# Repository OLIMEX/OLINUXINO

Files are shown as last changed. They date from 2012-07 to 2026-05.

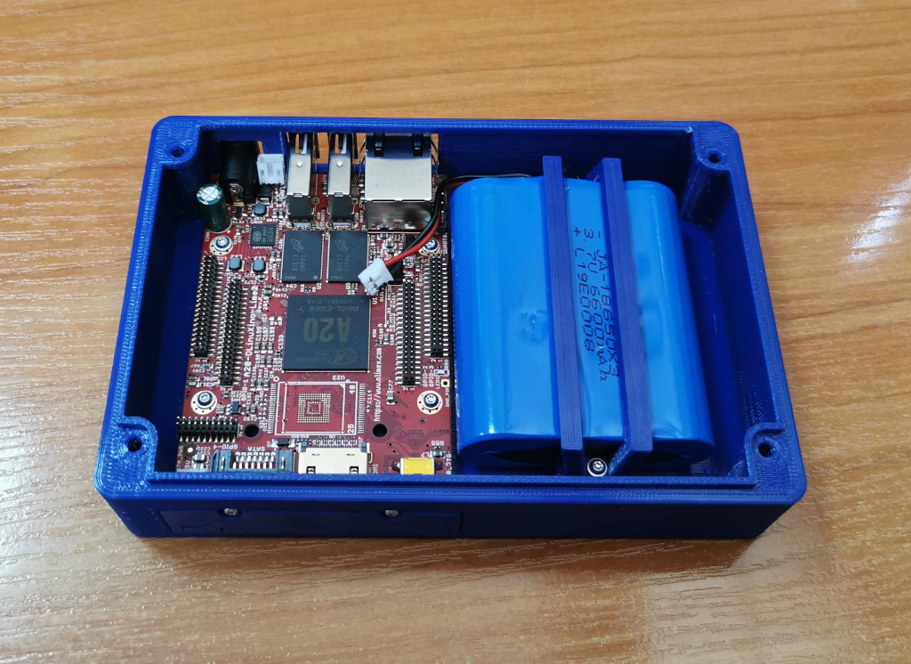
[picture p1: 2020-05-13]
BOXES/LIME2-PLASTIC-BOX/PLASTIC-BOX-ASM3.jpg

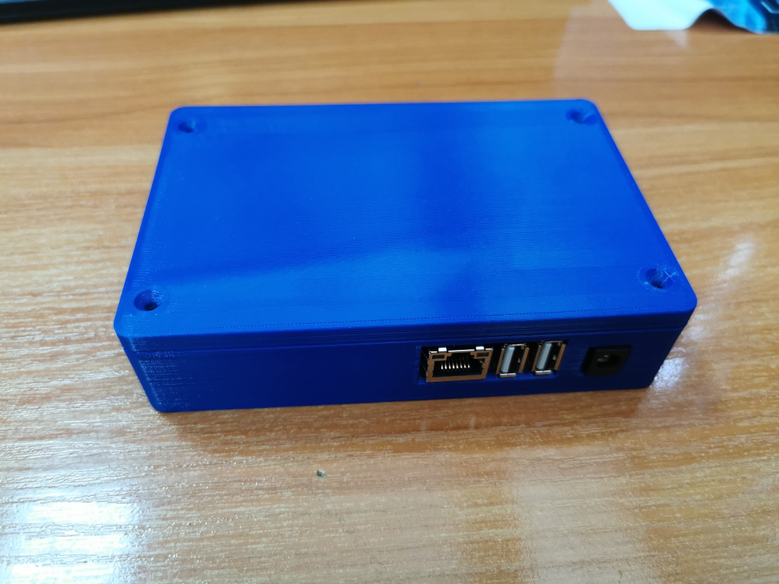
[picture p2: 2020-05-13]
BOXES/LIME2-PLASTIC-BOX/PLASTIC-BOX-ASM4.jpg

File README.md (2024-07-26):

# OLinuXino

Seriously Open Single Board Computers

# Introduction:

Pronounced 'Oh-LIH-nuh-zeeno' The name OLinuXino refers to a series of Single Board Computers (SBCs) developed and produced by Olimex LTD. These SBCs are known for their robustness and versatility, and they are completely open-source, meaning that the hardware and software designs are publicly available for anyone to review, modify, and redistribute. The OLinuXino SBCs have received certifications from the Open Source Hardware Foundation (OSHW), which guarantees that the hardware and software designs meet certain criteria for openness and transparency. Overall, the OLinuXino family of SBCs offers developers and hobbyists a flexible and customizable solution for a wide range of applications.

# Linux ready

The OLinuXino boards are designed to be flexible and versatile platforms for a wide range of applications. They are compatible with various operating systems, but one popular choice is the Linux operating system. Linux is an open-source, community-driven operating system that is well-suited for use on embedded devices like SBCs.

Olimex provide mainline images called Olimage designed specifically for Arm-based SBCs like the OLinuXino boards. It is a lightweight and optimized operating system that takes full advantage of the OLinuXino's hardware components. This includes the processor, memory, storage, and other peripherals like GPIOs and I2C buses. Olimage is regularly updated to ensure a stable and secure operating environment for OLinuXino users. You can find more about Olimage in this document here:

https://github.com/OLIMEX/OLINUXINO/blob/master/DOCUMENTS/OLIMAGE/Olimage-guide.pdf

We've provided Armbian and sunxi images in the past, and while these are no longer actively supported, they are still available for download. 

Overall, the combination of the OLinuXino boards and the Armbian operating system provides a powerful and customizable platform for a variety of applications. 

# Rugged & Reliable

The OLinuXino family of SBCs comprises a diverse range of configurations to meet a variety of industrial and commercial needs. Some models are specifically designed and manufactured to comply with industrial and commercial standards, which means they can operate continuously for extended periods of time, either within industrial grade (-40+85)C or commercial grade (0-70)C temperature ranges. These SBCs are built to withstand tough environmental conditions, making them ideal for use in industrial automation, control systems, and other demanding applications.

The OLinuXino SBCs are powered by high-efficiency ARM processors from reputable manufacturers such as Allwinner, Freescale, and others. These processors are specifically chosen for their low power consumption, high processing power, and compatibility with open-source software, making them ideal for use in embedded systems. The OLinuXino boards are available with a range of processing power options, from single-core to quad-core, depending on the specific use case and application requirements.

In addition to the processor, the OLinuXino SBCs are equipped with a variety of other components such as RAM, storage, connectivity options, and expansion slots to provide users with a versatile and flexible platform for their projects. The boards come with various built-in interfaces such as HDMI, Ethernet, USB, and Wi-Fi, which makes them easy to integrate with other devices and systems.

Overall, the OLinuXino SBCs are well-suited for industrial and commercial applications, thanks to their robust design, efficient processors, and a wide range of features and capabilities. They offer a powerful and customizable platform that can be tailored to specific requirements, making them a popular choice for developers, engineers, and hobbyists alike.

# Unique Standout Features

The OLinuXino family of SBCs is often compared to popular projects such as Raspberry Pi and BeagleBone, but it stands out for several unique features:

1. The OLinuXino family is fully open-source. This means that there are no restrictions on accessing hardware designs or code, making it a popular choice among developers and hobbyists who want to customize or modify their SBCs. The OLinuXino boards are certified by the Open Source Hardware Foundation, providing users with a high degree of confidence in the quality and authenticity of the hardware.

2. The permissive licensing of OLinuXino hardware makes it ideal for use in commercial projects. The hardware can be used without any restrictions, which means that users can design, modify, and distribute their products without any licensing fees or royalties.

3. The OLinuXino family is designed with reproducibility in mind. The hardware designs are thoughtfully executed, making it easy for users to replicate and manufacture their own boards. This is particularly useful for developers who need to scale up production or customize their boards for specific applications.

4. Some of the OLinuXino boards are designed specifically for industrial environments, making them more tolerant of high and low temperatures and able to withstand electrical noise. These features make them well-suited for industrial automation, control systems, and other demanding applications.

4. Some OLinuXino boards feature circuitry for out-of-the-box battery usage, including use as an Uninterruptible Power Supply (UPS). This feature makes the boards ideal for use in remote locations or in applications where a reliable power source is essential.

# Available Configurations

Overall, the OLinuXino family of SBCs offers a unique combination of features and capabilities that make it a popular choice among developers, engineers, and hobbyists. The fully open-source hardware, permissive licensing, and thoughtful design make it a versatile and customizable platform for a variety of applications. The industrial-grade options and battery circuitry make it a robust and reliable solution for demanding environments.

The OLinuXino family of SBCs offers a wide range of configurations to meet a variety of application requirements. Here are some of the configurations available:

[OSHW-Server](https://www.olimex.com/Products/OLinuXino/Home-Server/open-source-hardware): This is a series of low-power server kits that utilize the A20-OlinuXino-LIME2 board. These kits are designed to provide a cost-effective and energy-efficient solution for running server applications.

[STMicro STMP1](https://www.olimex.com/Products/OLinuXino/STMP1/open-source-hardware): This series of boards features the STM32MP157 System on a Chip (SOC), which includes a Dual-core Arm Cortex-A7 running up to 800 MHz and a Cortex-M4 at 209 MHz combined with a dedicated 3D graphics processing unit (GPU). This configuration is well-suited for applications that require high processing power and graphics capabilities.

[Ralink RT5350F](https://www.olimex.com/Products/OLinuXino/RT5350F/open-source-hardware): This series of boards features the Ralink RT535OF MIPS System on a Chip (SOC). It is a low-cost and energy-efficient option for applications that do not require high processing power.

[Allwinner A20](https://www.olimex.com/Products/OLinuXino/A20/open-source-hardware): This configuration comes in several options featuring the Allwinner A20 Arm Cortex A7 Processor. It is a versatile and cost-effective solution for a variety of applications.

[Allwinner A64](https://www.olimex.com/Products/OLinuXino/A20/open-source-hardware): This series of boards features the Allwinner A64 System on a Chip (SOC), including a Dual Core Arm Cortex-A7 processor running at up to 1.2Ghz. It is an efficient and powerful option for applications that require high processing power.

[Allwinner A13](https://www.olimex.com/Products/OLinuXino/A13/open-source-hardware): This configuration features the Allwinner A13 System on a Chip (SOC), offering a low-cost and energy-efficient solution for applications that do not require high processing power.

[Allwinner A10](https://www.olimex.com/Products/OLinuXino/A10/open-source-hardware): This configuration features the Allwinner A10 System on a Chip (SOC), offering a low-cost and energy-efficient solution for a variety of applications.

[Allwinner S3](https://www.olimex.com/Products/OLinuXino/S3/): This configuration features the Allwinner S3 System on a Chip (SOC), offering a low-cost and energy-efficient solution for applications that do not require high processing power.

[Allwinner A33](https://www.olimex.com/Products/OLinuXino/A33/open-source-hardware): This configuration features the Allwinner A33 System on a Chip (SOC), offering a low-cost and energy-efficient solution for applications that do not require high processing power.

[NXP iMX8](https://www.olimex.com/Products/OLinuXino/iMX8/): This configuration features the NXP iMX8 System on a Chip (SOC), which provides users with a high degree of flexibility and customization options for their applications.

[NXP iMX233](https://www.olimex.com/Products/OLinuXino/iMX233/open-source-hardware): This configuration features the NXP iMX233 System on a Chip (SOC), which is a low-power and low-cost option for applications that do not require high processing power.

Overall, the OLinuXino family of SBCs offers a diverse range of configurations to meet a variety of application requirements. Whether you need high processing power, energy efficiency, or cost-effectiveness, there is likely a configuration that can meet your needs. Additionally, the open-source hardware and permissive licensing make the OLinuXino boards a popular choice among developers and hobbyists who want to customize and modify their SBCs.

# More Chip info

Allwinner A10 [Data-Sheet](https://linux-sunxi.org/images/7/75/A10_Datasheet.pdf): This System on a Chip (SOC) offers a low-cost and energy-efficient solution for a variety of applications. It features an Arm Cortex-A8 processor running up to 1.2 GHz, as well as support for up to 1 GB of DDR3 memory and 1080p video playback.

Allwinner A13 [Data-Sheet](http://dl.linux-sunxi.org/A13/A13%20Datasheet%20v1.1.pdf): This SOC offers a low-cost and energy-efficient solution for applications that do not require high processing power. It features an Arm Cortex-A8 processor running up to 1 GHz, as well as support for up to 1 GB of DDR3 memory and 1080p video playback.

Allwinner A20 [Data-Sheet](https://linux-sunxi.org/images/4/4e/A20_Datasheet_v1.4.pdf): This SOC comes in several configurations featuring the Allwinner A20 Arm Cortex A7 Processor. It is a versatile and cost-effective solution for a variety of applications, offering a dual-core Arm Cortex-A7 processor running up to 1 GHz and support for up to 2 GB of DDR3 memory.

Allwinner A33 [Data-Sheet](https://linux-sunxi.org/images/5/57/A33_Datasheet_v1.0.pdf): This SOC features a quad-core Arm Cortex-A7 processor running up to 1.5 GHz, as well as support for up to 2 GB of DDR3 memory and 1080p video playback. It offers a low-cost and energy-efficient solution for applications that do not require high processing power.

Allwinner A64 [Data-Sheet](https://linux-sunxi.org/images/7/78/A64_User_Manual_V1.0.pdf): This SOC features a Dual Core Arm Cortex-A7 processor running up to 1.2 GHz, making it an efficient and powerful option for applications that require high processing power. It also supports 4K video playback and up to 4 GB of DDR3 memory.

Allwinner S3 [Data-Sheet](https://linux-sunxi.org/images/4/4c/S3_Datasheet_V1.1.pdf): This SOC features a quad-core Arm Cortex-A7 processor running up to 1.2 GHz, making it an efficient and powerful option for applications that require moderate processing power. It also supports up to 2 GB of DDR3 memory and 1080p video playback.

NXP iMX233 [Data-Sheet](https://www.nxp.com/docs/en/data-sheet/IMX233C.pdf): This SOC is a low-power and low-cost option for applications that do not require high processing power. It features an Arm926EJ-S processor running up to 454 MHz, as well as support for up to 64 MB of DDR2 memory and 480p video playback.

NXP iMX8 [Data-Sheet](https://www.nxp.com/docs/en/data-sheet/IMX8MDQLQIEC.pdf): This SOC provides users with a high degree of flexibility and customization options for their applications. It features a quad-core Arm Cortex-A53 processor running up to 1.5 GHz, as well as a dual-core Arm Cortex-M4 processor for real-time processing. It also supports up to 4 GB of LPDDR4 memory and 4K video playback.

Ralink RT5350F [Data-Sheet](https://www.ralinktech.com/products/rt5350f/): This SOC is a low-cost and energy-efficient option for applications that do not require high processing power. It features a MIPS24KEc processor running up to 360 MHz, as well as support for up to 64 MB of DDR2 memory and 1080p video playback.

STMicro STMP1 [Data-Sheet](https://www.st.com/resource/en/datasheet/stm32mp157a-datasheet.pdf): This SOC is well-suited for applications that require high processing power and graphics capabilities. It features a Dual-core Arm Cortex-A7 running up to 800 MHz and a Cortex-M4 at 209 MHz, combined with a dedicated 3D graphics processing unit (GPU). It also supports up to 1 GB of DDR3 memory and 1080p video playback.

Overall, each SOC offers different processing power, memory, and video capabilities to suit a variety of applications. Depending on your specific needs and requirements, you may choose one SOC over another to optimize performance and cost-effectiveness.

# Potential use cases

* Industrial automation and control systems
* Robotics and control systems
* Home automation and smart home systems
* Media centers and home theaters
* Network appliances and routers
* Internet of Things (IoT) devices and sensors
* 3D printer controller and G-code interpreter
* Programmable logic controller (PLC) for manufacturing and process control
* Reverse proxy server and load balancer for web applications
* Cloud and edge computing systems
* Educational and research projects in computer science and engineering
* Digital signage and kiosk systems
* Gaming and entertainment systems
* Portable and battery-powered systems, including battery-backed UPS
* Scientific and medical instrumentation and analysis systems
* Remote sensing and monitoring systems
* Amateur radio and signal processing systems

The versatility and flexibility of the OLinuXino family of SBCs makes them suitable for a wide range of applications in various industries and domains. The fully open-source nature of the hardware and software also makes them highly customizable and extensible, allowing users to tailor them to their specific needs and requirements.

# Resources:

[OLIMEX Ltd web site](http://www.olimex.com) -  where the OLinuXino board info is hosted

[GitHub Source](https://github.com/OLIMEX/OLINUXINO) - GitHub web site hosting the Hardware and Software sources

[Forum](https://www.olimex.com/forum/index.php) - Olimex forum for OLinuXino project discussions

[Discord](https://discord.com/invite/QQEBXZk7y8) - Olimex Discord channel for product discussions

IRC Channel - join #olimex on irc.freenode.net , alternatively use http://webchat.freenode.net/?channels=olimex for web IRC chat

# Licensing:

## Hardware

The OLinuXino family of Single Board Computers (SBCs) is completely open-source and is licensed under permissive Creative Commons Attribution-Share Alike 3.0 United States License (CC-BY-SA 3.0 US). This license allows users to reproduce, modify, and redistribute the hardware and documentation for both personal and commercial use, as long as they provide attribution to the original creator, Olimex LTD, and release any modified files under the same license terms.

However, if you choose to modify the hardware, you must alter the silkscreen to avoid confusing users into thinking they are purchasing the original OLinuXino made by Olimex. This is a requirement to prevent any potential legal issues, as the OLinuXino trademark is owned by Olimex LTD.

## Software

The software used in the OLinuXino SBCs is released under the GNU General Public License (GPL) version 3, which grants users the freedom to run, copy, distribute, and modify the software. If you modify the software, you must also release it under the same license terms.

## Documentation

The documentation for the OLinuXino SBCs is also released under CC-BY-SA 3.0 US, which allows users to reproduce, modify, and distribute the documentation for both personal and commercial use, as long as they provide attribution to the original creator and release any modified files under the same license terms.

Overall, the licensing for the OLinuXino SBCs is permissive and encourages collaboration and innovation, while also ensuring that the original creators receive proper attribution for their work.

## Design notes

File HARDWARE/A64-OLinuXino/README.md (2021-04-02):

## Information about the hardware schematics, design sources, and revision changes

PDF exports of the schematics are found in this folder. Deisgn files are found in the folders, each folder features all required files for a specific hardware revision as indicated by the folder name. To access the design files you need the latest beta version of KiCAD. Using the latest stable version usually will NOT suffice.

The initial release of A64-OLinuXino boards was revision C. The six variants of the board so far are:

* A64-OLinuXino-1G with 1GB RAM but NO flash and NO WiFi/BLE connectivity

* A64-OLinuXino-1Ge16GW with 1GB RAM and 16GB extra eMMC flash and extra WiFi/BLE module

* A64-OLinuXino-1Ge16GW-EA with 1GB RAM and 16GB extra eMMC flash and extra WiFi/BLE module + external antenna

* A64-OLinuXino-1Ge4GW with 1GB RAM and 4GB extra eMMC flash and extra WiFi/BLE module

* A64-OLinuXino-1Gs16M with 1GB RAM, no NAND or eMMC flash, no WiFi/BLE, extra 16MB SPI flash

* A64-OLinuXino-2Ge8G-IND with 2GB RAM and 8GB extra flash but NO WiFi/BLE connectivity; with components that work in the industrial -40+85C temperature range

### Hardware revision changes log:

#### Hardware revision C

* initial release

#### Hardware revision D

* 1. Adjusted white print of label C184.
* 2. Added bypass R66 NA(0R) near FET2.
* 3. Added white print for the UART connector at the bottom of the board (Tx,Rx,GND).
* 4. Fixed white print of R106 and R116 (labels were swapped)
* 5. R29 placed a bit further from C84
* 6. 1.5v test pad name was changed to "DDR-VCC" because the RAM memory can work at 1.3V.
* 7. Names of the jumpers lineinr/micin1p1 and lineinl/micin1n1 were changed to lineinr/micin1 and lineinl/micin2.
* 8. The jumper phoneoutr(l)/lineootr(l) was renamed to hphoneoutr(l)/lineoutr(l).

#### Hardware revision E

* 1. Changed the eMMC from eMMC (4GB,1.00mm pitch) to eMMC (16GB,0.50mm pitch). Some of the surrounding components changed too.
** 1.1 Removed RM1(RA1206_(4X0603)_4B8_10k), RM2(RA0805_(4X0402)_22R), RM3(RA0805_(4X0402)_22R), RM4(RA1206_(4X0603)_4B8_10k), RM5(RA0805_(4X0402)_22R)
* 2. C212 and C213 were changed from 27pF to 33pF and from 0603 to 0402 as component optimisation.
* 3. R66 value changed from NA(0R) to NA(22R)
* 4. RM15's package changed from RA1206_(4X0603)_4B8_22R to RA0805_(4X0402)_22R as component optimisation.
* 5. C119 and VR1 changed from PTH to SMT type in the KiCad settings. In reallity, C119 and VR1 did not change. 
* 6. PWRLED1 and CHGLED1 labels corrected in the white print.
* 7. WP_Enable1 jumper added to the SPI_Flash.
* 8. U4 changed from NA(H27UBG8T2BTR-BC(TSOP48)) to NA(MT29F64G08CBABA-WP(TSOP48)), i.e. when populated 8GB NAND instead of 4GB.
* 9. MICRO_SD(TFC-WPAPR-08) package change - corrected cream layer and origin.
* 10. PWR_PC1 jumper state changed to Soldered(2-3); Opened(1-2) so that 1.8V wire is connected to the eMMC by default.
* 11. Serial resistors added to the Ethernet PHY's Tx lines for better EMI supression and RLC filters to the clock lines.
* 12. C198 connected to the right side of the RGMII_RXCLK line.
* 13. The Wi-Fi's baloun now matched with the same "Pi" - filter like in Teres-I, so:
	C105 changed from 33pF to 10pF
	C106 changed from NA to 0.8pF
	R62 was exchanged with inductor 3.3nH
	C107 was changed from NA to 1.5pF
* 14. The WiFi's antenna mirrored

#### Hardware revision E1

* 1. eMMC KLMAG2GEND-B031(FBGA153)(16G) changed with new eMMC KLMAG1JETD-B041(FBGA153)(16G)

#### Hardware revision F

* 1. Added R62(10k/0402) pull-down to the eMMC's data strobe line;
* 2. RM14, RA0805_(4X0402)_22R replaced by 4 resistors 22R/0402, i.e. R121-R124; R121 was placed away from UEXT for to make shorter eMMC's data strobe line length;
* 3. R73[NA(22R/0402)] was added to enable SPI0 software CS option to the UEXT via PH10, when the SPI_Flash is populated. By defalut, it will reamin as it was, i.e. R124(22R/0402) populated!, while R73(NA)!;
* 4. L9 was changed from 2.7nH/L0402 to NA(2.7nH/L0402), and C88 from 24pF to NA(24pF);
* 5. MIPI-DSI1 changed: MIPI-DSI1 connector's pinout completely changed for Raspberry-Pi compatability; added the resistors: R125 to R132;
* 6. In the DRC drill to drill clerance was set to 12mils and all related errors were corrected;
* 7. UEXT1 was changed from NA(HN2x5) to HN2x5;
* 8. All 3Ds were assigned;
* 9. It was added C94(NA/0402) to the eMMC's clock line just in case;
* 10. NAND and related components removed forever;
* 11. In the schematic all "/" signs were exchanged with "\";
* 12. Improvements around the placement of a number of resistors related to the PHY signals to reduce EMI emissions;
* 13. Added U4 EEPROM - AT24C16C-SSHM-T(SOIC-8_150mil) and also C39, 100nF/10V/10% to the UEXT's I2C to avoid conflict with the same EEPROM on the LCD-Driver board. It is placed by default;
* 14. R15[NA(22R/R0402)] added in serial to the eMMC's datastrobe signal to be able to disconnect when no HS400 mode or to add a serial filter to reduce EMI;
* 15. UBOOT1, PWRON1 and RESET1 packages changed from OLIMEX_Buttons-FP:uTACTIL to OLIMEX_Buttons-FP:IT1185AU2_V2;
* 16. U2 and U3's packages improved;
* 17. LAN1's package improved;
* 18. D1 moved a little bit away from the PWR-JACK's + pad;
* 19. Q2 package changed from Q32.768kHz\12.5pF/20ppm/4P/SMD8038 to Q32.768kHz/12.5pF/2P/SMD1206;
* 20. L7 package changed from 2.7nH\L0402 to NA(2.7nH\L0402), and C198 changed from 24pF to NA(24pF);
* 21. R100 changed from 22R/0402 to FB1, FB0402/PZ1005U601-R45TF-1;
* 22. R69 changed from 22R/0402 to FB2, FB0402/PZ1005U601-R45TF-1;
* 23. The GND polygons in the top and bottom opened to allow for metal cover soldering.

#### Hardware revision G

* 1. Added antenna ANT2(NA(U.FL-R-SMT-1)), R16(0R) and R17(NA/0R);
* 2. Removed FB1(FB0402/PZ1005U601-R45TF-1) and FB2(FB0402/PZ1005U601-R45TF-1) and placed R18(22R/0402) and R19(22R/0402) resistors instead. Using FB1 and FB2 was meant to improve the EMI, but it yielded no results;
* 3. Adjusted the lengths of some eMMC wires;
* 4. C93 changed from 24pF to 24pF\50V/5%. C88 and C198 changed from NA/24pF to NA(24pF\50V/5%);
* 5. Changing 5.1 eMMC at 3.3V (up from 1.8V operation) for better reliability, PWR_PC1 jumper has to be set to position 1-2 for 3.3V operation.

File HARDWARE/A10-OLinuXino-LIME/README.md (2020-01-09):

## Olimex A10-OLinuXino-LIME hardware sources

## Product page: https://www.olimex.com/Products/OLinuXino/A10/A10-OLinuXino-LIME/open-source-hardware

## A20-OLINUXINO-LIME AND A10-OLINUXINO-LIME SHARE SAME HARDWARE LAYOUT. 

### FOR LATEST HARDWARE REVISION, PLEASE VISIT THE A20-OLINUXINO-LIME HARDWARE SECTION: 

### https://github.com/OLIMEX/OLINUXINO/tree/master/HARDWARE/A20-OLinuXino-LIME

### THE A10 AND A20 CHIPS ARE PIN-TO-PIN COMPATIBLE (DROP-IN REPLACEABLE). ONLY THE MAIN CHIP PLACED IS DIFFERENT.

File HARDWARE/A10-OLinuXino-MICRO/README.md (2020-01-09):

#Olimex A10-OLinuXino-MICRO hardware sources

## A10-OLinuXino-MICRO has no product page since the board was never comercially manufactured. The design was used as basis for A20-OLinuXino-MICRO since the A10 and A20 chips are pin-to-pin compatible (drop-in replaceable).

## A20-OLinuXino-MICRO AND A20-OLinuXino-MICRO SHARE SAME HARDWARE LAYOUT.

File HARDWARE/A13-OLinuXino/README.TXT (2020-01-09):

This repository contains:

Original hardware design files for A13-OLinuXino and A13-OLinuXino-WIFI. These are made with Eagle 4.16r2. PDF exports are available also.

Both boards use same design files, but the A13-OLinuXino-WIFI comes with NAND memory and on-board MOD-WIFI-RTL8188ETV module.

Notice that it is possible that simultaneously purchased A13-OLinuXino and A13-OLinuXino-WIFI to be from different revisions.

Latest hardware revision: revision H

Major changes in revision H compared to previous revision G2:

- Q1 value changed from HC49/S1 to Q24MHz/20pF/20ppm/2P/HC-49SM(SMD);
- Q2 changed from HC49/S1 to Q12MHz/20pF/20ppm/2P/HC-49SM(SMD);
- Q3 value and package changed from 32768Hz/6pF to Q32.768kHz/12.5pF/20ppm/4P/SMD8038;
- RM16 renamed to RM11;
- U10 and U15 changed from SY8008C(AA)C to SY8009AAAC(SOT23-5);
- U16 changed from SY7208(SOT23-6) to MT3608(SOT23-6);
- PWR-JACK value changed from YDJ-1136 to PWRJ-2mm(YDJ-1134);
- Optimized R84 from 100k/1% to 4.99k/1% and R86 from 22k/1% to 1.1k/1% ;
- Optimized C134 from 47pF to 33pF ;
- Optimized C114 from 22pF to 33pF ;
- Optimized L12 from FB0805/600R/200mA(201209-601) to FB0805/600R/2A ;
- Optimized L1 from CL470nH/0805/1.76R/250mA to FB0805/600R/2A;
- Optimized R43, R98, and R99 from 51R to 22R;
- GPIO-2 and LCD_CON were changed from ML40 to BH40S.

Changes in revision G2 compared to previous revision G1:

- Changed C144 to 100pF

Changes in revision G1 compared to previous revision G:

- Added capacitor C144 1nF on DDR3-RST signal

Changes in revision F compared to previous revision E1:

- Changed the SD card package so that it is easier for repair and attachment
- Changed the package of the 32768 crystal to an SMT one (with 4 pins)

Board features:

- A13 Cortex A8 processor at 1GHz, 3D Mali400 GPU
- 512 MB RAM (2 x 256Mbit x 8)
- 4GB NAND Flash (for A13-OLinuXino-WIFI)
- 6-16VDC input power supply, noise immune design
- 3 + 1 USB hosts, 3 available for users, 1 leads to onboard pinout or to WIFI module (for A13-OLinuXino-WIFI)
- 1 USB OTG which can power the board
- SD-card connector for booting optional Linux images
- VGA video output
- Battery option and connector
- LCD signals available on connector so you still can use LCD if you disable VGA/HDMI
- Audio output
- Microphone input
- 4 Mount holes
- RTC PCF8563 on board for real time clock and alarms
- 5 Keys on board for android navigation
- UEXT connector for attaching expansion boards (sensors, relays, etc)
- GPIO connector with 68/74 pins and these signals:
- 17 for adding NAND flash;
- 22 for connecting LCDs;
- 20+4 including 8 GPIOs which can be input, output, interrupt sources;
- 3x I2C;
- 2x UARTs;
- SDIO2 for connecting SDcards and modules;
- 5 system pins: +5V, +3.3V, GND, RESET, NMI
- Dimensions: (120x120)mm ~ (4.7x4.7)''

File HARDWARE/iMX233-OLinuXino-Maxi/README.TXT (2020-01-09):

iMX233-OLinuXino-MAXI hardware change log

Major changes:

iMX233-OLinuXino-MAXI hardware revision B1
======
1. Initial release

iMX233-OLinuXino-MAXI hardware revision B2
======
1. Removed FET1

iMX233-OLinuXino-MAXI hardware revision C
======
1. Changed the name in the white print "iMX233-OLINUXINO_Rev_C" to "iMX233-OLINUXINO-MAXI_Rev_C";
2. BOOT jumpers moved to the bottom and separated further apart; 
3. Jumpers 3.3V_E and 3.3VIO_E moved to the bottom and separated apart;
4. Jumpers SW_SCL/HW_SCL and SW_SDA/HW_SDA made bigger and default position changed to HW I2C positions;
5. Moved 5V_E jumper to the bottom of the board;
6. Removed FET that is in series to the power input;
7. Q2 moved up from D1;
8. 40-pin GPIO connector - edited the symbol to indicated the hole of hte plastic connector better;
9. PWR_JACK and RCA connectors separated further by 20 mils;
10. Atted schotky diode in series of RX and R1 changed from 100k to 4.7K;

iMX233-OLinuXino-MAXI hardware revision C1
======
1. Changed C23 and C24 from 33pF to 15pf for better start up behavior

iMX233-OLinuXino-MAXI hardware revision C2
======
1. Changed C23, C24 from 15pF to 4.7pF because the crystal starts better
2. Changed C83 from 10pF to 100pF because the board starts better on battery 

iMX233-OLinuXino-MAXI hardware revision D
======
1. Changed SD card package with a better one;
2. Fixed LiPo bat white print;
3. Changed C23, C24 from 4.7pF to 10pF, since 4.7 starts better, but loses color of vidoe si since the display color gets lost (frequency changes);

iMX233-OLinuXino-MAXI hardware revision D1
======
1. Changed C83 from 100pF to 20pF. The problem was that the Debiam 3.11 image does not recognize mass storage drives. Other usb devices can be rocognized. The capacitor values is critical because if 100pf is placed the board start better on battery, but does not recognize Mass storage drive. IF 10pF is placed - the mass storage drive is recognized but the board starts more dificult only with battery supply. So the compromise is 20 pF.

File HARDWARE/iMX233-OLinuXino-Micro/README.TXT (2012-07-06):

iMX233-OLinuXino-Micro REVISION.B	July, 2012

Status	: schematic design, 2 Layers

Issues	: 

TODO	:

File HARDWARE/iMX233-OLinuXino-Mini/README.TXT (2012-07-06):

iMX233-OLinuXino-Mini REVISION.C	July, 2012

Status	: prototype, 4 Layers

Issues	: none

TODO	: none

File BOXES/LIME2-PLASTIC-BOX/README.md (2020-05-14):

# Plastic box for A20-OLinuXino-LIME2 + LiPO battery 6600mAh

This is Plastic box for LIME2 contributed by: Mike Bosschaert from Utrecht, Netherlands.

* The files are created with FreeCAD
* The model is printed in PLA using a Felix Pro 2 FDM printer
* The model is designed for layer thickness of .2mm and extrusion width of .35mm
* The screws I used are Toolcraft 2.2x6mm with panhead+washer
* The holes for the top cover screws are M3

## Licensee

The files are released under CC BY-SA 4.0 (https://creativecommons.org/licenses/by-sa/4.0/).

for any questions about this plastic box use this e-mail address: design@bosschaert.org

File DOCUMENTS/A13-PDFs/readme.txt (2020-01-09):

Datasheets of components which will be used in A13-OLinuXino

A13		CortexA8 MCU
RTL8188CU	WiFi 802.11n 150Mbit WIFI module
GL850G		USB hub 1:4
H5TQ2G63BFR-H9	2Gbit x16 data bus 1333Mhz DDR3 RAM
TDA9981         HDMI transciever

PLEASE BEWARE: ON A13 Reference Schematic we found trap - DDR RAM memory balls are shifted with +1, so according to Hynix datasheet A0 is ball K3 but on the schematic is K4 and so on.
We don't know if this is intentional or non-intentional, but will fix it in our own schematic.

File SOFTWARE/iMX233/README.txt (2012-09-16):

iMX233-OLinuXino Software and Projects:

ArchLinux package for the moment is with most advanced Kernel and enabled features so this is our choice for the moment to build examples.

From September 1st all SD cards with Linux images we distribute will contain latest ArchLinux image with TV-console enabled.

1. How to setup ArchLinux, GCC and Hello world program document: http://olimex.wordpress.com/2012/09/06/imx233-olinuxino-get-started-making-the-arch-linux-sd-card/

2. Using I2C with iMX233-OLinuXino. How to interface MOD-MAG project:

3. WEB-IO or controlling GPIOs, MOD-GSM, MOD-IO through web project by Dimitar Gamishev: 

---
Here is list of Software resources for iMX233-OLinuXino

---

http://leachy.homeip.net/olinuxino/index.html tutorial how to make PLC with iMX233-OLinuXino

---

Reading board temperature: http://tech.groups.yahoo.com/group/olinuxino/message/1356 with sources by Razvan Dragomirescu

---

Patch to support WiFi devices based on Realtek 802.11n chipsets http://tech.groups.yahoo.com/group/olinuxino/message/1402 by Michael Peter Thompson

---

USB firmware loader for iMX233 http://tech.groups.yahoo.com/group/olinuxino/message/1475 by Marek Vasut

---

interfacing Olinuxino with Android phones http://tech.groups.yahoo.com/group/olinuxino/message/1521 by Razvan Dragomirescu

---

new arch kernel with more usb modules and better DM9601 support http://tech.groups.yahoo.com/group/olinuxino/message/1262 by Georg Sassen

---

Standalone imx-bootlets for OLinuXino kernel development http://tech.groups.yahoo.com/group/olinuxino/message/1588 by Michael Peter Thompson

---

quick reference chart for pinout of Olinuxino-Micro by http://tech.groups.yahoo.com/group/olinuxino/message/1601 JP Beale

---

I2C examples for OLinuXino by Jeroends https://github.com/OLIMEX/OLINUXINO/tree/master/SOFTWARE/iMX233/I2C

---

Building Linux 3.6 Kernel for iMX233-OLinuXino https://github.com/koliqi/imx23-olinuxino

---

GPIO MMAP tool for direct write in /dev/mem GPIO registers makes GPIO toggle as fast as 5.7Mhz

https://github.com/OLIMEX/OLINUXINO/tree/master/SOFTWARE/iMX233/gpio-mmap.h
http://tech.groups.yahoo.com/group/olinuxino/message/2022
---

Barebox support for iMX233-OLinuXino http://tech.groups.yahoo.com/group/olinuxino/message/2027

---

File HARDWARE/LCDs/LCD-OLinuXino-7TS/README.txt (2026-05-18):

LCD-OLINUXINO-7 and LCD-OLINUXINO-7TS use the same design files (schematic, board files)

Both boards use the legacy driver board design, not the common LCD-DRIVER board.

Hardware revision A
========
Initial release

Hardware revision B
=====
1. New package for the PWR_JACK.
2. Changed few resistor to 1% tolerance (R1,R2,R9,R21).
3. Added 40-pin conector LCD_A64-OLINUXINO for the A64-OLinuXino board.

Hardware revision C
=====
1. Added 8 resistor positions (pull-up/down) that can be used for binary display identification. Of these 8 positions, 4 resistors have to be populated with 51k/1% and 4 should be left unpopulated. The 7 inch LCD's ID number was set to 0x03. The list of the rest of the display IDs is:

	0x01	-> 4.3" LCD
	0x02	-> 5.0" LCD
	0x03	-> 7.0" LCD
	0x04	-> 10.0" LCD
	0x05	-> 15.4" LCD
	
2. Changed the default position of the 5V/3V SMD jumper to be in position 5V.

Hardware revision D
=====
1. Improvements for all connectors for better soldering and better compatiblity;
2. Fixed lables for SYNK Mode and DE mode in the schematic.

Hardware revision E
=====
1. Board made wider by 40mils. BOM stays the same!

Hardware revision F
=====
1. LCD panel changed with similar but thinner one;
2. TP1, FPA-WZB-25-04-LF, connector added to duplicate the other touch-screen connector for the new 7" LCDs;
3. CE sign added;
4. Widened the 50 mils connector holes from 0.7 to 0.9mm;
5. T1 changed from DTC114YKA to LMUN2211LT1G;
6. Z1 changed from BZV55C6V8 to BZV55C10;
7. R12 changed from 2.2R to 1.1R/1%/R0603 to increase the backlight current from 90mA to 180mA to match the new LCD;
8. R29 changed from 560R/1% to 562R/1%;
9. R16, R17, R18, R35, R36, R37 and R38 changed from 51k/1% to 51.1k/1%;
10. Connectors LCD_LIME and LCD_LIME2 changed fron GPH127SMT-02x20 to MALE-PAV16X-2x20-HIGH-TUBE.

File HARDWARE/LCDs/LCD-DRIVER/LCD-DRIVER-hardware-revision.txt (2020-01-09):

LCD-DRIVER is a common LCD driver board for several Olimex displays.

Hardware revision B
========
Initial release
	
Hardware revision C
========
1.	Several component packages changed. Zenners BZV55CxVx/SOD80C changed to BZT52CxVx/SOD-123;
2.	The package of R38 and R40 changed from 0402 to 0603;
3.	Added automatic switching between external power supply and LCD connector power supply. The  
	5V_JACK/5V_LCD1(5V_JACK:Opened/5V_LCD1:Closed) jumper was deleted. Instead added 
	FET3(IRLML6402(SOT23-3)), R63(10k/R0402) and R64(NA(10k/R0402));
4. LCD_LIME1 and LCD_LIME2 changed from MALE-PAV16X-2x20 to MALE-PAV16X-2x20(0.8_bud);
5. Removed R50(220R/R0402).
6. Deleted D5(NA(BZV55C3V6/SOD80C)). Added D5(NA(1N5819S4(SOD-123))) instead.
7. Because U3 -> AP3036BKTR-G1(SOT23-6) could NOT provide more than 200mA current, we had 
	problems with 10" LCDs. To combat this we did the following changes:
	- U3 changed from AP3036BKTR-G1(SOT23-6) to AP3031KTR-G1(SOT23-6);
	- Added D8(1N5819S4(SOD-123));
	- D9(NA(1N5819S4(SOD-123)));  
	- L1 was changed from 22uH/1.5A/220mR/20%/CD53(YS53-220M) to 4.7uH/1.15A/DCR<0.1R/CD43.
	- Added R65(10k/R0402);
	- Added R66(10k/R0402);
	- U4 changed from NA(AP3036BKTR-G1(SOT23-6)) to NA(AP3031KTR-G1(SOT23-6));
	- L2 changed from NA(22uH/1.5A/220mR/20%/CD53(YS53-220M)) to NA(4.7uH/1.15A/DCR<0.1R/CD43).
	- D5(NA(1N5819S4(SOD-123))) added (same as 6).
	
Note: AP3036BKTR-G1(SOT23-6) and AP3031KTR-G1(SOT23-6) are not pin-to-pin compatible, could be
made compatible if one of them is rotated 180 degrees and placed at the place of the other! 
This was tested and confirmed working!

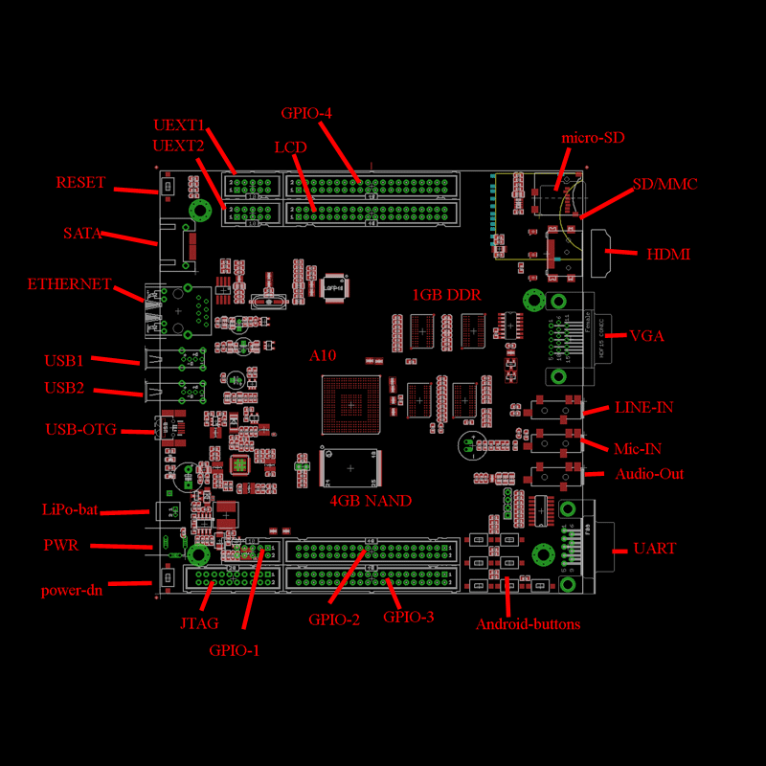
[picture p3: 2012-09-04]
HARDWARE/A10-OLinuXino/A10-OLinuXino-BRD.gif

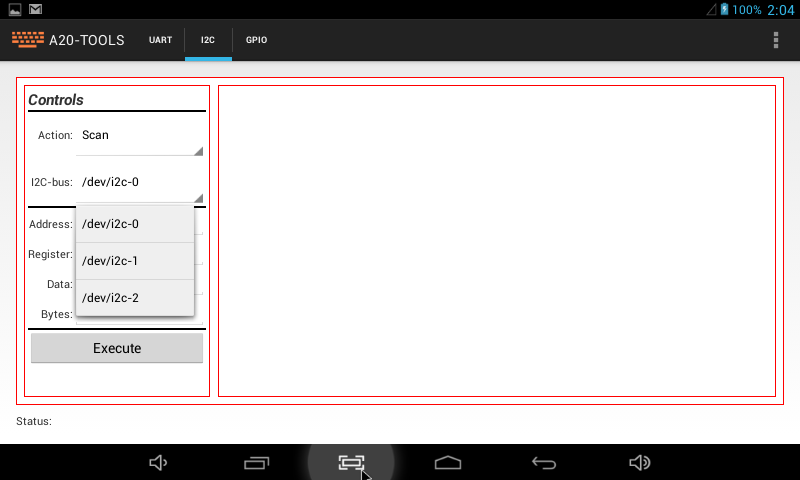
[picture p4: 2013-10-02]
SOFTWARE/A20/ANDROID A20-OLINUXINO-TOOLS/Screenshot_1970-01-02-02-04-06.png

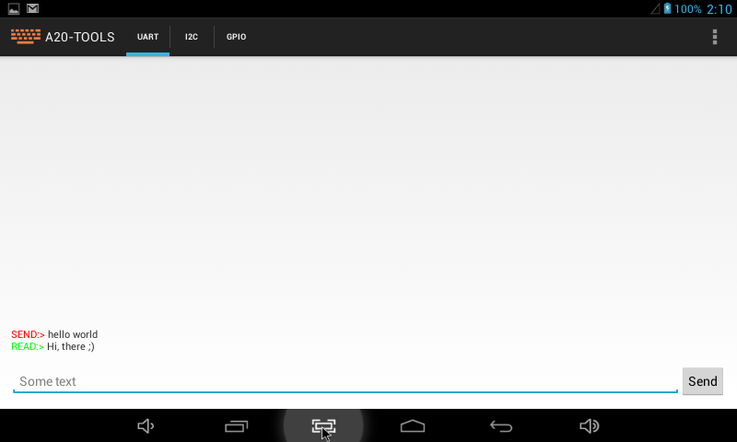
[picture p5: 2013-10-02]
SOFTWARE/A20/ANDROID A20-OLINUXINO-TOOLS/Screenshot_1970-01-02-02-10-10.png

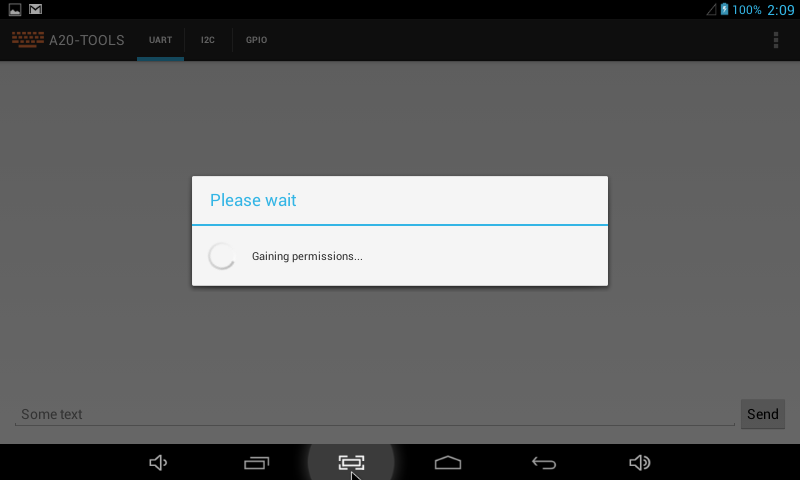
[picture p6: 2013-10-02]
SOFTWARE/A20/ANDROID A20-OLINUXINO-TOOLS/Screenshot_1970-01-02-02-09-18.png

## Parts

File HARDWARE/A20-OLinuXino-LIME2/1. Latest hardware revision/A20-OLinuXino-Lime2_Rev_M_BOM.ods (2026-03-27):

Qty | Value | Device | Parts
3 | 0R(Board_Mounted) | R-EU_R0402_TI_0R | R11, R13, R22
1 | 0R(Board_Mounted) | R_0R0R(NA) | R83
1 | 0.03R/1% | R-EU_R1206_5MIL_WS | R66
2 | 22R | R-EU_R0402_TI | R9, R10
9 | 33R | R-EU_R0402_TI | R19, R20, R21, R24, R25, R26, R119, R120, R123
1 | 120R | R-EU_R0402_TI | R127
2 | 191R/1% | R-EU_R0603_5MIL_DWS | R65, R72
3 | 330R/1% | R-EU_R0603_5MIL_DWS | R7, R8, R14
8 | 1k | R-EU_R0402_TI | R113, R114, R115, R116, R117, R118, R124, R125
2 | 1.1k/1% | R-EU_R0603_5MIL_DWS | R89, R92
7 | 2k/1% | R-EU_R0402_TI | R1, R2, R4, R5, R6, R45, R46
14 | 2.2k | R-EU_R0402_TI | R56, R57, R60, R61, R70, R75, R77, R79, R80, R81, R82, R88, R128, R129
2 | 4.99k/1% | R-EU_R0603_5MIL_DWS | R51, R91
2 | 6.8k/1% | R-EU_R0603_5MIL_DWS | R59, R73
1 | 8.25k/1% | R-EU_R0603_5MIL_DWS | R85
13 | 10k | R-EU_R0402_TI | R31, R42, R44, R52, R54, R58, R62, R64, R68, R71, R78, R121, R126
1 | 10k/1% | R-EU_R0603_5MIL_DWS | R90
1 | 12.1k/1% | R-EU_R0603_5MIL_DWS | R111
1 | 12.4k/1% | R-EU_R0603_5MIL_DWS | R86
2 | 13k/1% | R-EU_R0603_5MIL_DWS | R53, R63
1 | 20k/5%/0402 | R-EU_R0402_TI | R47
1 | 27k | R-EU_R0402_TI | R32
4 | 47k | R-EU_R0402_TI | R27, R30, R55, R76
3 | 100k/1% | R-EU_R0603_5MIL_DWS | R41, R67, R87
3 | 200k/1% | R-EU_R0603_5MIL_DWS | R43, R69, R74
1 | 1M | R-EU_R0402_TI | R84
1 | 10M | R-EU_R0402_TI | R35
1 | RA1206_(4X0603)_4B8_0R | R_MATRIX_4E | RM1
1 | RA1206_(4X0603)_4B8_33R | R_MATRIX_4E | RM9
2 | RA1206_(4X0603)_4B8_4.7k | R_MATRIX_4E | RM4, RM10
1 | RA1206_(4X0603)_4B8_100K | R_MATRIX_4E | RM3
1 | 10pF/NP0/50VDC | C-EUC0402_TI | C82
2 | 22pF/NP0/5% | C-EUC0402_TI | C110, C115
6 | 33pF/50V/5%/C0G | C-EUC0603_DWS | C116, C117, C201, C211, C248, C249
8 | 1nF/X7R/50VDC | C-EUC0402_TI | C139, C140, C141, C142, C167, C173, C187, C209
1 | 1nF/2kV/X7R/1206 | C-EUC1206_5MILS_WS_ISO | C214
4 | 10nF/X7R/50VDC | C-EUC0402_TI | C153, C154, C156, C157
19 | 100nF/10V/20%/X5R | C-EUC0402_TI | C109, C119, C135, C136, C137, C149, C152, C193, C236, C237, C239, C240, C242, C243, C244, C247, C250, C252, C253
99 | 220nF/+80-20%/10VDC | C-EUC0402_TI | C1, C2, C3, C4, C5, C6, C7, C8, C9, C10, C11, C12, C13, C14, C16, C17, C18, C19, C20, C21, C22, C23, C24, C25, C26, C27, C28, C29, C30, C31, C32, C33, C34, C35, C36, C37, C38, C39, C40, C41, C42, C43, C44, C45, C46, C47, C48, C49, C50, C51, C52, C53, C54, C55, C56, C57, C58, C59, C60, C61, C62, C63, C64, C65, C66, C67, C68, C69, C70, C74, C75, C76, C92, C93, C94, C95, C96, C97, C98, C99, C100, C106, C107, C121, C126, C129, C130, C131, C132, C133, C144, C148, C164, C178,C182, C184, C189, C194, C196
2 | 470nF/X7R/16VDC/10% | C-EUC0603_DWS | C197, C199
6 | 1uF/10V/10%/X5R | C-EUC0603_DWS | C108, C125, C159, C176, C179, C180
7 | 4.7uF/6.3V | C-EUC0603_DWS | C158, C163, C171, C183, C185, C186, C188
13 | 10uF/6.3V | C-EUC0603_DWS | C127, C128, C134, C146, C150, C155, C160, C161, C162, C166, C170, C172, C174
38 | 22uF/6.3V | C-EUC0603_DWS | C15, C118, C120, C122, C123, C124, C138, C143, C145, C147, C151, C165, C168, C175, C177, C181, C190, C191, C192, C195, C198, C202, C203, C204, C205, C206, C207, C208, C210, C212, C213, C220, C222, C241, C246, C256, C257, C258
7 | 47uF/6.3V | C-EUC0805_5MIL_DWS | C72, C77, C79, C224, C232, C238, C245
1 | 470uF/10V/105C | CPOL-EUE2.5-6.3 | C200
6 | 2.2uH/NR3015T2R2M/1.5A/3015 | L-CD32 | L11, L12, L13, L14, L15, L16
9 | FB0805/600R/2A | L-USL0805_5MIL_DWS | L1, L2, L5, L6, L7, L8, L9, L10, L18
1 | 1N4007/SMA | D-MLL-41 | D6
1 | 1N4148/SOD80C | DSMD | D7
2 | 1N5819(S4SOD-123) | SCHOTKKY7.62SS-1N5819(S4SOD-123) | D1, D2
1 | 1N5822/SS34/SMA | D-MLL-41 | D5
1 | SMBJ6.0A | SMBJ16A | D3
1 | LED/GREEN/0603 | LEDLED-0603_TEST | LED1
1 | LED/RED/0603 | LEDLED-0603_TEST | PWR_LED
1 | LED/YELLOW/0603 | LEDLED-0603_TEST | CHGLED
1 | BC846B | NPN-TRANSISTOR_SOT23 | T1
1 | BSS138 | N-MOS+DIODBSS138(SOT23-3) | FET2
3 | IRLML6402 | P-MOS+DIODIRLML6402 | FET1, FET3, FET4
1 | Q32.768kHz/12.5pF/2P/SMD1206 | MC-306CM7V-T1A | Q2
1 | Q24MHz/20pF/20ppm/2P/5x3.2mm | HC49/STEST | Q3
1 | Q25MHz/20pF/30ppm/4P/3.2x2.5 | SMALL_SMD_CRYSTAL_1 | Q4
1 | A20 | A10 | U1
1 | AP1231-2.5V(SOT23-5) | AP1231-33 | VR1
1 | AT24C16C-SSHM-T(SOIC-8) | 24LCXX | U6
1 | AXP209(QFN48) | AXP209 | U13
2 | K4B4G1646E-BYMA0CV | H5TQ2G63BFR_MEM4G16D3EABG- 125HYNIX | U2, U3
1 | KSZ9031RNXCC-TR | KSZ9031RNX | U5
1 | LD1117AG-AD-AA3-A-R | LM1117 | VR3
1 | MT3608(SOT23-6) | SY7208 | U16
3 | SY6280AAC(SOT23-5) | SY6280 | U10, U11, U12
2 | SY8089AAAC(SOT23-5) | SY8008 | U15, U17
1 | VDA4710CTA | VDA2710NTA | U24
1 | HDMI-SWM-19 | HDMI-MC34931HDMI-SWM-19-OLD | HDMI
1 | DF12(3.0)-40DS-0.5V(86) | FLASH_CON[DF12(3.0)-40DS-0.5V(86)] | FLASH_CONNECTOR
2 | DW02R | CON2DW02R | 5V_SATA_PWR, LIPO_BAT
1 | PWRJ-2mm(YDJ-1134) | PWR-JAKPWR_JACK_UNI_MILLING | PWR_JACK
1 | HN1X3 | CON3HN1X3 | UART0
1 | M211Q01FM22(LPJG16402AQNL) | TM211Q01FM22_SH | LAN
1 | MALE-PAV16X-2x10-HIGH | ML20GPH127SMT-02X10(PA-V16X-2X10-LF) | GPIO-4
4 | MALE-PAV16X-2x20-HIGH | ML40-GPH127SMT-02X20(PA-V16X-2X20-LF) | GPIO-1, GPIO-2, GPIO-3, LCD_CON
1 | MICRO_SD/TFC-WPAPR-08 | MICRO_SD/MMC_CP_NEWTFC-WPAPR-08 | SD/MMC
1 | SATA-PWA-07 | SATA-PWA-07" | SATA
1 | USB-OTG(MSB-SW-5AB-LF) | MINI_USB9-USB-OTG(MSB-SW-5AB-LF) | USB_OTG
2 | USB-SUWH-4A-LF | USB_SHIELDUSB_A_VERTICAL | USB_HOST1, USB_HOST2
3 | TSW34-W16PR-220-LF/SIDE | SW-TAKTSIDE_WTCM-TR(3X4) | PWR, RECOVERY, RESET
1 | FSMD035 | FUSE | FUSE1
3 | Opened | SJSJ_SMALLER | 5V_E, 5V_E_SATA, WP_ENABLE
1 | PC3:Closed/PB8:Opened | SJ2W5 | PC3/PB8
1 | NA | C-EUC0402_TI | C80
12 | NA | R-EU_R0402_TI | R3, R15, R18, R23, R28, R38, R49, R50, R97, R98, R112, R122
1 | NA(0R) | R-EU_R0603_5MIL_DWS | R48
1 | NA(1N5822/SS34/SMA) | SCHOTKKY7.62SS2 | D4
6 | NA(2.2k) | R-EU_R0402_TI | R39, R40, R93, R94, R95, R96
2 | NA(2.7nH/0402) | L-USL0402_TI | L3, L4
3 | NA(10k) | R-EU_R0402_TI | R12, R16, R17
1 | NA(10uF/6.3V) | C-EUC0603_DWS | C251
3 | NA(22uF/6.3V) | C-EUC0603_DWS | C169, C221, C223
2 | NA(24pF) | C-EUC0402_TI | C81, C254
2 | NA(47uF/6.3V) | C-EUC0805_5MIL_DWS | C73, C78
1 | NA(100nF) | C-EUC0402_TI | C71
1 | NA(HN1X2) | CON2HN1X2 | BACKUP
1 | NA(MCP121T475I-TT) | RESETMCP130T-300-I/TT | U14
1 | NA(RA1206_(4X0603)_4B8_0R) | R_MATRIX_4E | RM2
1 | NA(RCLAMP0524P) | RCLAMP0524P | U8
2 | NA(RCLAMP0524P) | RCLAMP0524PTEST | U7, U9
1 | NA(W25Q128JVSIQ) | W25Q16BVSSIG(SO-8) | U22

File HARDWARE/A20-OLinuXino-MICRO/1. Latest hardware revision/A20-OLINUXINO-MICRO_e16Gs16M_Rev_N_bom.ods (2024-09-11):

Qty | Value | Device | Parts
4 | 0R/0402 | R-EU_R0402_TI | R155, R156, R157, R158
1 | 0.03R/1% | R-EU_R1206_5MIL_WS | R59
4 | 0R(Board_Mounted) | R_0R0R(NA) | R24, R34, R69, R87
12 | 1R | R-EU_R0603_5MIL_DWS | R3, R31, R51, R53, R60, R62, R63, R66, R68, R71, R72, R74
6 | 22R | R-EU_R0402_TI | R114, R118, R119, R133, R134, R135
8 | 49.9R/1% | R-EU_R0603_5MIL_DWS | R25, R43, R58, R103, R141, R142, R143, R149
1 | 191R/1% | R-EU_R0603_5MIL_DWS | R64
7 | 330R/1% | R-EU_R0603_5MIL_DWS | R7, R9, R16, R41, R104, R150, R151
2 | 1.1k/1% | R-EU_R0603_5MIL_DWS | R90, R92
21 | 2.2k/1% | R-EU_R0603_5MIL_DWS | R1, R2, R4, R6, R8, R32, R37, R39, R57, R65, R70, R73, R75, R76, R81, R82, R83, R86, R93, R94, R120
2 | 3.9k/1% | R-EU_R0603_5MIL_DWS | R48, R55
4 | 4.99k/1% | R-EU_R0603_5MIL_DWS | R42, R61, R89, R138
1 | 6.81k/1% | R-EU_R0603_5MIL_DWS | R96
2 | 8.25k/1% | R-EU_R0603_5MIL_DWS | R88, R97
20 | 10k | R-EU_R0603_5MIL_DWS | R10, R20, R30, R33, R38, R44, R46, R47, R54, R98, R105, R112, R113, R115, R116, R117, R136, R137, R152, R154
1 | 11k/1% | R-EU_R0603_5MIL_DWS | R99
1 | 12.1k/1% | R-EU_R0603_5MIL_DWS | R140
4 | 13k/1% | R-EU_R0603_5MIL_DWS | R45, R78, R80, R100
2 | 16.2k/1% | R-EU_R0603_5MIL_DWS | R77, R101
1 | 27k | R-EU_R0603_5MIL_DWS | R110
1 | 22.1k/1% | R-EU_R0603_5MIL_DWS | R102
6 | 47k | R-EU_R0603_5MIL_DWS | R27, R28, R52, R84, R95, R111
7 | 100k/1% | R-EU_R0603_5MIL_DWS | R11, R17, R29, R40, R85, R91, R108
3 | 200k/1% | R-EU_R0603_5MIL_DWS | R36, R56, R67
1 | 10M | R-EU_R0402_TI | R139
1 | RA1206_(4X0603)_4B8_0R | R_MATRIX_4E | RM1
1 | RA1206_(4X0603)_4B8_75R | R_MATRIX_4E | RM7
2 | RA1206_(4X0603)_4B8_1.5k | R_MATRIX_4E | RM9, RM10
1 | RA1206_(4X0603)_4B8_10k | R_MATRIX_4E | RM25
2 | RA1206_(4X0603)_4B8_100K | R_MATRIX_4E | RM8, RM11
2 | 22pF/50V/5%/COG/C0603 | C-EUC0603_DWS | C97, C98
6 | 33pF | C-EUC0603_DWS | C75, C76, C99, C100, C195, C208
8 | 1nF | C-EUC0603_DWS | C127, C129, C131, C132, C160, C165, C182, C218
1 | 1nF/2kV/X7R/1206 | C-EUC1206_5MILS_WS_ISO | C95
1 | 3.3nF | C-EUC0603_DWS | C163
1 | 150pF | C-EUC0603_DWS | C201
4 | 10nF | C-EUC0402_TI | C140, C141, C142, C143
16 | 100nF | C-EUC0603_DWS | C64, C67, C72, C74, C92, C94, C122, C124, C125, C161, C170, C171, C176, C200, C221, C233
48 | 220nF | C-EUC0402_TI | C2, C3, C5, C7, C10, C11, C14, C15, C18, C19, C21, C22, C23, C24, C25, C26, C27, C57, C59, C60, C61, C62, C68, C69, C70, C77, C78, C79, C80, C82, C83, C84, C85, C86, C87, C102, C106, C134, C139, C155, C169, C175, C184, C189, C191, C250, C252, C254
55 | 220nF | C-EUC0603_DWS | C1, C4, C6, C8, C9, C12, C16, C17, C20, C28, C29, C30, C31, C32, C33, C34, C35, C36, C37, C38, C39, C40, C41, C42, C43, C44, C45, C46, C47, C48, C49, C50, C51, C52, C53, C54, C55, C58, C81, C111, C114, C117, C118, C119, C120, C177, C224, C225, C226, C227, C228, C229, C230, C231, C232
2 | 470nF | C-EUC0603_DWS | C192, C196
7 | 1uF/6.3V | C-EUC0603_DWS | C73, C91, C110, C150, C167, C172, C174
3 | 2.2uF/6.3V | C-EUC0603_DWS | C251, C253, C255
6 | 2.2uF/50V | C-EUC0805_5MIL_DWS | C202, C203, C241, C242, C243, C244
7 | 4.7uF/6.3V | C-EUC0603_DWS | C146, C149, C158, C178, C179, C180, C187
14 | 10uF/6.3V | C-EUC0603_DWS | C112, C113, C121, C128, C136, C147, C148, C151, C152, C156, C159, C162, C164, C166
33 | 22uF/6.3V | C-EUC0603_DWS | C13, C56, C65, C66, C101, C103,C104, C105, C109, C115, C133, C138, C157, C168, C173, C186, C190, C193, C194, C198, C199, C204, C205, C206, C207, C209, C210, C211, C212, C216, C219, C220, C256
13 | 47uF/6.3V | C-EUC0805_5MIL_DWS | C123, C126, C135, C145, C217, C222, C223, C240, C245, C246, C247, C248, C249
6 | 2.2uH/NRS3015T2R2MNGH | L-CD32 | L12, L13, L14, L18, L20, L21
1 | 15uH/YS75 | LLQH88PN100M38 | L19
10 | FB0805/600R/2A | L-USL0805_5MIL_DWS | L2, L4, L5, L6, L7, L11, L15, L16, L17, L22
2 | 1N5819(S4SOD-123) | SCHOTKKY7.62SS-1N5819(S4SOD-123) | D1, D3
3 | 1N5822/SS34/SMA | SCHOTKKY7.62SS2 | D2, D4, D6
1 | SMBJ26A | SMBJ16A | D5
1 | LED/GREEN/0603 | LEDLED-0603_TEST | LED1
1 | LED/RED/0603 | LEDLED-0603_TEST | PWR_LED
1 | LED/YELLOW/0603 | LEDLED-0603_TEST | CHGLED
1 | BC846B(SOT23-3) | NPN-TRANSISTOR_SOT23 | T1
3 | BSS138(SOT23-3) | N-MOS+DIODBSS138(SOT23-3) | FET2, FET3, FET5
2 | IRLML6402(SOT23-3) | P-MOS+DIODIRLML6402 | FET1, FET4
1 | 32.768kHz/SMD1206/12.5pf | MC-306_MC-306-TEST | Q2
1 | Q24MHz/20pF/20ppm/2P/5.0x3.2mm | HC49/S_E4SB25.000F20E15 | Q3
1 | Q25MHz/20pF/20ppm/2P/5x3.2mm | HC49/S_E4SB25.000F20E15 | Q1
1 | A20(TFBGA441) | A10 | U1
1 | AP1231-2.5V(SOT23-5) | AP1231-33 | VR1
1 | AT24C16C-SSHM-T | 24LCXX | U6
1 | AXP209(QFN48) | AXP209 | U12
2 | K4B4G1646E-BYMA0CV | H5TQ2G63BFR_MEM4G16D3EABG-125PHIS | U2, U3
1 | KLMAG1JETD-B041003 | KLMAG2GEND-B031(FBGA153) | U26
1 | LAN8710A-EZC-AB | LAN8710A-EZC | U7
1 | MP1584EN(SOIC8E) | MP1584EN(SOIC8E) | U14
1 | MT3608(SOT23-6) | SY7208 | U16
3 | SY6280AAC(SOT23-5) | SY6280 | U9, U10, U11
2 | SY8089AAAC(SOT23-5) | SY8008 | U13, U15
1 | W25Q128JVSIQ(16MB) | W25Q16BVSSIG(SO-8) | U25
1 | ESDS314DBVR | ESDS314DBVR | ESD1
1 | FSMD035 | FUSE | FUSE1
1 | DW02R | CON2DW02R | LIPO_BAT
1 | DW02S | CON2DW02S | 5V_SATA_PWR
1 | HDMI-SWM-19 | HDMI-MC34931HDMI-SWM-19-OLD | HDMI
1 | HN1X4 | CON4HN1X4 | UART0
1 | MICRO_SD/TFC-WPAPR-08 | MMC_CP_NEWTFC-WPAPR-08 | SD/MMC1
1 | SD-MMC-PUSH- PUSH(PSD006A-LT2-BA0) | SD_CARDTEST | SD/MMC2
2 | P-B-V-10-LF | ML1016 | UEXT1, UEXT2
4 | P-B-V-40-LF | ML4016 | GPIO-1, GPIO-2, GPIO-3, LCD_CON
2 | PJ-W47S-05D2-LF | 5PINPJ-W47S-05D2-LF_V2 | HEADPHONES, MIC_IN
1 | PWRJ-2mm(YDJ-1134) | PWR-JAKPWR_JACK_UNI_MILLING | PWR
1 | RJLBC-060TC1(LPJ4013EDNL) | RJLBC-060TC1_GND_MILLING | LAN
1 | SATA-PWA-07 | SATA-PWA-07" | SATA
1 | USB-OTG(MSB-SW-5AB-LF) | MINI_USB9 | USB_OTG
1 | USBB1-FRWH-4A(USB-Ax2) | USB_TWO_LEVEL | USB_HOST
1 | WU06S | CON6 | VGA
10 | SWITCH_TSW34-W16PR- 220-LF/SIDE | SW-TAKTSIDE_WTCM-TR(3X4) | ENTER, ESC, HOME, MENU, PWR_BUT, RECOVERY, RESET, SEARCH, VOL+, VOL-
2 | Open | SJSJ_SMALLER | 5V_E, 5V_E_SATA
1 | Opened | SJSJ_SMALLER | WP_ENABLE
4 | NA | C-EUC0402_TI | C107, C108, C153, C154
5 | NA | C-EUC0603_DWS | C71, C181, C183, C185, C188
2 | NA | R-EU_R0402_SMALL | R12, R15
1 | NA | R-EU_R0402_TI | R159
6 | NA | R-EU_R0603_5MIL_DWS | R5, R22, R23, R49, R50, R153
1 | NA(0R) | R-EU_R0603_5MIL_DWS | R35
2 | NA(2.2k/1%) | R-EU_R0603_5MIL_DWS | R13, R14
1 | NA(10k) | R-EU_R0603_5MIL_DWS | R26
1 | NA(10uF/6.3V) | C-EUC0603_DWS | C63
4 | NA(22uF/6.3V) | C-EUC0603_DWS | C197, C213, C214, C215
1 | NA(47k) | R-EU_R0603_5MIL_DWS | R109
2 | NA(47uF/6.3V) | C-EUC0805_5MIL_DWS | C130, C137
1 | NA(100k/1%) | R-EU_R0603_5MIL_DWS | R79
2 | NA(330R/1%) | R-EU_R0603_5MIL_DWS | R106, R107
1 | NA(DF12(3.0)-40DS-0.5V(86)) | FLASH_CON[DF12(3.0)-40DS-0.5V(86)] | FLASH_CONNECTOR
1 | NA(DW02S) | CON2DW02S | 5V_PWR
2 | NA(FB0805/600R/2A) | L-USL0805_5MIL_DWS | L8, L10
1 | NA(HN1x2) | CON2HN1X2 | BKUP
1 | NA(HN1x2) | JP1E | MIC2
1 | NA(RA1206_(4X0603)_4B8_0R) | R_MATRIX_4E | RM2
3 | NA(RCLAMP0524P) | RCLAMP0524PTEST | U17, U22, U23

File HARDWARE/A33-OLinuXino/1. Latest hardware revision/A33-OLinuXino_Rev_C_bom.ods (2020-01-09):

Qty | Value | Device | Parts
1 | 0R | R-EU_R0603_5MIL_DWS | R77
1 | 0R | R-EU_R1206_5MIL | R76
9 | 0R(Board_Mounted) | R_0R0R(NA) | R36, R37, R38, R39, R45, R62, R63, R64, R73
2 | 0.01R/1% | R-EU_R1206_5MIL_WS | R35, R40
6 | 1R | R-EU_R0603_5MIL_DWS | R30, R31, R32, R33, R34, R54
5 | 22R | R-EU_R0402_TI | R17, R18, R65, R67, R68
6 | 243R/1% | R-EU_R0603_5MIL_DWS | R19, R21, R26, R55, R59, R66
2 | 1k | R-EU_R0603_5MIL_DWS | R47, R58
1 | 1.1k/1% | R-EU_R0603_5MIL_DWS | R72
2 | 1.5k | R-EU_R0603_5MIL_DWS | R52, R57
9 | 2k/1% | R-EU_R0603_5MIL_DWS | R2, R5, R7, R12, R24, R25, R42, R46, R69
4 | 2.2k | R-EU_R0603_5MIL_DWS | R48, R49, R50, R51
2 | 6.81k/1% | R-EU_R0603_5MIL_DWS | R28, R74
1 | 8.25k/1% | R-EU_R0603_5MIL_DWS | R70
5 | 10k | R-EU_R0603_5MIL_DWS | R1, R10, R23, R29, R56
4 | 100k | R-EU_R0603_5MIL_DWS | R9, R15, R27, R71
1 | 200k/1% | R-EU_R0603_5MIL_DWS | R41
1 | 10M | R-EU_R0402_SMALL | R75
1 | RA1206_(4X0603)_4B8_100K | R_MATRIX_4E | RM1
2 | 20pF | C-EUC0603_DWS | C68, C69
4 | 33pF | C-EUC0603_DWS | C66, C67, C112, C127
1 | 1nF | C-EUC0603_DWS | C17
62 | 100nF | C-EUC0402_TI | C3, C4, C5, C6, C7, C10, C11, C12, C18, C19, C20, C23, C24, C25, C26, C27, C28, C29, C30, C31, C32, C33, C34, C35, C36, C37, C38, C39, C40, C41, C42, C43, C44, C45, C46, C47, C48, C49, C50, C51, C52, C53, C56, C61, C62, C63, C64, C65, C72, C74, C82, C87, C88, C97, C110, C114, C118, C123, C134, C135, C136, C137
9 | 1uF | C-EUC0603_DWS | C2, C9, C22, C85, C91, C93, C104, C105, C111
1 | 2.2uH/3A/YS75/7x8 | LLQH88PN100M38 | L13
39 | 10uF/6.3V | C-EUC0603_DWS | C70, C71, C73, C75, C76, C77, C78, C79, C81, C83, C84, C86, C89, C90, C92, C94, C95, C96, C98, C99, C100, C102, C106, C107, C108, C109, C113, C116, C117, C119, C120, C122, C124, C125, C126, C128, C129, C130, C132
10 | 22uF/6.3V | C-EUC0603_DWS | C1, C8, C21, C54, C60, C138, C139, C140, C141, C142
4 | 47uF/6.3V/0805 | C-EUC0805_5MIL_DWS | C13, C55, C57, C58
1 | 1N5819(S4SOD-123) | SCHOTKKY7.62SS- 1N5819(S4SOD-123) | D1
2 | 1N5822/SS34/SMA | SCHOTKKY7.62SS2 | D3, D4
1 | SMBJ6.0A | SMBJ16A | D5
1 | LED/GREEN/0603 | LEDLED-0603_TEST | LED1
1 | LED/RED/0603 | LEDLED-0603_TEST | PWR
1 | LED/YELLOW/0603 | LEDLED-0603_TEST | CHGLED
5 | SWPA4018S1R5NT(1.5uH/3A/DCR<0.1R) | L-SWPA4018S | L4, L5, L6, L7, L9
6 | FB0805/600R/2A | L-USL0805_5MIL_DWS | L1, L2, L3, L10, L11, L12
1 | WPM1481 | WPM1481 | T1
1 | IRLML6402 | P-MOS+DIODIRLML6402 | FET1
1 | MC-306_32.768KHZ/SMD_8038/12.5pF | HC49/S_32768HZ/6PF | Q2
1 | 4SB24.000F20E15/5x3.2mm/20ppm/20pF | HC49/S_E4SB25.000F20E15 | Q1
1 | A33/TFBGA282 | A33/TFBGA282 | U1
1 | AXP223 | AXP221 | U6
2 | MEM4G08D3EABG-125 (TFBGA-78_DDR3-1600_11-11-11) | H5TQ2G83CFR-H9C | U2, U3
1 | MT3608(SOT23-6) | SY7208 | U7
1 | SY6280(SOT23-5) | SY6280 | U5
1 | DW02R | CON2DW02R | LIPO_BAT
1 | FPV-WZA21-40-LF | ML40-FPV-WZA21-40-LF | CSI/DSI
1 | HN1X5 | CON5HN1X5 | UART0
1 | PWRJ-2mm(YDJ-1134) | PWR-JAKPWR_JACK_UNI_MILLING | PWR_JACK
2 | SCJ325P00XG0B02G | AUDIO_JACK_3-5PIN | HEADPHONES, MIC
1 | TFC-WPAPR-08 | MICRO_SD/MMC_CP_ NEWTFC-WPAPR-08 | MICRO_SD
1 | USB-OTG | MINI_USB9 | USB_OTG
1 | IT1185AU2 | SW-TAKTIT1185AU2 | UBOOT
2 | SIDE_WTCM-TR(3X4) | SW-TAKTSIDE_WTCM-TR(3X4) | PWR_BUT, RESET
1 | 1-2:Closed/2-3:Opened | SJ2W6 | PWRON/PL11
1 | Open | SJSJ_SMALLER | 5V_E
1 | open/close | SJ2W5 | LCD_VCC
1 | NA | R-EU_R0402_TI | R11
5 | NA | R-EU_R0603_5MIL_DWS | R8, R13, R16, R60, R61
2 | NA(2.2k) | R-EU_R0603_5MIL_DWS | R43, R44
4 | NA(10k) | R-EU_R0603_5MIL_DWS | R3, R4, R14, R53
4 | NA(10uF/6.3V) | C-EUC0603_DWS | C101, C103, C131, C133
1 | NA(22R) | R-EU_R0402_TI | R6
1 | NA(47uF/6.3V/0805) | C-EUC0805_5MIL_DWS | C59
5 | NA(100nF) | C-EUC0402_TI | C14, C15, C16, C80, C115
2 | NA(243R/1%) | R-EU_R0603_5MIL_DWS | R20, R22
1 | MT29F64G08CBABAWP:BTR (8GB_NAND) | H27UBG8T2A | U4
2 | NA(HN2X20) | ML40HN2X20 | GPIO, LCD
1 | NA(SWPA4018S1R5NT (1.5uH/3A/DCR<0.1R)) | L-SWPA4018S | L8

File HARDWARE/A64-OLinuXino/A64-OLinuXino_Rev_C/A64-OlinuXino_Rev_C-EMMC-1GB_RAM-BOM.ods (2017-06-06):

Quantity | Designation | Package | Designator
2 | 10pF/50V/5% | C_0402_5MIL_DWS | C183,C184
2 | 27pF/50V/5% | C_0603_5MIL_DWS | C212,C213
7 | 33pF/50V/5% | C_0402_5MIL_DWS | C187,C48,C62,C105,C185,C84,C85
1 | 1nF/2kV/10%/X7R | C_1206_5MIL_DWS_ISO | C196
81 | 100nF/10V/10% | C_0402_5MIL_DWS | C1,C2,C3,C4,C6,C7,C8,C9,C11, C12,C13,C14,C15,C17,C18,C19, C20,C22,C23,C24,C25,C28,C29, C30,C31,C32,C33,C34,C35,C37, C44,C46,C50,C51,C52,C58,C60, C65,C66,C67,C72,C73,C74,C79, C80,C90,C92,C109,C110,C115, C117,C123,C127,C130,C132, C134,C155,C156,C158,C177, C186,C189,C191,C195,C197, C199,C200,C203,C206,C207, C208,C209,C210,C215,C216, C217,C45,C82,C83,C86,C87
14 | 1uF/10V/10% | C_0603_5MIL_DWS | C27,C38,C43,C55,C120,C135, C137,C142,C160,C163,C181, C182,C190,C211
2 | 2.2uF/6.3V/10% | C_0603_5MIL_DWS | C56,C61
63 | 10uF/6.3V/20% | C_0603_5MIL_DWS | C91,C5,C10,C16,C21,C26,C42, C47,C49,C53,C54,C57,C59,C63, C89,C116,C121,C122,C124,C125, C126,C128,C129,C131,C133, C136,C138,C139,C140,C141,C143, C144,C145,C146,C147,C148,C149, C150,C151,C152,C153,C154,C157, C159,C161,C162,C164,C165,C166, C167,C168,C169,C170,C171,C172, C173,C175,C176,C178,C179,C188, C192,C194
6 | 22uF/6.3V/20% | C_0603_5MIL_DWS | C36,C204,C205,C214,C218,C219
10 | 47uF/6.3V/20% | C_0805_5MIL_DWS | C64,C68,C71,C75,C78,C118, C119,C180,C201,C202
5 | 0R(Board_Mounted) | R_0402_5MIL_0R(Board_Mounted) | R34,R62,R86,R87,R94
1 | 0R(Board_Mounted) | R_0603_5MIL_0R(Board_Mounted) | R36
1 | 0.01R/1%/1206 | R_1206_5MIL_DWS | R78
10 | 22R | R_0402_5MIL_DWS | R3,R4,R33,R54,R100,R105, R109,R63,R64,R65
1 | 100R/1% | R_0402_5MIL_DWS | R2
1 | 120R | R_0603_5MIL_DWS | R120
3 | 243R/1% | R_0402_5MIL_DWS | R7,R9,R10
1 | 470R | R_0402_5MIL_DWS | R25
12 | 1k | R_0402_5MIL_DWS | R92,R89,R91,R107,R108,R110, R111,R112,R113,R114,R117,R58
1 | 1.1k/1% | R_0402_5MIL_DWS | R81
7 | 2k/1% | R_0402_5MIL_DWS | R11,R12,R1,R5,R8,R26,R29
10 | 2.2k | R_0402_5MIL_DWS | R70,R71,R74,R82,R90,R88,R75, R77,R47,R50
1 | 3.92k/1% | R_0402_5MIL_DWS | R49
2 | 4.7k | R_0402_5MIL_DWS | R38,R51
1 | 8.25k/1% | R_0402_5MIL_DWS | R80
15 | 10k | R_0402_5MIL_DWS | R37,R40,R42,R85,R83,R95,R76, R79,R31,R52,R21,R23,R99,R106, R119
1 | 12.1k/1% | R_0603_5MIL_DWS | R115
1 | 13k/1% | R_0402_5MIL_DWS | R41
1 | 27k | R_0402_5MIL_DWS | R46
1 | 47k | R_0402_5MIL_DWS | R59
4 | 100k | R_0402_5MIL_DWS | R30,R35,R103,R116
1 | 200k/1% | R_0402_5MIL_DWS | R27
1 | 10M | R_0402_5MIL_DWS | R93
4 | RA0805_(4X0402)_22R | RA0805_(4X0402)_xx | RM2,RM5,RM3,RM14
1 | RA1206_(4x0603)_4B8_22R | RA1206_(4X0603)_4B8_xx | RM15
1 | RA1206_(4x0603)_4B8_4.7k | RA1206_(4X0603)_4B8_xx | RM8
2 | RA1206_(4X0603)_4B8_10k | RA1206_(4X0603)_4B8_xx | RM4,RM1
3 | RA1206_(4x0603)_4B8_100k | RA1206_(4X0603)_4B8_xx | RM9,RM7,RM12
1 | 2.2uH/3A/YS75/7x8 | YS75_7X8MM | L16
3 | SWPA3015S1R5NT(1.5uH/2.30A/DCR<0.1R/CD32) | CD32 | L14,L20,L19
3 | SWPA4018S1R5NT(1.5uH/3.35A/DCR<0.1R/CD43) | CD42(43) | L18,L15,L17
10 | FB0805/600R/2A | L_0805_5MIL_DWS | L1,L2,L3,L4,L5,L6,L8,L21,L23,L24
1 | SMBJ6.0A | DO214AA | D1
1 | 1N4007/SMA | SMA-KA | D5
2 | 1N5822/SS34/SMA | SMA-KA | D2,D3
1 | 1N5819(S4SOD-123) | SOD-123_1C-2A_KA | D4
1 | WPM1481-6/TR(DFN2X2-6L) | DFN2x2-6L | T1
1 | BSS138(SOT23-3) | SOT23 | FET1
1 | IRLML6402(SOT-23) | SOT23 | FET2
1 | AMS1117(ADJ) | SOT223 | VR1
1 | MC-306_32.768KHZ/12.5pF/20ppm/SMD_8038 | MC306-HS | Q2
1 | 4SB24.000F20E15/5x3.2mm/20ppm/20pF | Q5x3.25 | Q3
1 | E4SB25.000F20E15(25MHz/20pF/20ppm/5x3.2mm) | HCX-4S_2Pins_5.0x3.2mm | Q4
2 | LED/Red/0603 | LED_0603_KA | PWRLED1,GPIO_LED1
1 | LED/YELLOW/0603 | LED_0603_KA | CHGLED1
1 | FSMD035 | FUSE-1206 | FUSE1
1 | NA(5025) | FUSE-5025 | FUSE2
3 | IT-1185AU2-160G-G-TR | uTACTIL | PWRON1,RESET1,UBOOT1
1 | HDMI-SWM-19 | HDMI-SWM-19 | HDMI1
1 | USB_A_VERTICAL | USB_A_VERTICAL_PTH | USB1
1 | MICRO_USB/MISB-SWMM-5B_LF | USB-MICRO_MISB-SWMM-5B_LF | USB-OTG1
1 | FPV-WZA21-40-LF | FPV-WZA21-40-LF | LCD_CON1
1 | FPV-WZA21-20-LF | FPV-WZA21-20-LF | MIPI-DSI1
1 | DW02R | LIPO_BAT-CON2DW02R | LIPO_BAT1
1 | TM211Q01FM22 | TM211Q01FM22 | LAN1
1 | MICRO_SD(TFC-WPAPR-08) | TFC-WPAPR-08 | MICRO_SD1
1 | PWRJ-2mm(YDJ-1134) | PWRJ-2mm(YDJ-1134) | PWR1
1 | SCJ325P00XG0B02G | SCJ325P00XG0B02G | HEADPHONES/LINEOUT1, MIC/LINEIN1
1 | AllWinner-A64(FBGA396) | FBGA396 | U1
2 | K4B4G1646Q-HYK0 (FBGA-96_256Mx16_DDR3-1600_11-11-11) | FBGA96 (HYNIX_SAMSUNG_512MX16_DDR3) | U2,U3
1 | MTFC4GACAANA-4M_IT(TBGA100) | TBGA100 | U5
2 | SY6280AAC(SOT23-5) | SOT-23-5 | U6,U9
1 | RTL8723BS(ComboModule) | RL-SM02BD(RTL8723BS) | U11
1 | MT3608(SOT23-6) | SOT23-6 | U13
1 | AXP803(QFN68_8x8mm) | QFN68 | U14
1 | KSZ9031RNXCC (QFN48_1DRILL(PADPITCH-0.5MM)) | QFN48_1DRILL(PADPITCH-0.5MM) | U15
1 | HN1x2(Opened) | HN1x2_Jumper | PHYRST1
1 | HN1x3 | HN1x3 | DBG_UART1
2 | Opened | SJ | 5V_E1,HSIC_E1
1 | Unsoldered | SJ | NAND_E1
1 | Opened(2-3);Closed(1-2) | SJ_2_SMALL_12_TIED | 3.3V/VCC-PE:2.8V1
3 | Opened(2-3);Soldered(1-2) | SJ_2_SMALL | LINEINL/MICIN1N1, LINEINR/MICIN1P1,PWR_PC1
2 | Soldered(1-2);Opened(2-3) | SJ_2_SMALL | PHONEOUTL/LINEOUTL1, PHONEOUTR/LINEOUTR1
4 | NA(100nF/10V/10%) | C_0402_5MIL_DWS | C39,C40,C41,C81
4 | NA(47uF/6.3V/20%) | C_0805_5MIL_DWS | C69,C70,C76,C77
3 | NA | C_0402_5MIL_DWS | C106,C107,C198
1 | NA(110uF/6.3V/20%) | C_0603_5MIL_DWS | C174
1 | NA(1nF/50V/10%) | C_0402_5MIL_DWS | C193
1 | NA(1k) | R_0402_5MIL_DWS | R28
1 | NA(22R) | R_0402_5MIL_DWS | R18
4 | NA(510R) | R_0402_5MIL_DWS | R39,R43,R44,R45
1 | NA(0R) | R_0402_5MIL_DWS | R60
10 | NA | R_0402_5MIL_DWS | R96,R97,R98,R84,R19,R20,R24, R6,R118,R55
10 | NA(10k) | R_0402_5MIL_DWS | R61,R104,R48,R15,R16,R17, R22,R53,R56,R57
2 | NA(2.2k) | R_0402_5MIL_DWS | R101,R102
1 | NA(1M) | R_0402_5MIL_DWS | R32
2 | NA(243R/1%) | R_0402_5MIL_DWS | R13,R14
1 | NA(B4B-PH-K-S) | B4B-PH-K-S | HSIC1
1 | NA(HN2x20) | HN2x20 | GPIO1
1 | NA(HN2x5) | HN2x5 | UEXT1
1 | NA(W25Q128FVSIG(EN25Q64-104HIP)) | SO-8_208mil | U12
3 | NA(RCLAMP0524P(SLP2510P8)) | SLP2510P8 | U10,U8,U7
1 | NA(H27UBG8T2BTR-BC(TSOP48)) | TSOP48 | U4

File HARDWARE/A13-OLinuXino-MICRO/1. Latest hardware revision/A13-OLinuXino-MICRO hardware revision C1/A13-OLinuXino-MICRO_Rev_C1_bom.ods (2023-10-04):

Qty | Value | Device | Parts
1 | 0R(Board_Mounted) | R_0R0R(NA) | R1
8 | 22R | R-EU_R0603_5MIL_DWS | R62, R63, R64, R65, R66, R69, R70, R71
4 | 51R | R-EU_R0603_5MIL_DWS | R5, R6, R52, R72
3 | 240R/1% | R-EU_R0603_5MIL_DWS | R8, R11, R13
3 | 549R/1% | R-EU_R0603_5MIL_DWS | R34, R35, R36
6 | 1k/1% | R-EU_R0603_5MIL_DWS | R9, R12, R16, R39, R40, R45
3 | 1.05k/1% | R-EU_R0603_5MIL_DWS | R31, R32, R33
1 | 1.5k/1% | R-EU_R0603_5MIL_DWS | R21
2 | 2k/1% | R-EU_R0603_5MIL_DWS | R7, R10
5 | 2.2k | R-EU_R0603_5MIL_DWS | R44, R47, R48, R51, R54
4 | 2.2k/1% | R-EU_R0603_5MIL_DWS | R28, R29, R30,R17
1 | 3.3k/1% | R-EU_R0603_5MIL_DWS | R41
3 | 4.32k/1% | R-EU_R0603_5MIL_DWS | R25, R26, R27
1 | 4.99k/1% | R-EU_R0603_5MIL_DWS | R37
1 | 6.8k/1% | R-EU_R0603_5MIL_DWS | R55
3 | 8.66k/1% | R-EU_R0603_5MIL_DWS | R22, R23, R24
5 | 10k | R-EU_R0603_5MIL_DWS | R15, R38, R43, R56, R60
2 | 13k/1% | R-EU_R0603_5MIL_DWS | R59, R68
3 | 17.8k/1% | R-EU_R0603_5MIL_DWS | R18, R19, R20
1 | 22k/1% | R-EU_R0603_5MIL_DWS | R46
4 | 47k | R-EU_R0603_5MIL_DWS | R2, R3, R49, R57
3 | 100k/1% | R-EU_R0603_5MIL_DWS | R42, R53, R58
2 | 200k/1% | R-EU_R0603_5MIL_DWS | R4, R67
11 | RA0805_(4X0402)_22R | R_MATRIX_4E_25X625 | RM1, RM2, RM3, RM4, RM5, RM6, RM7, RM8, RM9, RM10, RM16
1 | RA1206_(4X0603)_4B8_100K | R_MATRIX_4E | RM12
2 | 22pF | C-EUC0603_DWS | C75, C81
2 | 33pF | C-EUC0603_DWS | C33, C34
1 | 47pF | C-EUC0603_DWS | C89
7 | 1nF | C-EUC0603_DWS | C64, C65, C69, C70, C71, C79, C103
48 | 100nF | C-EUC0603_DWS | C1, C11, C13, C15, C16, C17, C18, C19, C20, C21, C22, C24, C25, C26, C28, C29, C30, C31, C32, C37, C39, C41, C42, C43, C44, C45, C46, C47, C48, C49, C51, C52, C56, C57, C58, C59, C60, C63, C66, C67, C68, C84, C85, C86, C90, C95, C100, C104
1 | 1uF | C-EUC0603_DWS | C38
12 | 10uF/6.3V | C-EUC0603_DWS | C4, C5, C6, C8, C9, C12, C14, C36, C40, C62, C78, C98
21 | 22uF/6.3V | C-EUC0603_DWS | C2, C3, C7, C10, C23, C27, C50, C72, C73, C74, C76, C77, C80, C82, C83, C88, C91, C92, C93, C94, C97
2 | 100uF/16V/LOWESR/105C/ 6.3x11mm_RM2.5 | CPOL-EUE2.5-6.3 | C53, C101
1 | 470uF/16V/105C | CPOL-EUE3.5-8 | C102
4 | 2.2uH/1.5A/DCR<0.1R/CD32 | L-CD32 | L2, L3, L4, L5
5 | FB0805/600R/2A | L-USL0805_5MIL_DWS | L1, L6, L7, L8, L9
1 | SMBJ6.0 | SMBJ16A | D8
1 | 1N5819(S4SOD-123) | SCHOTKKY7.62SS- 1N5819(S4SOD-123) | D1
1 | 1N5819/SS14 | SCHOTKKY7.62SS2 | D7
5 | BAT54S | DIODE_AC-AC_ | D2, D3, D4, D5, D6
1 | LED/GREEN/0603 | LED0603DWS | LED1
1 | LED/RED/0603 | LED0603DWS | PWR_LED
3 | BSS138 | N-MOS+DIODBSS138(SOT23-3) | FET1, FET2, FET4
1 | IRLML6402 | P-MOS+DIODIRLML6402 | FET3
1 | 24Mhz/HU49SM/20ppm/20pf | HC49/S1 | Q1
1 | A13 | A13 | U1
1 | MCP130T-300I/TT | RESETMCP130T-300-I/TT | U13
1 | MT41K128M16JT-125:K | H5TQ2G63BFR | U2
3 | SN74LVC244APWR | 74ALVC244 | U4, U5, U6
2 | SY6280AAC | SY6280 | U9, U12
3 | SY8089AAAC | SY8008 | U3, U7, U8
1 | HN1X4 | CON4HN1X4 | UART1
2 | BH10S | ML10 | GPIO-1, UEXT
2 | BH40S | ML40 | GPIO-2, LCD_CON
1 | MICRO_SD/TFC-WPAPR-08 | MICRO_SD/MMC_CP_ NEWTFC-WPAPR-08 | SD/MMC1
1 | PJ-W47S-05D2-LF_V2 | AUDIO_JACK_5PINPJ- W47S-05D2-LF_V2 | HEADPHONES
1 | USB-OTG (MSB-SW-5AB-LF) | MINI_USB9 | USB_OTG
1 | USB-SRWH-4A-LF (USB-A) | USB_SHIELD3 | USB_HOST
1 | VGA15 | DB1522 | VGA_DB15-F
1 | YDJ-1134 | PWR-JAKPWR_JACK_ UNI_MILLING | PWR
2 | T1107A(6x3.8x2.5mm) | SW-TAKT6 | RESET, UBOOT
4 | Close | SJSJ_1_SMALLER_CLOSE | 1.2V_E, 1.5V_E, 3.3V_E, 5V_E
1 | Open | SJSJ_SMALLER | HOST_EN
1 | 10k(NA) | R-EU_R0603_5MIL_DWS | R50
2 | NA | C-EUC0603_DWS | C35, C55
1 | NA | CPOL-EUE3.5-8 | C54
2 | NA | R-EU_R0603_5MIL_DWS | R61, R73
1 | NA(1M) | R-EU_R0603_5MIL_DWS | R14
1 | NA(22uF/6.3V) | C-EUC0603_DWS | C61
1 | NA(100nF) | C-EUC0603_DWS | C87
1 | NA(HN1X4) | CON4HN1X4 | UART0
1 | NA(HN1X6) | CON6HN1X6 | JTAG
1 | NA(HN1x2) | JP1E | MIC

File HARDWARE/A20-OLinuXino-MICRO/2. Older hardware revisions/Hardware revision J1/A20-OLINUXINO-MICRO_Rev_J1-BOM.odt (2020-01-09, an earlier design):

Partlist exported from Z:/SVN_Checkout/A10-A20-OLINUXINO-MICRO/Hardware/tags/A20-OLINUXINO-MICRO_Rev_J1/BRD/A20-OLINUXINO-MICRO_Rev_J1.sch at 31.10.2017 15:18:25

Qty Value Device Parts

1 0.03R/1% R-EU_R1206_5MIL_WS R59

4 0R(Board_Mounted) R_0R0R(NA) R24, R34, R69, R87

2 0R/0805 L-USL0805_5MIL_DWS L8, L10

2 1.1k/1% R-EU_R0603_5MIL_DWS R90, R92

2 1N5819(S4SOD-123) SCHOTKKY7.62SS-1N5819(S4SOD-123) D1, D3

3 1N5822/SS34/SMA SCHOTKKY7.62SS2 D2, D4, D6

12 1R R-EU_R0603_5MIL_DWS R3, R31, R51, R53, R60, R62, R63, R66, R68, R71, R72, R74

8 1nF C-EUC0603_DWS C127, C129, C131, C132, C160, C165, C182, C218

1 1nF/2kV/X7R/1206 C-EUC1206_5MILS_WS_ISO C95

7 1uF C-EUC0603_DWS C73, C91, C110, C146, C150, C167, C174

21 2.2k/1% R-EU_R0603_5MIL_DWS R1, R2, R4, R6, R8, R32, R37, R39, R57, R65, R70, R73, R75, R76, R81, R82, R83, R86, R93, R94, R120

6 2.2uF/50V C-EUC0805_5MIL_DWS C202, C203, C241, C242, C243, C244

6 2.2uH/1.5A/DCR<0.1R/CD32 L-CD32 L12, L13, L14, L18, L20, L21

1 3.3nF C-EUC0603_DWS C163

2 3.9k/1% R-EU_R0603_5MIL_DWS R48, R55

4 4.99k/1% R-EU_R0603_5MIL_DWS R42, R61, R89, R138

1 4SB24.000F20E15/5x3.2mm/20ppm/20pF HC49/S_E4SB25.000F20E15 Q3

1 4SB25.000F20E15/5x3.2mm/20ppm/20pF HC49/S_E4SB25.000F20E15 Q1

1 6.81k/1% R-EU_R0603_5MIL_DWS R96

2 8.25k/1% R-EU_R0603_5MIL_DWS R88, R97

1 10M R-EU_R0402_TI R139

14 10k R-EU_R0603_5MIL_DWS R10, R20, R30, R33, R38, R44, R46, R47, R54, R98, R105, R136, R137, R152

4 10nF C-EUC0402_TI C140, C141, C142, C143

2 10pF C-EUC0603_DWS C97, C98

23 10uF/6.3V C-EUC0603_DWS C112, C113, C121, C128, C136, C145, C147, C148, C149, C151, C152, C156, C158, C159, C162, C164, C166, C172, C177, C178, C179, C180, C187

1 11k/1% R-EU_R0603_5MIL_DWS R99

1 12.1k/1% R-EU_R0603_5MIL_DWS R140

4 13k/1% R-EU_R0603_5MIL_DWS R45, R78, R80, R100

1 15uH/YS75 LLQH88PN100M38 L19

2 16.2k/1% R-EU_R0603_5MIL_DWS R77, R101

1 22.1k/1% R-EU_R0603_5MIL_DWS R102

5 22R R-EU_R0402_TI R118, R119, R133, R134, R135

35 22uF/6.3V C-EUC0603_DWS C13, C56, C65, C66, C101, C103, C104, C105, C109, C115, C130, C133, C137, C138, C157, C168, C173, C186, C190, C193, C194, C197, C198, C199, C204, C205, C206, C207, C209, C210, C211, C212, C216, C219, C220

6 33pF C-EUC0603_DWS C75, C76, C99, C100, C195, C208

6 47k R-EU_R0603_5MIL_DWS R27, R28, R40, R52, R84, R95

6 47uF/6.3V C-EUC0805_5MIL_DWS C123, C126, C135, C222, C223, C240

8 49.9R/1% R-EU_R0603_5MIL_DWS R25, R43, R58, R103, R141, R142, R143, R149

6 100k/1% R-EU_R0603_5MIL_DWS R11, R17, R29, R85, R91, R108

2 100nF C-EUC0402_TI C102, C200

14 100nF C-EUC0603_DWS C64, C67, C72, C74, C92, C94, C122, C124, C125, C161, C170, C171, C176, C221

1 150pF C-EUC0603_DWS C201

1 191R/1% R-EU_R0603_5MIL_DWS R64

3 200k/1% R-EU_R0603_5MIL_DWS R36, R56, R67

44 220nF C-EUC0402_TI C2, C3, C5, C7, C10, C11, C14, C15, C18, C19, C21, C22, C23, C24, C25, C26, C27, C57, C59, C60, C61, C62, C68, C69, C70, C77, C78, C79, C80, C82, C83, C84, C85, C86, C87, C106, C134, C139, C155, C169, C175, C184, C189, C191

54 220nF C-EUC0603_DWS C1, C4, C6, C8, C9, C12, C16, C17, C20, C28, C29, C30, C31, C32, C33, C34, C35, C36, C37, C38, C39, C40, C41, C42, C43, C44, C45, C46, C47, C48, C49, C50, C51, C52, C53, C54, C55, C58, C81, C111, C114, C117, C118, C119, C120, C224, C225, C226, C227, C228, C229, C230, C231, C232

1 220uF/10V/TANT_D CPOL-EUCT7343 C217

7 330R/1% R-EU_R0603_5MIL_DWS R7, R9, R16, R41, R104, R150, R151

2 470nF C-EUC0603_DWS C192, C196

1 32768Hz/6pF MC-306_32.768KHZ/SMD_8038 Q2

1 A20(TFBGA441) A10 U1

1 AP1231-2.5V(SOT23-5) AP1231-33 VR1

1 AT24C16BN-SH(SOIC-8) 24LCXX U6

1 AXP209(QFN48) AXP209 U12

1 BC846B(SOT23-3) NPN-TRANSISTOR_SOT23 T1

2 BSS138(SOT23-3) N-MOS+DIODBSS138(SOT23-3) FET2, FET3

1 Close SJSJ_1_SMALLER_CLOSE_10MILS NAND_E

1 DW02R CON2DW02R LIPO_BAT

1 DW02S CON2DW02S 5V_SATA_PWR

9 FB0805/600R/2A L-USL0805_5MIL_DWS L4, L5, L6, L7, L11, L15, L16, L17, L22

6 FIDUCIAL FIDUCIAL U4, U5, U18, U19, U20, U21

1 FSMD035 FUSE FUSE1

2 GBH-254-SMT-10 ML10MD UEXT1, UEXT2

4 GBH-254-SMT-40 ML40-GBH-254-SMT-40 GPIO-1, GPIO-2, GPIO-3, LCD_CON

1 HDMI-SWM-19 HDMI-MC34931HDMI-SWM-19 HDMI

1 HN1X4 CON4HN1X4 UART0

2 IRLML6402(SOT23-3) P-MOS+DIODIRLML6402 FET1, FET4

1 LAN8710A-EZC-TR(QFN-32) LAN8710A-EZC U7

1 LED/GREEN/0603 LED0603DWS LED1

1 LED/RED/0603 LED0603DWS PWR_LED

1 LED/YELLOW/0603 LED0603DWS CHGLED

1 MICRO_SD/TFC-WPAPR-08 MICRO_SD/MMC_CP_NEWTFC-WPAPR-08 SD/MMC1

1 MP1584EN(SOIC8E) MP1584EN(SOIC8E) U14

2 MT41K256M16HA-125:E(DDR3L-1600_11-11-11) H5TQ2G63BFR_MEM4G16D3EABG-125PHIS U2, U3

4 NA C-EUC0402_TI C107, C108, C153, C154

5 NA C-EUC0603_DWS C71, C181, C183, C185, C188

1 NA C-EUC1206_5MILS_WS_ISO C93

2 NA R-EU_R0402_SMALL R12, R15

5 NA R-EU_R0603_5MIL_DWS R5, R22, R23, R49, R50

11 NA(0R) R-EU_R0402_TI R122, R123, R124, R125, R126, R127, R128, R129, R130, R131, R132

1 NA(0R) R-EU_R0603_5MIL_DWS R35

2 NA(2.2k) R-EU_R0603_5MIL_DWS R13, R14

2 NA(2.2uF) C-EUC0603_DWS C116, C144

3 NA(2.2uF/6.3V) C-EUC0603_DWS C234, C236, C239

2 NA(10k) R-EU_R0402_TI R144, R145

5 NA(10k) R-EU_R0603_5MIL_DWS R18, R19, R21, R26, R121

1 NA(10uF/6.3V) C-EUC0603_DWS C63

3 NA(22R) R-EU_R0402_TI R146, R147, R148

4 NA(22uF/6.3V) C-EUC0603_DWS C96, C213, C214, C215

1 NA(47k) R-EU_R0603_5MIL_DWS R109

1 NA(100k) R-EU_R0603_5MIL_DWS R79

3 NA(100nF) C-EUC0402_TI C235, C237, C238

3 NA(100nF) C-EUC0603_DWS C88, C89, C90

1 NA(220uF/6.3V/tant) CPOL-EUCT6032 C233

2 NA(330R/1%) R-EU_R0603_5MIL_DWS R106, R107

1 NA(DW02S) CON2DW02S 5V_PWR

1 NA(FB0805/600R/2A) L-USL0805_5MIL_DWS L1

1 NA(H27UBG8T2BTR(TSOP48)) H27UBG8T2A U8

1 NA(HN1X2) CON2HN1X2 BKUP

1 NA(HN1x2) JP1E MIC2

1 NA(MTFC4GACAANA-4M_IT(TBGA100)) MTFC4GACAANA-4MIT U24

2 NA(RA0805_(4X0402)_22R) R_MATRIX_4E_25X625 RM4, RM5

1 NA(RA1206_(4X0603)_4B8_0R) R_MATRIX_4E RM2

2 NA(RA1206_(4X0603)_4B8_10k) R_MATRIX_4E RM3, RM6

3 NA(RCLAMP0524P) RCLAMP0524P U17, U22, U23

4 Open SJSJ_SMALLER 5V_E, 5V_E_SATA, VPS+, VPS-

2 PJ-W47S-05D2-LF_V2 AUDIO_JACK_5PINPJ-W47S-05D2-LF_V2 HEADPHONES, MIC_IN

1 PSD006A-LT2-BA0 SD_CARD_PSD006A-LT2-BA0 SD/MMC2

1 PWRJ-2mm(YDJ-1136) PWR-JAKPWR_JACK_UNI_MILLING_SMALLER_DRILLS PWR

1 RA1206_(4X0603)_4B8_0R R_MATRIX_4E RM1

2 RA1206_(4X0603)_4B8_1.5k R_MATRIX_4E RM9, RM10

1 RA1206_(4X0603)_4B8_10k R_MATRIX_4E RM25

1 RA1206_(4X0603)_4B8_75R R_MATRIX_4E RM7

2 RA1206_(4X0603)_4B8_100K R_MATRIX_4E RM8, RM11

1 RJLBC-060TC1 RJLBC-060TC1_GND_MILLING LAN

1 SATA-PWA-07 SATA-PWA-07 SATA

10 SIDE_WTCM-TR(3X4) SW-TAKTSIDE_WTCM-TR(3X4) ENTER, ESC, HOME, MENU, PWR_BUT, RECOVERY, RESET, SEARCH, VOL+, VOL-

1 SMBJ26A SMBJ16A D5

3 SY6280AAC(SOT23-5) SY6280 U9, U10, U11

1 SY7208(SOT23-6) SY7208 U16

2 SY8009AAAC(SOT23-5) SY8008 U13, U15

1 TESTPAD3 TESTPAD3 GND_PIN

11 TESTPADTESTPAD_40-ROUND TESTPADTESTPAD_40-ROUND +5V, 1.2V_CPU, 1.2V_INT, 1.5V, 2.5V, 3.0VA, 3.3V, 5VEXT, BAT, GND, IPSOUT

1 USB-OTG MINI_USB9 USB_OTG

1 USB_TWO_LEVEL USB_TWO_LEVEL USB_HOST

1 WU06S CON6 VGA

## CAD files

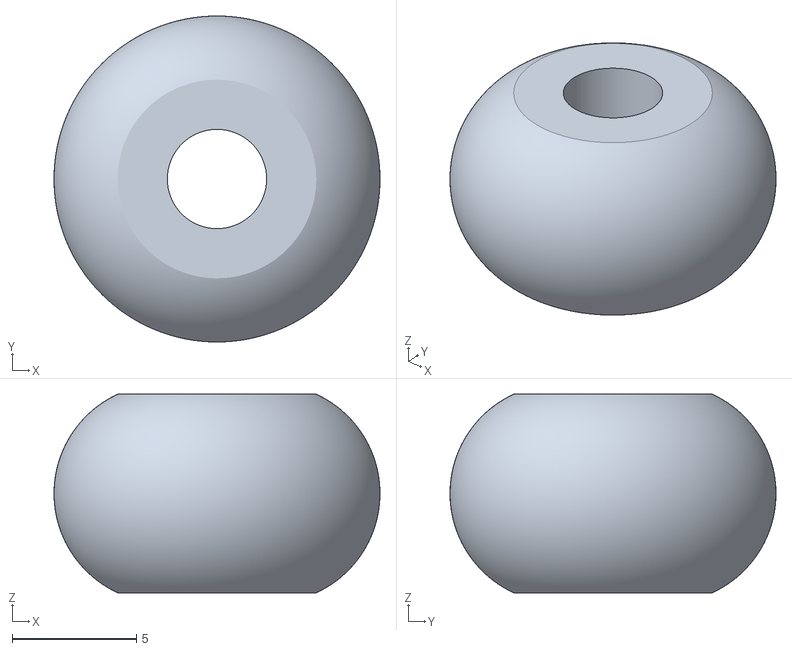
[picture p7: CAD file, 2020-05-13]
BOXES/LIME2-PLASTIC-BOX/STL/Olinuxino-Lime2-SlimCase-v001-NutCover-v001.stl
13.1 x 13.1 x 8.00

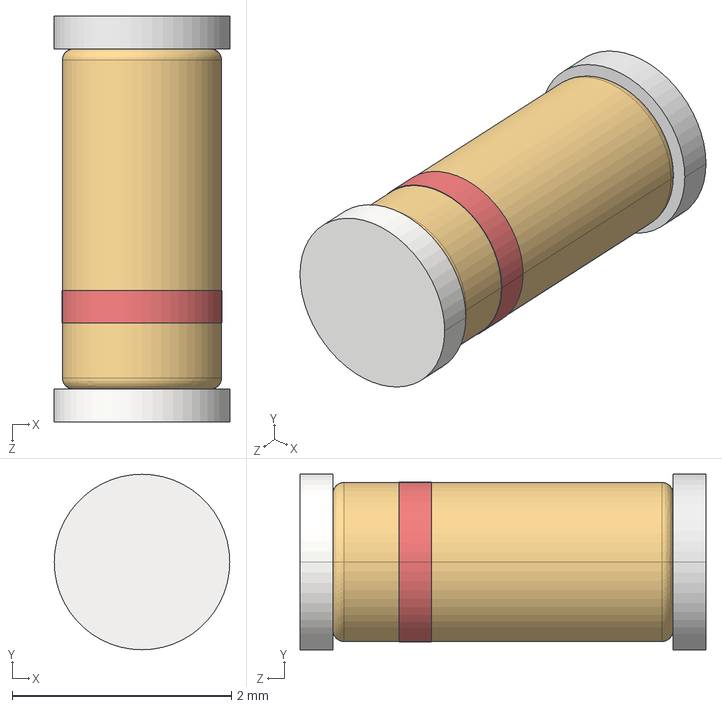
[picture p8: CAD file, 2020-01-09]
HARDWARE/LCDs/LCD-DRIVER/Hardware revision C/3d/melf-2_sod80c.step
1.60 x 1.60 x 3.70 mm

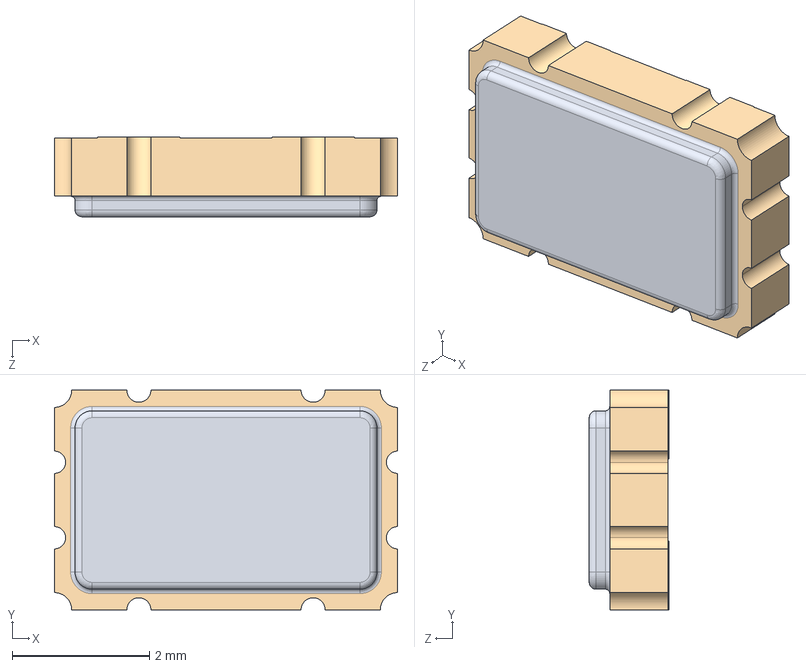
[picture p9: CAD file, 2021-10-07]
HARDWARE/STMP157-OLinuXino-LIME2/1. Latest hardware revision/STMP157-OLinuXino-LIME2_Rev_B1/3d/QSG5032.step
5.00 x 3.20 x 1.16 mm

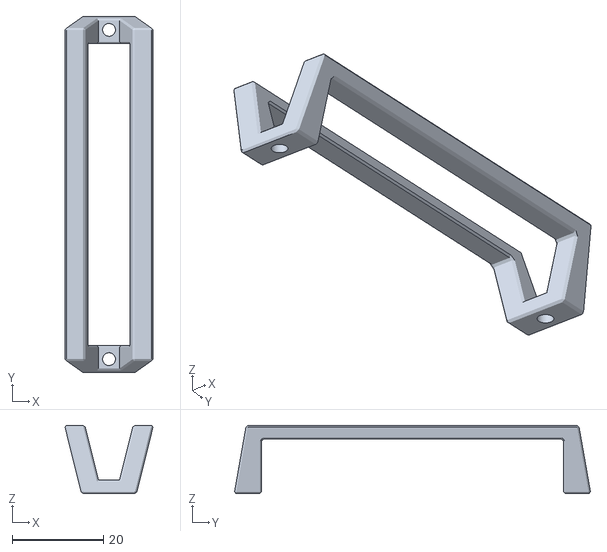
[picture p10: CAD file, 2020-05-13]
BOXES/LIME2-PLASTIC-BOX/STL/Olinuxino-Lime2-SlimCase-v001-BatteryClip-v001.stl
19.3 x 77.9 x 14.9

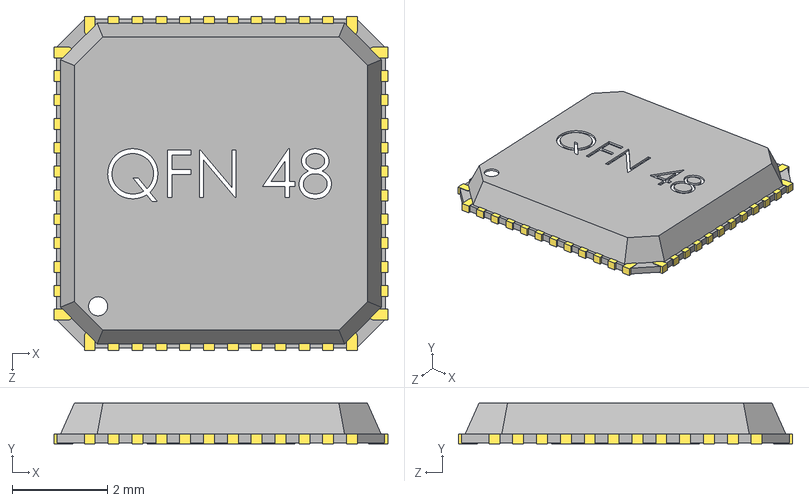
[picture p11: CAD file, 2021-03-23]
HARDWARE/A64-OLinuXino/1. Latest hardware revision/A64-OLinuXino hardware revision G/3d/QFN48-0.5.STEP
7.00 x 0.85 x 7.01 mm
User Library-QFN48-1_Body
User Library-QFN48-1_Pins

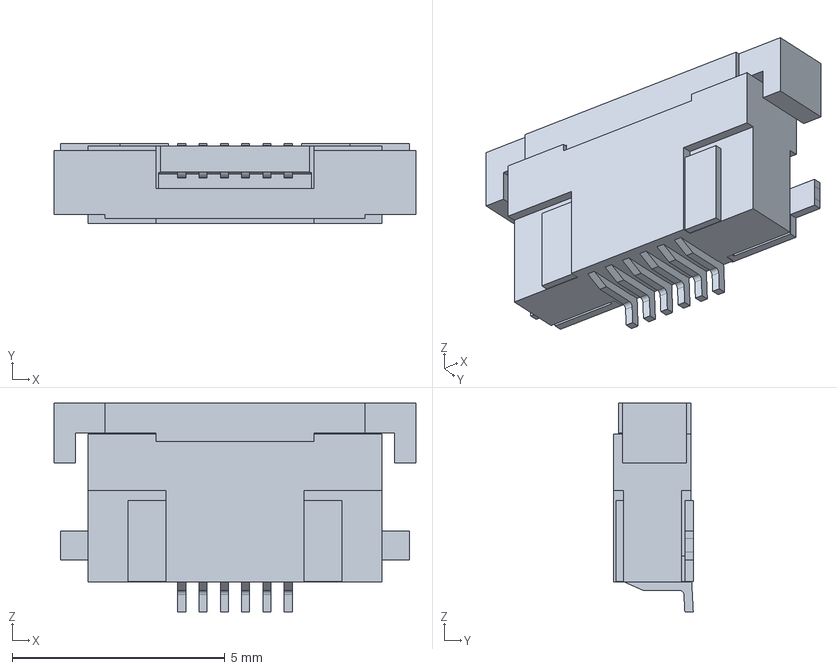
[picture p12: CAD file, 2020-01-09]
HARDWARE/LCDs/LCD-DRIVER/Hardware revision C/3d/FPV-WZB201-06-LF.stp
8.50 x 1.87 x 4.90 mm

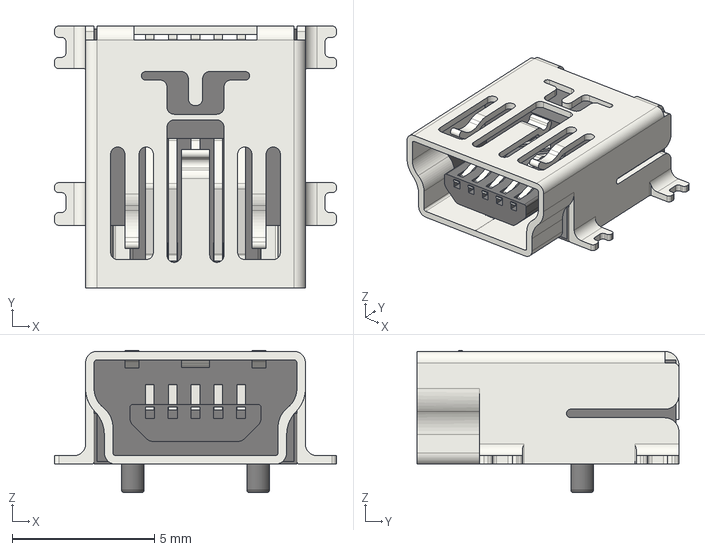
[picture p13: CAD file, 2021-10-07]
HARDWARE/STMP157-OLinuXino-LIME2/1. Latest hardware revision/STMP157-OLinuXino-LIME2_Rev_B1/3d/USB_Mini-B_Lumberg_2486_01_Horizontal.step
9.90 x 9.20 x 5.00 mm

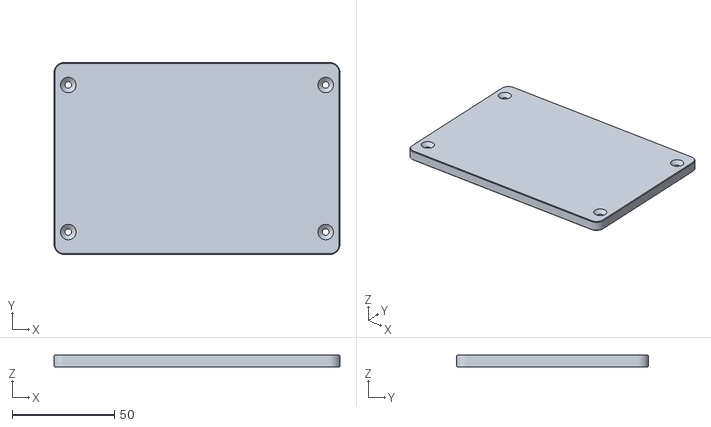
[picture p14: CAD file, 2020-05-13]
BOXES/LIME2-PLASTIC-BOX/STL/Olinuxino-Lime2-SlimCase-v001-Top-v001.stl
140.0 x 94.0 x 6.00

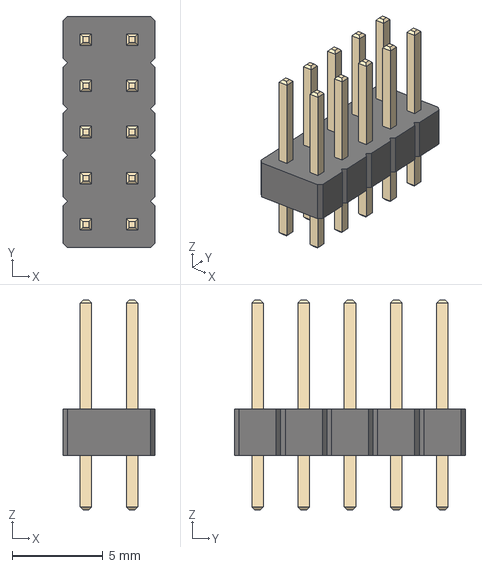
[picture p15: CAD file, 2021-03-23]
HARDWARE/A64-OLinuXino/1. Latest hardware revision/A64-OLinuXino hardware revision G/3d/HN2x5-PinHeader_2x05_P2.54mm_Vertical.step
5.08 x 12.7 x 11.5 mm

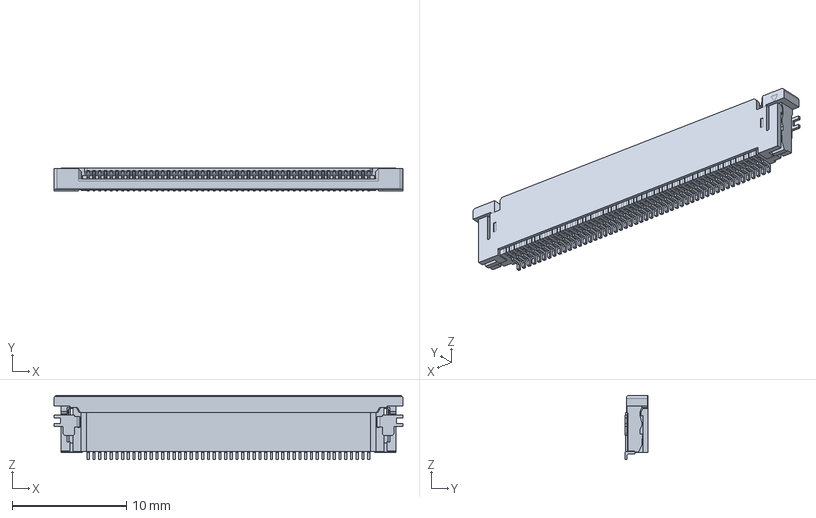
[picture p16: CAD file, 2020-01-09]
HARDWARE/LCDs/LCD-DRIVER/Hardware revision C/3d/FPV-WZA21-50-LF_Molex-541045033.stp
30.5 x 2.05 x 5.60 mm

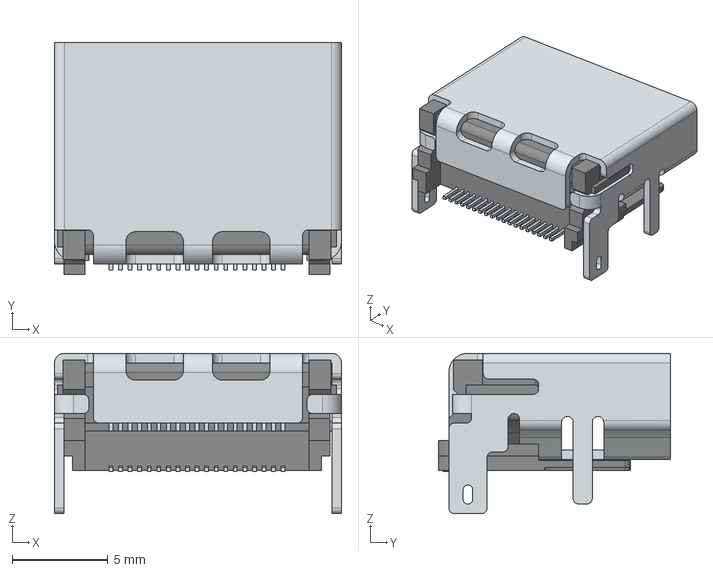
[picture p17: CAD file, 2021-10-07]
HARDWARE/STMP157-OLinuXino-LIME2/1. Latest hardware revision/STMP157-OLinuXino-LIME2_Rev_B1/3d/HDMI_19POS_SMD_Wurth_Electronic-685119134923.stp
15.0 x 12.2 x 8.38 mm

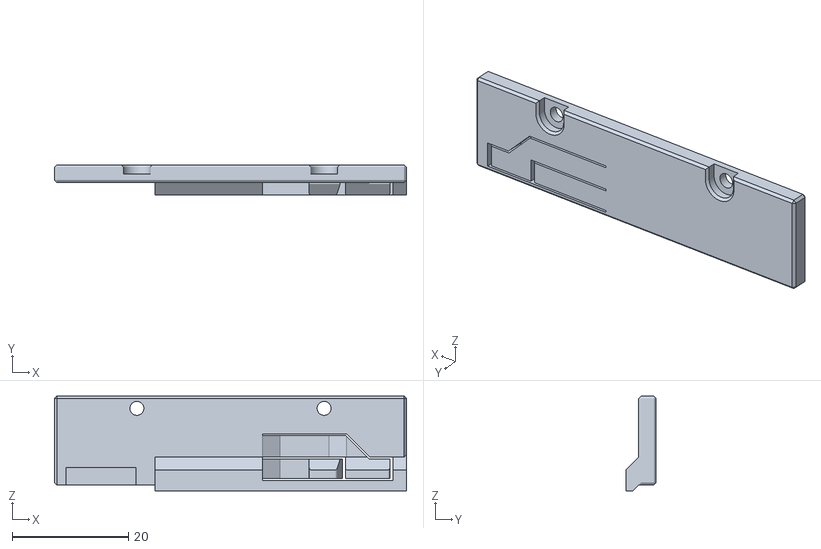
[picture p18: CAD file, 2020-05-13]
BOXES/LIME2-PLASTIC-BOX/STL/Olinuxino-Lime2-SlimCase-v001-Lid-v002.stl
60.6 x 5.20 x 16.3

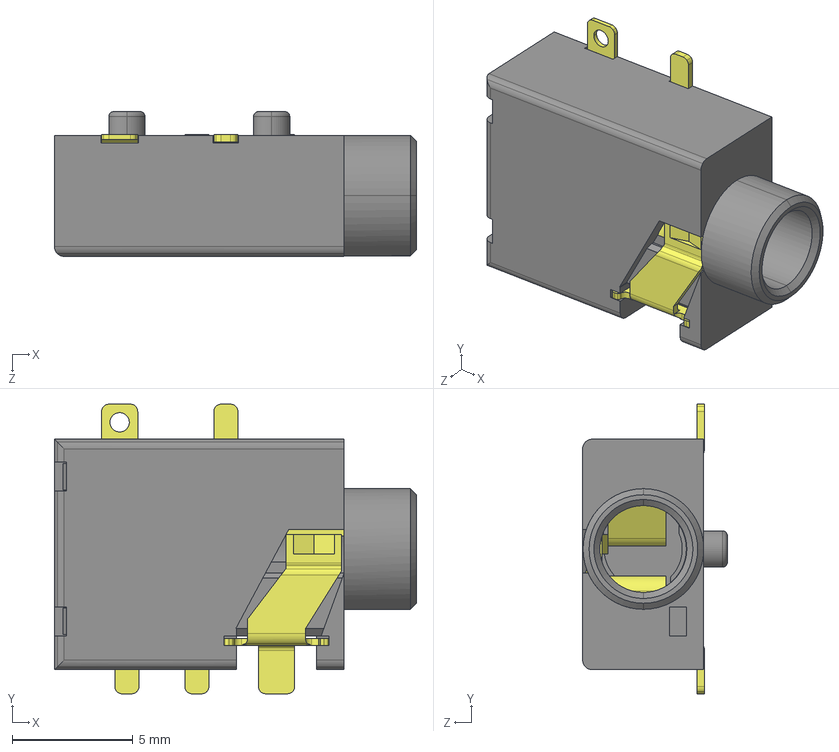
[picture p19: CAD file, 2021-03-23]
HARDWARE/A64-OLinuXino/1. Latest hardware revision/A64-OLinuXino hardware revision G/3d/Audio_Jack-3.5mm---CUI_SJ1-3515-SMT-TR.step
15.0 x 12.0 x 6.00 mm

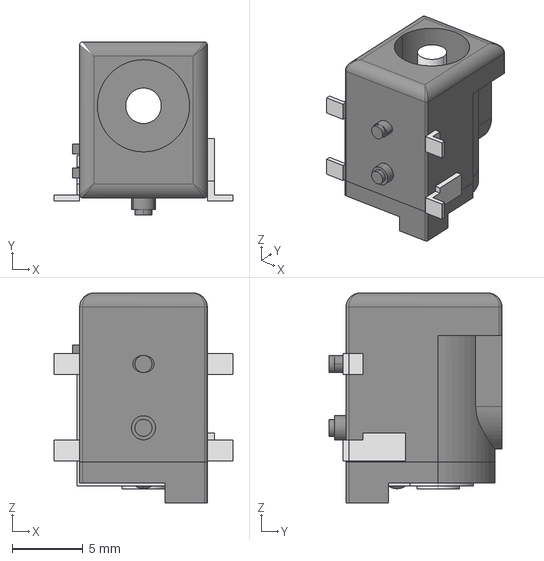
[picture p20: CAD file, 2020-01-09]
HARDWARE/LCDs/LCD-DRIVER/Hardware revision C/3d/PWR_JACK_SMD.stp
12.6 x 12.2 x 14.8 mm

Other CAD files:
HARDWARE/STMP157-OLinuXino-LIME2/1. Latest hardware revision/STMP157-OLinuXino-LIME2_Rev_B1/3d/pj-102ah.stp
BOXES/LIME2-PLASTIC-BOX/STL/Olinuxino-Lime2-SlimCase-v001-Bottom-v001.stl
HARDWARE/A64-OLinuXino/1. Latest hardware revision/A64-OLinuXino hardware revision G/3d/L-CD32_shielded.step
HARDWARE/LCDs/LCD-DRIVER/Hardware revision C/3d/WU10S-Molex_PicoBlade_530471010_1x10_P1.25mm_Vertical.step
HARDWARE/A64-OLinuXino/1. Latest hardware revision/A64-OLinuXino hardware revision G/3d/BL-R8723BT1module.STEP
HARDWARE/A64-OLinuXino/1. Latest hardware revision/A64-OLinuXino hardware revision G/3d/Connector_1Port_RJ45_Magjack_10-100Base-T_AutoMDIX_Molex-0934635206_DigiKey-WM17614-ND.stp
HARDWARE/A64-OLinuXino/1. Latest hardware revision/A64-OLinuXino hardware revision G/3d/DFN6(Body-2x2mm_Hight-1mm_Pitch-0,65mm).step
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

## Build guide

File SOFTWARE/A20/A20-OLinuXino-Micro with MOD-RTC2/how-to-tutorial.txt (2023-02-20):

This is a tutorial how to build a simple project for A20-OLinuXino-Micro Rev.F with demo for MOD-RTC2 Rev.A.

In addition to the boards you also need SD card with Debian image (tested with "A20-OLinuXino-bullseye-base-20220928-143706.img"), LAN (this is optional to download to files) and USB serial cable (like USB-SERIAL-CABLE-F).

1) Connect all the hardware and supply the board - USB serial cable to UART0 - TX0, RX0 and GND; and the MOD-RTC2 to UEXT1.

2) Open a console terminal program (like PuTTY, HyperTerminal etc.) with baudrate 115200

3) Wait until the board is initialized and login (default user/password are: root/olimex)

4) Make a directory where the project files will be stored (this step is optional and it's only for better arrangement of the files in the directory tree). You can do this with the command:
Input:
	
	mkdir MOD-RTC2
	
5) Set the created directory as current directory:
Input:
	
	cd MOD-RTC2
	
6) Since we are going to download the source and header files from GitHUB we must enable the internet connection:
Input:
	
	ifup eth0
	
6.1) Allow the https protocol. (This step could be skipped if https is allowed by default)

Input

	export https_proxy="192.168.0.1:80"

7) Download the files from GitHUB:
Input:

	wget <URL>
	
In order to get the URL, go to GitHUB find the directory of the project: <path>; select the file you want to download and click on the "Raw" button; then copy the URL and trigger the command (wget) in the console of A20-OLinuXino-Micro. Do this for the three files: main.c; i2c.c; i2c.h.

8) Just to make sure everything is fine and all three files are downloaded check the content of the directory:
Input:

	ls

The respond of the host board should be:
Output:

	i2c.c  i2c.h  main.c

9) Compile all source files:
Input:

	gcc *.c

A new file should appear. We check the content of the directory again:
Input:

	ls
	
Output:

	a.out  i2c.c  i2c.h  main.c

10) Execute the generated file with option to READ from I2C2
Input:

	./a.out
	
On the screen will be printed time started from 31 December 1999 at 23:59:57 and coutingin every second. This time could be changed in the code.
	1999/12/31 (Friday) 23:59:57;  Temperature = 24.25 C

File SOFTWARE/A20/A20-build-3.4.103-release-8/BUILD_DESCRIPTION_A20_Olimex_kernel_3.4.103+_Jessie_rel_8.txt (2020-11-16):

How to make a bootable SD card for Olimex's A20-SOM, A20-OLinuXino-MICRO, A20-OLinuXino-LIME,
A20-OLinuXino-LIME2 boards with sunxi kernel 3.4.103 and Linux Debian Jessie file system

---

Chapter 1. Setting up the software tools

---

First, make sure that you have the software tools needed to compile the Linux Kernel. You'd have to install
these if you don't have them already installed. To perform most of the operations below you should be logged
as a user with super user rights on your Linux machine. We used  Type in the terminal:

# sudo su

You will be prompted for your password and then your command line would start with # which means that you are
now logged as the super user, all commands listed below should be executed in this mode.

Next update apt-get links by typing:

# apt-get update

Next install the same compiler toolchain that we used here by typing the following:

# apt-get install gcc-4.7-arm-linux-gnueabihf ncurses-dev uboot-mkimage build-essential git

This will install: GCC compiler used to compile the kernel; the kernel config menu; the uboot make image that
is required to allow the SD card to boot into the Linux image; GIT that allows you to download from the github
which holds source code for some of the system; some other tools for building the kernel.

Note that if you use debian may be you will need to add:

deb http://www.emdebian.org/debian squeeze main

in the file below:

/etc/apt/sources.list

You would also need a torrent client. It is required to be able to download the file system. Any torrent
client would do the job, as long as it can process .torrent files.

At this point you should have have all important tools to make your very own A20 kernel image!

---

Chapter 2. Building mainline u-boot

---

First create the directory where we would build the Linux:

# mkdir a20-olimex
# cd a20-olimex

Then download the latest mainline u-boot sources from GitHub repository:

# git clone git://git.denx.de/u-boot.git

After the download you should have a new directory, naviagate into it with:

# cd u-boot/

The image is tested with the commit  Mon Sep 12 10:05:51 2016 -0400

To switch from the latest sources to the exact commit that we used execute the next command:

# git reset --hard  8cbb389bb3da80cbf8911f8386cbff92c6a78afe

or 

git checkout v2016.09 -b tmp

!MAKE SURE THAT YOU HAVE REVERTED TO THE SAME COMMIT OR NOTHING BELOW WOULD WORK!

For this u-boot commit you need from a patch that reduces A20 DRAM speed from 480 to 384 MHz to improve board 
stability and it makes support for different types of gigabit PHY chips we used.

For this purpose download a20-phy_1000_100-dram.patch file using wget command:

# wget https://github.com/OLIMEX/OLINUXINO/raw/master/SOFTWARE/A20/A20-build-3.4.103-release-5/a20-phy_1000_100-dram.patch

and then patch the uboot sources with:

# patch -p1 < a20-phy_1000_100-dram.patch

If you don't apply the patch you might have severely reduced Gigabit Ethernet speed.

---

Note that the compiler version that the u-boot is built and tested is exactly:
arm-linux-gnueabihf-gcc (crosstool-NG linaro-1.13.1-4.9-2014.09 - Linaro GCC 4.9-2014.09) 4.9.2 20140904 (prerelease)

Now you have to load configuration file for your board, because there are different configurations for u-boot
which depend on the exact board that you have.

Do only the point for your board:

---

2.1 A20-OLinuXino-LIME2 board

# make A20-OLinuXino-Lime2_defconfig  ARCH=arm CROSS_COMPILE=arm-linux-gnueabihf-                  

If your board has eMMC memory installed (instead of NAND memory) then you have to change the extra MMC slot
number in the u-boot in order to be possible to boot only from eMMC

# make ARCH=arm menuconfig

Go to ARM architecture -> and change mmc extra slot number to 2

ESC ESC

Save and Exit

---

2.2 A20-SOM board

# make A20-Olimex-SOM-EVB_defconfig ARCH=arm CROSS_COMPILE=arm-linux-gnueabihf-

// If there are problems at the step above (for example if the SOM-EVB defconfig is missing) use the LIME2
defconfig instead, type:
// # make A20-OLinuXino-Lime2_defconfig ARCH=arm CROSS_COMPILE=arm-linux-gnueabihf-
// # make ARCH=arm menuconfig

---

2.3 A20-OLinuXino-MICRO board

# make A20-OLinuXino_MICRO_defconfig ARCH=arm CROSS_COMPILE=arm-linux-gnueabihf-

If your board has eMMC memory installed (instead of NAND memory) then you have to change the extra MMC slot
number in the u-boot in order to be possible to boot only from eMMC

# make ARCH=arm menuconfig

Go to ARM architecture -> and change mmc extra slot number to 2

Check
Enable workarounds for booting old kernels
and enable it 
(*)Enable workarounds for booting old kernels 

ESC ESC

Save and Exit

---

2.4 A20-OLinuXino-LIME board

# make A20-OLinuXino-Lime_defconfig ARCH=arm CROSS_COMPILE=arm-linux-gnueabihf-

---

After the defconfig part you can manually edit a lot of settings using:

# make ARCH=arm menuconfig

You can use the above to load modules that you might need but ou have to be careful, 
since certain options might break the u-boot.

When done with the menuconfig type the following command to compile the u-boot:

# make ARCH=arm CROSS_COMPILE=arm-linux-gnueabihf-

At the end of the process you can check if everything is OK by using:

# ls u-boot.bin u-boot-sunxi-with-spl.bin spl/sunxi-spl.bin

spl/sunxi-spl.bin  u-boot.bin  u-boot-sunxi-with-spl.bin

If you got these files everything is complete, well done so far

# cd ..

You should be in the following directory:

/home/user/a20-olimex#

---

Chapter 3. Building sunxi kernel from sources for A20 boards

---

The sunxi kernel sources for A20 are available at GitHub. Note that the our build uses this exact commit: 

9a1cd034181af628d4145202289e1993c1687db6 from Sat Oct 4 07:59:35 2014 +0300

You can download the latest kernel sources using the following command:

# git clone https://github.com/linux-sunxi/linux-sunxi

You can switch to this exact commit with the next command:

# git reset --hard 9a1cd034181af628d4145202289e1993c1687db6

After the download navigate to the kernel directory:

# cd linux-sunxi/

---

3.3 Configuring the rest of the environment

---

3.3.1 This section is only if you want to use CAN bus iinterface. Otherwise you can skip it.

# cd linux-sunxi/drivers/net/can
# git clone https://github.com/ostrelkov/sunxi-can-driver
# nano drivers/net/can/Kconfig  
and add
source "drivers/net/can/sunxi-can-driver/Kconfig"
# nano drivers/net/can/Makefile
and add
obj-y                           += sunxi-can-driver/

3.3.2 You need to get the a20 configuration file � A20-linux-3.4.103_defconfig. The file contains all kernel
module settings. Download A20-linux-3.4.103_defconfig using wget command 

# wget https://github.com/OLIMEX/OLINUXINO/raw/master/SOFTWARE/A20/A20-build-3.4.103-release-5/A20-linux-3.4.103_defconfig

then copy A20-linux-3.4.103_defconfig file to configs directory:

# cp A20-linux-3.4.103_defconfig arch/arm/configs/

and make:

# make ARCH=arm A20-linux-3.4.103_defconfig

The result should be:

configuration written to .config

If you wish to make changes to the kernel configuration execute the following:

# make ARCH=arm menuconfig

The menuconfig changes a .config text file, which you can view/edit even with a text editor like vi, nano.
Using this command you can add or remove different modules for the different peripherials in the kernel. Be
careful when you change these settings because the kernel can stop working properly.

If your board has eMMC then you have to apply a patches that fixes the problems with HighPriorityInterrupt and emmc5 support 

Download the patch file fix_emmc_hpi.patch using wget command

# wget https://raw.githubusercontent.com/OLIMEX/build/olimex/patch/kernel/sun7i-default/fix_emmc_hpi.patch

and patch the drivers/mmc/core/mmc.c file

# patch -p1 < fix_emmc_hpi.patch

for emmc5 support 

# wget https://raw.githubusercontent.com/OLIMEX/build/olimex/patch/kernel/sun7i-default/enable_emmc5_support.patch

and patch the drivers/mmc/core/mmc.c file

# patch -p1 < enable_emmc5_support.patch

Now you may continue with kernel image compiling 

# make ARCH=arm CROSS_COMPILE=arm-linux-gnueabihf- -j4 uImage

when this finish�s you will have uImage ready and the result should be:

  LD      arch/arm/boot/compressed/vmlinux
  OBJCOPY arch/arm/boot/zImage
  Kernel: arch/arm/boot/zImage is ready
  UIMAGE  arch/arm/boot/uImage
Image Name:   Linux-3.4.103-00033-g9a1cd03-dir
Created:      Mon Nov  2 09:29:54 2015
Image Type:   ARM Linux Kernel Image (uncompressed)
Data Size:    4581208 Bytes = 4473.84 kB = 4.37 MB
Load Address: 40008000
Entry Point:  40008000
  Image arch/arm/boot/uImage is ready

The next step is building the kernel modules:

# make ARCH=arm CROSS_COMPILE=arm-linux-gnueabihf- -j4 INSTALL_MOD_PATH=out modules
# make ARCH=arm CROSS_COMPILE=arm-linux-gnueabihf- -j4 INSTALL_MOD_PATH=out modules_install

DONE! At this point you have uboot and kernel modules.

The uImage file is located in linux-sunxi/arch/arm/boot/

The kernel modules are located in linux-sunxi/out/lib/modules/3.x.xx,
where 3.x.xx is kernel version. In our case the directory with modules is:

linux-sunxi/out/lib/modules/3.4.103

---

4. Format and setup the SD-card

---

We suggest using a class 10 microSD card with memory capacity at least 8GB. We haven't tested microSD cards
bigger than 16GB.

First we have to make the correct card partitions using fdisk. Plug SD card into your SD card reader and enter
in the terminal:

# ls /dev/sd

Then press two times <TAB> you will see a list of your sd devices like sda sdb sdc note that some of these
devices may be your hard disk so make sure you know which one is your sd card before you proceed as you can
damage your HDD if you choose the wrong sd-device. You can do this by unplugging your sd card reader - pay
attention which "sd" device disappears from the list.

Once you know which one is your microSD (as sda#) use it instead of the sdX name in the references below:

# fdisk /dev/sdX

then:

4.1. p

will list your partitions. If there are already partitions on your card do:

4.2. d enter 1

if you have more than one partitition press d while delete them all

4.3. create the first partition, starting from 2048

n enter p enter 1 enter enter +16M

4.4. create second partition

n enter p enter 2 enter enter enter

then list the created partitions:

p enter

if you did everything correctly on 4GB card you should see something like:

Disk /dev/sdg: 3980 MB, 3980394496 bytes
123 heads, 62 sectors/track, 1019 cylinders, total 7774208 sectors
Units = sectors of 1 * 512 = 512 bytes
Sector size (logical/physical): 512 bytes / 512 bytes
I/O size (minimum/optimal): 512 bytes / 512 bytes
Disk identifier: 0x00000000

   Device Boot      Start         End      Blocks   Id  System
/dev/sdg1            2048       34815       16384   83  Linux
/dev/sdg2           34816     7774207     3869696   83  Linux

4.5. press w

write changes to sd card

Now we have to format the file system on the card (the first partition should be vfat as this is FS which the
Allwinner bootloader understands):

# mkfs.vfat /dev/sdX1

The second should be normal Linux EXT3 FS:

# mkfs.ext3 /dev/sdX2

---

5. Write the Uboot and u-boot-sunxi-with-spl.bin

---

You should be in /home/user/a20-olimex# directory 

Note that you have to write u-boot-sunxi-with-spl.bin in /dev/sdX (not sdX1 or sdX2)

Type:

# dd if=u-boot-sunxi/u-boot-sunxi-with-spl.bin of=/dev/sdX bs=1024 seek=8

---

6. Write the kernel uImage to the SD-card

---

You should be in the directory below

/home/user/a20-olimex# directory

# mkdir /mnt/sd
# mount /dev/sdX1 /mnt/sd

copy the Kernel uImage to root directory in partition 1:

# cp linux-sunxi/arch/arm/boot/uImage /mnt/sd

---

7. Write script.bin file

---

script.bin is a very important file with parameters like port GPIO assignments, DDR memory parameters, video 
resolution etc. Depending on the A20 board that you own you have to download and write different script.bin
file.

7.1.1 for A20-OLinuXino-LIME2 board or A20-OLinuXino-LIME2 board with NAND download the script.bin file using
wget command

# wget https://github.com/OLIMEX/OLINUXINO/raw/master/SOFTWARE/A20/A20-build-3.4.103-release-7/script_a20_Lime2_NAND/script.bin

7.1.2 for A20-OLinuXino-LIME2 board with EMMC download the script.bin file using wget command

# wget https://github.com/OLIMEX/OLINUXINO/raw/master/SOFTWARE/A20/A20-build-3.4.103-release-7/script_a20_lime2_eMMC/script.bin

7.2 for A20-SOM board (with NAND) download the script.bin file using wget command

# wget https://github.com/OLIMEX/OLINUXINO/raw/master/SOFTWARE/A20/A20-build-3.4.103-release-7/script_a20-SOM/script_a20_SOM_HDMI_720p50/script.bin

7.3 for A20-SOM board(with eMMC) download the script.bin file using wget command

# wget https://github.com/OLIMEX/OLINUXINO/raw/master/SOFTWARE/A20/A20-build-3.4.103-release-8/script_a20-SOM_eMMC/script_a20_SOM_HDMI_720p50/script.bin

7.4 for A20-OLinuXino-MICRO-4G(with NAND) board download the script.bin file using wget command

# wget https://github.com/OLIMEX/OLINUXINO/raw/master/SOFTWARE/A20/A20-build-3.4.103-release-7/script_a20_OLinuXino-micro_NAND/script.bin

7.5 for A20-OLinuXino-MICRO-eMMC(with eMMC) board download the script.bin file using wget command

# wget https://github.com/OLIMEX/OLINUXINO/raw/master/SOFTWARE/A20/A20-build-3.4.103-release-7/script_a20_OLinuXino-micro-eMMC/script.bin

7.6 for A20-OLinuXino-LIME board download the script.bin file using wget command

# wget https://github.com/OLIMEX/OLINUXINO/raw/master/SOFTWARE/A20/A20-build-3.4.103-release-7/script_a20_lime/script.bin

then copy the downloaded script.bin file to the mounted first partition of the SD card:

# cp script.bin /mnt/sd

Download boot.scr and uEnv.txt files

#wget  https://github.com/OLIMEX/OLINUXINO/raw/master/SOFTWARE/A20/A20-build-3.4.103-release-2/boot.scr
#wget  https://github.com/OLIMEX/OLINUXINO/raw/master/SOFTWARE/A20/A20-build-3.4.103-release-2/uEnv.txt

You have to copy in first sd card partition where script.bin file is located

# cp boot.scr /mnt/sd
# cp uEnv.txt /mnt/sd
# sync
# umount /dev/sdX1

----

8. Debian rootfs

---

The Linux Kernel and Uboot are ready, now we need the Linux distribution rootfs.

Basically the only difference between the different Linux distributions is the rootfs, so if you put Debian
rootfs you will have Debian, if you put Ubuntu rootfs it will be Ubuntu etc.

How to build one is a long topic, the good thing is that there are many already pre-built so we can just
download one and use it ready.

Now leave the kernel directory

# cd ..

Should be in the directory below

# /home/user/a20-olimex

Download debian rootfs with the file name "Debian_FS_34_103_Jessy_8.1_A20-olimex_rel_3", which is available
only as a torrent. You would need a torrent client for it (Azureus, uTorrent, qBittorrent, etc). The link to
the torrent file is:

# wget https://www.olimex.com/wiki/images/b/b5/Debian_FS_34_103_Jessy_8.1_A20-olimex_rel_4.torrent

Launch the torrent client and download the file.

Now mount the microSD card EXT3 FS partition:

# mount /dev/sdX2 /mnt/sd

and unarchive the rootfs

# tar xzvf Debian_FS_34_103_Jessy_8.1_A20-olimex_rel_4.tgz -C /mnt/sd
# ls /mnt/sd

The correct result should be:
bin   dev  home  lost+found  mnt  proc  run   selinux  sys  usr
boot  etc  lib   media       opt  root  sbin  srv      tmp  var

Now you have to replace the newly generated kernel modules from
/home/user/a20-olimex/linux-sunxi/out/lib/modules/ to the new Debian file system:

# rm -rf /mnt/sd/lib/modules/*

# cp -rfv linux-sunxi/out/lib/modules/3.x.xx+/ /mnt/sd/lib/modules/

where x.xx is the kernel version

in our case:

# cp -rfv linux-sunxi/out/lib/modules/3.4.103/ /mnt/sd/lib/modules/

replace /lib/firmware folder with the generated /linux-sunxi/out/firmware

#cp -rfv linux-sunxi/out/lib/firmware/ /mnt/sd/lib/

# sync
# umount /dev/sdX2

At this point you have Debian on your SD card second partition and you have an SD card ready to boot debian on
A20-SOM or A20-OLinuXino-MICRO or A20-OLinuXino-LIME or A20-OLinuXino-LIME2

Connect USB-SERIAL-CABLE-F to UEXT Tx, Rx and GND, or connect a HDMI screen. Put the SD-card apply power
according to A20 board type. You should see u-boot and then kernel messages on the console.

Under the command line interface you are automatically logged as super user (user "root", password "olimex").
However, under the graphical environment you are not auto-logged as super user and you must type "sudo" before
the command (in the GUI the super-user is "olimex" and the password is "olimex").

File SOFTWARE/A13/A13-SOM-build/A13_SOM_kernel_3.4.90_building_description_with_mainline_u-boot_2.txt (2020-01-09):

A13-SOM-building-latest-Debian

A13_SOM_kernel_3.4.90_building_description

How to make a bootable SD card for A13-OLinuXino-MICRO, A13-SOM-256 and A13-SOM-512 with either sunxi or mainline u-boot, 3.4.x kernel,
and Debian file system.

This guide is NOT suitable for A13-OLinuXino and A13-OLinuXino-WIFI.

*****

1. Setup of the toolchain

You should make sure that you have the software tools required for building the Linux Kernel. Please install the required tools (if you 
don't have them already). To install new software you should be logged as super user, so the first thing to do would be to type in the 
terminal:

# sudo su

you will be asked for your password and then your prompt will change to # which means you are now the super user, all future commands
should be run in this mode.

At this point update apt-get links by typing:

# apt-get update

Install the toolchain by typing the following:

# apt-get install gcc-4.7-arm-linux-gnueabihf ncurses-dev uboot-mkimage build-essential git

This will install: GCC compiler used to compile the kernel; the kernel config menu uboot creates image which is required to allow the SD
card to boot into the linux image; Git which allows you to download from the github which holds source code for some of the system;
additional other tools for building the kernel.

Note that if the files can't be found you might need to find them from other sources. If you use Debian you might need need to add the
following line in the sources list:

deb http://www.emdebian.org/debian squeeze main

in the file below:

/etc/apt/sources.list

after the installation you now have all tools to make your very own A13 kernel image!

*****

2. Building u-boot

You have two options for u-boot: the first is to use sunxi u-boot and the second is to use mainline u-boot. If you have stability
problems, use mainline u-boot since it has wider support for RAM memories. Note that if you use the sunxi u-boot with some of the
newer RAM memories that we place might face boot or stability problems, some of the memories that we place are not supported in the
sunxi u-boot. The mainline u-boot will be suitable for all DDR3 memories.

If you do not wish to build u-boot you can use the pre-built files from this location and skip to chapter 5:

https://github.com/OLIMEX/OLINUXINO/tree/master/SOFTWARE/A13/A13-SOM-build

First create the directory where we will build the A13-OLinuXino-Micro/SOM linux:

# mkdir a13-micro-SOM-kernel_3.4
# cd a13-micro-SOM-kernel_3.4

After that follow either chapter 2.1 or 2.2 (2.1 is suitable for sunxi u-boot and older RAM memories; 2.2 is suitable for mainline
u-boot and newer RAM memory)

2.1. Building sunxi u-boot If we have a board with HYNIX RAM let's download the uboot sources from GitHub repository, note that
there are lot of branches but you have to use sunxi branch. Note that the u-boot for A13-OLinuXino-MICRO and A13-SOM boards is
tested with the next branch:

# git rev-parse --verify HEAD 78592f1d95cccf329ed515a176c80be5c87827a0
this means after you have download the sources (with git clone) you can switch to the exact commit with:

# git reset --hard 78592f1d95cccf329ed515a176c80be5c87827a0
Download u-boot sources:

# git clone -b sunxi https://github.com/linux-sunxi/u-boot-sunxi.git
After the download you should have a new directory

# cd u-boot-sunxi/

Note that there are 2 versions of A13-SOM boards:

-A13-SOM with 256MB DDR3 memory size -A13-SOM with 512MB DDR3 memory size - need u-boot patch

If you have A13-SOM board with 512MB memory size then first you have to allpy patch for changing DDR3 memory size: download
u-boot_A13_SOM_512MB.patch using wget command

# wget "https://drive.google.com/uc?export=download&id=0BwplT87k9SCgY3lIWVlLd3ZlSEk"
and patch the file board/sunxi/dram_a13_oli_micro.c with the next command

# patch -p0 < u-boot_A13_SOM_512MB.patch
If you have A13-SOM with 256MB memory size you no need from patch. By default u-boot settings are set for 256MB memory size and you
can start building imediately after download u-boot.

You can start uboot building with the next commands:

# make ARCH=arm CROSS_COMPILE=arm-linux-gnueabihf- A13-OLinuXinoM_config
# make ARCH=arm CROSS_COMPILE=arm-linux-gnueabihf-

At the end of the process you can check if everything is OK by

ls u-boot.bin u-boot-sunxi-with-spl.bin spl/sunxi-spl.bin
spl/sunxi-spl.bin u-boot.bin u-boot-sunxi-with-spl.bin

If you got these files everything is complete, well done so far.

# cd ..

You should be in the following directory:

/home/user/a13-micro-SOM-kernel_3.4#

At this point skip 2.2 directly to chapter 3.

2.2. Building mainline u-boot

Note that if you want to use latest mainline u-boot then you have to use linaro toolchain 6.2 and above!

The mainline u-boot in our image is compiled using linaro toolchain version 6.4 from this link
https://releases.linaro.org/components/toolchain/binaries/6.4-2018.05/arm-linux-gnueabihf/gcc-linaro-6.4.1-2018.05-i686_arm-linux-gnueabihf.tar.xz

After you download it, unzip it with with:

# tar xJf gcc-linaro-6.4.1-2018.05-i686_arm-linux-gnueabihf.tar.xz 

Download u-boot sources:

# git clone git://git.denx.de/u-boot.git

After the download you should have a new directory our image is tested with tag v2109.01 so if you want to use this tag type:

# git checkout tags/v2019.01

cd u-boot

If we have a board with newer RAM let's download the u-boot sources from GitHub repository, note that the u-boot for
A13-OLinuXino-MICRO and A13-SOM boards is tested with the exact same tag tags/v2019.01

Next load the configuration file. It is the same for A13-SOM and A13-Micro board:

# make CROSS_COMPILE=/path_to_file/arm-linux-gnueabihf- A13-OLinuXinoM_defconfig

you can configure some u-boot settings like DDR3 settings, clocks and other with:

# make menuconfig

It is recommended to choose:

[*]Enable workaround for booting old kernels

the board has stable behaviour with [360] sunxi dram clock speed [300] sunxi mbus clock speed

but you can choose other settings depending on your application

save it the settings and exit

Compile the u-boot

# make CROSS_COMPILE=/path_to_file/arm-linux-gnueabihf-

When the compilation completes, there will be u-boot-sunxi-with-spl.bin available in your u-boot tree.

Now you have to create a new boot.cmd file with the following contain

setenv bootm_boot_mode sec
setenv bootargs console=ttyS0,115200 root=/dev/mmcblk0p2 rootwait panic=10
load mmc 0:1 0x43000000 script.bin || load mmc 0:1 0x43000000 boot/script.bin
load mmc 0:1 0x42000000 uImage || load mmc 0:1 0x42000000 boot/uImage
bootm 0x42000000

convert boot.cmd in boot.scr with the next command

mkimage -C none -A arm -T script -d boot.cmd boot.scr

The result should be a new boot.scr file that you have to copy to the first SD card partition (where uImage and script.bin file are
located).

*****

3. Building kernel sources for A13-SOM

Kernel sources for A13 are available on GitHub. Note that the following building is made with the revision below:

# git rev-parse --verify HEAD e37d760b363888f3a65cd6455c99a75cac70a7b8

You can download the kernel sources using the following command:

# git clone https://github.com/linux-sunxi/linux-sunxi

After the download go to the kernel directory

# cd linux-sunxi/

Note that before compiling kernel you have to do a patch kernel in order to change I2C sped from 200kHz to 100kHz (need for Olimex's
I2C modules) and some other changes related with missing power management with AXP209 chip.

Download the patch a13_micro_SOM.patch using wget command

# wget "https://drive.google.com/uc?export=download&id=0BwplT87k9SCgQ0IxZjRtaHVnMzg"

and apply the patch:

# patch -p1 < a13_micro_SOM.patch

The next step is to configure the system

Here you need from a13 configuration file - a13_micro_SOM_defconfig. The file contains all kernel module settings.

Download a13_micro_SOM_defconfig using wget command

# wget "https://drive.google.com/uc?export=download&id=0BwplT87k9SCgWEdqRGl2amxyd2c"

hen copy a13_micro_SOM_defconfig file to configs directory:

# cp a13_micro_SOM_defconfig /arch/arm/configs/

and make:

# make ARCH=arm a13_micro_SOM_defconfig

The result should be: configuration written to .config

If you wish to make your changes in the kernel configuration do:

# make ARCH=arm menuconfig

The menuconfig changes a .config text file, which you can view/edit even with a text editor like vi,nano. With this command you can
add or remove different modules for the different peripherals in the kernel. Be careful when use this as this may cause the kernel
to not work properly.

Now you can continue with kernel image compiling

# make ARCH=arm CROSS_COMPILE=arm-linux-gnueabihf- -j4 uImage

when this finish you will have uImage ready and the result should be:

Kernel: arch/arm/boot/Image is ready LD arch/arm/boot/compressed/vmlinux OBJCOPY arch/arm/boot/zImage Kernel: arch/arm/boot/zImage is
ready UIMAGE arch/arm/boot/uImage Image Name: Linux-3.4.79+ Created: Mon May 12 09:22:56 2014 Image Type: ARM Linux Kernel Image
(uncompressed) Data Size: 4612216 Bytes = 4504.12 kB = 4.40 MB Load Address: 40008000 Entry Point: 40008000 Image arch/arm/boot/uImage
is ready

Now you can build the kernel modules:

# make ARCH=arm CROSS_COMPILE=arm-linux-gnueabihf- -j4 INSTALL_MOD_PATH=out modules
# make ARCH=arm CROSS_COMPILE=arm-linux-gnueabihf- -j4 INSTALL_MOD_PATH=out modules_install
DONE! At this point you have uboot and kernel modules.

The uImage file is located in linux-sunxi/arch/arm/boot/

The kernel modules are located in

linux-sunxi/out/lib/modules/3.x.xx where 3.x.xx is kernel version

in our case the directory with modules is:

linux-sunxi/out/lib/modules/3.4.90+

*****

4. Format and setup the SD-card

We suggest 4GB class 10 micro sd-card but you can use any card between 2GB and 16GB.

First we have to make the correct card partitions, this is done with fdisk.

Plug SD card into your SD card reader and enter in the terminal

# ls /dev/sd

Then press two times <TAB> you will see a list of your sd devices like sda sdb sdc note that some of these devices may be your hard
disk so make sure you know which one is your sd card before you proceed as you can damage your HDD if you choose the wrong sd-device.
You can do this by unplugging your sd card reader and identify which of the ?sd? devices disappears from the list.

Once you know which device is your sdcard like sda use this text instead of the sdX name in the references below:

# fdisk /dev/sdX

then do these steps:

1. p will list your partitions

if there are already partitions on your card do:

2. d enter 1 if you have more than one partition press d while delete them all

3. create the first partition, starting from 2048 n enter p enter 1 enter enter +16M

4. create second partition n enter p enter 2 enter enter enter

then list the created partitions: p enter if you did everything correctly on 4GB card you should see something like:

Disk /dev/sdg: 3980 MB, 3980394496 bytes 123 heads, 62 sectors/track, 1019 cylinders, total 7774208 sectors Units = sectors of 1 * 512 =
512 bytes Sector size (logical/physical): 512 bytes / 512 bytes I/O size (minimum/optimal): 512 bytes / 512 bytes Disk identifier: 0x00000000

Device Boot Start End Blocks Id System /dev/sdg1 2048 34815 16384 83 Linux /dev/sdg2 34816 7774207 3869696 83 Linux

7. w

write changes to sd card

now we have to format the file system on the card:

the first partition should be vfat as this is FS which the Allwinner bootloader understands

# mkfs.vfat /dev/sdX1

the second should be normal Linux EXT3 FS

# mkfs.ext3 /dev/sdX2

*****

5. Write the Uboot and sunxi-spl.bin

You should be in /home/user/a13-micro-SOM-kernel_3.4# directory Note that you have to write u-boot-sunxi-with-spl.bin in /dev/sdX (not sdX1 or sdX2)

# dd if=u-boot-sunxi/u-boot-sunxi-with-spl.bin of=/dev/sdX bs=1024 seek=8

Note that if you use mainline u-boot then you have to copy the generated boot.scr file in the first sdcard partition. For example:

# mkdir /mnt/sd
# mount /dev/sdX1 /mnt/sd
# cp /u-boot/boot.scr /mnt/sd/ 

*****

6. Write kernel uImage you build to the SD-card

copy the Kernel uImage to root directory in partition 1

# cp linux-sunxi/arch/arm/boot/uImage /mnt/sd

*****

7. Write script.bin file

script.bin is a file with very important configuration parameters like port GPIO assignments, DDR memory parameters, Video resolution
etc, download the script.bin using wget command

# wget "https://drive.google.com/uc?export=download&id=0BwplT87k9SCgYXhpQ2djd2hZRDg"
# cp script.bin /mnt/sd
# sync
# umount /dev/sdX1

*****

8. Debian rootfs

The Linux Kernel and Uboot are ready, now we have need from Linux distribution rootfs.

Basically the only difference between the different Linux distributions is the rootfs, so if you put Debian rootfs you will have
Debian, if you put Ubuntu rootfs it will be Ubuntu etc.

How to build one is a long topic, the good thing is that there are many already pre-built so we can just download one and use.

exit the kernel directory

# cd ..

You should be in the directory below

/home/user/a13-micro-SOM-kernel_3.4

download the torrent of the archive with debian rootfs - a13_micro_SOM_debian_FS.tgz using wget command

# wget https://www.olimex.com/wiki/images/1/18/A13_micro_SOM_debian_FS.torrent

Launch a torrent client and download the file.

mount your sd card EXT3 FS partition:

# mount /dev/sdX2 /mnt/sd

and extract the archive containing rootfs:

# tar xzvf a13_micro_SOM_debian_FS.tgz -C /mnt/sd
# ls /mnt/sd

the expected result should be: bin dev home lost+found mnt proc run selinux sys usr boot etc lib media opt root sbin srv tmp var

Now you have to replace the new generated kernel modules from /home/user/a13-micro-SOM-kernel_3.4linux-sunxi/out/lib/modules/ to the
new debian file system:

# rm -rf /mnt/sd/lib/modules/*
# cp -rfv linux-sunxi/out/lib/modules/3.x.xx+/ /mnt/sd/lib/modules/

where x.xx is the kernel version in our case:

# cp -rfv linux-sunxi/out/lib/modules/3.4.90+/ /mnt/sd/lib/modules/

replace /lib/firmware folder with the generated /linux-sunxi/out/firmware

# rm -rf /mnt/sd/lib/firmware/
# cp -rfv linux-sunxi/out/lib/firmware/ /mnt/sd/lib/
# sync
# umount /mnt/sdX2

At this point you have Debian on your SD card second partition and you have an SD card ready to boot debian on A13-OLinuXino-Micro/SOM

Connect USB-SERIAL-CABLE-F to UEXT Tx,Rx, and GND, or connect a HDMI monitor. Put the SD-card in A13-OLinuXino-Micro/SOM and appl
5V power, you should see u-boot and then kernel messages on the serial console.

default username/password is : root / olimex

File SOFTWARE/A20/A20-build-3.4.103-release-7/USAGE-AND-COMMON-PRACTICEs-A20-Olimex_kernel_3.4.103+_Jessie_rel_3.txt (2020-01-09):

Advice and common practices for A20-SOM, A20-OLinuXino-MICRO, A20-OLinuXino-LIME,
A20-OLinuXino-LIME2 boards

I. Card preparation
---

There are three ways to get a working Linux card. First, you can download the official Debian image
from the wiki article of the board and download it to a microSD card - each board has own wiki
article and specific Debian image so make sure that you are getting the proper Debian image from the
correct wiki article. Alternatively, you can purchase a card with Debian on it - again make sure
that the card is suitable for the board that you purchased. If you have doubts drop us an e-mail or
post in the forums.

The third way of getting a working microSD is to prepare the image from scratch. The step-by-step
guide on how to do it can be found in the GitHub.

Note: We sell microSD cards with pre-loaded official Debian that you just plug and use. These are
8GB class 10 fast cards. If you are going to download the image and prepare a microSD card please
use at least 8GB card with similar speed card (or faster) or the performance of  will slow
down. The latest official image is Debian Jessie Linux with mainline u-boot and kernel 3.4.103+.

All images are archived. Before you can download the image to the microSD card you need to extract
the archive and you need an external microSD card reader. To extract the file:

1. under Windows

Use 7zip and then use Win32DiskImager.exe (http://sourceforge.net/projects/win32diskimager/) for
image writing.

1.2 under Linux

Use p7zip package. If you have no installed 7zip then type

#apt-get install p7zip

Copy the archived image to your directory and unzip it with

#7za e a20-XXX.7z

,where a20-XXX.7z must be replaced with the name of the image that you downloaded

The output should be a new file named a20-XXX.img.

Insert a suitable microSD card (at least 8GB, preferably class 10 speed) in your card reader and
type

#ls /dev/sd

Then press two times <TAB> you will see a list of your sd devices like sda sdb sdc note that some of
these devices may be your hard disk so make sure you know which one is your microSD card before you
proceed as you can damage your HDD if you choose the wrong sd-device. You can determine which is the
card by unplugging your sd card reader and identify which "sd" devices remove from the list. Once
you know which device is your sdcard like sda use this text instead of the sdX name in the
references below:

#dd if=a20-XXX.img of=/dev/sdX

Note that the image is 8GB and if you write it on bigger SD card it is reccomended to resize it in
order to use all SD card space. From root directory start resize_sd.sh script with the following
parameters

#./resize_sd.sh /dev/mmcblk0 2

II. Default user name and password
---

Under the command line interface you are automatically logged as super user (user "root", password
"olimex"). However, under the graphical environment you are not auto-logged as super user and you
must type "sudo" before the command (in the GUI the super-user is "olimex" and the password is
"olimex").

The list of all installed packages is located in debian_jessie_installed_packages.txt file

III. Changing A20-XXX HDMI, LCD or VGA video output resolution 
---

The default SD card setup is made with settings for HDMI 720p/60Hz. If you want to change to some
other LCD, VGA or HDMI resolution then you have to start change_display.sh script file in /root
directory. When you are logged as super user in the board type:

For Debian Wheezy releases: #./change_display* (* = press 'tab')
For Debian Jessie releases: #change_display* (* = press 'tab')

and press "Enter".

Note that the script should be executed as super user. Under the command line interface you are
automatically logged as super user (user "root", password "olimex"). However, under the graphical
environment you are not auto-logged as super user and you must type "sudo" before the command (in
the GUI the super-user is "olimex" and the password is "olimex").

Then choose the resolution and the interface(LCD, HDMI or VGA). Note that the selection of a
specific resolution is done by navigating with the arrow keys and pressing "space" button. Make sure
the asterisk marks your selection properly. 

- For the 15.6 and the 15.6-FHD LCDs you can control the backlight duty percentage and DCR(Dinamic
Contrast Ratio) using a soft pwm module. The main goal is to decrease power consumption. For
example:

#echo 50 > /sys/class/softpwm/backlight/duty

will decrease the LCD backlight to 50%, the parameter for duty can be between 0 and 100

#echo 10 > /sys/class/softpwm/duty

will decrease the LCD contrast, the parameter 10 for duty is between 0 and 100 

- For the rest of the displays - 4.3", 7" and 10" LCD  you can control only backlight a hardware pwm
module. The main goal is to decrease power consumption. For example:

#echo 50 > /sys/class/pwm-sunxi/pwm0/duty_percent

will decrease the LCD backlight to 50%, the parameter for duty_percent is between 0 and 100

IV. Editing configurations - changing script.bin file
---

Note that you have to be very carefull with script.bin changing because the system can stop working.
It is recommeded to make backup of script.bin file before change it.

If you want to convert script.bin file from sdcard to script.fex file first you have to mount the
first sdcard patition:

#mount /dev/mmcblk0p1 /mnt

Then use bin2fex script to convert and script.bin to script.fex:

#bin2fex /mnt/script.bin script.fex

Now you can change the board modules and parameters, save the changes and exit from nano editor:

#nano script.fex
#save and exit

Now you have to convert script.fex to script.bin and replace it:

#fex2bin script.fex /mnt/script.bin

Then reboot: 

#reboot

V. Hardware tested, interfaces usage and instructions
---

Note that not all A20 boards have all the hardware described below. The main tested onboard hardware
modules are:

- GPIOs - these are located in /sys/class/gpio directory. Note that first you have to export GPIOs.
For example, to exporte export all available GPIOs:

for i in `seq 1 1 230`; do echo $i > /sys/class/gpio/export; done

To set a port as output:

#echo out > /sys/class/gpio/gpioXX_pxx/direction

To set a port in high level (locical 1):

#echo 1 > /sys/class/gpio/gpioXX_pXX/value

- LCD - 4.3"(480x272), 7"(800x480), 10"(1024x600), 15"(1366x768), 15"(1080x1920)
- SATA - with power on/off control and battery support
- HDMI - the default HDMI resolution is 720p50(720x1280 - 50 Hz)
- Touch screens for the display - you need to calibrate the touch screen first. Use the graphical
environment to do that. Launch Calibrate Touchscreen application from Preferences menu(press the
button in down left corner). In order to save calibration data it is better to copy values from the
window that appears after calibrations to Option "Calibration" section in
/usr/share/X11/xorg.conf.d/10-evdev.conf file. It is something like - Option "Calibration" "3999 66
198 3938". To open the file use:

#nano /usr/share/X11/xorg.conf.d/10-evdev.conf

- ASIX8877 USB-LAN - https://www.olimex.com/Products/OLinuXino/A13/USB-ETHERNET-AX88772B/ - usually
it is eth1 interface
- USB WEB camera A4TECH
- WIFI-RTL8188 - https://www.olimex.com/Products/Modules/Ethernet/MOD-WIFI-RTL8188/ - you have to
set your SSID network and your password in /etc/network/interfaces file; if there are problems in
bringing the WIFI interface up; first create a file "/etc/modprobe.d/blacklist-rtlcommon.conf" 
then access it for editing with command "nano /etc/modprobe.d/blacklist-rtlcommon.conf". Inside 
the file insert these three lines:

install rtl8192cu /bin/false
install rtl8192c_common /bin/false
install rtlwifi /bin/false

Save and close the file (Ctrl+X; Y; Enter). Finally, reboot the board with "reboot" command.
- MOD-WIFI-R5370 - https://www.olimex.com/Products/USB-Modules/MOD-WIFI-R5370 - you have to set your
SSID network and your password in /etc/network/interfaces file
- USB-OTG - low/full/high USB host - there is USB gadgets module enabled, you can use USB_OTG for
SSH connection without need of LAN cable or serial cable. You can use only mini USB cable connected
between your host PC and the onboard mini USB connector. For connection convenience there a DHCP
server started only for USB0 interface. So the DHCP server should give IP address to the new USB0
interface of your host PC and you can make SSH connection from your PC to the default board IP
address of USB0 interface - 192.168.2.1. Note that USB0 interface IP address by default  is
192.168.2.1 Therefore the host IP address has to be in this network - 192.168.2.xxx(except
192.168.2.1). Use login:olimex and password:olimex to connect with the board.

- USB-HOSTs - low/full/high USB hosts
- MOD-USB3G	-	https://www.olimex.com/Products/USB-Modules/MOD-USB3G - in order to test MOD-USB3G
module you need to make sure that usb-modeswitch is installed. Issue the following commands:

  apt-get update
  apt-get install usb-modeswitch
  sudo reboot

Then place the SIM card (without pin code) in the module and connect it to USB host connector, 
then edit the network settings in /etc/wvdial.conf file according to your mobile operator
and type:

  #wvdial <name_specified_in_wvdial>

A wvdial.conf that we have used successfully here (use only as reference):

[Dialer VIVACOM]
Init1 = ATZ
Init2 = ATQ0 V1 E1 S0=0 &C1 &D2 +FCLASS=0
Init3 = AT+CGDCONT=1,"IP","internet.vivacom.bg"
Stupid Mode = 1
Modem Type = Analog Modem
ISDN = 0
Phone = *99#
Modem = /dev/ttyUSB0
Username = {VIVACOM}
Password = {VIVACOM}
Baud = 460800

Then I run:

  wvdial VIVACOM &

and ping with

  ping google.com

If you have problems try to add the modem manually with:

  nano /etc/usb_modeswitch.d/05c6\:1000

This opens a new file and you enter the following information inside:

  TargetVendor=0x05c6
  TargetProduct=0x6000
  StandardEject=1
  
Save and close the file. Try again.
- micoSD card interface - Linux boots from this microSD card usually; in case you boot from NAND it
can be used as a storage
- SD card interface - can be used as storage 
- ETHERNET - 100Mb/1000Mb. By default the board IP address is 192.168.1.254. So if you want to
connect with the board via the Ethernet connector using SSH client (for example PuTTY -
http://www.chiark.greenend.org.uk/~sgtatham/putty/) then you have to use this address. You can
change this address from /etc/network/interface file. Note that for internet connection you have to
set your gateway address in /etc/network/interdaces file and you have to set your DNS server in
/etc/resolv.conf (for example nameserver 192.168.1.1)

- MICROPHONE INPUT and HEADPHONES OUTPUT - to stream the audio from the MICROPHONE jack to the
HEADPHONE jack use:

#arecord -f dat -r 60000 -D plughw:0,0 | aplay

- NAND support - /dev/nandX. Alternatively, ou can use boot linux only from NAND without using SD
card. Use naninstall script to do this:

#nandinstall

Be patient. This operation will take around 10 minutes. If it fails the first time, run it again. 
If you face problems with nandinstall then visit this wiki 
article: https://www.olimex.com/wiki/How_to_install_Debian_to_NAND

If after installation to the NAND you have problems with the Ethernet, check the value of address 
0x01c20164 in the memory, if it is 0x0 then change the value to 0x1006. Do the following:

Check the value with:

devmem 0x01c20164

Change the value with:

devmem 0x01c20164 w 0x1006

- emmc support - /dev/mmcblk1p1 - you can copy SD card image to onboard emmc chip and then you can
boot from the emmc device. Use emmc.sh script to do this:

#./emmc.sh

- I2C2(100KHz) - /dev/i2c-2
- I2C1(100KHz) - /dev/i2c-1
- UART4(only for A20-LIME and A20-LIME2) - /dev/ttyS1
- UART6(only for A20-SOM, A20-OLinuXino-MICRO) - /dev/ttyS1
- UART7(only for A20-SOM, A20-OLinuXino-MICRO) - /dev/ttyS2
- SPI1((only for A20-SOM, A20-OLinuXino-MICRO)) - /dev/spidev1.0
- SPI2 - /dev/spidev2.0 there is a simple test for SPI2 in /opt/spidev directory:

#ls /opt/spidev

- MOD-TC - in folder max6675/ there is example related with
MOD-TC(https://www.olimex.com/Products/Modules/Sensors/MOD-TC/open-source-hardware) - temperature
sensor that you have to connect to UEXT1 connector:

#cd max6675
#./MAX6675
the last command will read temperature from MOD-TC thermocouple

- BUTTONs - we use evtest package for testing. To start it:

#evtest

then enter event number for keyboard and now you can press the BUTTONs and you should see the result
on terminal window.

- on board camera support (only for A20-SOM-EVB) - you can do a simple camera test if you paste the
next command:

#mplayer -fps 60  -tv driver=v4l2:width=640:height=480:device=/dev/video0 tv:// 

and see camera stream to fremebufer output you set - HDMI, VGA or LCD

- USB gadgets - you can use mini USB connector to connect with the board via SSH. Note that USB0
interface IP address by default  is 192.168.2.1 Therefore the host IP address has to be in this
network - 192.168.2.xxx(except 192.168.2.1). Use login:olimex and password:olimex to connect with
the board.

- Video playing with full hardware acceleration. Open a console window in X environment. Type:

#export VDPAU_DRIVER=sunxi
#mpv --vo=vdpau --hwdec=vdpau --hwdec-codecs=all test.mp4
, where test.mp4 is the video file name

- CAN bus
for example you have to use 2 A20-CAN board connected to GPIO3 connector of A20-Olinuxino boards and connected with CAN bus. 
https://www.olimex.com/wiki/A20-CAN

if the one board is server then type:

# ip link set can0 down
# ip link set can0 up type can bitrate 1000000 triple-sampling on loopback off
# ip link set can0 up
# candump can0

if the other is client then type:

# ip link set can0 down
# ip link set can0 up type can bitrate 1000000 triple-sampling on loopback off
# ip link set can0 up
# cansend can0 123#1E.66.55

You will receive can data from server

- External interrupts (EINT)

Export some GPIOs - for example number 1 to number 89 (refer to the FEX file to make sure these are free-to-use).

# for i in `seq 1 1 89`; do echo $i > /sys/class/gpio/export; done

That exports all the ones not already used in the FEX file.

Then look for 'edge':

# root@A20-OLinuXino:~# find / -name edge

This returns a list:

# /sys/devices/platform/gpio-sunxi/gpio/gpio58_pi10/edge 
# /sys/devices/platform/gpio-sunxi/gpio/gpio59_pi11/edge 
# /sys/devices/platform/gpio-sunxi/gpio/gpio60_pi14/edge 

...

# /sys/devices/platform/gpio-sunxi/gpio/gpio26_ph19/edge 
# /sys/devices/platform/gpio-sunxi/gpio/gpio27_ph20/edge 
# /sys/devices/platform/gpio-sunxi/gpio/gpio28_ph21/edge 

Then raise the edge for a specific pin (replace xx_xxxx with the pin from the list of exported ones):

# echo rising > /sys/class/gpio/gpioxx_xxxx/edge

Looked at the new interrupt that appeared in /proc/interrupts with a 'gpio-sunxi gpiolib' tag

Look in the A20 manual and get the EINT numbers and look at the Linux interrupt number.

The Linux interrupt number is 160 + EINT number! For example:

GPIO        EINT Linux Int

gpio58_pi10  22  182
gpio59_pi11  23  183
gpio60_pi14  26  186

.
.
.

gpio28_ph21  21  181

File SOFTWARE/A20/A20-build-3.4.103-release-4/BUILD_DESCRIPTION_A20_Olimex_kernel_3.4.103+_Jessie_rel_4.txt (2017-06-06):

How to make a bootable SD card for Olimex's A20-SOM, A20-OLinuXino-MICRO, A20-OLinuXino-LIME,
A20-OLinuXino-LIME2 boards with sunxi kernel 3.4.103 and Linux Debian Jessie file system

---

Chapter 1. Setting up the software tools

---

First, make sure that you have the software tools needed to compile the Linux Kernel. You'd have to install
these if you don't have them already installed. To perform most of the operations below you should be logged
as a user with super user rights on your Linux machine. Type in the terminal:

# sudo su

You will be prompted for your password and then your command line would start with # which means that you are
now logged as the super user, all commands listed below should be executed in this mode.

Next update apt-get links by typing:

# apt-get update

Next install the same compiler toolchain that we used here by typing the following:

# apt-get install gcc-4.7-arm-linux-gnueabihf ncurses-dev uboot-mkimage build-essential git

This will install: GCC compiler used to compile the kernel; the kernel config menu; the uboot make image that
is required to allow the SD card to boot into the Linux image; GIT that allows you to download from the github
which holds source code for some of the system; some other tools for building the kernel.

Note that if you use debian may be you will need to add:

deb http://www.emdebian.org/debian squeeze main

in the file below:

/etc/apt/sources.list

You would also need a torrent client. It is required to be able to download the file system. Any torrent
client would do the job, as long as it can process .torrent files.

At this point you should have have all important tools to make your very own A20 kernel image!

---

Chapter 2. Building mainline u-boot

---

First create the directory where we would build the Linux:

# mkdir a20-olimex
# cd a20-olimex

Then download the latest mainline u-boot sources from GitHub repository:

# git clone git://git.denx.de/u-boot.git

After the download you should have a new directory, naviagate into it with:

# cd u-boot/

The image is tested with the commit  Mon Sep 12 10:05:51 2016 -0400

To switch from the latest sources to the exact commit that we used execute the next command:

# git reset --hard  8cbb389bb3da80cbf8911f8386cbff92c6a78afe

or 

git checkout v2016.09 -b tmp

!MAKE SURE THAT YOU HAVE REVERTED TO THE SAME COMMIT OR NOTHING BELOW WOULD WORK!

For this u-boot commit you need from a patch that reduces A20 DRAM speed from 480 to 384 MHz to improve board stability and it makes support for different types of gigabit PHY chips we used. 
For this purpose download a20-phy-dram.patch file using wget command:

# wget https://raw.githubusercontent.com/OLIMEX/OLINUXINO/master/SOFTWARE/A20/A20-build-3.4.103-release-4/a20-phy-dram.patch

and then patch the uboot sources with:

# patch -p1 < a20-phy-dram.patch

If you don't apply the patch you might have severely reduced Gigabit Ethernet speed.

---
Note that the compiler version that the u-boot is built and tested is :
arm-linux-gnueabihf-gcc (crosstool-NG linaro-1.13.1-4.9-2014.09 - Linaro GCC 4.9-2014.09) 4.9.2 20140904 (prerelease)

Now you have to load configuration file for your board. 
because there are four different configurations for u-boot which depend on the exact board that you have. Do only the
point for your board:

---

2.1 A20-OLinuXino-LIME2 board

# make A20-OLinuXino-Lime2_defconfig  ARCH=arm CROSS_COMPILE=arm-linux-gnueabihf-

If your board has eMMC memory installed (instead of NAND memory) then you have to change the extra MMC slot
number in the u-boot in order to be possible to boot only from eMMC

# make ARCH=arm menuconfig

Go to ARM architecture -> and change mmc extra slot number to 2

ESC ESC

Save and Exit

---

2.2 A20-SOM board

# make A20-Olimex-SOM-EVB_defconfig ARCH=arm CROSS_COMPILE=arm-linux-gnueabihf-

// If there are problems at the step above (for example if the SOM-EVB defconfig is missing) use the LIME2
defconfig instead, type:
// # make A20-OLinuXino-Lime2_defconfig ARCH=arm CROSS_COMPILE=arm-linux-gnueabihf-
// # make ARCH=arm menuconfig

---

2.3 A20-OLinuXino-MICRO board

# make A20-OLinuXino_MICRO_defconfig ARCH=arm CROSS_COMPILE=arm-linux-gnueabihf-

---

2.4 A20-OLinuXino-LIME board

# make A20-OLinuXino-Lime_defconfig ARCH=arm CROSS_COMPILE=arm-linux-gnueabihf-

---
for all boards you can change many other settings using:

# make ARCH=arm menuconfig

but you have to be very carefullly

Now type the following command to compile the u-boot:

# make ARCH=arm CROSS_COMPILE=arm-linux-gnueabihf-

At the end of the process you can check if everything is OK by using:

# ls u-boot.bin u-boot-sunxi-with-spl.bin spl/sunxi-spl.bin

spl/sunxi-spl.bin  u-boot.bin  u-boot-sunxi-with-spl.bin

If you got these files everything is complete, well done so far

# cd ..

You should be in the following directory:

/home/user/a20-olimex#

---

Chapter 3. Building sunxi kernel from sources for A20 boards

---

The sunxi kernel sources for A20 are available at GitHub. Note that the our build uses this exact commit: 

9a1cd034181af628d4145202289e1993c1687db6 from Sat Oct 4 07:59:35 2014 +0300

You can download the latest kernel sources using the following command:

# git clone https://github.com/linux-sunxi/linux-sunxi

After the download navigate to the kernel directory:

# cd linux-sunxi/

You should switch to this exact commit with the next command:

# git reset --hard 9a1cd034181af628d4145202289e1993c1687db6

---

3.3 Configuring the rest of the environment

---

You need to get the a20 configuration file – A20-linux-3.4.103_defconfig. The file contains all kernel
module settings. Download A20-linux-3.4.103_defconfig using wget command 

# wget https://raw.githubusercontent.com/OLIMEX/OLINUXINO/master/SOFTWARE/A20/A20-build-3.4.103-release-2/A20-linux-3.4.103_defconfig

then copy A20-linux-3.4.103_defconfig file to configs directory:

# cp A20-linux-3.4.103_defconfig arch/arm/configs/

and make:

# make ARCH=arm A20-linux-3.4.103_defconfig 

The result should be:

configuration written to .config

If you wish to make changes to the kernel configuration execute the following:

# make ARCH=arm menuconfig

The menuconfig changes a .config text file, which you can view/edit even with a text editor like vi, nano.
Using this command you can add or remove different modules for the different peripherials in the kernel. Be
careful when you change these settings because the kernel can stop working properly.

If your board has eMMC then you have to apply a patch that fixes the problems with HighPriorityInterrupt
related with eMMC support

Download the patch file a20-emmc_2.patch using wget command

# wget https://github.com/OLIMEX/OLINUXINO/raw/master/SOFTWARE/A20/A20-build-3.4.103-release-3/a20-emmc_2.patch

and patch the drivers/mmc/core/mmc.c file

# patch -p1 < a20-emmc_2.patch

Now you may continue with kernel image compiling 

# make ARCH=arm CROSS_COMPILE=arm-linux-gnueabihf- -j4 uImage

when this finish’s you will have uImage ready and the result should be:

  LD      arch/arm/boot/compressed/vmlinux
  OBJCOPY arch/arm/boot/zImage
  Kernel: arch/arm/boot/zImage is ready
  UIMAGE  arch/arm/boot/uImage
Image Name:   Linux-3.4.103-00033-g9a1cd03-dir
Created:      Mon Nov  2 09:29:54 2015
Image Type:   ARM Linux Kernel Image (uncompressed)
Data Size:    4581208 Bytes = 4473.84 kB = 4.37 MB
Load Address: 40008000
Entry Point:  40008000
  Image arch/arm/boot/uImage is ready

The next step is building the kernel modules:

# make ARCH=arm CROSS_COMPILE=arm-linux-gnueabihf- -j4 INSTALL_MOD_PATH=out modules
# make ARCH=arm CROSS_COMPILE=arm-linux-gnueabihf- -j4 INSTALL_MOD_PATH=out modules_install

DONE! At this point you have uboot and kernel modules.

The uImage file is located in linux-sunxi/arch/arm/boot/

The kernel modules are located in linux-sunxi/out/lib/modules/3.x.xx,
where 3.x.xx is kernel version. In our case the directory with modules is:

linux-sunxi/out/lib/modules/3.4.103

---

4. Format and setup the SD-card

---

We suggest using a class 10 microSD card with memory capacity at least 8GB. We haven't tested microSD cards
bigger than 16GB.

First we have to make the correct card partitions using fdisk. Plug SD card into your SD card reader and enter
in the terminal:

# ls /dev/sd

Then press two times <TAB> you will see a list of your sd devices like sda sdb sdc note that some of these
devices may be your hard disk so make sure you know which one is your sd card before you proceed as you can
damage your HDD if you choose the wrong sd-device. You can do this by unplugging your sd card reader - pay
attention which "sd" device disappears from the list.

Once you know which one is your microSD (as sda#) use it instead of the sdX name in the references below:

# fdisk /dev/sdX

then:

4.1. p

will list your partitions. If there are already partitions on your card do:

4.2. d enter 1

if you have more than one partitition press d while delete them all

4.3. create the first partition, starting from 2048

n enter p enter 1 enter enter +16M

4.4. create second partition

n enter p enter 2 enter enter enter

then list the created partitions:

p enter

if you did everything correctly on 4GB card you should see something like:

Disk /dev/sdg: 3980 MB, 3980394496 bytes
123 heads, 62 sectors/track, 1019 cylinders, total 7774208 sectors
Units = sectors of 1 * 512 = 512 bytes
Sector size (logical/physical): 512 bytes / 512 bytes
I/O size (minimum/optimal): 512 bytes / 512 bytes
Disk identifier: 0x00000000

   Device Boot      Start         End      Blocks   Id  System
/dev/sdg1            2048       34815       16384   83  Linux
/dev/sdg2           34816     7774207     3869696   83  Linux

4.5. press w

write changes to sd card

Now we have to format the file system on the card (the first partition should be vfat as this is FS which the
Allwinner bootloader understands):

# mkfs.vfat /dev/sdX1

The second should be normal Linux EXT3 FS:

# mkfs.ext3 /dev/sdX2

---

5. Write the Uboot and u-boot-sunxi-with-spl.bin

---

You should be in /home/user/a20-olimex# directory 

Note that you have to write u-boot-sunxi-with-spl.bin in /dev/sdX (not sdX1 or sdX2)

Type:

# dd if=u-boot-sunxi/u-boot-sunxi-with-spl.bin of=/dev/sdX bs=1024 seek=8

---

6. Write the kernel uImage to the SD-card

---

You should be in the directory below

/home/user/a20-olimex# directory

# mkdir /mnt/sd
# mount /dev/sdX1 /mnt/sd

copy the Kernel uImage to root directory in partition 1:

# cp linux-sunxi/arch/arm/boot/uImage /mnt/sd

---

7. Write script.bin file

---

script.bin is a very important file with parameters like port GPIO assignments, DDR memory parameters, video
resolution etc. Depending on the A20 board that you own you have to download and write different script.bin
file.

7.1.1 for A20-OLinuXino-LIME2 board or A20-OLinuXino-LIME2 board with NAND download the script.bin file using
wget command

# wget https://github.com/OLIMEX/OLINUXINO/raw/master/SOFTWARE/A20/A20-build-3.4.103-release-2/scripts/script_a20_Lime2_NAND_rel_2/script.bin

7.1.2 for A20-OLinuXino-LIME2 board with EMMC download the script.bin file using wget command

# wget https://github.com/OLIMEX/OLINUXINO/raw/master/SOFTWARE/A20/A20-build-3.4.103-release-2/scripts/script_a20_lime2_emmc/script.bin

7.2 for A20-SOM board download the script.bin file using wget command

# wget https://github.com/OLIMEX/OLINUXINO/raw/master/SOFTWARE/A20/A20-build-3.4.103-release-2/scripts/script_a20-SOM_rel_3/script_a20_SOM_HDMI_720p50/script.bin

7.3 for A20-OLinuXino-MICRO board download the script.bin file using wget command

# wget https://github.com/OLIMEX/OLINUXINO/raw/master/SOFTWARE/A20/A20-build-3.4.103-release-2/scripts/script_a20_OLinuXino-micro_rel_10/script.bin

7.4 for A20-OLinuXino-LIME board download the script.bin file using wget command

# wget https://github.com/OLIMEX/OLINUXINO/raw/master/SOFTWARE/A20/A20-build-3.4.103-release-2/scripts/script_a20_lime_rel_3/script.bin

then copy the downloaded script.bin file to the mounted first partition of the SD card:

# cp script.bin /mnt/sd

Download boot.scr and uEnv.txt files

#wget  https://github.com/OLIMEX/OLINUXINO/raw/master/SOFTWARE/A20/A20-build-3.4.103-release-2/boot.scr
#wget  https://github.com/OLIMEX/OLINUXINO/raw/master/SOFTWARE/A20/A20-build-3.4.103-release-2/uEnv.txt

You have to copy in first sd card partition where script.bin file is located

# cp boot.scr /mnt/sd
# cp uEnv.txt /mnt/sd
# sync
# umount /dev/sdX1

----

8. Debian rootfs

---

The Linux Kernel and Uboot are ready, now we need the Linux distribution rootfs.

Basically the only difference between the different Linux distributions is the rootfs, so if you put Debian
rootfs you will have Debian, if you put Ubuntu rootfs it will be Ubuntu etc.

How to build one is a long topic, the good thing is that there are many already pre-built so we can just
download one and use it ready.

Now leave the kernel directory

# cd ..

Should be in the directory below

# /home/user/a20-olimex

Download debian rootfs with the file name "Debian_FS_34_103_Jessy_8.1_A20-olimex_rel_2", which is available
only as a torrent. You would need a torrent client for it (Azureus, uTorrent, qBittorrent, etc). The link to
the torrent file is:

# wget https://www.olimex.com/wiki/images/a/a4/Debian_FS_34_103_Jessy_8.1_A20-olimex_rel_2.torrent

Launch the torrent client and download the file.

Now mount the microSD card EXT3 FS partition:

# mount /dev/sdX2 /mnt/sd

and unarchive the rootfs

# tar xzvf Debian_FS_34_103_Jessy_8.1_A20-olimex_rel_2 -C /mnt/sd
# ls /mnt/sd

The correct result should be:
bin   dev  home  lost+found  mnt  proc  run   selinux  sys  usr
boot  etc  lib   media       opt  root  sbin  srv      tmp  var

Now you have to replace the newly generated kernel modules from
/home/user/a20-olimex/linux-sunxi/out/lib/modules/ to the new Debian file system:

# rm -rf /mnt/sd/lib/modules/*

# cp -rfv linux-sunxi/out/lib/modules/3.x.xx+/ /mnt/sd/lib/modules/

where x.xx is the kernel version

in our case:

# cp -rfv linux-sunxi/out/lib/modules/3.4.103/ /mnt/sd/lib/modules/

replace /lib/firmware folder with the generated /linux-sunxi/out/firmware

#cp -rfv linux-sunxi/out/lib/firmware/ /mnt/sd/lib/

# sync
# umount /mnt/sdX2

At this point you have Debian on your SD card second partition and you have an SD card ready to boot debian on
A20-SOM or A20-OLinuXino-MICRO or A20-OLinuXino-LIME or A20-OLinuXino-LIME2

Connect USB-SERIAL-CABLE-F to UEXT Tx, Rx and GND, or connect a HDMI screen. Put the SD-card apply power
according to A20 board type. You should see u-boot and then kernel messages on the console.

Under the command line interface you are automatically logged as super user (user "root", password "olimex").
However, under the graphical environment you are not auto-logged as super user and you must type "sudo" before
the command (in the GUI the super-user is "olimex" and the password is "olimex").

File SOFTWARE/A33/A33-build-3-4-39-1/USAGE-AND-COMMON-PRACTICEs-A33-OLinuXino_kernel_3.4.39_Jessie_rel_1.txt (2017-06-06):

Advice and common practices for A33-OLinuxino booard

I. Card preparation
---

There are three ways to get a working Linux card. First, you can download the official Debian image from the wiki article of the board and download it to a microSD card - each board has own wiki article and specific Debian image so make sure that you are getting the proper Debian image from the correct wiki article. Alternatively, you can purchase a card with Debian on it - again make sure that the card is suitable for the board that you purchased. If you have doubts drop us an e-mail or post in the forums.

The third way of getting a working microSD is to prepare the image from scratch. The step-by-step guide on how to do it can be found in the GitHub.

Note: We sell microSD cards with pre-loaded official Debian that you just plug and use. These are 8GB class 10 fast cards. If you are going to download the image and prepare a microSD card please use at least 8GB card with similar speed card (or faster) or the performance of Linux will slow down. The latest official image is Debian Jessie Linux with mainline u-boot and kernel 3.4.39+.

All images are archived. Before you can download the image to the microSD card you need to extract the archive and you need an external microSD card reader. To extract the file:

1. under Windows

Use 7zip and then use Win32DiskImager.exe (http://sourceforge.net/projects/win32diskimager/) for image writing.

1.2 under Linux

Use p7zip package. If you have no installed 7zip then type

#apt-get install p7zip

Copy the archived image to your directory and unzip it with

#7za e a33-XXX.7z

,where a33-XXX.7z must be replaced with the name of the image that you downloaded

The output should be a new file named a33-XXX.img.

Insert a suitable microSD card (at least 8GB, preferably class 10 speed) in your card reader and type

#ls /dev/sd

Then press two times <TAB> you will see a list of your sd devices like sda sdb sdc note that some of these devices may be your hard disk so make sure you know which one is your microSD card before you proceed as you can damage your HDD if you choose the wrong sd-device. You can determine which is the card by unplugging your sd card reader and identify which "sd" devices remove from the list. Once you know which device is your sdcard like sda use this text instead of the sdX name in the references below:

#dd if=a33-XXX.img of=/dev/sdX

Note that the image is 8GB and if you write it on bigger SD card it is reccomended to resize it in order to use all SD card space. From root directory start resize_sd.sh script with the following parameters

#./resize_sd.sh /dev/mmcblk0 1

II. Default user name and password
---

Under the command line interface you are automatically logged as super user (user "root", password "olimex"). However, under the graphical environment you are not auto-logged as super user and you must type "sudo" before the command (in the GUI the super-user is "olimex" and the password is "olimex").

III.  Editing configurations - changing script.bin file
---

Note that you have to be very carefull with script.bin changing because the system can stop working. It is recommeded to make backup of script.bin file before change it.

If you want to convert script.bin file from sdcard to script.fex file first you have to convert it using bin2fex tool.
the script.bin file is located in /boot directory

#bin2fex /boot/script.bin script.fex

Now you can change the board modules and parameters, save the changes and exit from nano editor:

#nano script.fex
#save and exit

Now you have to convert script.fex to script.bin and replace it:

#fex2bin script.fex /boot/script.bin

Then reboot: 

#reboot

V. Hardware tested, interfaces usage and instructions
---

Note that not all A33 boards have all the hardware described below. The main tested onboard hardware modules are:

- GPIOs - these are located in /sys/class/gpio directory. Note that first you have to export GPIOs. For example, to exporte export all available GPIOs:

for i in `seq 1 1 230`; do echo $i > /sys/class/gpio/export; done

To set a port as output:

#echo out > /sys/class/gpio/gpioXX_pxx/direction

To set a port in high level (locical 1):

#echo 1 > /sys/class/gpio/gpioXX_pXX/value

- LCD - 5"(800x480) with capacitive touchscreen controler ft5x

#nano /usr/share/X11/xorg.conf.d/10-evdev.conf

- ASIX8877 USB-LAN - https://www.olimex.com/Products/OLinuXino/A13/USB-ETHERNET-AX88772B/ - usually it is eth1 interface
- WIFI-RTL8188 - https://www.olimex.com/Products/Modules/Ethernet/MOD-WIFI-RTL8188/ - you have to set your SSID network and your password in /etc/network/interfaces file
- MOD-WIFI-R5370 - https://www.olimex.com/Products/USB-Modules/MOD-WIFI-R5370 - you have to set your SSID network and your password in /etc/network/interfaces file
- MINI-USB - It is configured only like HOST

- USB-HOST on GPIO connector - low/full/high USB hosts

- micoSD card interface - Linux boots from this microSD card usually; 

- MICROPHONE INPUT and HEADPHONES OUTPUT - to stream the audio from the MICROPHONE jack to the HEADPHONE jack use:

#arecord -f S16_LE | aplay

- NAND support - /dev/nandX. 
Note that you have to load nand.ko module located in /lib/modules/3.4.39+/kernel/drivers/
For example:
#modprobe nand
or
#insmod /lib/modules/3.4.39+/kernel/drivers/
Unfortunately currently there is no other method to prepare the NAND except for programing with android image using phoenix suit first. 

- I2C1(100KHz) - /dev/i2c-0 - SCL pin - PH02; SDA pin - PH03 (pins #36 and #34 of the GPIO connector)
- I2C2(100KHz) - /dev/i2c-1 - SCL pin - PH04; SDA pin - PH05 (pins #32 and #30 of the GPIO connector)
- UART0 (debug) - /dev/ttyS0 - TX pin - PB00; RX pin - PB01 (at available at UART0 header)
- UART1 - /dev/ttyS1 - TX pin - PG06; RX pin - PG07 (pins #25 and #27 of the GPIO connector)

- BUTTONs - we use evtest package for testing. To start it:

#evtest

then enter event number for keyboard and now you can press the BUTTONs and you should see the result on terminal window.

- on board camera support (only for A20-SOM-EVB) - you can do a simple camera test if you paste the next command:

#mplayer -fps 60  -tv driver=v4l2:width=640:height=480:device=/dev/video0 tv:// 

and see camera stream to fremebufer output you set - HDMI, VGA or LCD

- USB gadgets - you can use mini USB connector to connect with the board via SSH. Note that USB0 interface IP address by default  is 192.168.2.1 Therefore the host IP address has to be in this network - 192.168.2.xxx(except 192.168.2.1). Use login:olimex and password:olimex to connect with the board.

- Video playing with full hardware acceleration. Open a console window in X environment. Type:

#export VDPAU_DRIVER=sunxi
#mpv --vo=vdpau --hwdec=vdpau --hwdec-codecs=all test.mp4
, where test.mp4 is the video file name

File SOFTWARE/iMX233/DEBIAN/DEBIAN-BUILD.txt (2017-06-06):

iMX233-OLinuXino Debian rootfs generation

If you find this boring the good news is that we have already pre-build Debian rootfs and you can just download it from here: https://docs.google.com/open?id=0B-bAEPML8fwlOHJkX2ZNanVfR2s
Then read how to make your boot SD-card as described here: https://github.com/OLIMEX/OLINUXINO/blob/master/SOFTWARE/iMX233/DEBIAN/DEBIAN-README.TXT

Otherwise if you want to go through the learning path follow these instructions:

1. Prepare empty file system - it's good to be > 500MB, in this example we make it 1GB

  $ dd if=/dev/zero of=my.img bs=1024 count=1MB

2. Format the image with the desired root fs, in this example -ext3

  $ sudo mkfs.ext3 -F my.img

3. Mount the image

  $ mkdir rootfs
  $ sudo mount -o loop my.img rootfs/

4. Install Debian toor file system phase 1
 
  $ sudo debootstrap --verbose --arch armel --variant=minbase --foreign squeeze rootfs/http://ftp.debian.org/debian

5. Install the packages necessary for emulation of armel with x86. 
Note: If you make installation of 'Debian squeeze' you must install newer version of 'qemu-user-static' (otherwise you will see error qemu: Unsupported syscall: 341 when you generate the image in phase 2)

Only for 'Debian squeeze'

Add these lines in /etc/apt/preferences 

  Package: *
  Pin: release a=stable
  Pin-Priority: 900
  Package: *
  Pin: release o=Debian
  Pin-Priority: -10
 
add in /etc/apt/apt.conf.d/70debconf
  
  APT::Default-Release "stable";
 
add in /etc/apt/sources.list

  deb http://ftp.debian.org/debian/ testing main contrib

update the list of the packages

  $ sudo apt-get update

install qemu-user-static

  $ sudo apt-get install -t testing qemu-user-static

install binfmt-support

  $ sudo apt-get install binfmt-support

6. Start of phase 2 (this is executed on virtual armel machine). Do these commands:

  $ sudo modprobe binfmt_misc
  $ sudo cp /usr/bin/qemu-arm-static rootfs/usr/bin
  $ sudo mkdir rootfs/dev/pts
  $ sudo mount -t devpts devpts rootfs/dev/pts
  $ sudo mount -t proc proc rootfs/proc
  $ sudo chroot rootfs/

(this is executed on virtual armel machine)
  $ /debootstrap/debootstrap --second-stage

7. To add the apt repositories, you must append these lines in /etc/apt/sources.list

  deb http://security.debian.org/ squeeze/updates main contrib non-free
  deb-src http://security.debian.org/ squeeze/updates main contrib non-free
  deb http://ftp.debian.org/debian/  squeeze main contrib non-free
  deb-src http://ftp.debian.org/debian/  squeeze main contrib non-free

8. Update the list of the packages 
  
  $ apt-get update
 
9. Config your language

  $ export LANG=C
  $ apt-get install apt-utils dialog locales

  $ dpkg-reconfigure locales
  $ export LANG=en_US.UTF-8

10. Installation of some important packages

  $ apt-get install dhcp3-client udev netbase ifupdown iproute openssh-server iputils-ping wget net-tools ntpdate nano less

11. Config your network adapter usb11 and dhcp. Add in /etc/network/interfaces these lines

  # Wireless interfaces
  iface wlan0 inet dhcp
          wireless_mode managed
          wireless_essid any
          wpa-driver wext
          wpa-conf /etc/wpa_supplicant.conf

  auto usb0
  iface usb0 inet dhcp

12. To config the file system add in /etc/fstab these lines:

  /dev/root      /dev/sda2       ext3    noatime,errors=remount-ro  0 1
  tmpfs          /tmp            tmpfs   defaults                   0 0

13. To config the console

  $ echo 'T0:2345:respawn:/sbin/getty -L ttyAMA0 115200 linux' >> /etc/inittab
  $ sed -i 's/^\([1-6]:.* tty[1-6]\)/#\1/' /etc/inittab

13. To config the host name:

  $ hostname <name>

14. To add root password

  $ passwd

15. Exit from the armel virtual machine

  $ exit

16. TO install the modules of Linux Kernel

  $ sudo make ARCH=arm CROSS_COMPILE=arm-linux-gnueabi- INSTALL_MOD_PATH=<path_to>/rootfs modules_install

17. and unfortunately this is only the beginning :) 

in this image we still didn't manage to enable the  TV-console, so we will try to do it later

Stanimir Bonev, Olimex Ltd

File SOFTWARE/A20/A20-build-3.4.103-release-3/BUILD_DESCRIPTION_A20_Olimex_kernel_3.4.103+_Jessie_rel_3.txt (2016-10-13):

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

---

Chapter 1. Setting up the software tools

---

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

# sudo su

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

Next update apt-get links by typing:

# apt-get update

Next install the same compiler toolchain that we used here by typing the following:

# apt-get install gcc-4.7-arm-linux-gnueabihf ncurses-dev uboot-mkimage build-essential git

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

Note that if you use debian may be you will need to add:

deb http://www.emdebian.org/debian squeeze main

in the file below:

/etc/apt/sources.list

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

---

Chapter 2. Building mainline u-boot

---

First create the directory where we would build the Linux:

# mkdir a20-olimex
# cd a20-olimex

Then download the latest mainline u-boot sources from GitHub repository:

# git clone git://git.denx.de/u-boot.git

After the download you should have a new directory, naviagate into it with:

# cd u-boot/

The image is tested with the commit from Mon Oct 19 18:46:28 2015 -0400

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

# git reset --hard  5ec0003b19cbdf06ccd6941237cbc0d1c3468e2d

!MAKE SURE THAT YOU HAVE REVERTED TO THE SAME COMMIT OR NOTHING BELOW WOULD WORK!

Note that if you use the Gigabit interface (if you have A20-OlinuXino-LIME2 and A20-SOM-EVB boards; if you
have other boards or if you don't need Gigabit interface skip this step) then you also need to patch the
u-boot in order to set on board PHY chip in master mode. For this purpose download fix_gigabit_phy.patch file
using wget command:

# wget https://raw.githubusercontent.com/OLIMEX/OLINUXINO/master/SOFTWARE/A20/A20-build-3.4.103-release-2/fix_gigabit
_phy.patch

and then patch the uboot sources with:

# patch -p1 < fix_gigabit_phy.patch

If you don't apply the patch you might have severely reduced Gigabit Ethernet speed.

---

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

---

2.1 A20-OLinuXino-LIME2 board

# make A20-OLinuXino-Lime2_defconfig  ARCH=arm CROSS_COMPILE=arm-linux-gnueabihf-
# make ARCH=arm menuconfig

from the menu select ARM architecture --> sunxi DRAM clock speed and change 480 to 384

then select [*] Enable workarounds for booting old kernels  

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

Go to ARM architecture -> and change mmc extra slot number to 2

ESC ESC

Save and Exit

---

2.2 A20-SOM board

# make A20-Olimex-SOM-EVB_defconfig ARCH=arm CROSS_COMPILE=arm-linux-gnueabihf-
# make ARCH=arm menuconfig

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

from the menu select ARM architecture --> sunxi DRAM clock speed and change 480 to 384

also select [*] Enable workarounds for booting old kernels

ESC ESC

Save and Exit

---

2.3 A20-OLinuXino-MICRO board

# make A20-OLinuXino_MICRO_defconfig ARCH=arm CROSS_COMPILE=arm-linux-gnueabihf-
# make ARCH=arm menuconfig

from the menu select ARM architecture --> select [*] Enable workarounds for booting old kernels  

ESC ESC

Save and exit

---

2.4 A20-OLinuXino-LIME board

# make A20-OLinuXino-LIME_defconfig ARCH=arm CROSS_COMPILE=arm-linux-gnueabihf-
# make ARCH=arm menuconfig

from the menu select ARM architecture --> select [*] Enable workarounds for booting old kernels  

ESC ESC

Save and exit

---

Now type the following command to compile the u-boot:

# make ARCH=arm CROSS_COMPILE=arm-linux-gnueabihf-

At the end of the process you can check if everything is OK by using:

# ls u-boot.bin u-boot-sunxi-with-spl.bin spl/sunxi-spl.bin

spl/sunxi-spl.bin  u-boot.bin  u-boot-sunxi-with-spl.bin

If you got these files everything is complete, well done so far

# cd ..

You should be in the following directory:

/home/user/a20-olimex#

---

Chapter 3. Building sunxi kernel from sources for A20 boards

---

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

9a1cd034181af628d4145202289e1993c1687db6 from Sat Oct 4 07:59:35 2014 +0300

You can download the latest kernel sources using the following command:

# git clone https://github.com/linux-sunxi/linux-sunxi

You can switch to this exact commit with the next command:

# git reset --hard 9a1cd034181af628d4145202289e1993c1687db6

After the download navigate to the kernel directory:

# cd linux-sunxi/

---

3.3 Configuring the rest of the environment

---

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

then copy A20-linux-3.4.103_defconfig file to configs directory:

# cp A20-linux-3.4.103_defconfig arch/arm/configs/

and make:

# make ARCH=arm A20-linux-3.4.103_defconfig 

The result should be:

configuration written to .config

If you wish to make changes to the kernel configuration execute the following:

# make ARCH=arm menuconfig

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

Download the patch file a20-emmc_2.patch using wget command

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

and patch the drivers/mmc/core/mmc.c file

# patch -p1 < a20-emmc_2.patch

Now you may continue with kernel image compiling 

# make ARCH=arm CROSS_COMPILE=arm-linux-gnueabihf- -j4 uImage

when this finish’s you will have uImage ready and the result should be:

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

The next step is building the kernel modules:

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

DONE! At this point you have uboot and kernel modules.

The uImage file is located in linux-sunxi/arch/arm/boot/

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

linux-sunxi/out/lib/modules/3.4.103

---

4. Format and setup the SD-card

---

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

# ls /dev/sd

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

# fdisk /dev/sdX

then:

4.1. p

will list your partitions. If there are already partitions on your card do:

4.2. d enter 1

if you have more than one partitition press d while delete them all

4.3. create the first partition, starting from 2048

n enter p enter 1 enter enter +16M

4.4. create second partition

n enter p enter 2 enter enter enter

then list the created partitions:

p enter

if you did everything correctly on 4GB card you should see something like:

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

4.5. press w

write changes to sd card

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

# mkfs.vfat /dev/sdX1

The second should be normal Linux EXT3 FS:

# mkfs.ext3 /dev/sdX2

---

5. Write the Uboot and u-boot-sunxi-with-spl.bin

---

You should be in /home/user/a20-olimex# directory 

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

Type:

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

---

6. Write the kernel uImage to the SD-card

---

You should be in the directory below

/home/user/a20-olimex# directory

# mkdir /mnt/sd
# mount /dev/sdX1 /mnt/sd

copy the Kernel uImage to root directory in partition 1:

# cp linux-sunxi/arch/arm/boot/uImage /mnt/sd

---

7. Write script.bin file

---

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

7.2 for A20-SOM board download the script.bin file using wget command

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

7.3 for A20-OLinuXino-MICRO board download the script.bin file using wget command

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

7.4 for A20-OLinuXino-LIME board download the script.bin file using wget command

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

then copy the downloaded script.bin file to the mounted first partition of the SD card:

# cp script.bin /mnt/sd

Download boot.scr and uEnv.txt files

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

You have to copy in first sd card partition where script.bin file is located

# cp boot.scr /mnt/sd
# cp uEnv.txt.bin /mnt/sd
# sync
# umount /dev/sdX1

----

8. Debian rootfs

---

The Linux Kernel and Uboot are ready, now we need the Linux distribution rootfs.

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

Now leave the kernel directory

# cd ..

Should be in the directory below

# /home/user/a20-olimex

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

# wget https://www.olimex.com/wiki/images/a/a4/Debian_FS_34_103_Jessy_8.1_A20-olimex_rel_2.torrent

Launch the torrent client and download the file.

Now mount the microSD card EXT3 FS partition:

# mount /dev/sdX2 /mnt/sd

and unarchive the rootfs

# tar xzvf Debian_FS_34_103_Jessy_8.1_A20-olimex_rel_2 -C /mnt/sd
# ls /mnt/sd

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

# rm -rf /mnt/sd/lib/modules/*

# cp -rfv linux-sunxi/out/lib/modules/3.x.xx+/ /mnt/sd/lib/modules/

where x.xx is the kernel version

in our case:

# cp -rfv linux-sunxi/out/lib/modules/3.4.103/ /mnt/sd/lib/modules/

replace /lib/firmware folder with the generated /linux-sunxi/out/firmware

#cp -rfv linux-sunxi/out/lib/firmware/ /mnt/sd/lib/

# sync
# umount /mnt/sdX2

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

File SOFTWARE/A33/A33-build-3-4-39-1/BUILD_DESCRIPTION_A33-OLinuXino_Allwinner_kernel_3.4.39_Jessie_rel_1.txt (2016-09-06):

How to make a bootable SD card for Olimex's A33-OLinuXino with ALLINNER kernel 3.4.39 and Linux Debian Jessie file system

-------------------------------------------

Chapter 1. Setting up the software tools

-------------------------------------------

First, make sure that you have the software tools needed to compile the Linux Kernel. You'd have to install these if you don't have them already installed. To perform most of the operations below you should be logged as a user with super user rights on your Linux machine. Type in the terminal:

# sudo su

You will be prompted for your password and then your command line would start with # which means that you are now logged as the super user, all commands listed below should be executed in this mode.

Next update apt-get links by typing:

# apt-get update

Next install the same compiler toolchain that we used here by typing the following:

# apt-get install build-essential git qemu-user-static debootstrap binfmt-support gcc-5-arm-linux-gnueabihf

This will install: GCC compiler, GIT that allows you to download from the github which holds source code for some of the system; some other tools for building the kernel.

Note that if you use debian may be you will need to add:

deb http://www.emdebian.org/debian squeeze main

in the file below:

/etc/apt/sources.list

You would also need a torrent client. It is required to be able to download the file system. Any torrent client would do the job, as long as it can process .torrent files.

At this point you should have have all important tools to make your very own A33 kernel image!

-------------------------------------------

Chapter 2. Building mainline u-boot

-------------------------------------------

First create the directory where we would build the Linux:

# mkdir a33-olimex
# cd a33-olimex

Then download the latest mainline u-boot sources from GitHub repository:

# git clone git://git.denx.de/u-boot.git

After the download you should have a new directory, naviagate into it with:

# cd u-boot/

The image is tested with the commit from  Mon Jul 4 11:46:21 2016 -0400

To switch from the latest sources to the exact commit that we used execute the next command:

# git reset --hard  e8009beff6d5c55c1bf1ae8184791f167e6378b0

!MAKE SURE THAT YOU HAVE REVERTED TO THE SAME COMMIT OR NOTHING BELOW WOULD WORK!

For compiling u-boot sources we use arm-linux-gnueabihf-gcc 5.4.0-6 version 

You can check this with:

# arm-linux-gnueabihf-gcc --version

the result has to be:

arm-linux-gnueabihf-gcc (Debian 5.4.0-6) 5.4.0 20160609

so if something goes wrong it is better to use tested compiler version

Now you have to make a patch in order to add configuration file for A33. 

download the a33.patch using the next command:
# wget https://raw.githubusercontent.com/OLIMEX/OLINUXINO/master/SOFTWARE/A33/A33-build-3-4-39-1/a33.patch

# patch -p1 < a33.patch

load a33 configuration file

# make ARCH=arm CROSS_COMPILE=arm-linux-gnueabihf-  A33-OLinuXino_defconfig

if you want to change other board settings in u-boot you can use the following command

# make ARCH=arm CROSS_COMPILE=arm-linux-gnueabihf- menuconfig

Save and Exit

Now type the next command to compile the u-boot:

# make ARCH=arm CROSS_COMPILE=arm-linux-gnueabihf-

At the end of the process you can check if everything is OK by using:

# ls u-boot.bin u-boot-sunxi-with-spl.bin spl/sunxi-spl.bin

spl/sunxi-spl.bin  u-boot.bin  u-boot-sunxi-with-spl.bin

If you got these files everything is complete, well done so far

# cd ..

You should be in the following directory:

/home/user/a33-olimex#

-------------------------------------------

Chapter 3. Building linux kernel and modules from sources for A33-OLinuXino boards

-------------------------------------------

The kernel sources for A33 are available at GitHub. 

You can download the latest kernel sources using the following command:

# git clone https://github.com/hehopmajieh/a33_linux

Note that the our build uses this exact commit: 

ff599da01cd39f2fac67e74a2085e57afa2ee9d3  from Thu Aug 25 14:05:45 2016 +0300
 
You can switch to this exact commit with the next command:

# git reset --hard ff599da01cd39f2fac67e74a2085e57afa2ee9d3

After the download navigate to the kernel directory:

# cd  a33_linux/

---

3.3 Configuring the rest of the environment

---

First you need to set the proper compiler. For kernel sources we use gcc-linaro-arm-linux-gnueabi-2012.02-20120222 compiler 

Download it 

# wget https://launchpad.net/linaro-toolchain-binaries/trunk/2012.02/+download/gcc-linaro-arm-linux-gnueabi-2012.02-20120222_linux.tar.bz2

and untar it for example in /opt folder

# tar jxfv gcc-linaro-arm-linux-gnueabi-2012.02-20120222_linux.tar.bz2 -C /opt

set PATH environment to compiler toolchain

# export PATH=$PATH:/opt/gcc-linaro-arm-linux-gnueabi-2012.02-20120222_linux/bin/

load a33 configuration file

# make ARCH=arm CROSS_COMPILE=arm-linux-gnueabi- a33Olinuxino_defconfig

The result should be:

configuration written to .config

If you wish to make changes to the kernel configuration execute the following:

# make ARCH=arm menuconfig

The menuconfig changes a .config text file, which you can view/edit even with a text editor like vi, nano. Using this command you can add or remove different modules for the different peripherials in the kernel. Be careful when you change these settings because the kernel can stop working properly.

Now you may continue with kernel image compiling 

# make ARCH=arm CROSS_COMPILE=arm-linux-gnueabi- -j4 uImage

when this finish’s you will have uImage ready and the result should be:

The next step is building the kernel modules:

# make ARCH=arm CROSS_COMPILE=arm-linux-gnueabihf- -j4 INSTALL_MOD_PATH=out modules
# make ARCH=arm CROSS_COMPILE=arm-linux-gnueabihf- -j4 INSTALL_MOD_PATH=out modules_install

Note that in order to use onboard NAND flash you have to compile the NAND module separately. For this purpose 

# cd a33-linux/modules/nand

and make

# make ARCH=arm CROSS_COMPILE=arm-linux-gnueabi- LICHEE_KDIR=/home/user/a33_linux/

the nand.ko module should be in 

a33_linux/modules/nand/sun8iw5p1/nand.ko

copy nand.ko file in out/lib/modules/3.4.39+/kernel/drivers/

# cp modules/nand/sun8iw5p1/nand.ko  lib/modules/3.4.39+/kernel/drivers/

DONE! At this point you have uboot and kernel modules.

The uImage file is located in a33_linux/arch/arm/boot/

The kernel modules are located in linux-sunxi/out/lib/modules/3.x.xx,
where 3.x.xx is kernel version. In our case the directory with modules is:

out/lib/modules/3.4.39+/

-------------------------------------------

4. Format and setup the SD-card

-------------------------------------------

We suggest using a class 10 microSD card with memory capacity at least 8GB. We haven't tested microSD cards bigger than 16GB.

First we have to make the correct card partitions using fdisk. Plug SD card into your SD card reader and enter in the terminal:

# ls /dev/sd

Then press two times <TAB> you will see a list of your sd devices like sda sdb sdc note that some of these devices may be your hard disk so make sure you know which one is your sd card before you proceed as you can damage your HDD if you choose the wrong sd-device. You can do this by unplugging your sd card reader - pay attention which "sd" device disappears from the list.

Once you know which one is your microSD (as sda#) use it instead of the sdX name in the references below:

# fdisk /dev/sdX

then:

4.1. p

will list your partitions. If there are already partitions on your card do:

4.2. d enter 1

if you have more than one partitition press d while delete them all

4.3. create the first partition, starting from 2048

n enter p enter 1 enter enter enter

then list the created partitions:

p enter

if you did everything correctly on 2GB card you should see something like:

Command (m for help): p
Disk /dev/sdd: 1.9 GiB, 2001731584 bytes, 3909632 sectors
Units: sectors of 1 * 512 = 512 bytes
Sector size (logical/physical): 512 bytes / 512 bytes
I/O size (minimum/optimal): 512 bytes / 512 bytes
Disklabel type: dos
Disk identifier: 0x10a769e1

Device     Boot Start     End Sectors  Size Id Type
/dev/sdd1        2048 3909631 3907584  1.9G 83 Linux

4.5. press w

write changes to sd card

Now we have to format the file system on the card. For example ext4 file system. Execute the command mkfs.ext4 with these parameters. 

# mkfs.ext4 -O ^metadata_csum,^64bit /dev/sdX1

-------------------------------------------

5. Write the Uboot and u-boot-sunxi-with-spl.bin

-------------------------------------------

You should be in /home/user/a33-olimex# directory 

Note that you have to write u-boot-sunxi-with-spl.bin in /dev/sdX (not sdX1 or sdX2)

Type:

# cd u-boot

# dd if=u-boot-sunxi-with-spl.bin of=/dev/sdX bs=1024 seek=8

the result should be something like this:

422+1 records in
422+1 records out
433112 bytes (433 kB, 423 KiB) copied, 0.0952634 s, 4.5 MB/s

--------------------------------

6. Debian rootfs

--------------------------------

The Linux Kernel and Uboot are ready, now we need the Linux distribution rootfs.

Basically the only difference between the different Linux distributions is the rootfs, so if you put Debian rootfs you will have Debian, if you put Ubuntu rootfs it will be Ubuntu etc.

How to build one is a long topic, the good thing is that there are many already pre-built so we can just download one and use it ready.

Now leave the kernel directory

# cd ..

Should be in the directory below

# /home/user/a33-olimex

Download debian rootfs with the file name "a33-jessie-FS-rel1.tgz", which is available only as a torrent. You would need a torrent client for it (Azureus, uTorrent, qBittorrent, etc). The link to the torrent file is:

# wget https://github.com/OLIMEX/OLINUXINO/raw/master/SOFTWARE/A33/A33-build-3-4-39-1/a33-jessie-FS-rel1.tgz.torrent
Launch the torrent client and download the file.

Now mount the microSD card EXT4 FS partition:

# mkdir /mnt/sd
# mount /dev/sdX1 /mnt/sd

and unarchive the rootfs

# tar xzvf a33-jessie-FS-rel1.tgz -C /mnt/sd
# ls /mnt/sd

The correct result should be:
bin   dev  home  lost+found  mnt  proc  run   selinux  sys  usr
boot  etc  lib   media       opt  root  sbin  srv      tmp  var

Now you have to replace the newly generated kernel and modules from /home/user/a33-olimex/a33_linux/out/lib/modules/ to the new Debian file system:

-------------------------------------------

7. Write the kernel uImage to the SD-card

-------------------------------------------

You should be in the directory below

/home/user/a33-olimex# directory

copy the Kernel uImage to boot directory in partition 1:

# cp a33_linux/arch/arm/boot/uImage /mnt/sd/boot

Now you have to replace kernel modules

# rm -rf /mnt/sd/lib/modules/*

# cp -rfv a33_linux/out/lib/modules/3.x.xx+/ /mnt/sd/lib/modules/

where x.xx is the kernel version

replace /lib/firmware folder with the generated /linux-sunxi/out/firmware

#cp -rfv a33_linux/out/lib/firmware/ /mnt/sd/lib/

# sync

--------------------------------------

7. Write script.bin file

--------------------------------------

script.bin is a very important file with parameters like port GPIO assignments, DDR memory parameters, video resolution etc. For A33-OLinuXino you can download it using the following command

# wget https://github.com/OLIMEX/OLINUXINO/raw/master/SOFTWARE/A33/A33-build-3-4-39-1/script.bin

then copy the downloaded script.bin file to the mounted first partition of the SD card:

# cp script.bin /mnt/sd/boot
# sync
# umount /dev/sdX1

If you wish you can see the source of script.bin file from this link:

# wget https://raw.githubusercontent.com/OLIMEX/OLINUXINO/master/SOFTWARE/A33/A33-build-3-4-39-1/script.fex

At this point you have Debian on your SD card and you have an SD card ready to boot debian on A33-OLinuXino 

Connect USB-SERIAL-CABLE-F to UEXT Tx, Rx and GND. Put the SD-card apply power according to A33_OLinuXino board type. You should see u-boot and then kernel messages on the console or LCD

Under the command line interface you are automatically logged as super user (user "root", password "olimex"). However, under the graphical environment you are not auto-logged as super user and you must type "sudo" before the command (in the GUI the super-user is "olimex" and the password is "olimex").

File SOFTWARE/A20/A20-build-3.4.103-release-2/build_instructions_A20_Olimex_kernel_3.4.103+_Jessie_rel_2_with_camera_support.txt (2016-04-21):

How to make a bootable SD card for Olimex's A20-SOM, A20-OLinuXino-MICRO, A20-OLinuXino-LIME, A20-OLinuXino-LIME2 with kernel 3.4.103 and Linux Debian Jessie file system
===============================================================================================

1. Setup of the toolchain
-------------------------
You should make sure that you have the tools needed for building the Linux Kernel. You'd have to install them if you don’t have them already installed. To install new software you should be logged to a user with super user rights on your Linux machine. Type in the terminal:

$ sudo su

You will be asked for your password and then your prompt will change to # which means you are now the super user, all future commands should be run in this mode.

Next update apt-get links by typing:

# apt-get update

Next install the toolchain by typing the following:

# apt-get install gcc-4.7-arm-linux-gnueabihf ncurses-dev uboot-mkimage build-essential git

This will install: GCC compiler used to compile the kernel, the kernel config menu uboot make image which is required to allow the SD card to boot into the Linux image, Git that allows you to download from the github which holds source code for some of the system, Some other tools for building the kernel

Note that if you use debian may be you will need to add:

deb http://www.emdebian.org/debian squeeze main

in the file below:

/etc/apt/sources.list

You would also need a torrent client. It is needed to be able to download the file system. Any torrent that suits your needs would do the job, as long as it can load torrent files it is fine.

Now you have all important tools to make your very own A20 kernel image!

2. Building Uboot
-----------------

First let's make the directory where we would build the A20 Linux:

# mkdir a20-olimex
# cd a20-olimex

Then let’s download the mainline uboot sources from GitHub repository

git clone git://git.denx.de/u-boot.git

After the download you should have a new directory

# cd u-boot/

The image is tested with the commit from   Mon Oct 19 18:46:28 2015 -0400

You can switch to this commit with the next command

git reset --hard  5ec0003b19cbdf06ccd6941237cbc0d1c3468e2d

With the following commands you have to configure the uboot for the different boards, use only the make command for your board:

Note that if you use the gigabit interface (It is on A20-Lime2 and A20-SOM-EVB boards) then you need to patch the uboot in order to do on board PHY chip in master mode. 
For this purpose download fix_gigabit_phy.patch file using wget command:

# wget https://raw.githubusercontent.com/OLIMEX/OLINUXINO/master/SOFTWARE/A20/A20-build-3.4.103-release-2/fix_gigabit_phy.patch
and then patch the uboot

# patch -p1 < fix_gigabit_phy.patch

Depends on your boar type you have to do the text steps:

2.1 A20-OLinuXino_Lime2 board

# make A20-OLinuXino-Lime2_defconfig  ARCH=arm CROSS_COMPILE=arm-linux-gnueabihf-

from the menu select 
ARM architecture --> 
select 
[*] Enable workarounds for booting old kernels  
ESC ESC
Save and exit

2.2 A20-SOM board

Note that there is 2 different types of A20-SOM boards. 
The main differences are in DDR3 memory bus speed. 
A20-SOM up to rev.B  - DDR3 memory bus speed is 384MHz(6 layer PCB)
A20-SOM after rev.D - DDR3 memory bus speed is 480MHz(8 layer PCB)

2.2.1 For A20-SOM up to rev.B type 

# make A20-Olimex-SOM-EVB_defconfig  ARCH=arm CROSS_COMPILE=arm-linux-gnueabihf-
or use A20-OLinuXino-Lime2_defconfig for older u-boot commit
# make A20-OLinuXino-Lime2_defconfig  ARCH=arm CROSS_COMPILE=arm-linux-gnueabihf-
# make ARCH=arm menuconfig

from the menu select 
ARM architecture --> 
	-> sunxi DRAM clock speed
and change 480 to 384

select 
[*] Enable workarounds for booting old kernels  

ESC ESC
Save and exit

2.2.2 For A20-SOM after rev.D 

# make A20-Olimex-SOM-EVB_defconfig  ARCH=arm CROSS_COMPILE=arm-linux-gnueabihf-
or use A20-OLinuXino-Lime2_defconfig for older u-boot commit
# make A20-OLinuXino-Lime2_defconfig  ARCH=arm CROSS_COMPILE=arm-linux-gnueabihf-
# make ARCH=arm menuconfig

from the menu select 
ARM architecture --> 
select 
[*] Enable workarounds for booting old kernels  
ESC ESC
Save and exit

2.3 A20-OLinuXino-MICRO board

# make A20-OLinuXino_MICRO_defconfig  ARCH=arm CROSS_COMPILE=arm-linux-gnueabihf-
# make ARCH=arm menuconfig

from the menu select 
ARM architecture --> 
select 
[*] Enable workarounds for booting old kernels  
ESC ESC
Save and exit

2.4 A20-OLinuXino-LIME board

# make A20-OLinuXino-Lime_defconfig  ARCH=arm CROSS_COMPILE=arm-linux-gnueabihf-
# make ARCH=arm menuconfig

from the menu select 
ARM architecture --> 
select 
[*] Enable workarounds for booting old kernels  
ESC ESC
Save and exit

Now type the following command for u-boot building

# make ARCH=arm CROSS_COMPILE=arm-linux-gnueabihf-

At the end of the process you can check if everything is OK by

# ls u-boot.bin u-boot-sunxi-with-spl.bin spl/sunxi-spl.bin

spl/sunxi-spl.bin  u-boot.bin  u-boot-sunxi-with-spl.bin

If you got these files everything is complete, well done so far

# cd ..

You should be in the following directory:

/home/user/a20-olimex#

3. Building kernel sources for A20 boards
----------------------------------------------

Kernel sources for A20 are available on GitHub. Note that the following building is made with the revision below: 

commit 9a1cd034181af628d4145202289e1993c1687db6

from  Sat Oct 4 07:59:35 2014 +0300

You can download the kernel sources using the following command:

# git clone https://github.com/linux-sunxi/linux-sunxi

You can switch to this commit with the next command

git reset --hard  9a1cd034181af628d4145202289e1993c1687db6

After the download go to the kernel directory:

# cd linux-sunxi/

3.3 configure the system 

Here you need from a20 configuration file – A20-linux-3.4.103_defconfig . The file contains all kernel module settings.

Download A20-linux-3.4.103_defconfig  using wget command 

# wget https://raw.githubusercontent.com/OLIMEX/OLINUXINO/master/SOFTWARE/A20/A20-build-3.4.103-release-2/A20-linux-3.4.103_defconfig

then copy A20-linux-3.4.103_defconfig file to configs directory:

# cp A20-linux-3.4.103_defconfig  arch/arm/configs/

and make:

# make ARCH=arm A20-linux-3.4.103_defconfig 

The result should be:

configuration written to .config

If you wish to make your changes in the kernel configuration do:

# make ARCH=arm menuconfig
The menuconfig changes a .config text file, which you can view/edit even with a text editor like vi,nano.
With this command you can add or remove different modules for the different peripherials in the kernel. 
Be careful when you change these settings because the kernel can stop working properly.

If the board there is emmc then you have to do a patch that fix the problem with HighPriorityInterrupt related with emmc support 

Download the patch file a20-emmc.patch using wget command

# wget https://raw.githubusercontent.com/OLIMEX/OLINUXINO/master/SOFTWARE/A20/A20-build-3.4.103-release-2/a20-emmc.patch

and patch to drivers/mmc/core/mmc.c file

# patch -p1 < a20-emmc.patch

Now you can continue with kernel image compiling 

# make ARCH=arm CROSS_COMPILE=arm-linux-gnueabihf- -j4 uImage

when this finish’s you will have uImage ready and the result should be:

  LD      arch/arm/boot/compressed/vmlinux
  OBJCOPY arch/arm/boot/zImage
  Kernel: arch/arm/boot/zImage is ready
  UIMAGE  arch/arm/boot/uImage
Image Name:   Linux-3.4.103-00033-g9a1cd03-dir
Created:      Mon Nov  2 09:29:54 2015
Image Type:   ARM Linux Kernel Image (uncompressed)
Data Size:    4581208 Bytes = 4473.84 kB = 4.37 MB
Load Address: 40008000
Entry Point:  40008000
  Image arch/arm/boot/uImage is ready

The next step is kernel modules building:

# make ARCH=arm CROSS_COMPILE=arm-linux-gnueabihf- -j4 INSTALL_MOD_PATH=out modules
# make ARCH=arm CROSS_COMPILE=arm-linux-gnueabihf- -j4 INSTALL_MOD_PATH=out modules_install

DONE! At this point you have uboot and kernel modules.

The uImage file is located in linux-sunxi/arch/arm/boot/

The kernel modules are located in

linux-sunxi/out/lib/modules/3.x.xx

where 3.x.xx is kernel version. In our case the directory with modules is:

linux-sunxi/out/lib/modules/3.4.103

4. Format and setup the SD-card
--------------------------------
We suggest class 10 microSD card with memory capacity greater than 2GB. We haven't tested microSD cards bigger than 16GB.

First we have to make the correct card partitions, this is done with fdisk.

Plug SD card into your SD card reader and enter in the terminal

# ls /dev/sd
Then press two times <TAB> you will see a list of your sd devices like sda sdb sdc note that some of these devices may be your hard disk so make sure you know which one is your sd card before you proceed as you can damage your HDD if you choose the wrong sd-device. 
You can do this by unplugging your sd card reader - pay attention which "sd" device disappears from the list.

Once you know which one is your microSD (as sda#) use it instead of the sdX name in the references below:

# fdisk /dev/sdX

then:

4.1. p

will list your partitions. If there are already partitions on your card do:

4.2. d enter 1

if you have more than one partitition press d while delete them all

4.3. create the first partition, starting from 2048

n enter p enter 1 enter enter +16M

4.4. create second partition

n enter p enter 2 enter enter enter

then list the created partitions:

p enter

if you did everything correctly on 4GB card you should see something like:

Disk /dev/sdg: 3980 MB, 3980394496 bytes
123 heads, 62 sectors/track, 1019 cylinders, total 7774208 sectors
Units = sectors of 1 * 512 = 512 bytes
Sector size (logical/physical): 512 bytes / 512 bytes
I/O size (minimum/optimal): 512 bytes / 512 bytes
Disk identifier: 0x00000000

   Device Boot      Start         End      Blocks   Id  System
/dev/sdg1            2048       34815       16384   83  Linux
/dev/sdg2           34816     7774207     3869696   83  Linux

4.5. press w

write changes to sd card

Now we have to format the file system on the card (the first partition should be vfat as this is FS which the Allwinner bootloader understands):

# mkfs.vfat /dev/sdX1

The second should be normal Linux EXT3 FS:

# mkfs.ext3 /dev/sdX2

5. Write the Uboot and u-boot-sunxi-with-spl.bin
-------------------------------------
You should be in /home/user/a20-olimex# directory 

Note that you have to write u-boot-sunxi-with-spl.bin in /dev/sdX (not sdX1 or sdX2)

Type:

# dd if=u-boot/u-boot-sunxi-with-spl.bin of=/dev/sdX bs=1024 seek=8

6. Write kernel uImage you build to the SD-card
-----------------------------------------------
You should be in the directory below

/home/user/a20-olimex# directory 
# mkdir /mnt/sd
# mount /dev/sdX1 /mnt/sd
copy the Kernel uImage to root directory in partition 1

# cp linux-sunxi/arch/arm/boot/uImage /mnt/sd

7. Write script.bin file
-------------------------
script.bin is a file with very important configuration parameters like port GPIO assignments, DDR memory parameters, Video resolution etc, 
According to the A20 board you use you have to download and write different script.bin file.

7.1.1 for A20-OLinuXino_Lime2 board with NAND support download the script.bin file using wget command
# wget -O script.bin https://github.com/OLIMEX/OLINUXINO/blob/master/SOFTWARE/A20/A20-build-3.4.103-release-2/scripts/script_a20_Lime2_NAND_rel_2/script.bin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

7.1.2 for A20-OLinuXino_Lime2 board with EMMC support download the script.bin file using wget command
# wget -O script.bin https://github.com/OLIMEX/OLINUXINO/blob/master/SOFTWARE/A20/A20-build-3.4.103-release-2/scripts/script_a20_lime2_emmc/script.bin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

7.2 for A20-SOM board download the script.bin file using wget command
# wget -O script.bin https://github.com/OLIMEX/OLINUXINO/blob/master/SOFTWARE/A20/A20-build-3.4.103-release-2/scripts/script_a20-SOM_rel_3/script_a20_SOM_HDMI_720p50/script.bin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

7.3 for A20-OLinuXino-MICRO board download the script.bin file using wget command
# wget -O script.bin https://github.com/OLIMEX/OLINUXINO/blob/master/SOFTWARE/A20/A20-build-3.4.103-release-2/scripts/script_a20_OLinuXino-micro_rel_10/script.bin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

7.4 for A20-OLinuXino-LIME board download the script.bin file using wget command
# wget -O script.bin https://github.com/OLIMEX/OLINUXINO/blob/master/SOFTWARE/A20/A20-build-3.4.103-release-2/scripts/script_a20_lime_rel_3/script.bin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

then copy the downloaded script.bin file to the mounted first partition of the SD card
# cp script.bin /mnt/sd

Download boot.scr and uEnv.txt files

#wget -O boot.scr https://github.com/OLIMEX/OLINUXINO/blob/master/SOFTWARE/A20/A20-build-3.4.103-release-2/boot.scr?raw=true
#wget -O uEnv.txt https://github.com/OLIMEX/OLINUXINO/blob/master/SOFTWARE/A20/A20-build-3.4.103-release-2/uEnv.txt?raw=true

You have to copy in first sd card partition where script.bin file is located
# cp boot.scr /mnt/sd
# cp uEnv.txt /mnt/sd
# sync
# umount /dev/sdX1

8. Debian rootfs
----------------
The Linux Kernel and Uboot are ready, now we have need from Linux distribution rootfs.

Basically the only difference between the different Linux distributions is the rootfs, so if you put Debian rootfs you will have Debian, if you put Ubuntu rootfs it will be Ubuntu etc.

How to build one is a long topic, the good thing is that there are many already pre-built so we can just download one and use it ready.

Now leave the kernel directory

# cd ..

Should be in the directory below

# /home/user/a20-olimex

Download debian rootfs with the file name "Debian_FS_34_103_Jessy_8.1_A20-olimex_rel_2" , which is available only as a torrent. You would need a torrent client for it (Azureus, uTorrent, qBittorrent, etc). The link to the torrent file is:

# wget https://www.olimex.com/wiki/images/a/a4/Debian_FS_34_103_Jessy_8.1_A20-olimex_rel_2.torrent

Now mount the microSD card EXT3 FS partition:

# mount /dev/sdX2 /mnt/sd

and unarchive the rootfs

# tar xzvf Debian_FS_34_103_Jessy_8.1_A20-olimex_rel_2 -C /mnt/sd
# ls /mnt/sd

The correct result should be:
bin   dev  home  lost+found  mnt  proc  run   selinux  sys  usr
boot  etc  lib   media       opt  root  sbin  srv      tmp  var

Now you have to replace the new generated kernel modules from /home/user/a20-olimex/linux-sunxi/out/lib/modules/ to the new Debian file system:

# rm -rf /mnt/sd/lib/modules/*

# cp -rfv linux-sunxi/out/lib/modules/3.x.xx+/ /mnt/sd/lib/modules/

where x.xx is the kernel version

in our case:

# cp -rfv linux-sunxi/out/lib/modules/3.4.103/ /mnt/sd/lib/modules/

replace /lib/firmware folder with the generated /linux-sunxi/out/firmware

#cp -rfv linux-sunxi/out/lib/firmware/ /mnt/sd/lib/

# sync
# umount /mnt/sdX2

at this point you have Debian on your SD card second partition and you have an SD card ready to boot debian on A20-SOM or A20-OLinuXino-MICRO or A20-OLinuXino-LIME or A20-OLinuXino-LIME2

Connect USB-SERIAL-CABLE-F to UEXT Tx, Rx and GND, or connect a HDMI screen. Put the SD-card apply power according to A20 board type.You should see Uboot and then Kernel messages on the console

default username/password is : root / olimex

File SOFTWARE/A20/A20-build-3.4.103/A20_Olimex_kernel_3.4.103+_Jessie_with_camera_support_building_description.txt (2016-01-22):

How to make a bootable SD card for Olimex's A20-SOM, A20-OLinuXino-MICRO, A20-OLinuXino-LIME, A20-OLinuXino-LIME2 with kernel 3.4.103 and Linux Debian file system
===============================================================================================

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

$ sudo su

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

Next update apt-get links by typing:

# apt-get update

Next install the toolchain by typing the following:

# apt-get install gcc-4.7-arm-linux-gnueabihf ncurses-dev uboot-mkimage build-essential git

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

Note that if you use debian may be you will need to add:

deb http://www.emdebian.org/debian squeeze main

in the file below:

/etc/apt/sources.list

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

Now you have all important tools to make your very own A20 kernel image!

2. Building Uboot
-----------------

First let's make the directory where we would build the A20 Linux:

# mkdir a20-olimex
# cd a20-olimex

Then let’s download the mainline uboot sources from GitHub repository

git clone git://git.denx.de/u-boot.git

After the download you should have a new directory

# cd u-boot/

The image is tested with the commit from Fri Jul 24 16:55:29 2015
You can switch to this commit with the next command

git reset --hard  e2c1c5bae619d2e87505de99f907a26237640bc9

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

2.1 A20-OLinuXino_Lime2 board

# make A20-OLinuXino-Lime2_defconfig  ARCH=arm CROSS_COMPILE=arm-linux-gnueabihf-

2.2 A20-SOM board

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

from the menu select 
ARM architecture --> 
	-> sunxi DRAM clock speed
and change 480 to 384

select 
[*] Enable workarounds for booting old kernels  

ESC ESC
Save and exit

2.2.2 For A20-SOM after rev.D 

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

2.3 A20-OLinuXino-MICRO board

# make A20-OLinuXino_MICRO_defconfig  ARCH=arm CROSS_COMPILE=arm-linux-gnueabihf-
# make ARCH=arm menuconfig

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

2.4 A20-OLinuXino-LIME board

# make A20-OLinuXino-Lime_defconfig  ARCH=arm CROSS_COMPILE=arm-linux-gnueabihf-
# make ARCH=arm menuconfig

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

Now type the following command for u-boot building

# make ARCH=arm CROSS_COMPILE=arm-linux-gnueabihf-

At the end of the process you can check if everything is OK by

# ls u-boot.bin u-boot-sunxi-with-spl.bin spl/sunxi-spl.bin

spl/sunxi-spl.bin  u-boot.bin  u-boot-sunxi-with-spl.bin

If you got these files everything is complete, well done so far

# cd ..

You should be in the following directory:

/home/user/a20-olimex#

3. Building kernel sources for A20 boards
----------------------------------------------

Kernel sources for A20 are available on GitHub. Note that the following building is made with the commit ID of the sources:

9a1cd034181af628d4145202289e1993c1687db6

You can download the kernel sources using the following command:

# git clone https://github.com/linux-sunxi/linux-sunxi

You can switch to the specific commit mentioned above with the following command:

git reset --hard  9a1cd034181af628d4145202289e1993c1687db6

After the download go to the kernel directory:

# cd linux-sunxi/

3.3 configure the system 

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

Download A20-linux-3.4.103_defconfig  using wget command 

# wget https://github.com/OLIMEX/OLINUXINO/blob/master/SOFTWARE/A20/A20-build-3.4.103/A20-linux-3.4.103_defconfig

then copy A20-linux-3.4.103_defconfig file to configs directory:

# cp A20-linux-3.4.103_defconfig  arch/arm/configs/

and make:

# make ARCH=arm A20-linux-3.4.103_defconfig 

The result should be:

configuration written to .config

If you wish to make your changes in the kernel configuration do:

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

Now you can continue with kernel image compiling 

# make ARCH=arm CROSS_COMPILE=arm-linux-gnueabihf- -j4 uImage

when this finish’s you will have uImage ready and the result should be:

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

The next step is kernel modules building:

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

DONE! At this point you have uboot and kernel modules.

The uImage file is located in linux-sunxi/arch/arm/boot/

The kernel modules are located in

linux-sunxi/out/lib/modules/3.x.xx

where 3.x.xx is kernel version. In our case the directory with modules is:

linux-sunxi/out/lib/modules/3.4.103

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

First we have to make the correct card partitions, this is done with fdisk.

Plug SD card into your SD card reader and enter in the terminal

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

# fdisk /dev/sdX

then:

4.1. p

will list your partitions. If there are already partitions on your card do:

4.2. d enter 1

if you have more than one partitition press d while delete them all

4.3. create the first partition, starting from 2048

n enter p enter 1 enter enter +16M

4.4. create second partition

n enter p enter 2 enter enter enter

then list the created partitions:

p enter

if you did everything correctly on 4GB card you should see something like:

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

4.5. press w

write changes to sd card

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

# mkfs.vfat /dev/sdX1

The second should be normal Linux EXT3 FS:

# mkfs.ext3 /dev/sdX2

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

Type:

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

# cp linux-sunxi/arch/arm/boot/uImage /mnt/sd

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

7.1 for A20-OLinuXino_Lime2 board download the script.bin file using wget command
# wget https://github.com/OLIMEX/OLINUXINO/raw/master/SOFTWARE/A20/A20-build-3.4.103/script_a20_Lime2_rel_2/script.bin

7.2 for A20-SOM board download the script.bin file using wget command
# wget https://github.com/OLIMEX/OLINUXINO/raw/master/SOFTWARE/A20/A20-build-3.4.103/script_a20-SOM_rel_3/script_a20_SOM_HDMI_720p50/script.bin

7.3 for A20-OLinuXino-MICRO board download the script.bin file using wget command
# wget  https://github.com/OLIMEX/OLINUXINO/raw/master/SOFTWARE/A20/A20-build-3.4.103/script_a20_OLinuXino-micro_rel_10/script.bin

7.4 for A20-OLinuXino-LIME board download the script.bin file using wget command
# wget  https://github.com/OLIMEX/OLINUXINO/raw/master/SOFTWARE/A20/A20-build-3.4.103/script_a20_lime_rel_3/script.bin

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

Download boot.scr and uEnv.txt files

#wget   https://github.com/OLIMEX/OLINUXINO/raw/master/SOFTWARE/A20/A20-build-3.4.103/boot.scr
#wget   https://github.com/OLIMEX/OLINUXINO/raw/master/SOFTWARE/A20/A20-build-3.4.103/uEnv.txt

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

Now leave the kernel directory

# cd ..

Should be in the directory below

# /home/user/a20-olimex

Download debian rootfs with the file name "debian_FS_34_103_Jessie_8.1_A20-olimex.tgz" , which is available only as a torrent. You would need a torrent client for it (Azureus, uTorrent, qBittorrent, etc). The link to the torrent file is:

# wget https://www.olimex.com/wiki/images/c/c6/Debian_FS_34_103_Jessie_8.1_A20-olimex.torrent

Now mount the microSD card EXT3 FS partition:

# mount /dev/sdX2 /mnt/sd

and unarchive the rootfs

# tar xzvf debian_FS_34_103_Jessie_8.1_A20-olimex.tgz -C /mnt/sd
# ls /mnt/sd

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

# rm -rf /mnt/sd/lib/modules/*

# cp -rfv linux-sunxi/out/lib/modules/3.x.xx+/ /mnt/sd/lib/modules/

where x.xx is the kernel version

in our case:

# cp -rfv linux-sunxi/out/lib/modules/3.4.103/ /mnt/sd/lib/modules/

replace /lib/firmware folder with the generated /linux-sunxi/out/firmware

#cp -rfv linux-sunxi/out/lib/firmware/ /mnt/sd/lib/

# sync
# umount /mnt/sdX2

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

default username/password is : root / olimex

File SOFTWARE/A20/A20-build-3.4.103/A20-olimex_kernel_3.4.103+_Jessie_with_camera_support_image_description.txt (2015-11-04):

Official Images from OLIMEX for A20-SOM, A20-OLinuXino-MICRO, A20-OLinuXino-LIME, A20-OLinuXino-LIME2 boards

Note: the SD card images for A20 boards which we have on our webshop contain same image on 8GB Class10 fast micro sd-card, 
if you want to use this image please use Class10 fast card or the performance of Linux will slow down
The image is Debian Jessie linux with kernel 3.4.103+ . 
Default login/password: root/olimex

Note that below with XXX is marked the type of Olimex's A20 board, i.e. according the board you use XXX can be OLinuXino_Micro, Lime2, SOM or Lime.
Y in image file name is the number of image revision. 

The file a20-XXX_debian_Jessie_34_103_2G_release_Y.img.7z is an archive of
a20-XXX_debian_Jessie_34_103_2G_release_Y.img file. 
So in order to write the image on SD card you have to unzip a20-XXX_debian_Jessie_34_103_2G_release_Y.img.7z file:
1.1 for Windows
----------------
Use 7zip and then use Win32DiskImager.exe (http://sourceforge.net/projects/win32diskimager/) for image writing

1.2 for linux
-------------
Use p7zip package. If you have no installed 7zip then type 
#apt-get install p7zip
Copy a20-XXX_debian_Jessie_34_103_2G_release_Y.img.7z file in your directory and unzip it with 
#7za e a20-XXX_debian_Jessie_34_103_2G_release_Y.img.7z
The output should be a new 2GB file named a20-XXX_debian_Jessie_34_103_2G_release_Y.img.
Put 2,4,8,16 GB SD card in your card reader and type
# ls /dev/sd
Then press two times <TAB> you will see a list of your sd devices like sda sdb sdc note that some of these devices may be your hard disk so 
make sure you know which one is your sd card before you proceed as you can damage your HDD if you choose the wrong sd-device. 
You can do this by unplugging your sd card reader and identify which "sd" devices remove from the list.
Once you know which device is your sdcard like sda use this text instead of the sdX name in the references below:

#dd if=a20-XXX_debian_Jessie_34_103_2G_release_Y.img of=/dev/sdX

Note that the image is 2GB and if you write it on bigger SD card it is reccomended to resize it in order to use all SD card space
From root directory start resize_sd.sh script with the following parameters

# ./resize_sd.sh /dev/mmcblk0 2

The list of all installed packages is located in debian_jessie_installed_packages.txt file

The main tested onboard hardware modules are:

- GPIO	-	they are located in /sys/class/gpio directory. Note that first you have to export GPIOs. For example:
# for i in `seq 1 1 230`; do echo $i > /sys/class/gpio/export; done
will export all available GPIOs
# echo out > /sys/class/gpio/gpioXX_pxx/direction
will make the port output
# echo 1 > /sys/class/gpio/gpioXX_pXX/value
will make the port output in logical 1
- LCD		-	4.3''(480x272), 7''(800x480), 10''(1024x600), 15''(1366x768), 15''(1080x1920)
- SATA	-	with power on/off control and battery support
- HDMI	-	the default HDMI resolution is 720p50(720x1280 - 50 Hz)
- Touch_screen	-	you need calibrate LCD before using touch screen. Use X environment to do that. 
Lounch Calibrate Touchscreen application from Preferences menu(press the button in down left corner)
In order to save calibration data it is better to copy values from the window that appears after calibrations to Option "Calibration" section 
in  /usr/share/X11/xorg.conf.d/10-evdev.conf file
It is something like 
Option "Calibration" "3999 66 198 3938"
For example use 
# nano /usr/share/X11/xorg.conf.d/10-evdev.conf

- ASIX8877 USB-LAN	-	https://www.olimex.com/Products/OLinuXino/A13/USB-ETHERNET-AX88772B/. Usually it is eth1 interface
- USB WEB camera A4TECH
- WIFI_RTL8188	-	https://www.olimex.com/Products/Modules/Ethernet/MOD-WIFI-RTL8188/. Note that you have to set your SSID network and your password in /etc/network/interfaces file
- MOD-WIFI-R5370	-	https://www.olimex.com/Products/USB-Modules/MOD-WIFI-R5370. Note that you have to set your SSID network and your password in /etc/network/interfaces file
- USB_OTG		-	low/full/high USB host 
Note that you can use USB_OTG for SSH connection without need of LAN cable or serial cable. You can use only mini USB cable connected between your host PC
and the onboard mini USB connector. For connection convenience there is started a DHCP server only for USB0 interface. So the DHCP server should give IP address
to the new USB0 interface of your host PC and you can make SSH connection from your PC to the default board IP address of USB0 interface - 192.168.2.1
- USB_HOST_up		-	low/full/high USB host
- USB_HOST_down	-	low/full/high USB host
- MOD-USB3G	-	https://www.olimex.com/Products/USB-Modules/MOD-USB3G/. In order to test MOD-USB3G module you have to place SIM card(without pin code) in module 
and connect it to USB host connector, change settings in /etc/wvdial.conf file according to your mobile operator and type:
# wvdial 3gconnect
- mico_SD_card	- linux starts from micro_SD card
- second_SD_card	-	with card present capability 
- ETHERNET	-	100Mb/1000Mb. By default the board IP address is 192.168.1.254. So if you want to connect with the board using SSH client 
(for example Putty(http://www.chiark.greenend.org.uk/~sgtatham/putty/download.html)) then you have to use this address. 
You can change this address from /etc/network/interface file. 
Note that for internet connection you have to set your gateway address in /etc/network/interdaces file and 
you have to set your DNS server in /etc/resolv.conf(for example nameserver 192.168.1.1)
- MIC IN	-	for example:
# arecord -f dat -r 60000 -D hw:0,0 -d 5 test.wav
this command will record 5 sec audio stream from microphone in test.wav file 
- Headphone OUT	-	for example
# aplay -D hw:0,0 test.wav
this command will play the audio stream from test.wav file
- NAND support	-	/dev/nandX
- I2C2(100KHz)	-	/dev/i2c-2
- I2C1(100KHz)	-	/dev/i2c-1
- UART4(only for A20-Lime and A20-Lime2)	-	/dev/ttyS1
- UART6(only for A20-SOM, A20-OLinuXino-MICRO)	-	/dev/ttyS1
- UART7(only for A20-SOM, A20-OLinuXino-MICRO)	-	/dev/ttyS2
- SPI1((only for A20-SOM, A20-OLinuXino-MICRO))	-	/dev/spidev1.0
- SPI2	-	/dev/spidev2.0
there is a simple test for SPI2 in /opt/spidev directory. 
# ls /opt/spidev
max6675/
in folder max6675/ there is example related with MOD-TC(https://www.olimex.com/Products/Modules/Sensors/MOD-TC/open-source-hardware) - temperature sensor that you have to connect to UEXT1 connector
# cd max6675
# ./MAX6675
the last command will read temperature from MOD-TC thermocouple
- BUTTONs	- we use evtest package for testing. For example:
# evtest
then enter event number for keyboard and now you can press the BUTTONs and you should see the result on terminal window
- on board camera support (only for A20-SOM-EVB)
You can do a simple camera test if you paste the next command 
# mplayer -fps 60  -tv driver=v4l2:width=640:height=480:device=/dev/video0 tv:// 
and see camera stream to fremebufer output you set - HDMI, VGA or LCD
- USB Gadjetsls 
You can use mini USB connector to connect with the board via SSH. 
Note that USB0 interface IP address by default  is 192.168.2.1 Therefore the host IP address has to be in this network - 192.168.2.xxx(except 192.168.2.1)
Use login:olimex and password:olimex to connect with the board.
- Nand
If you want to use NAND flash memory istead of SD card you can transfer the current image from the SD card to NAND flash. So you can use boot linux only from NAND without using SD card
For this purpose type 
# nandistall

Be pation. This operation will take around 10 min

Changing A20-XXX  HDMI, LCD or VGA resolution 
---------------------------------------------------
The default SD card setup is made with settings for HDMI 720p/50Hz. If you want to change some other LCD, VGA or HDMI resolution then you have to start 
change_display_a20_olimex.sh script file in /root directory.
Type:
#  change_display.sh

and choose the desired resolution of desired interface(LCD, HDMI or VGA)
The supported resolution are:

About LCD:
1. 4.3''(480x272)
2. 7''(800x480)
3. 10''(1024x600)
4. 15.6''(1366x768)
5. 15.6''-FHD(1920x1080)

- About 15.6 and 15.6-FHD LCD you can control backlight and DCR(Dinamic Contrast Ratio) using a soft pwm module. The main goal is to decrease power consumption. For example 
# echo 50 > /sys/class/softpwm/backlight/duty
will decrease the LCD backlight to 50%
the parameter for duty is between 0 and 100
# echo 10 > /sys/class/softpwm/duty
will decrease the LCD contrast
the parameter 10 for duty is between 0 and 100 

- About 4.3'', 7'' and 10'' LCD  you can control only backlight a hardware pwm module. The main goal is to decrease power consumption. For example 
# echo 50 > /sys/class/pwm-sunxi/pwm0/duty_percent
will decrease the LCD backlight to 50%
the parameter for duty_percent is between 0 and 100

About HDMI:
0. 480i
1. 576i
2. 480p
3. 576p
4. 720p50
5. 720p60
6. 1080i50
7. 1080i60
8. 1080p24
9. 1080p50
10. 1080p60

About VGA: note that the VGA signals are routed to custom 6 pin connector and you need from adapter to standart VGA connector
0. 1680x1050
1. 1440x900
2. 1360x768
3. 1280x1024
4. 1024x768
5. 800x600
6. 640x480
7. 1920x1080
8. 1280x720 

Changing script.bin file
========================
Note that you have to be very carefull with script.bin changing because the system can stop working. It is recommeded to make backup of script.bin file before change it.

If you want to convert script.bin file from sdcard to script.fex file first you have to mount the first sdcard patition 
# mount  /dev/mmcblk0p1 /mnt
use bin2fex script to convert and script.bin to script.fex
# bin2fex /mnt/script.bin script.fex
Now you can change the board modules and parameters, save the changes and exit from nano editor
# nano script.fex
save and exit
now you have to convert script.fex to script.bin and replace it
# fex2bin script.fex /mnt/script.bin
and reboot 
# reboot

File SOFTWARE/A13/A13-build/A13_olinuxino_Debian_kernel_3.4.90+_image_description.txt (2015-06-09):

Official Images from OLIMEX for A13-OLinuXino boards

Note: the A13-OLinuXino card which we have on our webshop contain same image on 4GB Class10 fast micro sd-card, 
if you want to use this image please use Class10 fast card or the performance of Linux will slow down
The image is Debian linux with kernel 3.4.90+ . 
Default login/password: root/olimex

The file A13_debian_34_90_WIFI_RALINK_GCC_GPIO_X_I2C_100KHz_UVC_TS_FTDI_3G_video_accell_release_10.7z is an archive of
A13_debian_34_90_WIFI_RALINK_GCC_GPIO_X_I2C_100KHz_UVC_TS_FTDI_3G_video_accell_release_10.img file. 
So in order to write the image on SD card you have to unzip A13_debian_34_90_WIFI_RALINK_GCC_GPIO_X_I2C_100KHz_UVC_TS_FTDI_3G_video_accell_release_10.7z file:
1.1 for Windows
----------------
Use 7zip and then use Win32DiskImager.exe (http://sourceforge.net/projects/win32diskimager/) for image writing

1.2 for linux
-------------
Use p7zip package. If you have no installed 7zip then type 
#apt-get install p7zip
Copy A13_debian_34_90_WIFI_RALINK_GCC_GPIO_X_I2C_100KHz_UVC_TS_FTDI_3G_video_accell_release_10.7z file in your directory and unzip it with 
#7za e A13_debian_34_90_WIFI_RALINK_GCC_GPIO_X_I2C_100KHz_UVC_TS_FTDI_3G_video_accell_release_10.7z
The output should be a new 4GB file named A13_debian_34_90_WIFI_RALINK_GCC_GPIO_X_I2C_100KHz_UVC_TS_FTDI_3G_video_accell_release_10.img
Put 4GB SD card in your card reader and type
# ls /dev/sd
Then press two times <TAB> you will see a list of your sd devices like sda sdb sdc note that some of these devices may be your hard disk so make sure you know which one is your sd card before you proceed as you can damage your HDD if you choose the wrong sd-device. You can do this by unplugging your sd card reader and identify which "sd" devices remove from the list.
Once you know which device is your sdcard like sda use this text instead of the sdX name in the references below:
#dd if=A13_debian_34_90_WIFI_RALINK_GCC_GPIO_X_I2C_100KHz_UVC_TS_FTDI_3G_video_accell_release_10.img of=/dev/sdX

The main installed packages are listed below:

LXDE desktop environment
smplayer
gcc-4.6
dpkg
git
i2c-tools
perl
xorg
python 2.7
midori
minicom
usb-modeswitch
sshfs
wvdial

The list of all installed packages is located in a13_34_90_installed_packages.txt file

The main tested onboard hardware modules are:

GPIO	-	they are located in /sys/class/gpio directory. Note that first you have to export GPIOs. For example:
# for i in `seq 1 1 230`; do echo $i > /sys/class/gpio/export; done
will export all available GPIOs
# echo out > /sys/class/gpio/gpioXX_pxx/direction
will make the port output
# echo 1 > /sys/class/gpio/gpioXX_pXX/value
will make the port output in logical 1
LCD	 -	4.3''(480x272), 7''(800x480), 10''(1024x600)
Touch_screen	-	you need calibrate LCD before using touch screen. Note that if you want to use touch screen in X environment then you have to calibrate it like olimex user, 
not like root user because X environment is started like olimex user. For example type:
# su olimex
# sudo ts_calibrate 
calibrate the touch screen and reboot the board
ASIX8877 USB-LAN	-	https://www.olimex.com/Products/OLinuXino/A13/USB-ETHERNET-AX88772B/
WEB camera A4TECH
WIFI_RTL8188	-	https://www.olimex.com/Products/Modules/Ethernet/MOD-WIFI-RTL8188/
MOD-WIFI-R5370	-	https://www.olimex.com/Products/USB-Modules/MOD-WIFI-R5370
USB_OTG	 -	low/full/high USB host
MOD-USB3G	-	https://www.olimex.com/Products/USB-Modules/MOD-USB3G/
in order to test MOD-USB3G module you have to place SIM card(without pin code) in module and connect it to USB host connector 
change settings in /etc/wvdial.conf file according to your mobile operator and type:
# wvdial 3gconnect
mico_SD_card	- linux starts from micro_SD card
NAND support	-	/dev/nandX
I2C2(100KHz)	-	/dev/i2c-2
I2C1(100KHz)	-	/dev/i2c-1
UART3	-	/dev/ttyS1
SPI2	-	/dev/spidev2.0
there is a simple test for SPI2 in /opt/spidev directory. 
# ls /opt/spidev
max6675/
in folder max6675/ there is example related with MOD-TC(https://www.olimex.com/Products/Modules/Sensors/MOD-TC/open-source-hardware) - temperature sensor that you have to connect to UEXT1 connector
# cd max6675
# ./MAX6675
the last command will read temperature from MOD-TC thermocouple
BUTTONs	- we use evtest package for testing. For example:
# evtest
and use X number from eventX
/dev/input/eventX:      sun4i-keyboard
then enter X for event number and now you can press the BUTTONs and you should see the result on terminal window

Changing A13-OLinuxino LCD and VGA resolution 
---------------------------------------------------
The default SD card setup is made with settings for LCD 7''(800x480). If you want to change some other LCD or VGA resolution then you have to start change_display_a13.sh script file in /root directory.
Type:
# ./change_display_a13.sh

and choose the desired resolution of desired interface(LCD, HDMI or VGA)
The supported resolution are:

About LCD:
1. 4.3''(480x272)
2. 7''(800x480)
3. 10''(1024x600)

about VGA:
1. 800x600
2. 1024x768

Changing script.bin file
========================
Note that you have to be very carefull with script.bin changing because the system can stop working. It is recommeded to make backup of script.bin file before change it.
the tools for script.bin changing are located in /opt/sunxi-tools directory
# cd /opt/sunxi-tools
# ./chscr.sh
this will convert script.bin file from sdcard to script.fex file and the file  will be opened using nano editor. 
Now you can change the board modules and parameters, save the changes and exit from nano editor
# ./wrscr.sh
this will convert script.fex to script.bin and the script.bin file will be written to sdcard

default user/password is root/olimex

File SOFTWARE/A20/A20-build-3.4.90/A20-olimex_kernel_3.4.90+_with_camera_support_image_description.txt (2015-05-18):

Official Images from OLIMEX for A20-SOM, A20-OLinuXino-MICRO, A20-OLinuXino-LIME, A20-OLinuXino-LIME2 boards

Note: the SD card images for A20 boards which we have on our webshop contain same image on 8GB Class10 fast micro sd-card, 
if you want to use this image please use Class10 fast card or the performance of Linux will slow down
The image is Debian linux with kernel 3.4.90+ . 
Default login/password: root/olimex

Note that below with XXX is marked the type of Olimex's A20 board, i.e. according the board you use XXX can be OLinuXino_Micro, Lime2, SOM or Lime.
Y in image file name is the number of image revision. 

The file a20-XXX_debian_34_90_release_Y.img.7z is an archive of
a20-XXX_debian_34_90_release_Y.img file. 
So in order to write the image on SD card you have to unzip a20-XXX_debian_34_90_release_Y.img.7z file:
1.1 for Windows
----------------
Use 7zip and then use Win32DiskImager.exe (http://sourceforge.net/projects/win32diskimager/) for image writing

1.2 for linux
-------------
Use p7zip package. If you have no installed 7zip then type 
#apt-get install p7zip
Copy a20-XXX_debian_34_90_release_Y.img.7z file in your directory and unzip it with 
#7za e a20-XXX_debian_34_90_release_Y.img.7z
The output should be a new 4GB file named a20-XXX_debian_34_90_release_Y.img
Put 4GB SD card in your card reader and type
# ls /dev/sd
Then press two times <TAB> you will see a list of your sd devices like sda sdb sdc note that some of these devices may be your hard disk so 
make sure you know which one is your sd card before you proceed as you can damage your HDD if you choose the wrong sd-device. 
You can do this by unplugging your sd card reader and identify which "sd" devices remove from the list.
Once you know which device is your sdcard like sda use this text instead of the sdX name in the references below:

#dd if=a20-XXX_debian_34_90_release_Y.img of=/dev/sdX

The main installed packages are listed below:

LXDE desktop environment
mplayer
smplayer
gcc-4.6
dpkg
git
i2c-tools
perl
xorg
python 2.7
midori
minicom
usb-modeswitch
sshfs
wvdial

The list of all installed packages is located in A20-Olimex-installed-packages.txt file

The main tested onboard hardware modules are:

- GPIO	-	they are located in /sys/class/gpio directory. Note that first you have to export GPIOs. For example:
# for i in `seq 1 1 230`; do echo $i > /sys/class/gpio/export; done
will export all available GPIOs
# echo out > /sys/class/gpio/gpioXX_pxx/direction
will make the port output
# echo 1 > /sys/class/gpio/gpioXX_pXX/value
will make the port output in logical 1
- LCD		-	4.3''(480x272), 7''(800x480), 10''(1024x600), 15''(1366x768), 15''(1080x1920)
- SATA	-	with power on/off control and battery support
- HDMI	-	the default HDMI resolution is 720p50(720x1280 - 50 Hz)
- Touch_screen	-	you need calibrate LCD before using touch screen. Note that if you want to use touch screen in X environment then you have to 
calibrate it like olimex user, not like root user because X environment is started like olimex user. For example type:
# su olimex
# sudo ts_calibrate 
calibrate the touch screen and reboot the board
- ASIX8877 USB-LAN	-	https://www.olimex.com/Products/OLinuXino/A13/USB-ETHERNET-AX88772B/. Usually it is eth1 interface
- USB WEB camera A4TECH
- WIFI_RTL8188	-	https://www.olimex.com/Products/Modules/Ethernet/MOD-WIFI-RTL8188/. Note that you have to set your SSID network and your password in /etc/network/interfaces file
- MOD-WIFI-R5370	-	https://www.olimex.com/Products/USB-Modules/MOD-WIFI-R5370. Note that you have to set your SSID network and your password in /etc/network/interfaces file
- USB_OTG		-	low/full/high USB host 
Note that you can use USB_OTG for SSH connection without need of LAN cable or serial cable. You can use only mini USB cable connected between your host PC
and the onboard mini USB connector. For connection convenience there is started a DHCP server only for USB0 interface. So the DHCP server should give IP address
to the new USB0 interface of your host PC and you can make SSH connection from your PC to the default board IP address of USB0 interface - 192.168.2.1
- USB_HOST_up		-	low/full/high USB host
- USB_HOST_down	-	low/full/high USB host
- MOD-USB3G	-	https://www.olimex.com/Products/USB-Modules/MOD-USB3G/. In order to test MOD-USB3G module you have to place SIM card(without pin code) in module 
and connect it to USB host connector, change settings in /etc/wvdial.conf file according to your mobile operator and type:
# wvdial 3gconnect
- mico_SD_card	- linux starts from micro_SD card
- second_SD_card	-	with card present capability 
- ETHERNET	-	100Mb/1000Mb. By default the board IP address is 192.168.1.254. So if you want to connect with the board using SSH client 
(for example Putty(http://www.chiark.greenend.org.uk/~sgtatham/putty/download.html)) then you have to use this address. 
You can change this address from /etc/network/interface file. 
Note that for internet connection you have to set your gateway address in /etc/network/interdaces file and 
you have to set your DNS server in /etc/resolv.conf(for example nameserver 192.168.1.1)
- MIC IN	-	for example:
# arecord -f dat -r 60000 -D hw:0,0 -d 5 test.wav
this command will record 5 sec audio stream from microphone in test.wav file 
- Headphone OUT	-	for example
# aplay -D hw:0,0 test.wav
this command will play the audio stream from test.wav file
- NAND support	-	/dev/nandX
- I2C2(100KHz)	-	/dev/i2c-2
- I2C1(100KHz)	-	/dev/i2c-1
- UART4(only for A20-Lime and A20-Lime2)	-	/dev/ttyS1
- UART6(only for A20-SOM, A20-OLinuXino-MICRO)	-	/dev/ttyS1
- UART7(only for A20-SOM, A20-OLinuXino-MICRO)	-	/dev/ttyS2
- SPI1((only for A20-SOM, A20-OLinuXino-MICRO))	-	/dev/spidev1.0
- SPI2	-	/dev/spidev2.0
there is a simple test for SPI2 in /opt/spidev directory. 
# ls /opt/spidev
max6675/
in folder max6675/ there is example related with MOD-TC(https://www.olimex.com/Products/Modules/Sensors/MOD-TC/open-source-hardware) - temperature sensor that you have to connect to UEXT1 connector
# cd max6675
# ./MAX6675
the last command will read temperature from MOD-TC thermocouple
- BUTTONs	- we use evtest package for testing. For example:
# evtest
then enter event number for keyboard and now you can press the BUTTONs and you should see the result on terminal window
- on board camera support (only for A20-SOM-EVB)
Note that there is a web server running by default and you can observe camera stream if you type board IP address in your browser
By default the IP address is 192.168.1.254 but you can change it with:
# ifconfig eth0 XXX.XXX.XXX.XXX 
Then you have to start the camera using the script below
#  /etc/campipe/capture.sh
with VLC player you can open network stream 
rtsp://A20SOM_IP/live/livestream
and you will see the camera stream too

Changing A20-XXX  HDMI, LCD or VGA resolution 
---------------------------------------------------
The default SD card setup is made with settings for HDMI 720p/50Hz. If you want to change some other LCD, VGA or HDMI resolution then you have to start 
change_display_a20_olimex.sh script file in /root directory.
Type:
# ./change_display_a20_olimex.sh

and choose the desired resolution of desired interface(LCD, HDMI or VGA)
The supported resolution are:

About LCD:
1. 4.3''(480x272)
2. 7''(800x480)
3. 10''(1024x600)
4. 15.6''(1366x768)
5. 15.6''-FHD(1920x1080)

- About 15.6 and 15.6-FHD LCD you can control backlight and DCR(Dinamic Contrast Ratio) using a soft pwm module. The main goal is to decrease power consumption. For example 
# echo 50 > /sys/class/softpwm/backlight/duty
will decrease the LCD backlight to 50%
the parameter for duty is between 0 and 100
# echo 10 > /sys/class/softpwm/duty
will decrease the LCD contrast
the parameter 10 for duty is between 0 and 100 

- About 4.3'', 7'' and 10'' LCD  you can control only backlight a hardware pwm module. The main goal is to decrease power consumption. For example
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

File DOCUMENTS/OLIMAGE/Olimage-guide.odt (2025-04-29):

OLIMAGE

GUIDE

Linux for Olimex Allwinner and STM32MP1 boards

Document revision F, April 2025

# 1. What is this?

This guide provides the reader with information about the basic features and the usage of the Olimage Linux images released and maintained by Olimex. All resources used to build Olimage Linux can be found at our GitHub repository.
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

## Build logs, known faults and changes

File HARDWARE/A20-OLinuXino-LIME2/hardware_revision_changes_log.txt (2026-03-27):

### Notable hardware revision changes A20-OLinuXino-LIME2. It applies to all board revisions:

Currently there are seven board variants available (depending on the memories installed and the operating temperature range):

A20-OLinuXino-LIME2 - no eMMC flash, no NAND flash, no SPI flash, all components in commercial temperature range (0 to +70)C
A20-OLinuXino-LIME2-e16Gs16M - 16GB eMMC flash present, 16MB SPI flash, all components in commercial temperature range (0 to +70)C
A20-OLinuXino-LIME2-e4GBs16M - 4GB eMMC flash present, 16MB SPI flash, all components in commercial temperature range (0 to +70)C
A20-OLinuXino-LIME2-n8GB - no eMMC flash, 8GB NAND flash, no SPI flash, all components in commercial temperature range (0 to +70)C
A20-OLinuXino-LIME2-s16MB - no eMMC flash, no NAND flash, 16MB SPI flash, all components in commercial temperature range (0 to +70)C
T2-OLinuXino-LIME2-IND - no eMMC flash, no NAND flash, no SPI flash, all components in industrial temperature range (-40 to +85)C
T2-OLinuXino-LIME2-s16MB-IND - no eMMC flash, no NAND flash, 16MB SPI flash, all componenets in industrial temperature range (-40 to +85)C

Make sure to check the web-page of A20-OLinuXino-LIME2 at www.OLIMEX.com to check if other board options are available.

#### Hardware revision B (pre-production)
===========

Internal initial release.

#### Hardware revision C (initial public release)
============================

1. C175 changed from 100n na 22uF (and changed package from 0402 to 0603);
2. Updated white prints: Lime to Lime2; rev.B to rev.C, 2014 to 2015.

#### Hardware revision D (internal, not released)
===============================

1. eMMC memory added; NAND or eMMC optional. Schematics set for NAND per default;
2. C224 and C232 - 47uF/6.3V/0805 added in parallel to the 5V_SATA_PWR connector;
3. Changed L1, L2, L3 from FB/600R/0805 to 0R/0805;
4. Capacitors C84, C85 changed to 22uF/0603 down from 100nF/0402;
5. Fixed the white name print from A20-OLinuXino-Lime(bottom) to A20-OLinuXino-Lime2 (there was no "2");
6. Improved LAN-a routing;
7. Added four extra data bits to the eMMC, through a resistor matrix;
8. Changed EMMC_RST. Moved from PC4/NCE0/EMMC_RST to PC16/NWP/EMMC_RST.

#### Hardware revision E (internal, not released)
==============================

1. Fixed white print of EMMC_PWR jumper (added positions);
2. Changed the white print of board revision;
3. U15 and U17 were changed in value from SY8008C(AA)C to SY8009AAAC(SOT23-5).

#### Hardware revision F (internal, not released)
==============================

1. Changed Ethernet PHY controller to RTL8211E-VB-CG1. This required changing a lot of components and routing in the area around the controller too;
2. Changed the placing of the pull-up rezistorite of the RX wire (before the matrix).

#### Hardware revision G (public release)
==============================

1. Added 4 improved mounting through holes, connected to GND. Removed the old milled mounting points.

#### Hardware revision G1 (public release)
==============================

1. Changed a couple of components that improves board's power up sequence due to the high initial consumption of the Ethernet controller (RTL8211E). R109 changed to 47k/0402 (down from 470k/0402) and R107 (470k/0402) replaced by a capacitor 220nF/0402.

#### Hardware revision G2 (public release)
=============================

1. The buttons moved 5 mils further to the middle of the board to futher reduce deformation during panelization;
2. R32 and R36 moved 40 mils further away from the Ethernet connector;
3. C207 moved to the top side of the board;
4. R76 moved away from C200, now it is placed in parallel to R83;
5. C179 moved a little bit away and C163 was rotated;
8. Fixed white print, symbol and package of R107(220nF) to avoid confusion;
9. R105 changed to NA; instead a pull-down R107 (4.7k) added;
10. Moved C150 15mils away from the Ethernet LEDs;
11. C212 and C213 moved 40mils away from L16;
12. The white print year changed to 2017 and the revision print updated to G2;
13. C201 and C211 changed from 22pF/0603 to 27pF/0603;
14. C116 and C117 changed from 33pF/0603 to 27pF/0603.

#### Hardware revision H (internal, not released)
=============================

1. CTP jumpers made the same as in A20-SOM-EVB;
2. Changed the PHY for the Micrel one;
3. R49 and R50 packages now 0402;
4. Fixed the labels of C108, C125, C159, C171, C176, C180. Now it shows capacitance and voltage range;
5. Changed R86 from 4.99k/1% to 12.4k/1% and R90 from 3.32k/1% to 10k/1% in order to decrease industrial DDR3 power suplly from 1.5V to 1.35V;
6. Added text: "When DDR3L is used, VDD&VDDQ are set to 1.35V!!!";

~~~~~~~~~~~~~~~~~~~~~~~~~~~~~
A20-OLinuXino-Lime2_Rev_H
~~~~~~~~~~~~~~~~~~~~~~~~~~~~~
1. DDR3 memory = commercial temperature Micron MT41K256M16HA-125:E(DDR3L-1600_11-11-11);
2. Ethernet PHY changed to commercial variant - KSZ9031RNXCC-TR;
3. The EMMC and all corresponding components changed to NA (Not Assembled);
4. The NAND flash and all corresponding components changed to NA (Not Assembled).

~~~~~~~~~~~~~~~~~~~~~~~~~~~~~
A20-OLinuXino-Lime2-IND_Rev_H
~~~~~~~~~~~~~~~~~~~~~~~~~~~~~
1. DDR3 memory set to the industrial Micron variant - MT41K256M16HA-125IT:E(DDR3L-1600_11-11-11);
2. Changed Ethernet PHY to industrial variant - KSZ9031RNXIC-TR;
3. EMMC flash and all corresponding components changed to NA;
4. NAND flash and all corresponding components set to NA;

~~~~~~~~~~~~~~~~~~~~~~~~~~~~~~
A20-OLinuXino-Lime2-EMMC_Rev_H
~~~~~~~~~~~~~~~~~~~~~~~~~~~~~~
1. DDR3 memory is set to commercial Micron variant - MT41K256M16HA-125:E(DDR3L-1600_11-11-11);
2. The PHY was changed to commercial variant - KSZ9031RNXCC-TR;
3. NAND flash and all corresponding components set to NA;
	
~~~~~~~~~~~~~~~~~~~~~~~~~~~~~~~~~~
A20-OLinuXino-Lime2-EMMC-IND_Rev_H
~~~~~~~~~~~~~~~~~~~~~~~~~~~~~~~~~~
1. DDR3 memory set to industrial variant - MT41K256M16HA-125IT:E(DDR3L-1600_11-11-11);
2. Ethernet PHY changed from KSZ9031RNXCC-TR to industrial variant KSZ9031RNXIC-TR;
3. NAND flash and all corresponding components set to NA.

#### Hardware revision I (internal, not released)
=============================

1. C207 moved on the top side of the board, for easier battery connector soldering;
2. R76 moved away from C200; now placed in parallel to R83;
3. 32768 crystal package changed with 0.1mm bigger padove and better paste;
4. C179 moved a little bit away while C163 was rotated to avoid AXP's GND pad;
5. All RA0805 SMT matrices RM4, RM7, RM8 changed to a package with larger external pads;
6. C150 moved 15 mils away from the Ethernet LEDs; 
7. C212 and C213 moved away from L16 to ease the L16 mounting/demounting;
8. Changed LEDs package (smaller pads_;
9. Crystals in HCX-4S package changed to HCX-4S_TEST package;
10. Package of GPIO-1 to GPIO-4 + LCD_CON changed;
11. C201 and C211 changed from 22pF/0603 to 27pF/0603;
12. C116 and C117 changed from 33pF/0603 to 27pF/0603;
13. C110 and C115 now 22pF to match the 32KHZ crystal;
14. HDMI connector changed to new package HDMI-SWM-19_TEST;
15. RCLAMP0524P changed package;
16. Added SPI FLASH option;
17. Improved the keepout of the mounting holes;
18. Despite that tant capacitors are NA (Not Assembled) they are changed to 0805 electrolyte ones;
19. Q4 crystal changed with smaller package (3.2x2.5);
20. Touch screen jumpers (capacitive/resistive option) changed with matrices;
21. PWR_JACK's package improved;
22. SD_CARD package improved;
23. Added pims for additional AXP209 back-up battery (PIN30 AXP);
24. Improved ground planes and polygons;
25. All 27pF capacitors changed to 33pF, U16 was SY7208(SOT23-6) now is MT3608(SOT23-6), R65 was 100R and now changed to 191R/1%;
26. The labelling of all GPIO connector signals now re-done.

#### Hardware revision J (internal, not released)
=============================

1. HDMI-CEC pulled to 3.3V via 27k and diode;
2. HDMI-HPD now goes trhough 10k R31 in series; R47 changed from 47k to 20k;
3. D3 moved to the top side (on U14's place). U14 moved to the bottom side (under PWR_JACK);
4. Fixed D6's value 1N4007/SMA;
5. Added jumper WE_ENABLE to the SPI flash;
6. Added USB key 100uf capactiors;
7. Changed SATA connector package;
8. Added RCL filter to GTXCK;
9. Added filtering capacitors in series to GTXD0-3 and GTXCTL;
10. Added C82 filter to the CLK125;
11. Improved capacitor routing around the RAM and the A20 chip;
12. Improved MICROSD connector routing; 
13. Added capacitor to GRXCLK;
14. The resistors on Ethernet's TX and RX are now 33R;
15. SY8009AAAC changed to SY8089AAAC.

#### Hardware revision K (public release)
=============================

1. Added the small footprint Samsung eMMC.
2. Renamed GMAC_PWR_E/PH7 to just PH7. The signal was needed by old Ethernet PHY, it is no longer routed to the Ethernet.
3. Removed filtering from PHY's TX and RX - L3, L4 removed (from 2.7nH/0402 changed to NA); C81, C254 removed (changed from 24pF/0402 to NA). This improves GB speeds.

#### Hardware revision K1 (public release)
=============================

Updated capacitor values around the AXP209 to be 100% compatible with the recommendation:

1. C179 10uf/0603 --> 1uF/0603
2. C183 10uF/0603 --> 4.7uF/0603
3. C185 10uF/0603 --> 4.7uF/0603
4. C186 10uF/0603 --> 4.7uF/0603
5. C188 10uF/0603 --> 4.7uF/0603
6. C158 10uF/0603 --> 4.7uF/0603
7. C163 10uF/0603 --> 4.7uF/0603
8. C171 1uF/0603 --> 4.7uF/0603
9. C182 10uF/0603 --> 220nF/0603

Added free SPI flash on all boards with eMMC, this required few extra components:

10. U22 NA --> W25Q128FVSIG
11. C71 NA --> 100nF
12. R16 NA --> 10k
13. R12 NA --> 10k
14. R17 NA --> 10k

Fixed few wrong text values in the schematic:

Q2 -> Q32.768kHz/12.5pF/2P/SMD1206
L 2.2uH/CD32 -> 2.2uH/NR3015T2R2M/1.5A/3015
U14 -> MCP121T475I-TT

#### Hardware revision K2 (public release)
=============================

Changed eMMC from KLMAG2GEND-B031(FBGA153)(16G) to KLMAG1JETD-B041(FBGA153)(16G)

#### Hardware revision L (public release)
=============================

1. Changed RAM to K4B4G1646D-BYK0.
2. RM4 package changed from 0403 to 0603.
3. Added C90(10pF) on EMMC_CLK.
4. Coils changed to 2.2uH/NR3015T2R2M/1.5A/3015.
5. Changed MCP120T475I-TT with MCP121T475I-TT.
6. C177 and C190 separated a little further from each other.
7. Fixed eMMC label to reflect new memory.
8. Changed capacitors of the 25Mhz crystal of the Ethernet controller. Now 15pf (down from 33pf).
9. Updated and improved the packages of a lot of components.

#### Hardware revision L1 (public release)
=============================

1. Changed U14 from MCP121T475I-TT vs VDA4510NTA

#### Hardware revision M (public release)
=============================

1. WP of the spi flash connected via NA to PA14;
2. EFUSE_VDDQ(T9) connected to gnd via r22 and to 2.5V via r23;
3. TVS D3 moved to bottom under pwr jack;
4. Added CE print;
5. Added layer enumeration;
6. MCP121 changed to VDA4710CTA;
7. AMS1117 changed to LD1117AG-AD-AA3-A-R;
8. DDR now K4B4G1646E-BYMA0CV due to availability;
9. Moved components and wires as far from the edges as possible;
10. Changed EMMC, NAND, SPI FLASH with FLASH_CONNECTOR. Spi flash left on the board as NA trough NA reriztors since it doesn't get in the way;
11. C182 changed from 0603 size to 0402 to optimize production.

#### Hardware revision N (public release)
=============================

1. Added VDA4510CTA, and MCP121 now NA;
2. lm1117 changed to LD1117AG-AD-AA3-A-R.

#### Hardware revision M (public release)
========

1. WP of spi flash connected to NA at PA14
2. EFUSE_VDDQ(T9) connected to GND via R22 and to 2.5V via R23
3. TVS D3 moved to bottom side
4. Added CE sign
5. Added layer enumaration
6. MCP121 changed to VDA4710CTA
7. AMS1117 changed with LD1117AG-AD-AA3-A-R
8. Improved a lot of values
9. Changed some trougholes
10. Improved spacing of components near the edges
11. Changed EMMC, NAND, SPI FLASH with FLASH_CONNECTOR
12. C182 changed from 0603 to 0402 size

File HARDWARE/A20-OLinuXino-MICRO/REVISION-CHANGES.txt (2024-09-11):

Hardware changes in revision G (released)
========
1. Added C223 - 220uF/tant with NA value on SATA PWR.
2. C216 is now 22uF/6.3V instead of 100n, so it gets charged slower.  
3. Update of all libraries. HDMI connector is changed to new package.
4. HDMI protection removed (caused incompatiblities with cheap HDMI monitors).

Hardware changes in revision H (only prototypes; not released)
========
1. Changed the LAN part of the design, added two capactiors 1nF/2kV/X7R/1206, and 1nF/2kV/X7R/1206_or_1M, 
also the matrix is now 0402 with 49.9 ohm at 1%. 
2. Major polygon changes.
3. Removed HDMI protection ciruit(RCLAMP0524P becomes NA).
4. Preparation for memory changes from MEM4G16D3EABG-125 to K4B4G1646D-BCK0.
5. Position of C95 and C96 slightly adjusted, so that they are not under GPIO-1 and LAN. USB_OTG polygon changed. USB_HOST polygon adjusted. Removed few vias. 
6. Added few more vias for the VCC.
7. Improved white print. Year and revision updated. Web-site address updated.
8. Power jack package updated.
9. SATA package updated.

Hardware changes in revision I (only prototypes; not released)
========
1. eMMC was added.
2. RTL8201CP(LQFP-48) Ethernet chip replaced with LAN8710AI-EZK(QFN-32). Both are MbE PHYs.
3. All libraries were updated.
4. L7, L15, L16 and L17 wåre changed from FB0805/600R/200mA(201209-601) to FB0805/600R/2A.
5. PWR-JAKPWR_JACK_UNI_MILLING_SMALLER_DRILLS changed to PWRJ-2mm(YDJ-1136).
6. R98 optimized from 10k/1% to 10k.
7. C195 and C208 optimized 22pF to 33pF.
8. R43 and R103 optimized from 51R to 100R.
9. C123, C126 and C135 were changed from 100uF/16V/LOWESR/105C/6.3x11mm_RM2.5 to 2x47uF/6.3V/0805, i.e. C123||C240, C126||C222 and C135||C223
10. D6 was renamed to D2 and changed to the D4's package.
11. U13 and U15 were changed from SY8008 to SY8009AAAC(SOT23-5).
12. ODT1, SCKE1, SCS1/SA15 and ZQ1 were connected to the 2 DDR memories with aim to support bigger sizes if one day A40 is released or A10 is used.
13. All resistor matrices: RM1-RM8 and RM16-RM21(RA0805_(4X0402)_0R(Board_Mounted)) were removed and the wires were shortened. The same thing was done for: R106-R117(0R(Board_Mounted)).
14. The viases that were between GPIO-1 pads 12/14 were removed.
15. The eMMC was placed over the NAND flash.
16. The cream layer was improved.
17. BKUP connector(HN1x2) was added for AXP's power management option.
18. RM1 and RM2 were added to enable CTP support for the LCD connector.
19. MP1482DS was exchanged with MP1584EN(SOIC8E). Because of this, were affected D5, C202, C203 and several other components as well.
20. The files were renamded from 4G to nothing, because the schematic is universal for all boms generated!
21. C217's value was changed from 220uF/10V/TANT to 220uF/10V/TANT_D!
22. Added reset control for the new PHY - C63 becomes NA down from 10uF, R26 becomes NA down from 10K and R25 is now 100R up from NA.

Hardware changes in revision J (released)
========
1. Rotated RM1 and RM2 at 90 degrees for better soldering.
2. Created separate design for each of the variants of the board ( 1. commercial temeprature range and no flash memory - A20-OLinuXino-MICRO; 2. industrial temperature range and no flash memory - A20-OLinuXino-MICRO-IND; 3. commercial temperature range and flash memory - A20-OLinuXino-MICRO-EMMC; 4. industrial temperature range and flash memory - A20-OLinuXino-MICRO-EMMC-IND) - each of these boards would have own hardware revision from now on.

~~~~~~~~~~~~~~~~~~~~~~~~~~~~~
A10-A20-OLINUXINO-MICRO_Rev_J
~~~~~~~~~~~~~~~~~~~~~~~~~~~~~
1. DDR3 memory is set to commercial Micron variant - MT41K256M16HA-125:E(DDR3L-1600_11-11-11);
2. The PHY was changed to commercial variant - LAN8710A-EZC-TR(QFN-32);
3. Changed two resistor values: r77 from 4.99k/1% to 12.4k/1% and r78 from 3.32k/1% to 10k/1% in order to decrease commercial DDR3L power supply from 1.5V to 1.35V; The text: "When DDR3L is used, VDD&VDDQ are set to 1.35V!!!" was added in the schematic!
4. The EMMC and all related components were changed to NA;
5. The NAND flash and all related components were changed to NA;

~~~~~~~~~~~~~~~~~~~~~~~~~~~~~~~~~
A10-A20-OLINUXINO-MICRO-IND_Rev_J
~~~~~~~~~~~~~~~~~~~~~~~~~~~~~~~~~
1. Changed the memory to the industrial variant - MT41K256M16HA-125IT:E(DDR3L-1600_11-11-11)
2. Changed PHY to industrial variant LAN8710AI-EZK-TR(QFN-32)
3. Changed r77 from 4.99k/1% to 12.4k/1% and r78 from 3.32k/1% to 10k/1% in order to decrease commercial DDR3L power suplly from 1.5V to 1.35V; the text: "When DDR3L is used, VDD&VDDQ are set to 1.35V!!!" was added in the schematic!
4. The EMMC and all corresponding components were changed to NA;
5. The NAND Flash and all corresponding components were changed to NA;

~~~~~~~~~~~~~~~~~~~~~~~~~~~~~~~
A20-OLINUXINO-MICRO-EMMC_Rev_J
~~~~~~~~~~~~~~~~~~~~~~~~~~~~~~~
1. DDR3 memory is set to commercial Micron variant(required by Ceco) - MT41K256M16HA-125:E(DDR3L-1600_11-11-11);
2. The PHY was changed to commercial variant - LAN8710A-EZC-TR(QFN-32);
3. Changed are r77 from 4.99k/1% to 12.4k/1% and r78 from 3.32k/1% to 10k/1% in order to decrease commercial DDR3L power suplly from 1.5V to 1.35V; The text: "When DDR3L is used, VDD&VDDQ are set to 1.35V!!!" was added in the schematic!

~~~~~~~~~~~~~~~~~~~~~~~~~~~~~~~~~~~~~~~	
A10-A20-OLINUXINO-MICRO-EMMC-IND_Rev_J
~~~~~~~~~~~~~~~~~~~~~~~~~~~~~~~~~~~~~~~
1. Change memory to industrial variant - MT41K256M16HA-125IT:E(DDR3L-1600_11-11-11)
2. Change PHY to industrial variant LAN8710AI-EZK-TR(QFN-32)
3. Change r77 from 4.99k/1% to 12.4k/1% and r78 from 3.32k/1% to 10k/1% in order to decrease industrial DDR3 power suplly from 1.5V to 1.35V; The text: "When DDR3L is used, VDD&VDDQ are set to 1.35V!!!" was added in the schematic!

Hardware changes in revision J1 (released)
========

1. C130 and C137 changed from 100nF/0603 to 22uF/6.3V/0603;
2. L8(FB0805/600R/2A) and L10(FB0805/600R/2A) changed to 0R/0805;
3. R48(6.81k/1%) and R55(13k/1%) changed to 3.9k/1%/0603 to increase the USB current limit to 2A;
4. R80(11k/1%) changed to 13k/1% and R86(2k/1%) changed to 2.2k/1%. This is done in order to increase slightly the 5VEXT voltage and to compensate the voltage drop over D4 during current peaks;
5. R32, R65, R70, R73, R75, R76, R81, R82, R83, R93, R94, R120 changed from 2.2k/0603 to 2.2k/1%/0603;
6. R1, R2, R4, R6, R8, R37, R39, R57 changed from 2k/1%/0603 to 2.2k/1%/0603;
7. L4 and L5 changed from CL470nH/0805/1.76R/250mA to FB0805/600R/2A;
8. R77(12.4k/1%/0603) changed to 16.2k/1%/0603. R78(10k/1%/0603) changed to 13k/1%/0603;
9. R25, R43, R58, R103 changed from 100R/0603 to 49.9R/1%/0603;
10. R85, R108 changed from 100k/0603 to 100k/1%/0603;
11. R41, R104, R150, R151 changed from 390R/0603 to 330R/1%/0603.

Hardware changes in revision K (internal, not released)
========

1. R144 and R145 packages changed from 10k/0402 to 10k/0603;
2. C241 moved away from the power jack. This improves the soldering of the jack.
3. Added 5V_EXT power option on a separate pinhole near 5V_SATA_PWR connector. It allows powering the board via 5V DC source applied directly (bypassing U14 - MP1584).
	- The 5VEXT pad changed from SMD to PTH, was renamed to 5V_EXT and position adjusted a bit;
	- GND_EXT pad provided near 5V_EXT at 100mils distance for easier access;
4. 27k pull-up and diode(in the FET) added to the HDMI-CEC signal;
5. Serial resistor (47k) added to the HDMI-HPD signal to form a voltage divider 5V to 3.3V, because of the HDMI specification - HDMI-HPD signal can reach 5V level. R40 changed from 47k to 100k;
6. C217(220uF/10V/TANT_D) changed with 4x47uF/6.3V/0805 ceramic capacitors; C145 changed from 10uF/6.3V to 47uF/6.3V;
7. Changed the package of the SATA connector. New package has better mounting pads;
8. Changed the packages of LCD_CON, GPIO-1, GPIO-2, GPIO-3, UEXT1 and UEXT2 connector. The new packages has increased cream layer around pads;
9. USB_OTG package also updated - corrected cream layer and origin;
10. All buttons packages changed - corrected pads;
11. All small matrices packages changed - corrected pads;
12. C233 was exchanged with 2x47uF/6.3V/0805 ceramic capacitors;
13. U13 and U15 were changed from SY8009AAAC(SOT23-5) to SY8089AAAC(SOT23-5);
14. U16 was changed from SY7208(SOT23-6) to MT3608(SOT23-6);
15. Q2 was changed in package - the one with increased cream layer;
16. Q2 was changed in value - from 32768Hz/6pF to Q32.768kHz/12.5pF/20ppm/4P/SMD8038;
17. C97 and C98 were changed from 10pF to 22pF/50V/5%/COG/C0603;
18. PWR_LED, CHGLED and LED1 were changed in package - smaller pads to avoid floating of the LEDs while soldering.
19. R40, R85, R108 were changed from 100k/0603 to 100k/1%/0603;
20. C102 was changed from 100nF/0402 to 220nF/0402. C200 was changed from 100nF/0402 to 100nF/0603;
21. SPI Flash for enabling other booting option was added! It required several other components to be added around it too;
22. U23, U22 and U17 - RCLAMPs were changed in package to avoid short circuits while soldering;
23. HDMI was changed in package to the one with enlarged pads. This ease the manula soldering;
24. It was added second eMMC in the smaller package (0.50mm pitch), because the bigger one (1.00mm pitch) is almost obsolet - can not be ordered;
25. R93, R94 and R95 were moved 50mil away from the UEXT1 connector.

Hardware changes in revision L (released)
========

1. R20 changed from pull-up to pull-down.
2. Moved a couple of components to reduce possible noise; made several power wires a bit wider.
3. C209 was moved from bottom to top for to ease the LIPO_BAT connector's soldering. D2 was moved 20mils towards the edge of the board for the same purpose.

Hardware changes in revision L1 (released)
=========

Improved AXP capacitor values to be exactly as in the design suggestions:

1. C172 10uf/0603 --> 1uF/0603
2. C178 10uF/0603 --> 4.7uF/0603
3. C179 10uF/0603 --> 4.7uF/0603
4. C180 10uF/0603 --> 4.7uF/0603
5. C187 10uF/0603 --> 4.7uF/0603
6. C149 10uF/0603 --> 4.7uF/0603
7. C158 10uF/0603 --> 4.7uF/0603
8. C146 1uF/0603 --> 4.7uF/0603
9. C177 10uF/0603 --> 220nF/0603

Changed eMMC to the newest value KLMAG1JETD-B041003(153FBGA)

Hardware changes in revision L2 (released)
=========

Minor changes to multiple component packages to improve machine soldering.
 
Hardware changes in revision M (released)
=========

1. Changed RAM K4B4G1646D-BYK0.
2. Changed inductance 2.2uH with 2.2uH/NR3015T2R2M/1.5A/3015 
3. Added the option for LAN protection - ESD5302F, by default are NA. 
4. Moved R80 further away from the edge 
5. GBH-254-SMT-40 value changed to P-B-V-40-LF. GBH-254-SMT-10 value changed to P-B-V-10-LF.

Hardware changes in revision M1 (released)
=========

1. Changed value for the ESD protection of LAN, ESD1 and ESD2, from NA to ESD5302F-3/TR (ESD protection now populated)!

Hardware changes in revision M2 (released)
=========

1. Changed R114(at EMMC_CLK(PC7)) from 22R to 47R. Improves booting rate from the eMMC.

Hardware changes in revision N (released)
=========

1. Added CE logo.
2. Moved couple of components and wires to be further from the board's edge.
3. Changed the ESD protection to the new ESDS314DBVR.
4. Connectted WP of spi flash with PG6 trough NA.
5. FLASH_CONNECTOR won't be placed by default.

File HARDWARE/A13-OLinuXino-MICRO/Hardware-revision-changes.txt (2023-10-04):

Hardware design changes of A13-OLinuXino-MICRO.

- Revision C1
-----

Changing R17 from 2k/1%/0603 to 2.2k/1%/0603. This increases the voltage available on the regulator to 1.45V (up from 1.4V). This increases the reliability of first boot.

- Revision C
-----

1. Changed the ferrite beads of the USB shield and SD card to FB0805/600R/2A.
2. Changed SD card with MICRO_SD/TFC-WPAPR-08.
3. Improved card detect. R56 changed from (na) to 10k pull down. RM12G1 now pull up.

- Revision B1
-----
 
1. R56 chanaged from 10k to NA, to force always card present

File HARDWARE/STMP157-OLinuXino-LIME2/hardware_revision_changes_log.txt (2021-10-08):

### Notable hardware revision changes STMP157-OLinuXino-LIME2. It applies to all board variants:

Initial hardware revision - B1

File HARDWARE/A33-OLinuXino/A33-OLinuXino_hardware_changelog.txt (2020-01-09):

A33-OLinuXino, hardware change log

Hardware revision B1 (same PCB as revision B with changed components; released)
=========
The white print on boards from revision B1 stills says B.
You can determine if a board is revision B or revision B1 only by inspecting if the changes below had taken place!

1. Changed SMD crystal with PTH one and a 10M capacitor in parallel to the new crystal.
2. Replaced D2 with 0R/1206 resistor. The diode was interfering with the communication between the A33 and the PMU (dropping the voltage to 2.5V).
3. C121 (100pF) changed to 0R; C115(100n) now removed (has value NA) so output from 3.5mm JACK can be connected to microphone

Hardware revision C (new PCB; released)
========
All changes from revision B1 are applied also.

1. The value of the R75 resistor changed from 1M to 10M; there was an error in the value in the previous revision.
2. The package of R75 changed from 0603 to 0402.
3. Q2's value changed from MC-306_32.768KHZ/SMD_8038/6pF to MC-306_32.768KHZ/SMD_8038/12.5pF, the original one went out-of-stock.
4. C68 and C69 changed from 10pF to 20pF to match the new quartz.
5. The 32KFOUT lead to a corresponding test pad. 
6. U7 changed from SY7208 na MT3608.
7. Boards with NAND have new 8GB NAND placed.

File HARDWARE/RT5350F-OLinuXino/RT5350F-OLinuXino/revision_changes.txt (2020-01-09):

Rev.A (early proto)

RT5350 rev.B (production)
=========================
1. Add external power 1.2V to decrease heating from the internal LDO
2. Add connector for nused signals and Flash memory
3. Add Jumper for 1.2V to switch source
4. Pull-up to LDOSEL
5. Add connector for external antenna
6. Add CS1 from RT5350 to memory
7. remap LAN connector signals 

Rev.C (production)
==================
1. Add PWR LED to 3.3V
2. Z1 -> DDZ9678-7(SOD-123)_Farnell_PN-1858631 was add to protect the MCU in case of DCDC failure/short-circuite between the Input and Output.
3. Add 5.6V zener to +5V for 1.2V DCDC protection
4. Crystal changed from 20ppm to 10 ppm E4SB20.000F20E15(20MHz/10pF/10ppm/5x3.2mm)
5. C49 change from NA to 6.8 pF, C50 change from 27pF to 22pF. 

Rev.D (production)
==================
1. Add oscilator 20MHz option.
2. Add pull up to EPHY_LED0_N 4.7k(R42), R7 change to NA, as sometimes at boot RAM size is not recognized correctly 

Rev.E (internal)
================
1. crystal and oscillator moved away
2. R42 pull up to EPHY_LED2_N change from 4.7K to NA
3. R9 change from NA to 4.7K
4. Updated Flash memory and SOC packages.

Rev.F (production)
========

1. LINK2 back to pull down mode. Now R9 = 4.7k and R42 = NA.
2. Hole bear R9 pad - removed, the other hole moved further away.
3. Changed SY8009AAAC(SOT23-5) with SY8089AAAC(SOT23-5).
4. Improved royting of 3.3V DC(U5)

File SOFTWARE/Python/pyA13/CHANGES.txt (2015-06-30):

Changelog
=========
    * pyA13 0.2.2 (30 JUN 2015)
        * Fixed issue with SPI xfer function

    * pyA13 0.2.1 (16 OCT 2014)
        * Fixed some typos

    * pyA13 0.2.0 (03 SEP 2014)
        * Updated to enable SPI and I2C control
        * GPIO constant in separate modules
        * Added example files
        * Added support for Python3

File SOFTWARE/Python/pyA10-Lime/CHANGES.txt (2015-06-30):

Changelog
=========
    * pyA10Lime 0.2.1 (30 JUN 2015)
        * Fixed issue with SPI xfer function

    * pyA10Lime 0.2.0 (02 SEP 2014)
        * Updated to enable SPI and I2C control
        * GPIO constant in separate modules
        * Added example files
        * Added support for Python3

    * pyA10Lime 0.1.0 (23 JAN 2014)
        * Initial release

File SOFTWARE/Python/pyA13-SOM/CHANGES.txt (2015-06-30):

Changelog
=========
    * pyA13SOM 0.2.1 (30 JUN 2015)
        * Fixed issue with SPI xfer function

    * pyA13SOM 0.2.0 (02 SEP 2014)
        * Updated to enable SPI and I2C control
        * GPIO constant in separate modules
        * Added example files
        * Added support for Python3

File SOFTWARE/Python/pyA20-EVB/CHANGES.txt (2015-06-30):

Changelog
=========
    * pyA20EVB 0.2.1 (30 JUN 2015)
        * Fixed issue with SPI xfer function

    * pyA20EVB 0.2.0 (03 SEP 2014)
        * Initial release

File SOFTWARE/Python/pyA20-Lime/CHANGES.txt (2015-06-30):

Changelog
=========
    * pyA20Lime 0.2.1 (30 JUN 2015)
        * Fixed issue with SPI xfer function

    * pyA20Lime 0.2.0 (03 SEP 2014)
        * Initial release

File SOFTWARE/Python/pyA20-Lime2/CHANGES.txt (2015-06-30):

Changelog
=========
    * pyAA20Lime2 0.2.1 (30 JUN 2015)
        * Fixed issue with SPI xfer function

    * pyA20Lime2 0.2.0 (3 SEP 2014)
        * Initial release

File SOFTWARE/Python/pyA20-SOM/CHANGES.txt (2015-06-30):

Changelog
=========
    * pyA20SOM 0.2.1 (30 JUN 2015)
        * Fixed issue with SPI xfer function

    * pyA20SOM 0.2.0 (03 SEP 2014)
        * Initial release

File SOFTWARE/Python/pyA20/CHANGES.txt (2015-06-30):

Changelog
=========
    * pyA20 0.2.1 (30 JUN 2015)
        * Fixed gpio1 connector constants
        * Fixed issue with SPI xfer function

    * pyA20 0.2.0 (02 SEP 2014)
        * Updated to enable SPI and I2C control
        * GPIO constant in separate modules
        * Added example files
        * Added support for Python3

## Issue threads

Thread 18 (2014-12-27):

Debian rootfs for building own flash image contains a ffmpeg git checkout

landswellsong, 2014-12-27:
I believe somebody lost it there, 640 Mbs of dead weight. Link: https://www.olimex.com/wiki/images/2/29/Debian_FS_34_90_camera_A20-olimex.torrent

```
root@a20-olimex:~# du -sh *
24K     change_display_olimex_A20.sh
4.0K    Desktop
634M    FFmpeg
4.0K    minicom.log
```

DanKoloff, 2015-01-05:
Thanks for pointing this out. In case a user would never use the camera interface of the board - it might be considered "dead-weight", indeed. You can delete it.

However, please note, the file is required for the camera and the encoding of the raw image. The word "camera" in the torrent name suggests that the on-board camera can be tested with this image.

landswellsong, 2015-01-12:
@DanKoloff  yes, but I believe the camrea setup only requires `ffmpeg` executable itself and not a whole repository checkout with sources and history and everything.

Closed 2016-05-25.

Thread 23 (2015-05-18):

olimex micro doesnt start

dmsherazi, 2015-05-18:
when the board is powered on it displays this message on the debug uart continuously!

    U-Boot SPL 2014.04-10706-g36080eb (Aug 19 2014 - 16:42:16)
    Board: A20-OLinuXino_MICRO
    DRAM:Timeout initialising DRAM

Please help how can I debug this

TsvetanUsunov, 2015-05-18:
is this our board or yours with different memory chips?

dmsherazi, 2015-05-19:
its a olimex micro board

DanKoloff, 2015-05-19:
Hello, this doesn't seem like a software issue or problem with the default image.

Try to boot with external power supply. USB powering might be insufficient causing certain hardware to remain un-powered.

Make sure you are using the suitable image for your board. Different boards have different images.

If the problem persists contact the customer support at support@olimex.com - it is a good idea to provide more details - which board exactly do you have; did it behave like that since day one; did you try android or another image; how do you power the board. Anything that might us help replicate the problem is welcome.

dmsherazi, 2015-06-02:
I had a problem with power... fixed it!

Closed 2015-05-19.

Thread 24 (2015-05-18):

Can I replace k4b4g1646gb-bck0 RAM with k4b1g1646g-bck0 in A20 Micro

dmsherazi, 2015-05-18:
I plan to make one pcb prototype based on A20 Micro board. Can i use k4b4g1646g-bck0 instead of k4b1g1646b-bck0,

Do I need to change the fex file for this?

Closed 2016-05-25.

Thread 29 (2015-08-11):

can't cross build python packages

ricardocrudo, 2015-08-11:
I can't build python packages using buildroot. In the building process the following message is received:

```
>>> python-olimex 0.2.1 Patching
>>> python-olimex 0.2.1 Configuring
>>> python-olimex 0.2.1 Building
(cd /home/crudo/modduo-build/ROOT/build/python-olimex-0.2.1//; PATH="/home/crudo/modduo-build/ROOT/host/bin:/home/crudo/modduo-build/ROOT/host/sbin:/home/crudo/modduo-build/ROOT/host/usr/bin:/home/crudo/modduo-build/ROOT/host/usr/sbin:/usr/local/sbin:/usr/local/bin:/usr/sbin:/usr/bin:/sbin:/bin:/usr/games:/usr/local/games" PYTHONPATH="/home/crudo/modduo-build/ROOT/target/usr/lib/python3.4/sysconfigdata/:/home/crudo/modduo-build/ROOT/target/usr/lib/python3.4/site-packages/" _python_sysroot=/home/crudo/modduo-build/ROOT/host/usr/arm-buildroot-linux-gnueabihf/sysroot _python_prefix=/usr _python_exec_prefix=/usr  /home/crudo/modduo-build/ROOT/host/usr/bin/python setup.py build  )
running build
running build_py
creating build
creating build/lib.linux-x86_64-3.4
creating build/lib.linux-x86_64-3.4/pyA20
copying pyA20/__init__.py -> build/lib.linux-x86_64-3.4/pyA20
creating build/lib.linux-x86_64-3.4/pyA20/gpio
copying pyA20/gpio/__init__.py -> build/lib.linux-x86_64-3.4/pyA20/gpio
running build_ext
No processor detected
Warning! Detected and target processor mismatch.
Do you want to continue [Y/n]?
```

nardist01, 2016-03-05:
same problem

SelfDestroyer, 2016-03-07:
Since you're cross compiling the setup script is detecting that the host cpu is not same as the target(AW A20). Because of that you get input form. To bypass this, you should comment some code:

    def print_warning():
    """
    Print confirmation dialog
    :return:
    """
    print (print_color("Warning! ") + "Detected and target processor mismatch. ")

    # var = input("Do you want to continue [Y/n]? ")
    # if var == 'Y' or var == 'y':
    #     return
    # else:
    #     print ("Abort.")
    #    sys.exit(1)

This is **setup.py** file. After that it should work

Closed 2016-05-25.

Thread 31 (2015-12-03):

Terrible performance with gigabit ethernet on A20-OLinuXIno-LIME2

dariox86, 2015-12-03:
When gigabit ethernet is enabled by default on Debian images from Olimex, Debian images from the official Debian website and Arch Linux, ethernet performance is terrible. Maximum download speed is 15 KB/s and sometimes drops as low as 5 KB/s. Forcing 100 Mb/s ethernet via software (# mii-tool eth0 -F 100baseTx-FD) or connecting the board to a 100 Mb/s switch is a workaround, though I have bought the board specifically for the gigabit capability. The problem is mentioned here: http://forum.armbian.com/index.php/topic/31-problems-with-gigabit/ and here: https://www.olimex.com/forum/index.php?topic=4615.0 . The problem is very easy to reproduce: just hook up the board to a 1000 Gb/s network switch and try to download something from the Internet.

MontiMcMannus, 2016-01-28:
It depends on the board, some are ok, some not. You may try to send it back, another board may be useable...

dariox86, 2016-01-28:
Thank you for the answer. Do you work at Olimex? Do I have to open a RMA to send it back? The board was bought several months ago. Is it still under warranty?

dan-cristian, 2016-03-16:
I have the same issue. I run the test between an Intel machine running linux, with gigabit ethernet, and Lime2.
My switch is a 24-port gigabit. Clearly no problem with my network equipment or cables as I have several PCs in my network with gigabit links working OK.

I run the Vanilla Jessie image from http://www.armbian.com/olimex-lime-2/.

DOWNLINK seems fine, getting max 701 Mbits/sec. See below.
UPLINK is terrible, avg. is 3 Mbits/s.

-------------------DOWNLINK------------------------------------
root@lime2:~# iperf3 -c 192.168.0.11
Connecting to host 192.168.0.11, port 5201
[  4] local 192.168.0.27 port 58414 connected to 192.168.0.11 port 5201
[ ID] Interval           Transfer     Bandwidth       Retr  Cwnd
[  4]   0.00-1.00   sec  59.1 MBytes   495 Mbits/sec    0    204 KBytes
[  4]   1.00-2.02   sec  69.5 MBytes   575 Mbits/sec    0    335 KBytes
[  4]   2.02-3.00   sec  65.4 MBytes   557 Mbits/sec    0    506 KBytes
[  4]   3.00-4.02   sec  65.5 MBytes   541 Mbits/sec    0    765 KBytes
[  4]   4.02-5.00   sec  77.5 MBytes   660 Mbits/sec    0    765 KBytes
[  4]   5.00-6.00   sec  79.6 MBytes   666 Mbits/sec    0   1.02 MBytes
[  4]   6.00-7.00   sec  81.2 MBytes   683 Mbits/sec    0   1.33 MBytes
[  4]   7.00-8.01   sec  78.8 MBytes   656 Mbits/sec    0   1.33 MBytes
[  4]   8.01-9.00   sec  77.5 MBytes   653 Mbits/sec    0   1.50 MBytes
[  4]   9.00-10.01  sec  83.8 MBytes   701 Mbits/sec    0   1.50 MBytes
- - - - - - - - - - - - - - - - - - - - - - - - -
[ ID] Interval           Transfer     Bandwidth       Retr
[  4]   0.00-10.01  sec   738 MBytes   619 Mbits/sec    0             sender
[  4]   0.00-10.01  sec   738 MBytes   619 Mbits/sec                  receiver

--------------------UPLINK------------------------------------------------

root@lime2:~# iperf3 -c 192.168.0.11 -R
Connecting to host 192.168.0.11, port 5201
Reverse mode, remote host 192.168.0.11 is sending
[  4] local 192.168.0.27 port 58418 connected to 192.168.0.11 port 5201
[ ID] Interval           Transfer     Bandwidth
[  4]   0.00-1.00   sec   650 KBytes  5.33 Mbits/sec
[  4]   1.00-2.00   sec   431 KBytes  3.53 Mbits/sec
[  4]   2.00-3.00   sec   291 KBytes  2.39 Mbits/sec
[  4]   3.00-4.00   sec   505 KBytes  4.14 Mbits/sec
[  4]   4.00-5.00   sec   535 KBytes  4.38 Mbits/sec
[  4]   5.00-6.00   sec   240 KBytes  1.97 Mbits/sec
[  4]   6.00-7.00   sec   181 KBytes  1.48 Mbits/sec
[  4]   7.00-8.00   sec  77.8 KBytes   637 Kbits/sec
[  4]   8.00-9.00   sec   573 KBytes  4.69 Mbits/sec
[  4]   9.00-10.00  sec   216 KBytes  1.77 Mbits/sec
- - - - - - - - - - - - - - - - - - - - - - - - -
[ ID] Interval           Transfer     Bandwidth       Retr
[  4]   0.00-10.00  sec  3.63 MBytes  3.05 Mbits/sec  373             sender
[  4]   0.00-10.00  sec  3.61 MBytes  3.03 Mbits/sec                  receiver

dariox86, 2016-03-17:
I see. Mine is even worse.

mhaas, 2016-03-17:
There is some work being done to get this fixed via u-boot: https://www.mail-archive.com/u-boot@lists.denx.de/msg206626.html

Please disregard my initial patch there.

dariox86, 2016-03-17:
Wow, this is good news! Thank you for pointing this out.

mhaas, 2016-03-20:
We have something figured out. If you'd like to test a preliminary patch, go check the mailing list.

dariox86, 2016-03-20:
I'd like to. Exactly what is the patch and what is the patch to disregard?

mhaas, 2016-03-20:
This one: https://www.mail-archive.com/u-boot@lists.denx.de/msg207006.html

It's a hack, but it works for the lime2 for me.

I also need the following patch or the axp209/mv264xxx linux modules will lock up the board. YMMV.

````
commit d95334931b464c090e34325a226cd3d1f1cb0f3c
Author: Michael Haas <haas@computerlinguist.org>
Date:   Sun Mar 20 16:59:54 2016 +0100

    sunxi: power: Enable LDO3 and LDO4 again

    This reverts commit 02cc27c74f9b884b538bcd1b93342a4c05b5d608.

    This revert is required to avoid immediate hangups on
    Debian Jessie with 4.3.0-0.bpo.1-armmp-lpae on loading
    i2c-mv64xxx.

    Signed-off-by: Michael Haas <haas@computerlinguist.org>

diff --git a/drivers/power/Kconfig b/drivers/power/Kconfig
index adc6455..110e111 100644
--- a/drivers/power/Kconfig
+++ b/drivers/power/Kconfig
@@ -160,7 +160,7 @@ config AXP_ALDO2_VOLT
 config AXP_ALDO3_VOLT
        int "axp pmic (a)ldo3 voltage"
        depends on AXP209_POWER || AXP221_POWER || AXP818_POWER
-       default 0 if AXP209_POWER
+       default 2800 if AXP209_POWER
        default 3000 if MACH_SUN6I || MACH_SUN8I
        ---help---
        Set the voltage (mV) to program the axp pmic aldo3 at, set to 0 to
@@ -173,7 +173,7 @@ config AXP_ALDO3_VOLT
 config AXP_ALDO4_VOLT
        int "axp pmic (a)ldo4 voltage"
        depends on AXP209_POWER
-       default 0 if AXP209_POWER
+       default 2800 if AXP209_POWER
        ---help---
        Set the voltage (mV) to program the axp pmic aldo4 at, set to 0 to
        disable aldo4.
````

dariox86, 2016-03-27:
Tested your patch on my A20-OLinuXIno-LIME2. You are the man. It works.

dan-cristian, 2016-03-27:
great news. What is the speed (in both directions) you now get after applying the patch?

dariox86, 2016-03-27:
I get 600 Mb/s average in both directions between my Intel x86 macchine and my Lime2 connected through a 1000 Mb/s ethernet router (Vodafone Station Devolution, an ADSL home gateway).

dariox86, 2016-03-27:
Vodafone Station Revolution, sorry.

dan-cristian, 2016-03-27:
Thanks. Do you have by chance a quick guide / steps with how I can recompile my kernel and apply this patch myself?

dariox86, 2016-03-27:
You must recompile the bootloader, not the kernel. What operating system do you use on your client machine?

dan-cristian, 2016-03-27:
I use Vanilla Jessie image from http://www.armbian.com/olimex-lime-2/, http://mirror.igorpecovnik.com/Armbian_4.5_Lime2_Debian_jessie_4.2.3.zip

Thanks
Dan

dariox86, 2016-03-27:
Yes, I know, I read your previous post. I mean, what operating system do you use on your desktop system?

dariox86, 2016-03-27:
If it easier for you, you can cross-compile the bootloader on your desktop computer.
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
igorpecovnik, 2016-03-28:
@mhaas I am doing this blindly. Don't know. I only added a patch directly to lime2 config:
https://github.com/igorpecovnik/lib/blob/master/patch/u-boot/u-boot-next/lime2-enable-ldo4.patch
which I guess is needed in latest mainline uboot.

@dan-cristian

Quicker is manual u-boot compilation and installing a boot loader directly with DD. You can also compile native, on Lime, it does not take so long.

dariox86, 2016-03-28:
@igorpecovnik, "my" patch is @mhaas patch. I just applied it to the repository you see in my post. Are you still having severe speed issues with it?

mhaas, 2016-03-28:
@igorpecovnik the LDO3/LDO4 patch fixes a different issue where I/O ports E and G are disabled when they shouldn't be. Not an issue in itself, but re-enabling them causes hangs on my system.. different issue, I am not sure how that got mixed up.

Anyways, you will need ALL THREE patches of the following series:
https://patchwork.ozlabs.org/patch/602067/
AND
http://git.denx.de/?p=u-boot.git;a=commit;h=1eae8f66ff749409eb96e2f3f3387c56232d0b8a
AND
http://git.denx.de/?p=u-boot.git;a=commit;h=fc8991c61c393ce6a9d3dfc97cb56dbbd9e8cbba

On top of u-boot 2016.03. If you are using 2016.01, you don't need the last patch.

igorpecovnik, 2016-03-28:
OK, got it, mess is bigger than I thought. I already added one a patch from Hans, a week ago or so:
http://git.denx.de/?p=u-boot.git;a=commit;h=fc8991c61c393ce6a9d3dfc97cb56dbbd9e8cbba

Thanks for update.

dan-cristian, 2016-04-02:
I have also received a patch from Olimex that improves the speed and removes ping losses.
See test results below.

Patch and instructions can be downloaded from here:
https://drive.google.com/file/d/0B7WHuNCASY8cUF85UEZWTGltRG8/view?usp=sharing
The above u-boot works for both A20-OLinuXino-LIME2 and A20-SOM-EVB.

root@lime2:~# iperf3 -c 192.168.0.9 -R
Connecting to host 192.168.0.9, port 5201
Reverse mode, remote host 192.168.0.9 is sending
[  4] local 192.168.0.114 port 52134 connected to 192.168.0.9 port 5201
[ ID] Interval           Transfer     Bandwidth
[  4]   0.00-1.00   sec  66.8 MBytes   559 Mbits/sec
[  4]   1.00-2.00   sec  76.9 MBytes   645 Mbits/sec
[  4]   2.00-3.00   sec  77.1 MBytes   647 Mbits/sec
[  4]   3.00-4.00   sec  77.2 MBytes   648 Mbits/sec
[  4]   4.00-5.00   sec  77.0 MBytes   647 Mbits/sec
[  4]   5.00-6.00   sec  76.9 MBytes   643 Mbits/sec
[  4]   6.00-7.00   sec  75.9 MBytes   637 Mbits/sec
[  4]   7.00-8.00   sec  75.8 MBytes   637 Mbits/sec
[  4]   8.00-9.00   sec  76.8 MBytes   642 Mbits/sec
[  4]   9.00-10.00  sec  76.0 MBytes   638 Mbits/sec
- - - - - - - - - - - - - - - - - - - - - - - - -
[ ID] Interval           Transfer     Bandwidth       Retr
[  4]   0.00-10.00  sec   761 MBytes   638 Mbits/sec    6             sender
[  4]   0.00-10.00  sec   756 MBytes   634 Mbits/sec                  receiver

iperf Done.
root@lime2:~# iperf3 -c 192.168.0.9
Connecting to host 192.168.0.9, port 5201
[  4] local 192.168.0.114 port 52138 connected to 192.168.0.9 port 5201
[ ID] Interval           Transfer     Bandwidth       Retr  Cwnd
[  4]   0.00-1.01   sec  58.7 MBytes   487 Mbits/sec    0    293 KBytes
[  4]   1.01-2.01   sec  64.0 MBytes   540 Mbits/sec    0    390 KBytes
[  4]   2.01-3.02   sec  65.0 MBytes   540 Mbits/sec    0    458 KBytes
[  4]   3.02-4.01   sec  63.8 MBytes   540 Mbits/sec    0    481 KBytes
[  4]   4.01-5.01   sec  65.0 MBytes   543 Mbits/sec    0    587 KBytes
[  4]   5.01-6.02   sec  65.0 MBytes   542 Mbits/sec    0    735 KBytes
[  4]   6.02-7.00   sec  63.8 MBytes   543 Mbits/sec    0    772 KBytes
[  4]   7.00-8.01   sec  65.0 MBytes   541 Mbits/sec    0    772 KBytes
[  4]   8.01-9.02   sec  65.0 MBytes   541 Mbits/sec    0    772 KBytes
[  4]   9.02-10.01  sec  63.8 MBytes   539 Mbits/sec    0    772 KBytes
- - - - - - - - - - - - - - - - - - - - - - - - -
[ ID] Interval           Transfer     Bandwidth       Retr
[  4]   0.00-10.01  sec   639 MBytes   536 Mbits/sec    0             sender
[  4]   0.00-10.01  sec   639 MBytes   536 Mbits/sec                  receiver

dariox86, 2016-04-02:
How did you manage to get them to sent you this patch? The source code for it may be useful.

mhaas, 2016-04-03:
It's likely this set of files: https://www.olimex.com/forum/index.php?topic=4615.msg21467#msg21467

dan-cristian, 2016-04-04:
Yes, is that set of files indicated by Michael. I contacted Olimex support via email and they were very helpful and delivered the patch.

BTW, the Lime2 CPU stays at 99% while iperf-ing in average with 600 Mbits, so I wonder if the board can actually deliver faster network speeds (~900 mbit)? Is there any other optimisation that can be done?

Closed 2016-05-24.

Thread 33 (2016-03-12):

Wiki is Wrong, gpio module is missing

japita-se, 2016-03-12:
As in the example, if I type:
```
>>> from pyA10Lime.gpio import gpio
Traceback (most recent call last):
  File "<stdin>", line 1, in <module>
ImportError: cannot import name gpio
```

DanKoloff, 2016-03-21:
Hey, I couldn't find the text you mentioned in the wiki article of A10-OLinuXino-LIME. The wiki article is here: [A10-OLinuXino-LIME wiki](https://www.olimex.com/wiki/A10-OLinuXino-LIME)

Make sure to first download the python module if you have problems with it. It is available here: [pyA10Lime](https://pypi.python.org/pypi/pyA10Lime)

Best regards,
Lub/OLIMEX

Closed 2016-03-21.

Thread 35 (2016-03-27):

Lime2 schematics incorrect wrt VCC_CSI[0,1] label

mhaas, 2016-03-27:
Hi there,

the A20-OLinuXino-Lime2-Rev_*.pdf files list pins F19 and E18 as VCC_CSI0 and VCC_CSI1, respectively. This is a bit misleading as these are the generic power inputs for ports E & G (VCC-PE and VCC-PG) Someone may wrongly disable them if they don't use a CSI, which will disable the ports.

This was discovered by Iain Paton on the linux-sunxi mailing list:

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

Full message and thread context: https://www.mail-archive.com/linux-sunxi@googlegroups.com/msg17042.html

DanKoloff, 2016-03-29:
I see. We used this Allwinner document as original reference design: [a20_pad_std_v1_1.pdf @ sunxi](http://dl.linux-sunxi.org/A20/a20_pad_std_v1_1.pdf) - if you inspect the schematic you'd notice that the signals connected to E18 and E19 are named respectively CSI1-VCC and CSI0-VCC. Hence, this is where the wrong naming of our processor pins came from. I'll add the proposal for correction for the future hardware revision of the boards affected.

The difference between our boards and other boards come from the simple fact that their designs use 3.3V cameras, while we followed the original reference design and used 2.8V camera in A20-SOM-EVB (we even used the same camera - GT2005).

Closed 2016-05-25.

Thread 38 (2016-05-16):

What is the part number for VR1 in A20 Micro RVG1

dmsherazi, 2016-05-16:
AP1231-2.5V is mentioned but I need to get the datasheet or complete part number

DanKoloff, 2016-05-18:
There you go: https://drive.google.com/open?id=0BwplT87k9SCgVUFmMVc5QWRKN2c

There are a lot of similar voltage regulators.

Best regards,
Lub/OLIMEX

Closed 2016-05-18.

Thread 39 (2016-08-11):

Default SPI speed is much too slow

martinayotte, 2016-08-11:
Default SPI speed is much too slow !

I've an SPI LCD that was working fine in kernel 4.4.5, and suddenly was way too slow when I've upgraded to 4.5.x or 4.6.x. After some debugging, I've figured out that kernel was now using "transfer-speed" instead of "spi-device-max-speed", the first been set during ioctrl, but ignored/not-used in older kernels.

Here is the commit merge in Mainline 9 months ago :

https://github.com/megous/linux/commit/47284e3e0f3c427c93f8583549b6c938e8a18015

I've finally figured out that guilty code was in pyA20 providing a wrong default ioctrl value for the "transfer-speed" of 100kHz, while we all know that SPI default should be 10MHz :

```
diff pyA20-0.2.1/pyA20/spi/spi.c~ pyA20-0.2.1/pyA20/spi/spi.c
238c238
<     config.speed = 100000;

---
>     config.speed = 10000000;
```

FahriAyberk, 2016-09-20:
Dear martinayotte

I'm quite new to this board and Kernel (Olimex Micro A20) and have been trying to use this Python package to communicate through SPI for a while now.

Whenever I issue the spi.read() function Python aborts with the message below

`>>> spi.read(2)
*** stack smashing detected ***: python terminated
Aborted
`
My Image Is:
 ARMBIAN Debian GNU/Linux 8 (jessie) 3.4.112-sun7i

Even though I've tried many images and read many forums I couldn't figure out why? Since you have this issue with speed rather recently, I have hoped that you might already passed my level of problem.

martinayotte, 2016-10-17:
@FahriAyberk , sorry, I've no idea ...

DanKoloff, 2017-04-19:
Thanks for sharing your solution about the SPI speed. This issue is now closed.

martinayotte, 2017-04-19:
@DanKoloff , but there is no commit about this fix in pyA20 yet ...

DanKoloff, 2017-04-19:
Yes. But there is no pyA20 in the official images at all. Neither does the official images use Kernel 4.4.5. So I see how this information can be useful if somebody encounters something similar and that is fine. I fail to see how this is an issue for this specific repository.

martinayotte, 2017-04-19:
The fix should be applied there :
https://github.com/OLIMEX/OLINUXINO/blob/master/SOFTWARE/Python/pyA20/pyA20/spi/spi.c#L223

DanKoloff, 2017-04-20:
Oh, this code is outdated, it has more bugs even. It was uploaded at GitHib first, before starting committing in PyPi. The updated one is here: https://pypi.python.org/pypi/pyA20/0.2.1

Thanks for the report would make sure to point this python sub-repo to PyPi web-site until we decide what to do. Two repositories of code always lead to problems.

martinayotte, 2017-04-20:
From what I understand, the version from https://pypi.python.org/pypi/pyA20/0.2.1 is only a tarball done from the github version, since pypi.python.org doesn't shows any sources repository.
This probably mean that new 0.2.2 tarball should be done and placed on pypi.python.org.

Closed 2017-04-19.

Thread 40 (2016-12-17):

resize_sd missing

andreish, 2016-12-17:
found this : https://www.olimex.com/forum/index.php?topic=4580.0 , is this fixed?

DanKoloff, 2016-12-20:
Which board do you have exactly? Which Linux image are you using exactly?

By the way you can always use disk formatting software instead of the automatic resize script. It is not very hard to resize the partitions, especially if you are using the graphic environment.

DanKoloff, 2017-04-19:
Closed due to lack of dialog.

Closed 2017-04-19.

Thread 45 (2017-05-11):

GPIO-4 label GPIO2/3 on A20_LIME2_GPIOs.pdf is wrong

oliv3r, 2017-05-11:
The summary sheet A20_LIME2_GPIOs.pdf mentions GPIO2 and GPIO3 on connector GPIO-4 but that is actually wrong. It should be labled as PA9 and PA14.

GPIO2 and GPIO3 yield the intention that they are pins from the AXP209.

DanKoloff, 2017-05-12:
It seems like I didn't do the part about GPIO-4 at all... Will try to fix it as soon as possible.

DanKoloff, 2017-05-25:
updated it a bit, also uploaded the source file if someone wants to make changes

Closed 2017-05-26.

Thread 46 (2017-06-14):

4.3 LCD is using dithering by choice or accident?

oliv3r, 2017-06-14:
The 4.3 LCD display seems to be a true 24bit screen according to the datasheet (GFT043HA480272Y).

Yet we enable 6 colors per pixel dithering here:
https://github.com/OLIMEX/OLINUXINO/blob/master/SOFTWARE/A20/A20-build-3.4.103/script_change_display_3.4.103/change_display.sh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

Why is that? We should be able to set frm to 0 indicating a 24 bit, rather then an 18 bit display and thus disable color dithering.

DanKoloff, 2017-07-07:
Are you sure that changing this parameter does something? My oscilloscope shows some activity of the bits after 18 even if lcd_frm=1... I also can't find any visible difference - I ran two boards with two displays and one of them had lcd_frm=0 while the other lcd_frm=1.

In general, I not also sure if lcd_frm affects the color depth at all. I believe it simply affects the dithering. I also read something similar here, but i'm not sure about the current state: https://lists.denx.de/pipermail/u-boot/2015-January/200035.html

Can you elaborate further on your suggestion? Some tests or proof that lcd_frm actually makes a difference.

net147, 2017-08-07:
Some batches of LCD panels used in LCD-OLinuXino-4.3TS are actually 18-bit and require dithering otherwise you will see banding when displaying grayscale gradients on these displays. The datasheet doesn't necessarily match the panel as Olimex changes their supplier of LCD panels from time to time as availability changes. This means things like viewing angle and 18-bit/24-bit may change but hopefully the physical dimensions and data timings should be compatible as they switch suppliers.

oliv3r, 2017-08-08:
so some displays require dithering, where others do not, but isn't it a bit silly to drive a 24bit screen in 18 bit?

Either sell the display as 18 bit, or have 2 different part numbers I'd say.

oliv3r, 2017-08-08:
@DanKoloff for the fex stuff, i doubt or care it matters, but when driving these displays from mainline, it does matter as you then add it to the device-tree where it is actually picked up afaik.

net147, 2017-08-08:
@oliv3r Mainline doesn't support dithering at the moment. The registers used for dithering are undocumented.

oliv3r, 2017-10-19:
@net147 we'll figure it out eventually assuming the 3.4 registers actually work ...

as for the display, it makes supporting it really hard, if there's 2 kinds, and it's kind of hit-miss which one you get :( i guess 2 options would be needed then, olimex-4.3-24 and olimex-4.3-18 😭
but I guess it resolves the issue I suppose :)

Closed 2017-10-19.

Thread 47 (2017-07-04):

Not an eeschema file?

mkschreder, 2017-07-04:
I am not able to open any of the schematics with eeschema v4.0.6. I keep getting error about the file not being a vaild eeschema file. How can I open the schematics with kicad?

TsvetanUsunov, 2017-07-04:
Please upgrade to more decent KiCAD version and will be able to open
The current eschema we use is 4.4.0-83

mkschreder, 2017-07-04:
I'm using latest kicad git trunk. I'm still getting the same error. I'm just opening it with eeschema.

Error loading schematic file '/data/hardware/olinuxino/HARDWARE/H3-OLinuXino/H3-OLinuXino_Rev_A.sch'.
'/data/hardware/olinuxino/HARDWARE/H3-OLinuXino/H3-OLinuXino_Rev_A.sch' does not appear to be an Eeschema file

mkschreder, 2017-07-04:
Schematic files usually are text files. Are these eagle schematics? I though you guys were using KiCad for all of your projects? Not the case?

TsvetanUsunov, 2017-07-04:
you never mentioned that you open H3 design, yes this is old board made with Eagle

mkschreder, 2017-07-04:
But the only one that is not using eagle in that case is the A64 laptop
design? Do you have kicad BGA footprints and symbols somewhere?

On Tue, Jul 4, 2017 at 2:38 PM, TsvetanUsunov <notifications@github.com>
wrote:

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

TsvetanUsunov, 2017-07-04:
IIRC we decidedo to move to KiCAD 3 years ago all our new designs which started afterward are with KiCAD, but OLINUXINO project started 2012 and our old designs are with Eagle. Once design is started with Eagle it makes no sense to re-design with new CAD just because you want to add few components in the new revision.

xrbll, 2020-06-09:
so? i have the same error.

Closed 2017-07-04.

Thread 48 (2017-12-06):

AttributeError: module 'pyA20.spi' has no attribute 'open'

ManuelLatzo, 2017-12-06:
Armbian 5.35 , python 3.5 :
    SPII.open("/dev/spidev0.0", mode=0, bits_per_word=8, speed=500000)
AttributeError: module 'pyA20.spi' has no attribute 'open'

GPIO works fine.

StefanMavrodiev, 2017-12-06:
Which version of pyA20 you're using?

ManuelLatzo, 2017-12-06:
pyA20-0.2.11

StefanMavrodiev, 2017-12-08:
Fixed in [pyA20-0.2.12](https://github.com/StefanMavrodiev/pyA20)

Closed 2017-12-08.

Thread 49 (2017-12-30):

A64 Mainline - Debian arm64 kernel page state error

erikly01, 2017-12-30:
I was able to get it to boot Debian successfully using the [Sunxi bootloader](https://linux-sunxi.org/Mainline_U-Boot#Boot) and the [Debian ARM64 port](https://wiki.debian.org/Arm64Port), however I get the following kernel errors (below).

Does anyone have any clues as to how to resolve these problems?

```
[    1.186363] Freeing unused kernel memory: 448K
[    1.892064] systemd[1]: System time before build time, advancing clock.
[    1.973534] x_tables: version magic '4.13.13 SMP preempt mod_unload modversions aarch64' should be '4.13.13 SMP mod_unload aarch64'
[    1.985513] systemd[1]: Failed to insert module 'ip_tables': Exec format error
[    2.031000] systemd[1]: systemd 236 running in system mode. (+PAM +AUDIT +SELINUX +IMA +APPARMOR +SMACK +SYSVINIT +UTMP +LIBCRYPTSETUP +GCRYPT +GNUTLS +ACL +XZ +LZ4 +SECCOMP +BLKID +ELFUTILS +KMOD -IDN2 +IDN default-hierarchy=hybrid)
[    2.052054] systemd[1]: Detected architecture arm64.

Welcome to Debian GNU/Linux buster/sid!

[    2.069222] systemd[1]: Set hostname to <olimex>.
[    2.274027] BUG: Bad page state in process systemd-cryptse  pfn:7dd29UG: Bad page state in process systemd-cryptse  pfn:7dd29
[    2.280474] page:ffffffbf00f74a40 count:1 mapcount:0 mapping:          (null) index:0x1
[    2.288468] flags: 0x0()
[    2.291003] raw: 0000000000000000 0000000000000000 0000000000000001 00000001ffffffff
[    2.298735] raw: dead000000000100 dead000000000200 0000000000000000 0000000000000000
[    2.306463] page dumped because: nonzero _refcount
[    2.311244] Modules linked in:
[    2.314300] CPU: 0 PID: 119 Comm: systemd-cryptse Not tainted 4.13.13 #13
[    2.321076] Hardware name: Olimex A64-Olinuxino (DT)
[    2.326031] Call trace:
[    2.328485] [<ffffff8008086f68>] dump_backtrace+0x0/0x210
[    2.333879] [<ffffff8008087254>] show_stack+0x14/0x20
[    2.338926] [<ffffff80085c4360>] dump_stack+0x98/0xb8
[    2.343972] [<ffffff800813fc30>] bad_page+0xe0/0x140
[    2.348931] [<ffffff800813fce4>] free_pages_check_bad+0x54/0xb8
[    2.354842] [<ffffff8008140008>] free_pcppages_bulk+0x218/0x2f0
[    2.360754] [<ffffff8008141bf0>] free_hot_cold_page+0x1a8/0x1f0
[    2.366665] [<ffffff8008141f54>] free_hot_cold_page_list+0x34/0x60
[    2.372837] [<ffffff800814939c>] release_pages+0x27c/0x338
[    2.378319] [<ffffff800817ab18>] free_pages_and_swap_cache+0xb0/0xc8
[    2.384666] [<ffffff8008164c00>] tlb_flush_mmu_free+0x40/0x60
[    2.390404] [<ffffff8008165a98>] arch_tlb_finish_mmu+0x48/0x78
[    2.396229] [<ffffff8008165cb4>] tlb_finish_mmu+0x24/0x50
[    2.401622] [<ffffff800816dbf0>] exit_mmap+0xb0/0xf8
[    2.406582] [<ffffff800809f2ec>] mmput+0x44/0xf8
[    2.411194] [<ffffff80080a522c>] do_exit+0x26c/0x990
[    2.416152] [<ffffff80080a59b4>] do_group_exit+0x34/0xa0
[    2.421456] [<ffffff80080a5a30>] __wake_up_parent+0x0/0x28
[    2.426934] [<ffffff8008082ca0>] __sys_trace_return+0x0/0x4
[    2.432496] Disabling lock debugging due to kernel taint
```

jcstaudt, 2018-08-02:
Cross-referencing the [Olimex forum thread](https://www.olimex.com/forum/index.php?topic=6003.0).

Any progress figuring this out?  I have the same goal: getting Debian with a mainline kernel + mainline u-boot to run on the A64 OLinuXino.  Have you found any other good references from Sunxi or Debian?

hehopmajieh, 2018-08-02:
Please attach kernel config file and kernel version

На чт, 2.08.2018 г. в 7:04 ч. JC Staudt <notifications@github.com> написа:

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

FreshLuoBoGan, 2022-07-01:
i have this problem,how to resolve it
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

Closed 2020-10-13.

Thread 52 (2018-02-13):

Latest ubuntu a64 image torrent hangs on bootloader

Lewiscowles1986, 2018-02-13:
[Latest image torrent](https://www.olimex.com/wiki/images/1/1b/A64olinuxino_ubuntu_16.04.3_20171110.torrent)

flashed using etcher (so verified write), retried using several microSD cards. Unsure what the issue is.

[Previous image torrent](https://www.olimex.com/wiki/images/d/d5/A64-ubuntu_built_preliminary_rel_2.torrent) (which looks like the image in this git repo) works

https://www.olimex.com/Products/OLinuXino/A64/A64-OLinuXino/open-source-hardware

Using the 1GB a64 board with onboard storage

Does not output anything via USB TTL connected as-per [Quick Start Guide](https://www.olimex.com/Products/OLinuXino/A64/A64-OLinuXino/resources/A64-OLinuXino-quick-start.pdf)

DanKoloff, 2018-02-14:
Thanks for the report. The image seems to boot fine here but the video output is not set to HDMI. I also used Ethcher to prepare the card. I've added a note about the HDMI in the web-page of the board. The default output would be fixed in next official release.

I believe that you might have connected the USB TTL wrongfully. Or the different images might bring different power supply requirements.

Lewiscowles1986, 2018-02-14:
Thanks. It was a 4-pin USB->TTL.

I also use for a number of other SBC's but perhaps I need to re-read the docs, I remember something specific about 3.3v.

If it's fine by you I'd sooner leave this open until next release, that way you don't suffer duplicates until that happens.

Thanks again!

jcstaudt, 2018-08-14:
Hi @Lewiscowles1986, did you have any luck with eMMC-booting [Ubuntu 16.04.3 20180523 rel5](https://www.olimex.com/wiki/images/4/43/A64olinuxino_ubuntu_16.04.3_20180523_rel5.torrent)?

I only have tested with SD-boot, but this image works with UART and HDMI, though it doesn't always boot up in the most stable manner and sometimes requires a hard reset.  Most of the time the errors preventing boot are related to not discovering a USB hub, etc.  I was able to perform a distribution upgrade to 18.04LTS without issue (but only when I did it straight away from a fresh image - not after installing several software packages).

Lewiscowles1986, 2018-08-14:
Hi @jcstaudt,
Putting it on my list to try again at some point this week. TBF it's been sitting on the side since the end of the week I ran this.

I think I ran armbian on it, but stability was something a bit meh.

jcstaudt, 2018-08-14:
I'm attempting to get Armbian running properly when I have some spare time.  Here's the related [Armbian thread with an update from Igor Pečovnik](https://forum.armbian.com/topic/5862-a64-olinuxino).

Closed 2020-10-13.

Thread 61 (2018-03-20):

No USB ESD protection?

mkschreder, 2018-03-20:
Hello,

Is there no USB ESD protection on any of the olinuxino boards? I have looked at a few schematics and I could not find it. Is it usually built into the Allwinner soc?

DanKoloff, 2018-03-21:
USB cables and connector are grounded and this eliminates some of the ESD. There is no separate ESD protection for the USB ports. Additional IC or Zener diodes can be placed if somebody frequently has such problems. The main reason for the lack of such protection is that we haven't encountered ESD problems with the USBs and complicating the schematics further sometimes leads to more problems.

mkschreder, 2018-03-21:
Kinda hard to place extra diodes if it is a full board and not a som that plugs into a custom carrier. I also second the point about EC compliance. Good news is we can always just redesign the schematic and make our own versions. Thanks!

DanKoloff, 2018-03-21:
We have Allwinner SOM boards and you can use the open design of the evaluation boards compatible with the SOMs to tailor the USB circuit as you might like:

A20-SOM: https://www.olimex.com/Products/SOM/A20/A20-SOM/
A20-SOM204: https://www.olimex.com/Products/SOM204/A20/A20-SOM204/
A13-SOM-256: https://www.olimex.com/Products/SOM/A13/A13-SOM-256/
A13-SOM-512: https://www.olimex.com/Products/SOM/A13/A13-SOM-512/

Closed 2018-03-21.

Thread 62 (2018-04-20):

Using ethernet over usb for a33

kudep, 2018-04-20:
Hello!
I am trying to use Ethernet over usb on my olimex a33, but it isn't working.

I am using a official image from this github section.
Version of kernel is 3.4.39.1

Can somebody help me?

Nathan-Jonson, 2018-06-05:
There might be some helpful info in here:
https://forum.armbian.com/topic/1417-g_ether-driver-h3-device-as-ethernet-dongle/

Closed 2018-06-28.

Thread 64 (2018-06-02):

Eagle File unable to load in kicad, easyeda, openboardview

Nathan-Jonson, 2018-06-02:
I am unable to load the brd file for ```H3-OLinuXino``` in any program that I can find. Is it possible that the format is old?
The error message that comes up in kicad is ``` XML parsing error: 'not well formed (Invalid token)' at line one.```
The easyeda error message is something about an invalid utf character at line 1.
openboardview.org has same issue.

Any help appreciated.

Nathan-Jonson, 2018-06-02:
I looked into it a little more and it appears that the file is binary, not XML. Would it be possible to add XML format eagle files?

DanKoloff, 2018-06-04:
The design was made with CadSoft's EAGLE (now owned by Autodesk).

Nathan-Jonson, 2018-06-04:
Yes, I know. somewhere arround version 6 or so, they changed their file format from a binary to an xml format. A lot of tools can open the new xml format, however, only eagle can open the old binary files. My solution was to poen them in a free trial version of eagle, then save them in the new format.

easyw, 2018-06-04:
@DanKoloff
the solution, as pointed out by @Nathan-Jonson is to upload the file @GitHub in XML format instead of binary.
This can be done within Eagle, changing the way to save the file.

TsvetanUsunov, 2018-06-04:
@Nathan-Jonson the Eagle version we have full licensee and used to make this board is 4.16 we never upgraded since this version and this is the only file format it can save. To the best of my knowledge later versions read this format just fine but we do not use Eagle since 2 years so things may have changed.

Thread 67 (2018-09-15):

Olinuxino Lime2 Rev. K docs?

plaes, 2018-09-15:
I recently ordered some linuxino Lime2 boards (with eMMC) which are marked as revision K, but currently no information about the changes in these boards is present in the user manual.

DanKoloff, 2018-09-25:
Thank you for the notice! These are now available here: https://github.com/OLIMEX/OLINUXINO/tree/master/HARDWARE/A20-OLinuXino-LIME2

Also the text file describing the changes was updated: https://github.com/OLIMEX/OLINUXINO/blob/master/HARDWARE/A20-OLinuXino-LIME2/hardware_revision_changes_log.txt

plaes, 2018-09-25:
Thanks!

Closed 2018-09-25.

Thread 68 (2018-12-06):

What distro is best to use for the latest A20-build?

jcalfee, 2018-12-06:
I'm following this guide:

https://raw.githubusercontent.com/OLIMEX/OLINUXINO/master/SOFTWARE/A20/A20-build-3.4.103-release-8/BUILD_DESCRIPTION_A20_Olimex_kernel_3.4.103%2B_Jessie_rel_8.txt

These packages are not in apt-get in debian stretch (my typical selection) or debian squeeze:
`gcc-4.7-arm-linux-gnueabihf ncurses-dev`

What distro do you recommend for the build environment?  I'm using Docker so it is not a big deal to change it.  It is just tricky to find the distro that will both find the old version of gcc (gcc-4.7 gnueabihf) even when I try adding this repository:
```bash
deb http://www.emdebian.org/debian squeeze main
in the file below:
/etc/apt/sources.list
```

Please consider using something like docker, it will help to re-create the environment and builds..

DanKoloff, 2018-12-07:
Thank you for the contribution. Our sunxi kernel images and instructions were made using Ubuntu 16.04.3 LTS machine so it is entirely possible to have differences and problems with different distributions.

We switched to Ubuntu 18.04.1 LTS for the building of our Armbian-based images. Expect them out soon.

jcalfee, 2018-12-07:
Ok, next time I'll try Ubuntu 16 and look for notes about the upgrade.  Thanks..

Closed 2018-12-07.

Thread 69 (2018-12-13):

Build questions for: A20-build-3.4.103-release-8

jcalfee, 2018-12-13:
Step 5 says to write Uboot and **u-boot-sunxi-with-spl.bin** to the SD card.  I am however working with the LIME2 (not the LIME) so I did not build **u-boot-sunxi-with-spl.bin**.  This file is build in the `2.4 A20-OLinuXino-LIME board` section.  I ran the make in `2.1 A20-OLinuXino-LIME2 board` instead.

https://raw.githubusercontent.com/OLIMEX/OLINUXINO/master/SOFTWARE/A20/A20-build-3.4.103-release-8/BUILD_DESCRIPTION_A20_Olimex_kernel_3.4.103%2B_Jessie_rel_8.txt

Should I run the LIME build too?

jcalfee, 2018-12-13:
Also see 7.6, `# cp uEnv.txt.bin /mnt/sd` should be `# cp uEnv.txt /mnt/sd`

jcalfee, 2018-12-13:
Also, no seeds for `Debian_FS_34_103_Jessy_8.1_A20-olimex_rel_4.torrent`..

jcalfee, 2018-12-13:
Section 8: Change `# umount /mnt/sdX2` to `# umount /dev/sdX2`

DanKoloff, 2018-12-13:
> Should I run the LIME build too?

No, don't. LIME2 and LIME boards have different defconfigs - A20-OLinuXino-Lime2_defconfig and A20-OLinuXino-Lime_defconfig. I think that you missed the separator below the LIME (2.4) section. It is important to check if everything went ok with this part "At the end of the process you can check if everything is OK by using:"

> Also see 7.6, # cp uEnv.txt.bin /mnt/sd should be # cp uEnv.txt /mnt/sd

Corrected.

> Section 8: Change # umount /mnt/sdX2 to # umount /dev/sdX2

Corrected.

Thanks for the feedback.

jcalfee, 2018-12-13:
>think that you missed the separator below the LIME (2.4) section

Correct.

Can you please tell me what this is?
`./scripts/dtc-version.sh: line 18: dtc: command not found`

I don't think it is mail or xen as found here:
https://packages.debian.org/search?keywords=dtc&searchon=names&suite=stretch&section=all

pfalcon, 2018-12-13:
Google for "device tree compiler".

jcalfee, 2018-12-13:
I understand .. I don't know why there is no make command for dtc or why I did not end up with this made already by following the directions.

jcalfee, 2018-12-13:
ok, I found it in the debian apt package manager, but an older version..

jcalfee, 2018-12-13:
This is getting messy.   I think I'm going to start over with Ubuntu 16.04.3 LTS  ..

jcalfee, 2018-12-17:
Move the CD command up before the `git reset ...` and after `git clone ...`

```bash
Move the CD

Chapter 3. Building sunxi kernel from sources for A20 boards

---

The sunxi kernel sources for A20 are available at GitHub. Note that the our build uses this exact commit:

9a1cd034181af628d4145202289e1993c1687db6 from Sat Oct 4 07:59:35 2014 +0300

You can download the latest kernel sources using the following command:

# git clone https://github.com/linux-sunxi/linux-sunxi

You can switch to this exact commit with the next command:

# git reset --hard 9a1cd034181af628d4145202289e1993c1687db6

After the download navigate to the kernel directory:

# cd linux-sunxi/
```

Closed 2018-12-13.

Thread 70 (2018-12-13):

Build for: A20-build-3.4.103-release-8

jcalfee, 2018-12-13:
This [folder](https://github.com/OLIMEX/OLINUXINO/tree/master/SOFTWARE/A20/A20-build-3.4.103-release-8) has one build file and it is for "jessie":
**BUILD_DESCRIPTION_A20_Olimex_kernel_3.4.103%2B_Jessie_rel_8.txt**

The Debian "jessie" release does not work out so well.  I think it is time to update this, we can see in the directions it then tries to add a "squeeze" repository to the apt sources saying "if you use debian".

I have been unable to get a proper build with this file using various versions of Debian and using Ubuntu 16.04.  So, I recommend to pick one disto and test it well.   Use something like Docker and be sure it builds.

To get you started, this is how this might easily be done.  I'll set it up as documented with the inconstancy but you may take the opportunity to change to ubuntu and use a better tag for emdebian.org:

`./Dockerfile`
```Dockerfile
FROM debian:jessie
RUN echo deb http://www.emdebian.org/debian squeeze main >> /etc/apt/sources.list &&\
    apt-get update &&\
    apt-get install -y ca-certificates wget &&\
    wget https://raw.githubusercontent.com/OLIMEX/OLINUXINO/master/SOFTWARE/A20/A20-build-3.4.103-release-8/BUILD_DESCRIPTION_A20_Olimex_kernel_3.4.103%2B_Jessie_rel_8.txt
CMD bash
```
Then build the environment and get everything working:
```bash
docker build -t olimex .
mkdir -p ~/opt/a20-olimex

# --rm just removes dockers image of the "run" session (those take a lot of disk space)
docker run --rm -v ~/opt/a20-olimex:/a20-olimex -it olimex

# "run" runs the CMD in the docker file, that is "bash" .. so we get a bash shell in the docker
root@97554b8228ff:/# cd /a20-olimex/
root@97554b8228ff:/a20-olimex# apt-get install gcc-4.7-arm-linux-gnueabihf ncurses-dev uboot-mkimage build-essential git
...
# build everything ..

# save all the hard work and use it to update the Dockerfile above
history -a && cp ~/.bash_history /a20-olimex
exit
```

I have explored several avenues to try and get everything to build.  This is time consuming because the toolchain and code is picky and I'm not familiar with this process.  I can respect that you may only want to have 1 build file to maintain, but it really should work especially since there is a product for sale depending on this.  Using Docker opens the door to publishing an environments that work well and should cut down on your support issues. If you have any questions about docker I'm happy to help.

jcalfee, 2018-12-17:
Related:

> We switched to Ubuntu 18.04.1 LTS for the building of our Armbian-based images. Expect them out soon.

https://github.com/OLIMEX/OLINUXINO/issues/68#issuecomment-445209592

Closed 2020-10-13.

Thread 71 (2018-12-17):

A20-SOM - Debian stretch doesn't boot

gamelaster, 2018-12-17:
**Device**: OLIMEX-A20-SOM
**Image**: Armbian_5.65_Olinuxino-a20_Debian_stretch_next_4.19.9.img
(SD Card)
**Boot log**:
```

U-Boot SPL 2018.07-armbian (Dec 14 2018 - 10:13:25 +0200)
DRAM: 1024 MiB
CPU: 912000000Hz, AXI/AHB/APB: 3/2/2
EEPROM: Error
Trying to boot from MMC1

U-Boot 2018.07-armbian (Dec 14 2018 - 10:13:25 +0200) Allwinner Technology

CPU:   Allwinner A20 (SUN7I)
Model: Unknown
I2C:   ready
DRAM:  1 GiB
NAND:  0 MiB
MMC:   mmc@01c0f000: 0, mmc@01c12000: 1
Loading Environment from EXT4... ** File not found /boot/uboot.env **

** Unable to read "/boot/uboot.env" from mmc0:1 **
Failed (-5)
In:    serial
Out:   serial
Err:   serial
Allwinner mUSB OTG (Peripheral)
SCSI:  SATA link 0 timeout.
AHCI 0001.0100 32 slots 1 ports 3 Gbps 0x1 impl SATA mode
flags: ncq stag pm led clo only pmp pio slum part ccc apst
Net:   eth0: ethernet@01c50000
starting USB...
USB0:   USB EHCI 1.00
USB1:   USB OHCI 1.0
USB2:   USB EHCI 1.00
USB3:   USB OHCI 1.0
scanning bus 0 for devices... 1 USB Device(s) found
scanning bus 2 for devices... 1 USB Device(s) found
       scanning usb for storage devices... 0 Storage Device(s) found
Autoboot in 1 seconds, press <Space> to stop
switch to partitions #0, OK
mmc0 is current device
Scanning mmc 0:1...
Found U-Boot script /boot/boot.scr
3716 bytes read in 1 ms (3.5 MiB/s)
## Executing script at 43100000
U-boot loaded from SD
Boot script loaded from mmc
153 bytes read in 1 ms (149.4 KiB/s)
5215328 bytes read in 289 ms (17.2 MiB/s)
7263112 bytes read in 403 ms (17.2 MiB/s)
Found mainline kernel configuration
** File not found /boot/dtb/ **
libfdt fdt_check_header(): FDT_ERR_BADMAGIC
No FDT memory address configured. Please configure
the FDT address via "fdt addr <address>" command.
Aborting!
** File not found /boot/dtb/overlay/sun7i-a20-fixup.scr **
## Loading init Ramdisk from Legacy Image at 43200000 ...
   Image Name:   uInitrd
   Image Type:   ARM Linux RAMDisk Image (gzip compressed)
   Data Size:    5215264 Bytes = 5 MiB
   Load Address: 00000000
   Entry Point:  00000000
   Verifying Checksum ... OK
ERROR: Did not find a cmdline Flattened Device Tree
Could not find a valid device tree
SCRIPT FAILED: continuing...
Card did not respond to voltage select!
## Error: "bootcmd_nand" not defined
scanning bus for devices...
Found 0 device(s).

Device 0: unknown device

Device 0: unknown device
ethernet@01c50000 Waiting for PHY auto negotiation to complete......... TIMEOUT !
Could not initialize PHY ethernet@01c50000
=>

```

gamelaster, 2018-12-18:
@DanKoloff the problem's that u-boot don't know which model it's, so u-boot can't load the .dtb . Please can you fix it?

gamelaster, 2018-12-18:
+ systemd-modules-load.service fail to start (maybe some module don't get compiled or something just happen, I can't get log, it's incomplete for some reason)

DanKoloff, 2018-12-18:
Set the board manually from u-boot. Stop kernel boot and type olinuxino for info about available commands, there is a command for board list and board set. Read here: https://www.olimex.com/wiki/ArmbianHowTo

gamelaster, 2018-12-18:
@DanKoloff Thanks for information! Isn't possible to implement auto-detection in u-boot of the devices?

I enabled eMMC DTS because I thought it have eMMC. I find out that it's have NAND, I used default dts, anyway, I can't get NAND working.

Is there any instructions to get **minimally** u-boot from NAND?
Thanks

gamelaster, 2018-12-18:
I have older A20-SOM-EVB rev C, so probably "olinuxino" commands are useless for me since I have no EEPROM. What I should do?

StefanMavrodiev, 2018-12-18:
Today we made update to our image (kernel 4.19.10), that handles A20-SOM without EEPROM. If there is no EEPROM, the configuration is saved on the SDCARD, on sector 15.

Run:

    olinuxino config write 8922 C
    reset

gamelaster, 2018-12-18:
@StefanMavrodiev Thank you for this! Please, it will be possible to save this information into NAND? I want to run only from NAND without SD Card. I'm going to try the new image right now.
Thanks

StefanMavrodiev, 2018-12-18:
No. The current version of the u-boot doesn't support booting from the NAND. For now you can use the nand as rootfs or as generic storage.

gamelaster, 2018-12-18:
Ah, understand. Okay, thank you for information. Also, where can I get 4.19.10 (or at least u-boot.bin)? Or I must build it by myself?

StefanMavrodiev, 2018-12-18:
We are currently uploading it. Today or maybe tomorrow. You can get only the debs and install only u-boot and kernel:

On the board get linux-image-next-sunxi_5.65_armhf.deb and linux-u-boot-next-olinuxino-a20_5.65_armhf.deb and run:

    dpkg -i linux-image-next-sunxi_5.65_armhf.deb
    dpkg -i linux-u-boot-next-olinuxino-a20_5.65_armhf.deb
    reboot

StefanMavrodiev, 2018-12-18:
@gamelaster

ftp://staging.olimex.com/Allwinner_Images/A20-OLinuXino/Mainline%20A20%2018122018/

gamelaster, 2018-12-18:
@StefanMavrodiev the build works great! Also there is no problem with modules to start, so no errors while booting. Just, nand-sata-install still refusing to work, since no NAND detected ☹️

Closed 2020-10-13.

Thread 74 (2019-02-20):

Missing mounting hole locations on Lime2 shield

plaes, 2019-02-20:
Currently, Lime2 shield is missing the mounting hole locations on the shield. It would be nice to have the centers marked on the shield.

Also, it would be nice if the Eagle board/schematic files could be re-saved to newer XML-based format that KiCAD can import.

DanKoloff, 2020-10-13:
KiCAD can import Eagle files via plugin, but as all imports - a number of issues are expected.

Closed 2020-10-13.

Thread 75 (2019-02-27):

Question about power supply using AXP209 ic

shakenov-chinga, 2019-02-27:
Hi, everybody!
I am working on my personal project using allwinner A13 SoC. Thank you very much for your work and for sharing the schematics!
Right now I'm trying to use AXP209 PMIC, and I have a question about its usage:
I have noticed that wherever you use AXP209, you also use other parts, like SY8009AAAC and MP1584EN (or MP1482DS) and others. But in some cases, like in A13-SOM512 version you use only SY8009AAAC without AXP209, and also in A10S-OLinuXino-MICRO use only AXP152 without any additional parts. As I can deduce, one reason for this is that you don't have battary in these cases. My question is: why can't we use AXP209 without additional parts? As much as I can understand from AXP209 datasheet, they are not so necessary.
Thanks in advance!

shakenov-chinga, 2019-02-27:
Also found out that typical application schematics for AXP223 and AXP221 in datasheet also do not require additional IC parts, and you don't use additional parts with them too. Can't we use AXP209 the same way?

diogoviannaaraujo, 2023-02-24:
Wonder what were your experiences with the AXP209 IC.

Closed 2020-10-13.

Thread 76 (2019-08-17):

RT5350 release 3

ec1oud, 2019-08-17:
https://www.olimex.com/wiki/RT5350F-OLinuXino says release 3 was made in April.  Where is it available?

DanKoloff, 2019-08-19:
It can be found here: ftp://staging.olimex.com/Ralink/RT5350F-OLinuXino/1.latest_images/

DanKoloff, 2019-08-20:
The repository contains 6 files, 2 for each variant of Olimex-made RT5350 boards. We have three variants of RT5350F-OLinuXino - RT5350F-OLinuXino, RT5350F-OLinuXino-EVB, and RT5350F-OLinuXino-EVB+ (which is latest revisions of RT5350F-OLinuXino-EVB, starting revision C, with SD card and reset button, among others).  One of the files is for u-boot upload, the other is for luci upload. Read more about the upgrading here: https://openwrt.org/docs/guide-user/installation/generic.sysupgrade

ec1oud, 2019-08-21:
Thanks.  You might want to update the web page to link to that.

I'm running an 18.06.1 upstream release, which seems to work.  Are you adding more features to your own builds, or upstreaming everything to openwrt?  For example when it comes to gpio, I can control the relays and read the button state, but haven't been able to figure out how to wiggle other pins.  I want to try to use one of the pins on the UEXT connector as a chip select (for a CS5490).  I guess that means editing the dts file to make it available for that, if it's not already.  I would ask on the forum, but I've never been able to log in there (it's been more than a year); it keeps saying I have to register my account, so it will send an email to do that, but the email never comes.

DanKoloff, 2019-09-17:
Not huge differences compared to 18.06, visible here:

https://github.com/OLIMEX/openwrt/commit/16d698d67bf56af0a0370608f20f625a5002f07e

Closed 2020-10-13.

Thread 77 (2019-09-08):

This board does not use CONFIG_DM_VIDEO

benkinooby, 2019-09-08:
Hi,

when I build u-boot for A20 OLinuXino Micro from the [mainline u-boot repo](https://gitlab.denx.de/u-boot/u-boot) I get a warning as shown below

```
# make A20-OLinuXino_MICRO_defconfig
# make
...
  LD      spl/fs/built-in.o
  LDS     spl/u-boot-spl.lds
  LD      spl/u-boot-spl
  OBJCOPY spl/u-boot-spl-nodtb.bin
  COPY    spl/u-boot-spl.bin
  MKSUNXI spl/sunxi-spl.bin
  MKIMAGE u-boot.img
  COPY    u-boot.dtb
  MKIMAGE u-boot-dtb.img
  BINMAN  u-boot-sunxi-with-spl.bin
===================== WARNING ======================
This board does not use CONFIG_DM_VIDEO Please update
the board to use CONFIG_DM_VIDEO before the v2019.07 release.
Failure to update by the deadline may result in board removal.
See doc/driver-model/MIGRATION.txt for more info.
====================================================
```
If this warning does not apply to you, please close this ticket.

DanKoloff, 2019-09-10:
It is safe to ignore the warning. It is meant for us as a notice in the long term.

Closed 2019-09-10.

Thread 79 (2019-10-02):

Question&request about A20 lime2 sch and pcb files

sporubcan, 2019-10-02:
Hi,
in which software is sch and pcb drawn?
I need to know exact position of mounting holes relatively to GPIO connectors. Would it be possible to upload pick&place and update Kicad shield template to contain mounting holes position? Thank you.
Best regards, Samuel

DanKoloff, 2019-10-02:
What about this: https://www.olimex.com/Products/OLinuXino/A10/_resources/Ax0-OLINUXINO-LIME-dimensions.png ?

For the original design we used Eagle CAD. We used version 4.16 r2 Eagle. It is recommended to use older versions since they have free evaluation version good enough for viewing and measuring; while newer versions are subscription-based. I personally use version 7.5.

Closed 2020-10-13.

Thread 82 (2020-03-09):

please mention release date for each revision

jonassmedegaard, 2020-03-09:
README.md files documenting board revisions - e.g. `HARDWARE/A64-OLinuXino/README.md` would be more helpful if the date of release was included.

With release date, it would be possibly to rule out newer changes if I didn't know the revision of a board but knew when it was bought (if bought December 2018 then I can certainly rule out any board changes made after that time).

TsvetanUsunov, 2020-03-09:
define date of release :)

we first design the new revision, then make prototypes, then test them, if everything is OK run production of PCB, then if there are old revision blank PCBs we first use them all then replace the PCBs, it's long process. even when we start selling there are older revisions which are at our distributors on stock which may be confusing for some customers i.e. they see new PCB revision on GitHub but buy older revision from distributor.

jonassmedegaard, 2020-03-09:
the first ever date that anyone outside the company could get that revision of the board through normal channels (sales, gifts, etc.).

(i.e. if a board revision "leaks" - accidentally or intentionally - then I'd classify that as some kind of "pre-release" of that revision board)

I understand that multiple revisions exist concurrently "in the wild".  That's why my example was only about how I could eliminate _newer_ board revisions, not older ones.

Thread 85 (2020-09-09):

Misleading information on connecting to UART0 via USB-serial connection

miroR, 2020-09-09:
In chapter "LIME2-SERVER software installation" of
https://github.com/OLIMEX/OLINUXINO/blob/master/DOCUMENTS/LIME2-SERVER/LIME2-SERVER-User-Manual.pdf
it reads:
`the port must be a ttyACMx`
Pls. have a glance at how this lack of clear documentation, and actually misleading documentation fragment, kept me from figuring things out at:

 UART0 Connection to PC via USB-Serial-F Cable Fails
https://www.olimex.com/forum/index.php?topic=7806

No the port does not have to be ttyACMx. It can perfectly well be ttyUSBx.

And also the author of **cu** program admits in _man cu_ that:

> This program does not work very well.

and **cu**  is not among the good options for USB-serial connection from PC to LIME2 in the really good tutorial on:
Ubuntu - How do I connect to TTY_COM
https://www.youtube.com/watch?v=874XnIGjEjM

So, pls. fix this misleading documentation.

TsvetanUsunov, 2020-09-09:
Hi miroR,

Note that the document you quote do not require external USB-SERIAL-F cable.

If you boot the board and connect normal USB cable to the USB OTG port of LIME2 it will create ttyACMx on your Linux PC or COMx port on your Windows machine.

And sure you can use any other serial program like minicom etc instead of cu.
What is written in this document is simple example which works if you follow it step by step.
There may be many variations.

Please read again "Lime2 Server software installation" page, it's not written to use USB-SERIAL-F but to connect USB cable to the USB-OTG port and in this case ttyACMx will be created!

Best regards
Tsvetan

Closed 2020-09-09.

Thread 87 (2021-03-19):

UBOOT ISSUE with ethernet GMAC A20

akshar001, 2021-03-19:
We have used the hardware reference with KSZ9031 phy chip,

The problem is when in U-BOOT we try the command dhcp it shows DMA RESET TIMEOUT,

when we write mii dump 1 1 command ( our phy device is id is - 1 ) it actually shows the mii interface and link status is also 1 when ethernet cable is connected.

We think problem is in GMAC is not being identified in U-BOOT. Can anyone help with us?

DanKoloff, 2021-04-02:
Hmm, are you are creating your own board based on one of the Olimex designs?

What design is your board based on?

akshar001, 2021-04-02:
@DanKoloff it's fixed. The official image didn't included GMAC but letter we changed u-boot kernel and it's working.
We used lime2 design.

Closed 2021-04-02.

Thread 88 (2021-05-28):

A20-OLinuXino Linux uses kernel default qdisc

androidcho, 2021-05-28:
After some research I have found that the kernel's default "qdisc pfifo_fast" is used (or more likely not set).
It uses it for both the ETH interface of A20-LIME2 and the SocketCAN interface.
Setting "qdisc fq_codel" improved the ethernet link quality alot.
Setting "qdisc noqueue" for the CAN interface stopped it losing CAN frames.

DanKoloff, 2021-05-28:
Which LInux image did you use? One of the Olimage images?

androidcho, 2021-05-28:
> Which Linux image did you use? One of the Olimage images?
To be precise:
A20-OLinuXino-buster-minimal-20210318-122357.img

DanKoloff, 2021-05-28:
Perfect, thanks for this info and sharing your experience and advice. I will point the developers to this note to look into it.

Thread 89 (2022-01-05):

Spelling mistake or Logical mistake in Olimage-guide.pdf

toome123, 2022-01-05:
In example "how to toggle a GPIO pin via sysfs" page 27 there is spelling mistake or logical mistake:

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

parameter -o has value "program" but in the final line example try to execute "./test"
it's a logical mistake, but :)

DanKoloff, 2022-01-07:
Thanks, this is now fixed, revision D of document is now available.

Closed 2022-01-07.

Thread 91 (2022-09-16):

Issue in compilation of Olimex A20-build-3.4.103-release-8 image

harshalbhavsar632, 2022-09-16:
Hello Team,

We are trying to build "A20-build-3.4.103-release-8" this version on Ubuntu-20.04. We are referring "https://github.com/OLIMEX/OLINUXINO/tree/master/SOFTWARE/A20/A20-build-3.4.103-release-8" this link to build the image. But unfortunately we are facing issue to build the Kernel Image. I am providing some system details as well as error logs.

As per my understanding this build required GCC-4.7 version but I am not able to get this version any where and we required this Olimex version only. Please suggest us suitable changes.

I also tried to install Ubuntu 12.04 LTS but as we know its not supported any more.

Extra Changes which we did:
As per Document : apt-get install gcc-4.7-arm-linux-gnueabihf ncurses-dev uboot-mkimage build-essential git

We executed : apt-get install gcc-arm-linux-gnueabihf libncurses-dev u-boot-tools build-essential git

----------------------------------------------

System Details:
5.15.0-46-generic #49~20.04.1-Ubuntu SMP Thu Aug 4 19:15:44 UTC 2022 x86_64 x86_64 x86_64 GNU/Linux

-----------------------------------------------------------------
Error Logs:

a20-olimex/linux-sunxi# make ARCH=arm CROSS_COMPILE=arm-linux-gnueabihf- -j4 uImage
scripts/kconfig/conf --silentoldconfig Kconfig
warning: (VIDEO_PVRUSB2_DVB && VIDEO_CX18 && VIDEO_CX23885 && VIDEO_CX88_DVB && VIDEO_SAA7164 && DVB_USB_DIB0700) selects DVB_S5H1411 which has unmet direct dependencies (MEDIA_SUPPORT && DVB_CAPTURE_DRIVERS && DVB_CORE && I2C)
warning: (VIDEO_PVRUSB2_DVB && VIDEO_CX18 && VIDEO_CX23885) selects DVB_S5H1409 which has unmet direct dependencies (MEDIA_SUPPORT && DVB_CAPTURE_DRIVERS && DVB_CORE && I2C)
warning: (VIDEO_PVRUSB2_DVB && VIDEO_EM28XX_DVB && VIDEO_CX23885 && VIDEO_CX88_DVB && DVB_USB_CXUSB) selects DVB_LGDT330X which has unmet direct dependencies (MEDIA_SUPPORT && DVB_CAPTURE_DRIVERS && DVB_CORE && I2C)
warning: (VIDEO_PVRUSB2_DVB && VIDEO_CX23885 && VIDEO_SAA7134_DVB && VIDEO_SAA7164) selects DVB_TDA10048 which has unmet direct dependencies (MEDIA_SUPPORT && DVB_CAPTURE_DRIVERS && DVB_CORE && I2C)
warning: (VIDEO_PVRUSB2_DVB && VIDEO_CX18 && VIDEO_CX23885 && VIDEO_CX88_DVB && VIDEO_SAA7164 && DVB_USB_DIB0700) selects DVB_S5H1411 which has unmet direct dependencies (MEDIA_SUPPORT && DVB_CAPTURE_DRIVERS && DVB_CORE && I2C)
warning: (VIDEO_PVRUSB2_DVB && VIDEO_CX18 && VIDEO_CX23885) selects DVB_S5H1409 which has unmet direct dependencies (MEDIA_SUPPORT && DVB_CAPTURE_DRIVERS && DVB_CORE && I2C)
warning: (VIDEO_PVRUSB2_DVB && VIDEO_EM28XX_DVB && VIDEO_CX23885 && VIDEO_CX88_DVB && DVB_USB_CXUSB) selects DVB_LGDT330X which has unmet direct dependencies (MEDIA_SUPPORT && DVB_CAPTURE_DRIVERS && DVB_CORE && I2C)
warning: (VIDEO_PVRUSB2_DVB && VIDEO_CX23885 && VIDEO_SAA7134_DVB && VIDEO_SAA7164) selects DVB_TDA10048 which has unmet direct dependencies (MEDIA_SUPPORT && DVB_CAPTURE_DRIVERS && DVB_CORE && I2C)
  CHK     include/linux/version.h
  UPD     include/linux/version.h
  HOSTCC  scripts/genksyms/genksyms.o
  CC      scripts/mod/empty.o
  WRAP    arch/arm/include/generated/asm/auxvec.h
  WRAP    arch/arm/include/generated/asm/bitsperlong.h
  WRAP    arch/arm/include/generated/asm/cputime.h
  WRAP    arch/arm/include/generated/asm/emergency-restart.h
  WRAP    arch/arm/include/generated/asm/errno.h
  WRAP    arch/arm/include/generated/asm/ioctl.h
  WRAP    arch/arm/include/generated/asm/irq_regs.h
  WRAP    arch/arm/include/generated/asm/kdebug.h
  WRAP    arch/arm/include/generated/asm/local.h
  WRAP    arch/arm/include/generated/asm/local64.h
  WRAP    arch/arm/include/generated/asm/percpu.h
  WRAP    arch/arm/include/generated/asm/poll.h
  WRAP    arch/arm/include/generated/asm/resource.h
  WRAP    arch/arm/include/generated/asm/sections.h
  WRAP    arch/arm/include/generated/asm/siginfo.h
  WRAP    arch/arm/include/generated/asm/sizes.h
  HOSTCC  scripts/mod/mk_elfconfig
  MKELF   scripts/mod/elfconfig.h
  HOSTCC  scripts/mod/file2alias.o
  HOSTCC  scripts/selinux/genheaders/genheaders
  SHIPPED scripts/genksyms/lex.lex.c
  SHIPPED scripts/genksyms/keywords.hash.c
  SHIPPED scripts/genksyms/parse.tab.h
  SHIPPED scripts/genksyms/parse.tab.c
  HOSTCC  scripts/selinux/mdp/mdp
  HOSTCC  scripts/genksyms/lex.lex.o
  HOSTCC  scripts/genksyms/parse.tab.o
  HOSTCC  scripts/mod/modpost.o
  HOSTCC  scripts/kallsyms
  HOSTLD  scripts/genksyms/genksyms
  HOSTCC  scripts/mod/sumversion.o
  HOSTCC  scripts/pnmtologo
  HOSTCC  scripts/conmakehash
  HOSTCC  scripts/bin2c
  HOSTLD  scripts/mod/modpost
  CHK     include/generated/utsrelease.h
  UPD     include/generated/utsrelease.h
  Generating include/generated/mach-types.h
  CC      kernel/bounds.s
In file included from include/linux/compiler.h:48,
                 from include/linux/stddef.h:4,
                 from include/linux/posix_types.h:4,
                 from include/linux/types.h:17,
                 from include/linux/page-flags.h:8,
                 from kernel/bounds.c:9:
include/linux/compiler-gcc.h:103:1: fatal error: linux/compiler-gcc9.h: No such file or directory
  103 | #include gcc_header(__GNUC__)
      | ^~~~
compilation terminated.
make[1]: *** [/home/harshal/a20-olimex/linux-sunxi/./Kbuild:36: kernel/bounds.s] Error 1
make: *** [Makefile:987: prepare0] Error 2
-----------------------------------------

GCC Version:
a20-olimex/linux-sunxi# gcc --version
gcc (Ubuntu 9.4.0-1ubuntu1~20.04.1) 9.4.0
Copyright (C) 2019 Free Software Foundation, Inc.
This is free software; see the source for copying conditions.  There is NO
warranty; not even for MERCHANTABILITY or FITNESS FOR A PARTICULAR PURPOSE.

Thanks,
Harshal

hehopmajieh, 2022-09-16:
Hi,
GCC 4.7 toolchain can be found here :
https://releases.linaro.org/archive/13.05/components/toolchain/gcc-linaro/4.7/

Do not forget to set $PATH to no toolchain files location
p.s
https://askubuntu.com/questions/113291/how-do-i-install-gcc-4-7
~Best

On Fri, Sep 16, 2022 at 11:15 AM harshalbhavsar632 ***@***.***>
wrote:

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

harshalbhavsar632, 2022-09-17:
Thanks for your support.

I am trying to install your provided GCC compiler. But I am facing compile time error for it.

Error Logs:
./../.././libjava/prims.cc: In function ‘void _Jv_catch_fpe(int, siginfo_t*, void*)’:
../../.././libjava/prims.cc:192:3: error: invalid use of incomplete type ‘struct _Jv_catch_fpe(int, siginfo_t*, void*)::ucontext’
../../.././libjava/prims.cc:192:3: error: forward declaration of ‘struct _Jv_catch_fpe(int, siginfo_t*, void*)::ucontext’
make[5]: *** [Makefile:9895: prims.lo] Error 1
make[5]: Leaving directory '/home/harshal/Downloads/gcc-linaro-4.7-2013.05/x86_64-unknown-linux-gnu/32/libjava'
make[4]: *** [Makefile:10204: all-recursive] Error 1
make[4]: Leaving directory '/home/harshal/Downloads/gcc-linaro-4.7-2013.05/x86_64-unknown-linux-gnu/32/libjava'
make[3]: *** [Makefile:12760: multi-do] Error 1
make[3]: Leaving directory '/home/harshal/Downloads/gcc-linaro-4.7-2013.05/x86_64-unknown-linux-gnu/libjava'
make[2]: *** [Makefile:12724: all-multi] Error 2
make[2]: Leaving directory '/home/harshal/Downloads/gcc-linaro-4.7-2013.05/x86_64-unknown-linux-gnu/libjava'
make[1]: *** [Makefile:18522: all-target-libjava] Error 2
make[1]: Leaving directory '/home/harshal/Downloads/gcc-linaro-4.7-2013.05'
make: *** [Makefile:906: all] Error 2

---------------------------------------------

I have tried :
https://www.mail-archive.com/gcc-patches@gcc.gnu.org/msg168317.html

But still facing same issue. Do you have any reference.

Thanks,
Harshal

harshalbhavsar632, 2022-09-17:
Thanks for your support.

We are successfully installed GCC-4.7. But still facing same issue.

Current System Information:

root@harshal-Latitude-E5430-vPro:/usr/bin# ls -lrt gcc*
lrwxrwxrwx 1 root root      12 Mar 20  2020 gcc-ranlib -> gcc-ranlib-9
lrwxrwxrwx 1 root root       8 Mar 20  2020 gcc-nm -> gcc-nm-9
lrwxrwxrwx 1 root root       8 Mar 20  2020 gcc-ar -> gcc-ar-9
lrwxrwxrwx 1 root root      29 Mar  9  2022 gcc-ranlib-9 -> x86_64-linux-gnu-gcc-ranlib-9
lrwxrwxrwx 1 root root      25 Mar  9  2022 gcc-nm-9 -> x86_64-linux-gnu-gcc-nm-9
lrwxrwxrwx 1 root root      25 Mar  9  2022 gcc-ar-9 -> x86_64-linux-gnu-gcc-ar-9
lrwxrwxrwx 1 root root      22 Mar  9  2022 gcc-9 -> x86_64-linux-gnu-gcc-9
-rwxr-xr-x 1 root root 2133208 Sep 17 19:12 gcc-4.7
lrwxrwxrwx 1 root root       7 Sep 17 19:13 gcc -> gcc-4.7

------------------------
GCC Version Command Output:
root@harshal-Latitude-E5430-vPro:/usr/bin# gcc --version
gcc (Linaro GCC 4.7-2013.05) 4.7.4 20130508 (prerelease)
Copyright (C) 2012 Free Software Foundation, Inc.
This is free software; see the source for copying conditions.  There is NO
warranty; not even for MERCHANTABILITY or FITNESS FOR A PARTICULAR PURPOSE.

------------------------------------

Error Logs:
 HOSTCC  scripts/selinux/genheaders/genheaders
In file included from include/linux/compiler.h:48,
                 from include/linux/stddef.h:4,
                 from include/linux/posix_types.h:4,
                 from include/linux/types.h:17,
                 from include/linux/page-flags.h:8,
                 from kernel/bounds.c:9:
include/linux/compiler-gcc.h:103:1: fatal error: linux/compiler-gcc9.h: No such file or directory
  103 | #include gcc_header(__GNUC__)
      | ^~~~
compilation terminated.
make[1]: *** [/home/harshal/a20-olimex/linux-sunxi/./Kbuild:36: kernel/bounds.s] Error 1
make: *** [Makefile:987: prepare0] Error 2
make: *** Waiting for unfinished jobs....

--------------------------------------

Any Suggestion..

harshalbhavsar632, 2022-09-17:
Hello,

We resolved this issue using "ln -s compiler-gcc4.h compiler-gcc9.h" But now facing issue in return_address.c

Error Logs:
rch/arm/kernel/return_address.c:65:7: error: redefinition of ‘return_address’
   65 | void *return_address(unsigned int level)
      |       ^~~~~~~~~~~~~~
In file included from include/linux/ftrace.h:19,
                 from arch/arm/kernel/return_address.c:12:
/home/harshal/a20-olimex/linux-sunxi/arch/arm/include/asm/ftrace.h:48:21: note: previous definition of ‘return_address’ was here
   48 | extern inline void *return_address(unsigned int level)
      |                     ^~~~~~~~~~~~~~
make[1]: *** [scripts/Makefile.build:307: arch/arm/kernel/return_address.o] Error 1
make[1]: *** Waiting for unfinished jobs....
make: *** [Makefile:947: arch/arm/kernel] Error 2

----------------------------------------

We tried following points but still not resolved:
Reference : https://github.com/gumstix/live-build/issues/5

root@harshal-Latitude-E5430-vPro:/usr/bin# ls -lrt gcc*
lrwxrwxrwx 1 root root      29 Mar  9  2022 gcc-ranlib-9 -> x86_64-linux-gnu-gcc-ranlib-9
lrwxrwxrwx 1 root root      25 Mar  9  2022 gcc-nm-9 -> x86_64-linux-gnu-gcc-nm-9
lrwxrwxrwx 1 root root      25 Mar  9  2022 gcc-ar-9 -> x86_64-linux-gnu-gcc-ar-9
lrwxrwxrwx 1 root root      22 Mar  9  2022 gcc-9 -> x86_64-linux-gnu-gcc-9
-rwxr-xr-x 1 root root 2133208 Sep 17 19:12 gcc-4.7
lrwxrwxrwx 1 root root       7 Sep 17 19:13 gcc -> gcc-4.7
-rwxr-xr-x 1 root root  118608 Sep 17 20:46 gcc-ar-4.7
-rwxr-xr-x 1 root root  118536 Sep 17 20:46 gcc-nm-4.7
-rwxr-xr-x 1 root root  118552 Sep 17 20:47 gcc-ranlib-4.7
lrwxrwxrwx 1 root root      10 Sep 17 20:49 gcc-ar -> gcc-ar-4.7
lrwxrwxrwx 1 root root      14 Sep 17 20:49 gcc-ranlib -> gcc-ranlib-4.7
lrwxrwxrwx 1 root root      10 Sep 17 20:49 gcc-nm -> gcc-nm-4.7

We had soft link all GCC-4.7 compiled binary but still same error.

Please let me know if suggestion.

Thanks,
Harshal

harshalbhavsar632, 2022-09-24:
Hello Team,

We want to compile kernel for A20-OLinuXino-MICRO. Can anyone please suggest any release. Which is compiling properly on Ubuntu-20.04 version or any latest release.

Thanks,
Harshal

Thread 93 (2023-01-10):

Unable to reboot

stepfr64, 2023-01-10:
Hello,
Using Lime2 revG2 hardware, i tested nearly all reboot commands (reboot, poweroff --reboot, systemctl start reboot.target...). I also tried to change RebootWatchdogSec to 8s to use watchdog to help rebooting. But no luck, the system just hang (red led is on near power, but everything else is switch off).

Any way to reboot this arm device (when away) ? I can not remove the power cord remotely !

Thanks

Step

stepfr64, 2023-01-10:
the end of the log 👍
Jan 10 01:48:00 alarm systemd-journald[207]: Journal stopped
Jan 10 01:48:00 alarm systemd-journald[207]: Received SIGTERM from PID 1 (systemd-shutdow).
Jan 10 01:48:00 alarm systemd-shutdown[1]: Sending SIGTERM to remaining processes...
Jan 10 01:48:00 alarm systemd-shutdown[1]: Syncing filesystems and block devices.
Jan 10 01:48:00 alarm systemd-shutdown[1]: Watchdog running with a timeout of 8s.
Jan 10 01:47:59 alarm systemd-shutdown[1]: Using hardware watchdog 'sunxi-wdt', version 0, device /dev/watchdog0
Jan 10 01:47:59 alarm kernel: watchdog: watchdog0: watchdog did not stop!
Jan 10 01:47:59 alarm systemd[1]: Watchdog running with a timeout of 8s.
Jan 10 01:47:59 alarm systemd[1]: Using hardware watchdog 'sunxi-wdt', version 0, device /dev/watchdog0
Jan 10 01:47:59 alarm audit: BPF prog-id=0 op=UNLOAD
Jan 10 01:47:59 alarm audit: BPF prog-id=0 op=UNLOAD
Jan 10 01:47:59 alarm audit: BPF prog-id=0 op=UNLOAD
Jan 10 01:47:59 alarm audit: BPF prog-id=0 op=UNLOAD
Jan 10 01:47:59 alarm audit: BPF prog-id=0 op=UNLOAD
Jan 10 01:47:59 alarm audit: BPF prog-id=0 op=UNLOAD
Jan 10 01:47:59 alarm audit: BPF prog-id=0 op=UNLOAD
Jan 10 01:47:59 alarm systemd[1]: Shutting down.
Jan 10 01:47:59 alarm systemd[1]: Reached target System Reboot.
Jan 10 01:47:59 alarm audit[1]: SERVICE_STOP pid=1 uid=0 auid=4294967295 ses=4294967295 subj=_ msg='unit=systemd-reboot comm="systemd" exe="/usr/lib/systemd/systemd" hostname=? addr=? terminal=? res=success'
Jan 10 01:47:59 alarm audit[1]: SERVICE_START pid=1 uid=0 auid=4294967295 ses=4294967295 subj=_ msg='unit=systemd-reboot comm="systemd" exe="/usr/lib/systemd/systemd" hostname=? addr=? terminal=? res=success'
Jan 10 01:47:59 alarm systemd[1]: Finished System Reboot.
Jan 10 01:47:59 alarm systemd[1]: systemd-reboot.service: Deactivated successfully.
Jan 10 01:47:59 alarm systemd[1]: Reached target Late Shutdown Services.
Jan 10 01:47:59 alarm systemd[1]: Reached target System Shutdown.
Jan 10 01:47:59 alarm audit[1]: SERVICE_STOP pid=1 uid=0 auid=4294967295 ses=4294967295 subj=_ msg='unit=systemd-tmpfiles-setup-dev comm="systemd" exe="/usr/lib/systemd/systemd" hostname=? addr=? terminal=? res=success'
Jan 10 01:47:59 alarm systemd[1]: Stopped Create Static Device Nodes in /dev.
Jan 10 01:47:59 alarm systemd[1]: systemd-tmpfiles-setup-dev.service: Deactivated successfully.
Jan 10 01:47:59 alarm audit[1]: SERVICE_STOP pid=1 uid=0 auid=4294967295 ses=4294967295 subj=_ msg='unit=systemd-remount-fs comm="systemd" exe="/usr/lib/systemd/systemd" hostname=? addr=? terminal=? res=success'
Jan 10 01:47:59 alarm systemd[1]: Stopped Remount Root and Kernel File Systems.
Jan 10 01:47:59 alarm systemd[1]: systemd-remount-fs.service: Deactivated successfully.
Jan 10 01:47:59 alarm systemd[1]: Reached target Unmount All Filesystems.

stepfr64, 2023-01-11:
I use last Archlinuxarm image for lime2. Seems to reboot using armbian ( I tried) . So it must be a software image issue. I opened a ticket on archlinux forum also. If you already know this problem, i will forward any information

DanKoloff, 2023-01-12:
I also tested with Olimage Linux and it seems to reboot fine. It is definitely a software issue. Usually reboots and shutdowns are related to driver handling power management unit, in this case AXP209. Anyway, I am closing this issue since it is not something that Olimex team can fix. Maybe give Olimage Linux a try if you haven't already, you can find info about it here:

https://github.com/OLIMEX/OLINUXINO/blob/master/DOCUMENTS/OLIMAGE/Olimage-guide.pdf

rzr, 2023-12-17:
May this issue forwarded somewhere else, and please share your kernel versions because I've observed this on debian-12 too, and I know I had a armbian-10 that was working as expected

```
rzr@freedombox:~$ cat /proc/device-tree/model
Olimex A20-Olinuxino Micro

rzr@freedombox:~$ cat /proc/version
Linux version 6.1.0-13-armmp-lpae (debian-kernel@lists.debian.org) (gcc-12 (Debian 12.2.0-14) 12.2.0, GNU ld (GNU Binutils for Debian) 2.40) #1 SMP Debian 6.1.55-1 (2023-09-29)
```

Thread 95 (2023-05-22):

ethernet disconnect on A20-SOM204-EVB

a-sapuppo, 2023-05-22:
I unplug the ethernet cable, then plug it back in, the network remains disconnected.

image:
A20-OLinuXino-bullseye-base-20230515-130040.img

DanKoloff, 2023-05-22:
Umm, here it doesn't behave that way. It keeps reconnecting just fine. Here is a video I made today:

https://youtu.be/idBww0RQArs

What interface are you using GbE or MbE? Did you try re-writing the image? Can it be poor fit of the connector?

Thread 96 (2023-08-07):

Olimage-guide: suggestions

ilario, 2023-08-07:
Dear Olimex,
I am following the [Olimage-guide](https://github.com/OLIMEX/OLINUXINO/tree/master/DOCUMENTS/OLIMAGE) using a A64-OLinuXino-2Ge8G-IND with the [A64-OLinuXino-bullseye-base-20230515-130040.img.7z](https://images.olimex.com/release/a64/A64-OLinuXino-bullseye-base-20230515-130040.img.7z) image and I would suggest a few edits to the guide (and some other general issues, please point me to the right place for opening a ticket and I will open specific tickets there):

* For flashing the .img file on the SD card on Linux, I suppose one should use dd or gnome-disks, right? A word on this in the guide would be useful.
* When plugging the [USB-SERIAL-F](https://www.olimex.com/Products/Components/Cables/USB-Serial-Cable/USB-SERIAL-F/), it was clear where to plug the GND blue wire, but it was not obvious to me where to plug the Tx and Rx cable. I would add some tutorial in the guide, something like "The order is: blue wire (GND) attached to the pin close to the power plug, then red in the middle and green on the other side."
* On Windows 11, when I plugged the USB-SERIAL-F, I got a non-functioning entry in the Windows Device Manager named "THIS IS NOT PROLIFIC PL2303. PLEASE CONTACT YOUR SUPPLIER." (a ridiculous [message by Prolific](https://www.medo64.com/2022/05/really-prolific/)) and it took a while to figure out how to fix. I would suggest mentioning this message in the guide and detailing how to go on: download the 2008 driver linked at the [Olimex product page](https://www.olimex.com/Products/Components/Cables/USB-Serial-Cable/USB-SERIAL-F/), open the Windows Device Manager, right click the entry in Ports (COM&PLT), select Update driver > Browse my computer > Let me pick from a list of available drivers on my computer > select the newly installed "3.3.2.105 [10/27/2008]" one.
* The default serial connection parameters are the ones mentioned in the guide, but they do not work for A64. I had to change the Flow control from XON/XOFF to None.
* The speed (115200) is present in the screenshot included in the guide but it would be good to specify it also in the text, as it is mandatory.
* Following the guide, an optional step advised me to update the system. But when connecting the A64 to an ethernet cable with internet connection, connection is available. Actually I can see only the `lo` network interface... I just found the solution on this thread: https://www.olimex.com/forum/index.php?topic=7921.0 . The guide could mention the possible issue and point the user to the solution. I just saw that this is mentioned in the product page, but obviously I did not read it before XD
* I am not sure this is the correct place for this... In the [A64-OLinuXino-2Ge8G-IND product page](https://www.olimex.com/Products/OLinuXino/A64/A64-OLinuXino/open-source-hardware), an "8GB extra flash" is mentioned, but I cannot see in the guide how to mount this. It could be mentioned that it can be mounted with "mkdir /mnt/internal; mount /dev/mmcblk1p1 /mnt/internal". To have it automatically mounted would be ideal.
* In page 20 there is a typo: "ifconifg -a" which should be "ifconfig -a". Anyway it should be replaced with "ip address show"
* Another out-of-place comment: in the guide it is mentioned that the CPU temperature can be accessed with `cat /sys/class/thermal/thermal_zone0/temp`. It is unexpected that this is not included in the `sensors` command nor detected by `sensors-detect`.

Thanks for your amazing products!!

DanKoloff, 2023-08-22:
Thanks for the feedback. Most are good points I will look to implement, except the first one:

- using dd or gnome-disks is not recommended, users that know what they are doing don't need a guide on how to prepare an sd card for Linux, and this guide is meant for absolute beginners, so they should use BalenaEtcher or USBImager; I should expand that part of the guide tho since it is good idea to also test each card with F3 or H2testw beforehand; big chunk of all problems come from poor cards or poorly prepared cards;

ilario, 2023-08-22:
>     * using dd or gnome-disks is not recommended, users that know what they are doing don't need a guide on how to prepare an sd card for Linux, and this guide is meant for absolute beginners, so they should use BalenaEtcher or USBImager;

Yep, you are right, makes a lot of sense.

> I should expand that part of the guide tho since it is good idea to also test each card with F3 or H2testw beforehand; big chunk of all problems come from poor cards or poorly prepared cards;

Wow, good idea!
Also `badblocks -sn` or `badblocks -sw` could work for that (it could take very long time as it should do 4 passes, if a single one is enough, the `-t random` option could help).

More comments, again, please tell me if there are proper places for reporting these and I will copy them there:

* Once one soldered the UEXT pins on the A64-olinuxino board, it is not obvious which is the right direction for plugging the connector. A picture somewhere would help, for example in the UEXT guide PDF or in the A64-olinuxino quick start guide.
* The black metal box for the A64-olinuxino had zero extra space for the UEXT connector. After removing the plastic notch with a metal file (not easy without damaging the cable!) I managed to close the box with the connector plugged in. But there's quite some mechanical stress there. A metal box 1 or 2 mm wider would help.
* A recommendation of heat sink for the CPU would help. I bought this one, estimating that it would fit in the box, and it fits perfectly :D https://www.adafruit.com/product/3082
* In order to use I2C for connecting to MOD-IO2, I got very confused with i2cdetect showing random results on each launch, both with `i2cdetect 0` and `i2cdetect 1`. Finally I got that I had to activate the `sun50i-a64-i2c1.dtbo Enable TWI1 bus` overlay from `olinuxino-overlay` and then use `i2cdetect 1`. A mention on this would be useful to have on the A64-olinuxino quick start guide or on the UEXT guide PDF.

Thanks!

ilario, 2023-09-06:
This could be a security issue, and a fix should be suggested in the guide (or fixed in the OS image):

* both my A64-OLinuXino-2Ge8G-IND have the exact same SSH server key fingerprint. If this can be extrapolated to all the A64-OLinuXino-2Ge8G-IND units, it means that I could take the private key and use it for Man In The Middle attacks on SSH. I realized this when connecting to the second device:

```
$ ssh olimex@192.168.1.110
The authenticity of host '192.168.1.110 (192.168.1.110)' can't be established.
ED25519 key fingerprint is SHA256:E3xaihOuLtWT27+wajrRq9CEqDx+jCVKgdvKOLZuLtk.
This host key is known by the following other names/addresses:
    ~/.ssh/known_hosts:25: 192.168.1.111
Are you sure you want to continue connecting (yes/no/[fingerprint])?
```

And this can be confirmed logging in to both devices and running:

```
ssh-keygen -lf /etc/ssh/ssh_host_ed25519_key.pub
```

that for both devices gives:

```
256 SHA256:E3xaihOuLtWT27+wajrRq9CEqDx+jCVKgdvKOLZuLtk root@runner-gkasaxdh-project-10-concurrent-0 (ED25519)
```

ilario, 2023-09-06:
> It is good piece of info for new users. Will mention that in the manual too. But it is user's responsibility to delete or re-generate SSH keys. I'd consider that in the same league as using default user root and password olimex without changing it.

Mh, surely it has at least to be mentioned. I did not expect to have to do that. The only other similar situation I had was using OpenWrt, and its host key is generated at the first boot (the dropbear init script checks if the host key is valid and generates a valid one).

Just saw that on Raspbian there is a systemd service running only once and regenerating the host keys: https://github.com/RPi-Distro/raspberrypi-sys-mods/blob/master/debian/raspberrypi-sys-mods.regenerate_ssh_host_keys.service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. In my opinion, using this would be a valid solution also.

ilario, 2025-01-13:
Just checked the guide, and the recommendation to regenerate the SSH keys is not there, I think this is a serious security issue and users should be strongly encouraged to act.

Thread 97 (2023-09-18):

A64-OLinuXino Address and Control Routing

joshua2000, 2023-09-18:
<p>why did you choose point to point routing,while the design guidelines prefer a T-branch routing?</p>

DanKoloff, 2023-09-19:
Can you point me to the exact document and exact place in it where this is recommended?

joshua2000, 2023-09-21:
[A64 PCB Layout Guide V1.0.pdf](https://github.com/OLIMEX/OLINUXINO/files/12679155/A64.PCB.Layout.Guide.V1.0.pdf)
<p>kindly check page 21,though i have checked JEDEC rules and point to point is okay.  </p> Am just asking?

DanKoloff, 2023-09-21:
It is just there is a lot of sources for DDR routing, that's why I asked no offense. We have used the document you linked, we also have it available, but as you already figured out it is a matter of preference, we just preferred point to point. Also it is usually better to pick what the memory manufacturer recommends. We mainly used these three documents as basis for the RAM routing in our devices:

1. "DDR3 Design Requirements for KeyStone Devices" by Texas Instruments (SPRABI1B)
2. "Signal Integrity and PCB layout considerations for DDR2-800 Mb/s and DDR3 Memories" by Fidus Systems Inc.
3. "Design Implementation of DDR2 / DDR3 Interfaces From a PCB Designer Perspective in Cadence Allegro" by Michael Catrambone

joshua2000, 2023-09-21:
By the way i do love the work you guys do.Am a huge fan and i thank you for your time.i completely understand your point

Closed 2023-09-21.

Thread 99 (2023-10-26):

Distribute also linux-headers-5.10.x-xx-common package

ilario, 2023-10-26:
Dear Olimex,
I am trying to compile [w1-gpio-cl](https://github.com/pstolarz/w1-gpio-cl) in order to use 1-wire on A64-Olinuxino. See [here](https://www.olimex.com/forum/index.php?topic=9266.0) my previous failed attempts.

The problem is that after installing `linux-headers-5.10.180-olimex` I also needed to install `linux-headers-5.10.x-xx-common` relative to the same version as the headers.

In the Debian repository for Bullseye version, one can find only that package for the
5.10.178 [here](https://packages.debian.org/bullseye/kernel/linux-headers-5.10.0-22-common)
5.10.191 [here](https://packages.debian.org/bullseye/kernel/linux-headers-5.10.0-25-common)
5.10.197 [here](https://packages.debian.org/bullseye/kernel/linux-headers-5.10.0-26-common)
versions of the kernel, not the 5.10.180.

So it would be useful if you could include such a package in your repository.
Thanks!

ilario, 2023-10-26:
Sorry, checking again, the file I am looking for (asm/rwonce.h) should be included in another package, in Debian it is included in [linux-headers-5.10.0-26-arm64](https://packages.debian.org/bullseye/arm64/linux-headers-5.10.0-26-arm64/filelist).

Anyway I cannot find anything equivalent for 5.10.180.

Thanks!

ilario, 2023-10-26:
Also, having the linux-source with the same kernel version inside would be useful :)

ilario, 2024-12-19:
> I am trying to compile [w1-gpio-cl](https://github.com/pstolarz/w1-gpio-cl) in order to use 1-wire on A64-Olinuxino.

Just in case anyone arrives here searching for how to use 1-wire devices via GPIO on an A64-OLinuXino: the solution that worked for me is the one reported on https://github.com/OLIMEX/olinuxino-overlays/pull/3

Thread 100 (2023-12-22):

MiPi-DSI compatibility of A64-Olinuxino rev G

ilario, 2023-12-22:
Looking at the schematics of the A64-Olinuxino ["rev. E"](https://github.com/OLIMEX/OLINUXINO/blob/master/HARDWARE/A64-OLinuXino/1.%20Latest%20hardware%20revision/A64-OLinuXino%20hardware%20revision%20E/A64-OlinuXino_Rev_E.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) and ["rev. G"](https://github.com/OLIMEX/OLINUXINO/blob/master/HARDWARE/A64-OLinuXino/1.%20Latest%20hardware%20revision/A64-OLinuXino%20hardware%20revision%20G/A64-OlinuXino_Rev_G.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) I noticed that the pins exposed to the MiPi-DSI port have changed.

In the [PDF of the rev G](https://github.com/OLIMEX/OLINUXINO/blob/6d5f0784efe87214ef53cea6dccf8875b24e903e/HARDWARE/A64-OLinuXino/1.%20Latest%20hardware%20revision/A64-OLinuXino%20hardware%2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) appeared a phrase "Raspberry Pi 3 Model B+ DISPLAY Connector Compatible!!!". Which is great as [MiPi DSI is supported on A64 since the kernel 5.6](https://linux-sunxi.org/Linux_mainlining_effort#Merged_into_5.6).

Yet, the phrase seems wrong or at least not explicative enough, as:
* the port depicted in the rev G PDF shows 20 pins;
* the [Raspberry Pi 3 Model B+ display port has 30 pins](https://datasheets.raspberrypi.com/rpi3/raspberry-pi-3-b-plus-reduced-schematics.pdf).

Maybe the connector should be aligned in a specific position in order to work?

DanKoloff, 2024-01-03:
RPI display connector is 15-pin, pins 16-30 are not connected. If you see in our connector the first 15 pins are also the same as the 15 pins of RPI. The other 5 pins we have are optional.

If you use a ribbon cable between our A64's MIPI-DSI1 connector and RPI it should be fine (as long as orientation regarding pin #1 is proper).

We haven't tested it tho, due to the software effort required.

ilario, 2024-01-04:
> If you use a ribbon cable between our A64's MIPI-DSI1 connector and RPI it should be fine (as long as orientation regarding pin 1 is proper).

Ok, this is clear, thanks :)
So the only thing that I would add is to document somewhere that the cable has to be aligned to the pin number 1.
Thanks!

Closed 2024-03-20.

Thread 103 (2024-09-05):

Torrent file appears to be down [BitTorrent]

leuchtturmsss, 2024-09-05:
The torrent of official Debian Jessie release #13 for A20-OLinuXino-LIME2, A20-OLinuXino-LIME2-n4GB, and A20-OLinuXino-LIME2-n8GB appears to be down currently:

`magnet:?xt=urn:btih:d5a3b9702e7d147eb742dc0c271ba9c0d87d6c44&dn=a20-lime2%5Fmainline%5Fuboot%5Fsunxi%5Fkernel%5F3.4.103%5Fjessie%5FNAND%5Frel%5F13.img.7z&tr=udp%3A%2F%2Ftracker.leechers-paradise.org%3A6969&tr=http%3A%2F%2Fwww.wareztorrent.com%3A80%2Fannounce&tr=http%3A%2F%2Ftracker.dutchtracking.com%3A80%2Fannounce&tr=http%3A%2F%2Ftracker.dutchtracking.com%3A80%2Fannounce&tr=http%3A%2F%2Fp4p.arenabg.ch%3A1337%2Fannounce&tr=udp%3A%2F%2Ftracker.publicbt.com%3A80%2Fannounce&tr=udp%3A%2F%2Ftracker.coppersurfer.tk%3A6969&tr=udp%3A%2F%2Fexplodie.org%3A6969&tr=udp%3A%2F%2Ftracker.openbittorrent.com%3A80%2Fannounce&tr=udp%3A%2F%2Fp4p.arenabg.ch%3A1337&tr=udp%3A%2F%2Fp4p.arenabg.com%3A1337`
[[1](https://www.olimex.com/wiki/A20-OLinuXino-LIME2#Linux_images)]

I tried verifying it with [WebTorrent Checker](https://checker.openwebtorrent.com/) and it agreed that the torrent did not have any peers or seeders.

DanKoloff, 2024-09-30:
Torrents are long gone. You can find older images as direct download from our FTP:

https://ftp.olimex.com/Allwinner_Images/A20-OLinuXino-LIME2/Debian/sd/

Closed 2024-10-29.

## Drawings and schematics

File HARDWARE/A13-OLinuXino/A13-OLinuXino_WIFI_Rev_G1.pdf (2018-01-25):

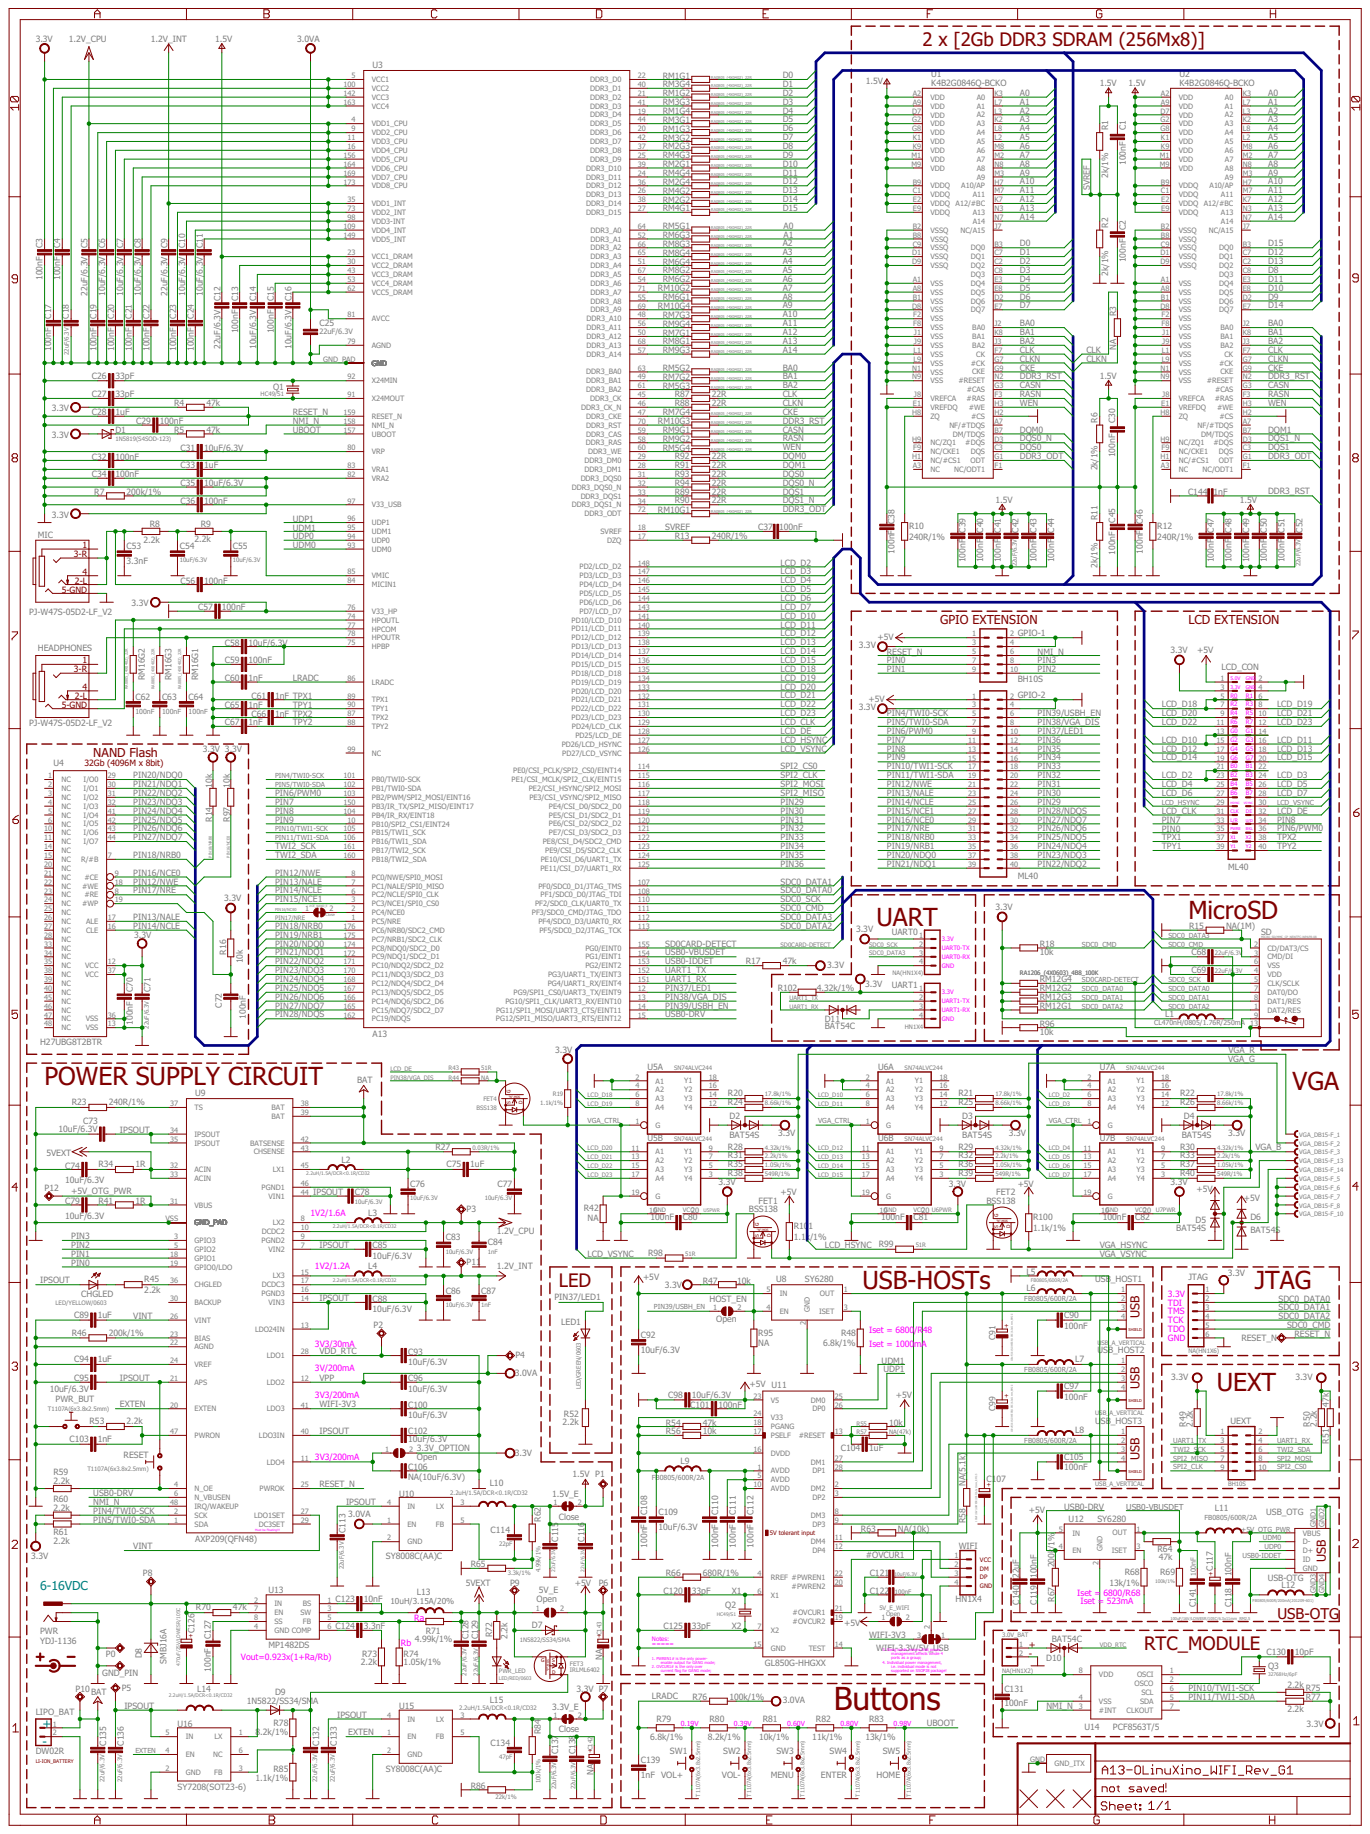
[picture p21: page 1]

management affects whole 4 Ra Rb Vout=0.923x(1+Ra/Rb)

enable output for GANG mode; 1. PWREN1# is the only power- Notes:
i.e. individual mode is not supported on SSOP28 package! =====

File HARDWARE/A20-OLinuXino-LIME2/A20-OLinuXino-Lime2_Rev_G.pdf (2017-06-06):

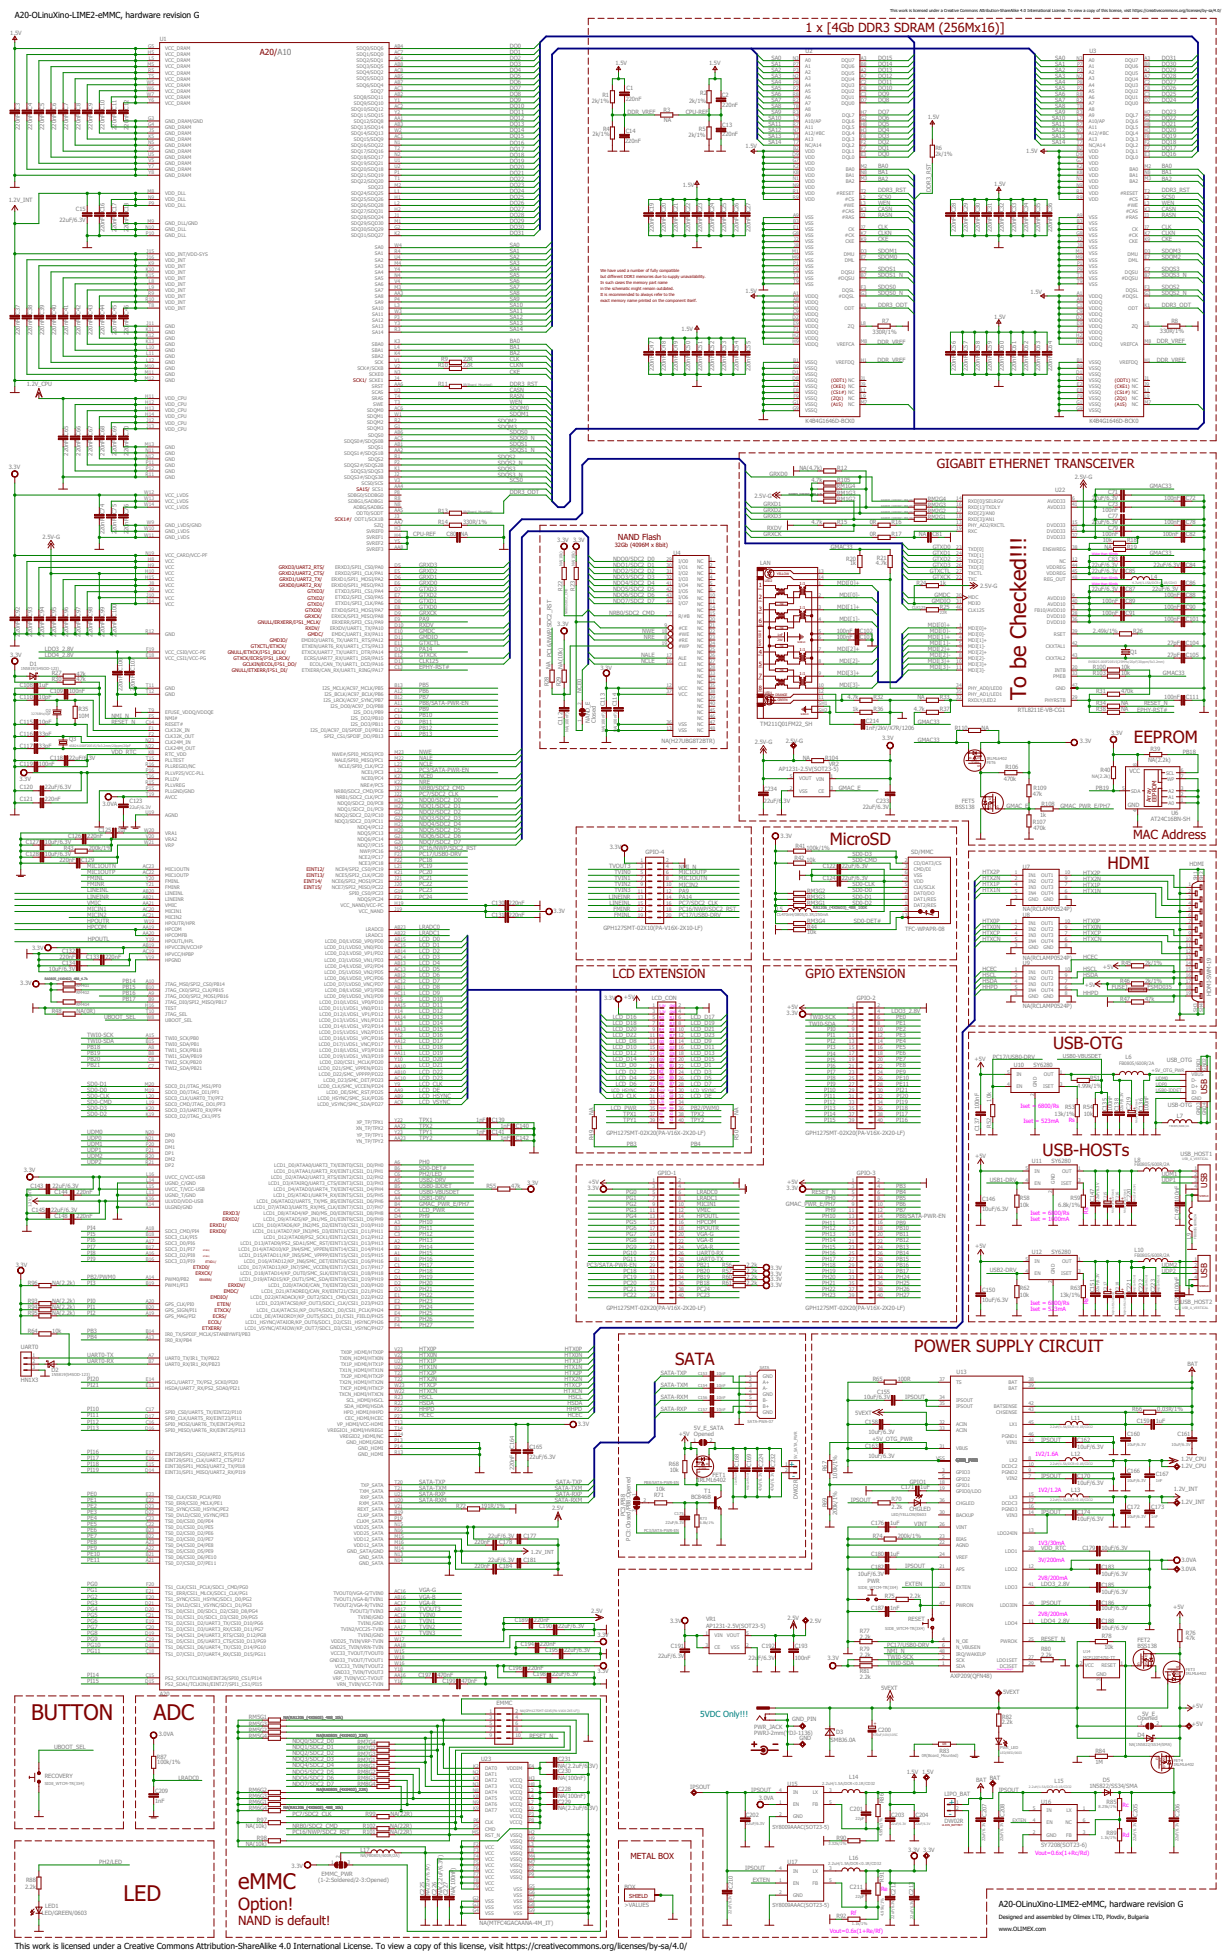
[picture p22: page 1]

A20-OLinuXino-LIME2-eMMC, hardware revision G

This work is licensed under a Creative Commons Attribution-ShareAlike 4.0 International License. To view a copy of this license, visit https://creativecommons.org/licenses/by-sa/4.0/

We have used a number of fully compatible but different DDR3 memories due to supply unavailability. In such cases the memory part name

in the schematic might remain outdated. It is recommended to always refer to the

exact memory name printed on the component itself.

Wider than 40mils Wider than 60mils Wider than 60mils

GRXD3/UART2_RTS/ GRXD2/UART2_CTS/ GRXD1/UART2_TX/ GRXD0/UART2_RX/ GTXD3/ GTXD2/ GTXD1/ GTXD0/ GRXCK/ GNULL/ERXERR/I²S1_MCLK/ RXDV/ GMDC/ GMDIO/ GTXCTL/ETXCK/ GNULL/ETXCK/I²S1_BCLK/ GTXCK/ECRS/I²S1_LRCK/ GCLKIN/ECOL/I²S1_DO/ GNULL/ETXERR/I²S1_DI/

NA(47uF/6.3V/tant) NA(47uF/6.3V/tant) NA(47uF/6.3V/tant) NA(47uF/6.3V/tant) NA(47uF/6.3V/tant) NA(22uF/6.3V) NA(22uF/6.3V) NA(22uF/6.3V) NA(22uF/6.3V)

Option! NAND is default!

Designed and assembled by Olimex LTD, Plovdiv, Bulgaria www.OLIMEX.com

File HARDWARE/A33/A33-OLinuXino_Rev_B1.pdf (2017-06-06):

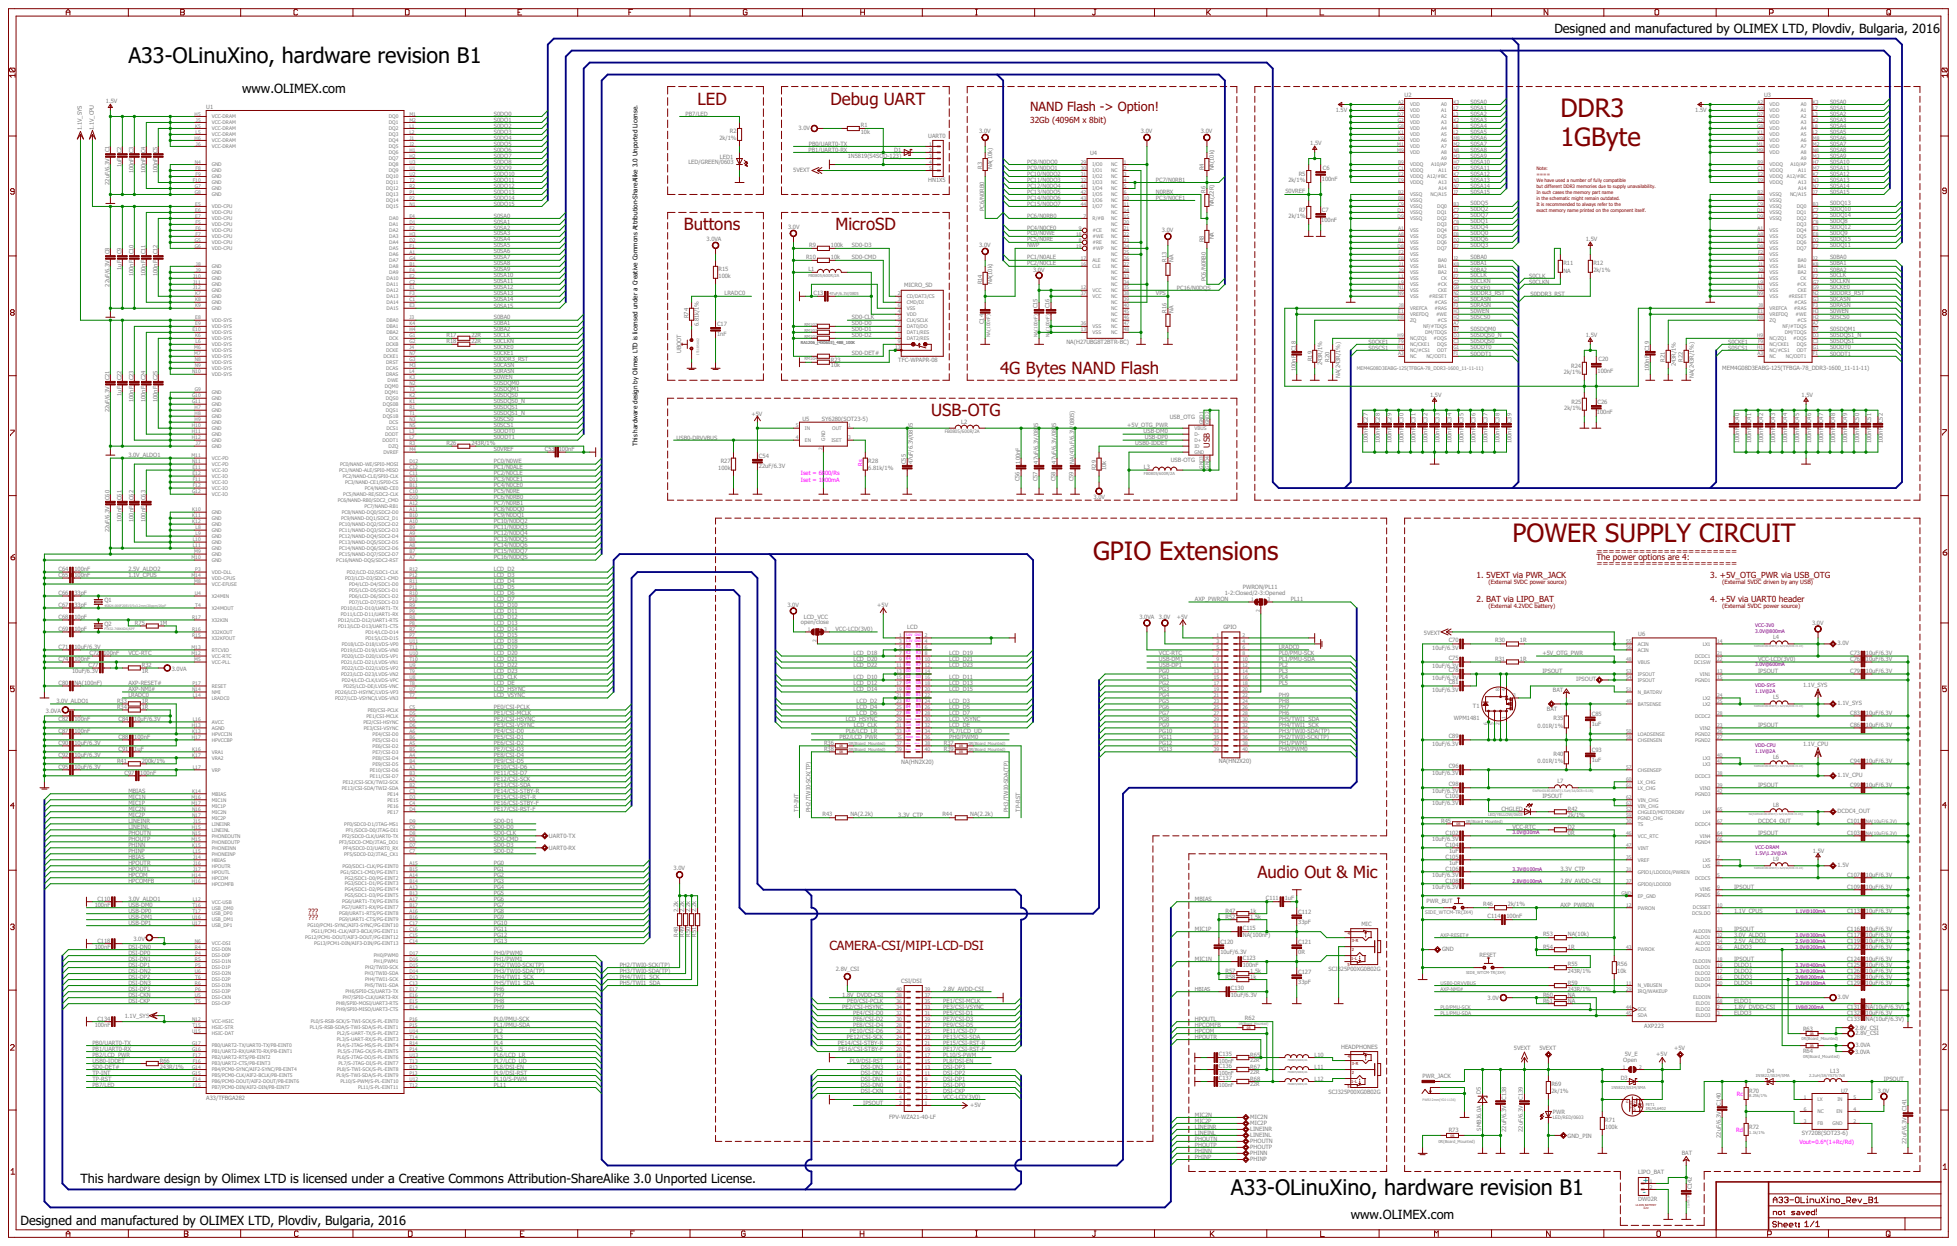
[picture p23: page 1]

Designed and manufactured by OLIMEX LTD, Plovdiv, Bulgaria, 2016 A33-OLinuXino, hardware revision B1

NAND Flash -> Option! 32Gb (4096M x 8bit) LED

This hardware design by Olimex LTD is licensed under a Creative Commons Attribution-ShareAlike 3.0 Unported License.

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

in the schematic might remain outdated. It is recommended to always refer to the

exact memory name printed on the component itself.

NA(H27UBG8T2BTR-BC) NA(100nF) NA(100nF) 3.0V

K9 L6 | VDD-SYS M6 VDD-SYS M7 VDD-SYS N8 VDD-SYS N9 VDD-SYS N10

J7 3.0V_ALDO1 N11 F11 G12 | VCC-PD M11

(External 5VDC driven by any USB) =======================

The power options are 4: 1. 5VEXT via PWR_JACK

PL0/PMU-SCK
PL1/PMU-SDA

Designed and manufactured by OLIMEX LTD, Plovdiv, Bulgaria, 2016

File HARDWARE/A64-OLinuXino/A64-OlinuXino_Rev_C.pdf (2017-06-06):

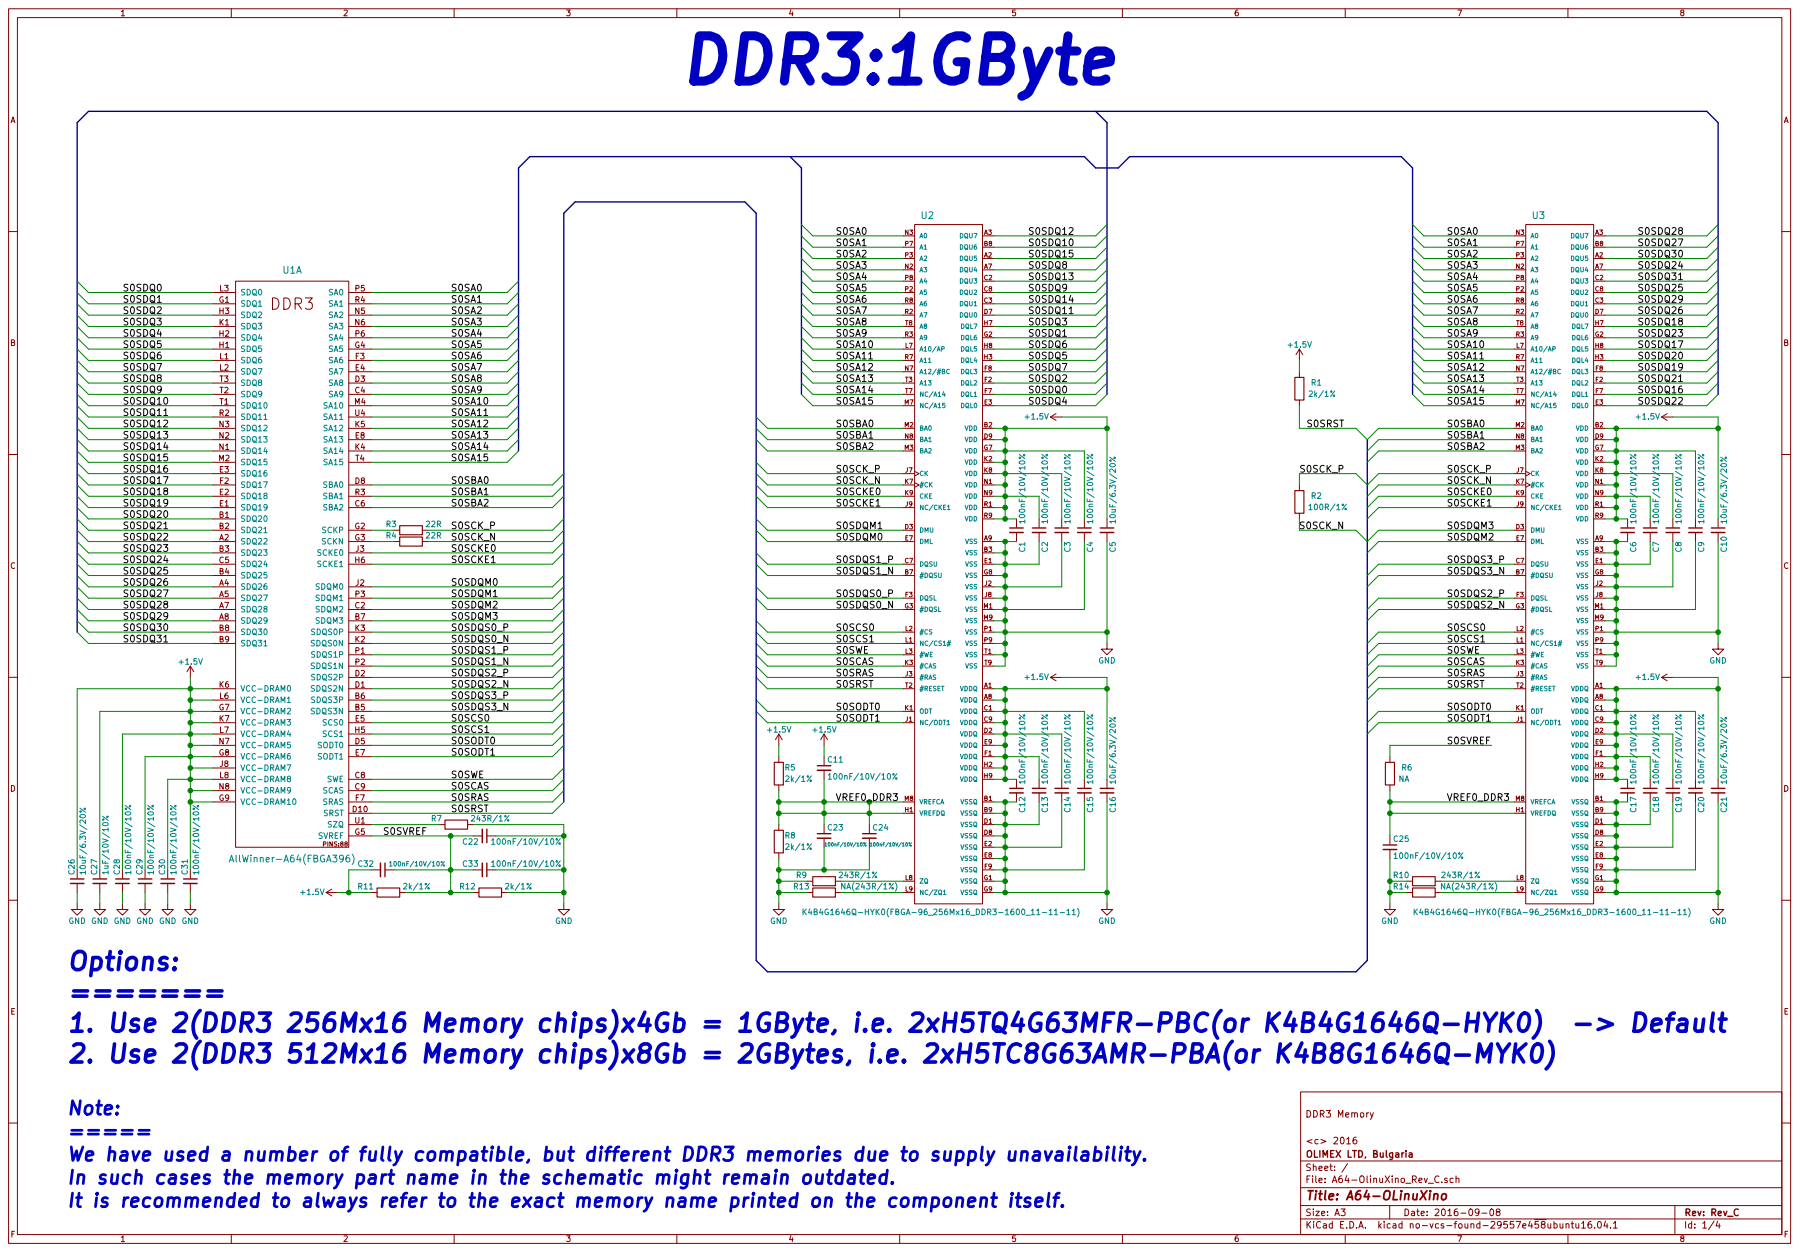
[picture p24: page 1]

GND
Options:
1. Use 2(DDR3 256Mx16 Memory chips)x4Gb = 1GByte, i.e. 2xH5TQ4G63MFR-PBC(or K4B4G1646Q-HYK0) -> Default
2. Use 2(DDR3 512Mx16 Memory chips)x8Gb = 2GBytes, i.e. 2xH5TC8G63AMR-PBA(or K4B8G1646Q-MYK0)

Note: ===== We have used a number of fully compatible, but different DDR3 memories due to supply unavailability.

In such cases the memory part name in the schematic might remain outdated.
It is recommended to always refer to the exact memory name printed on the component itself.

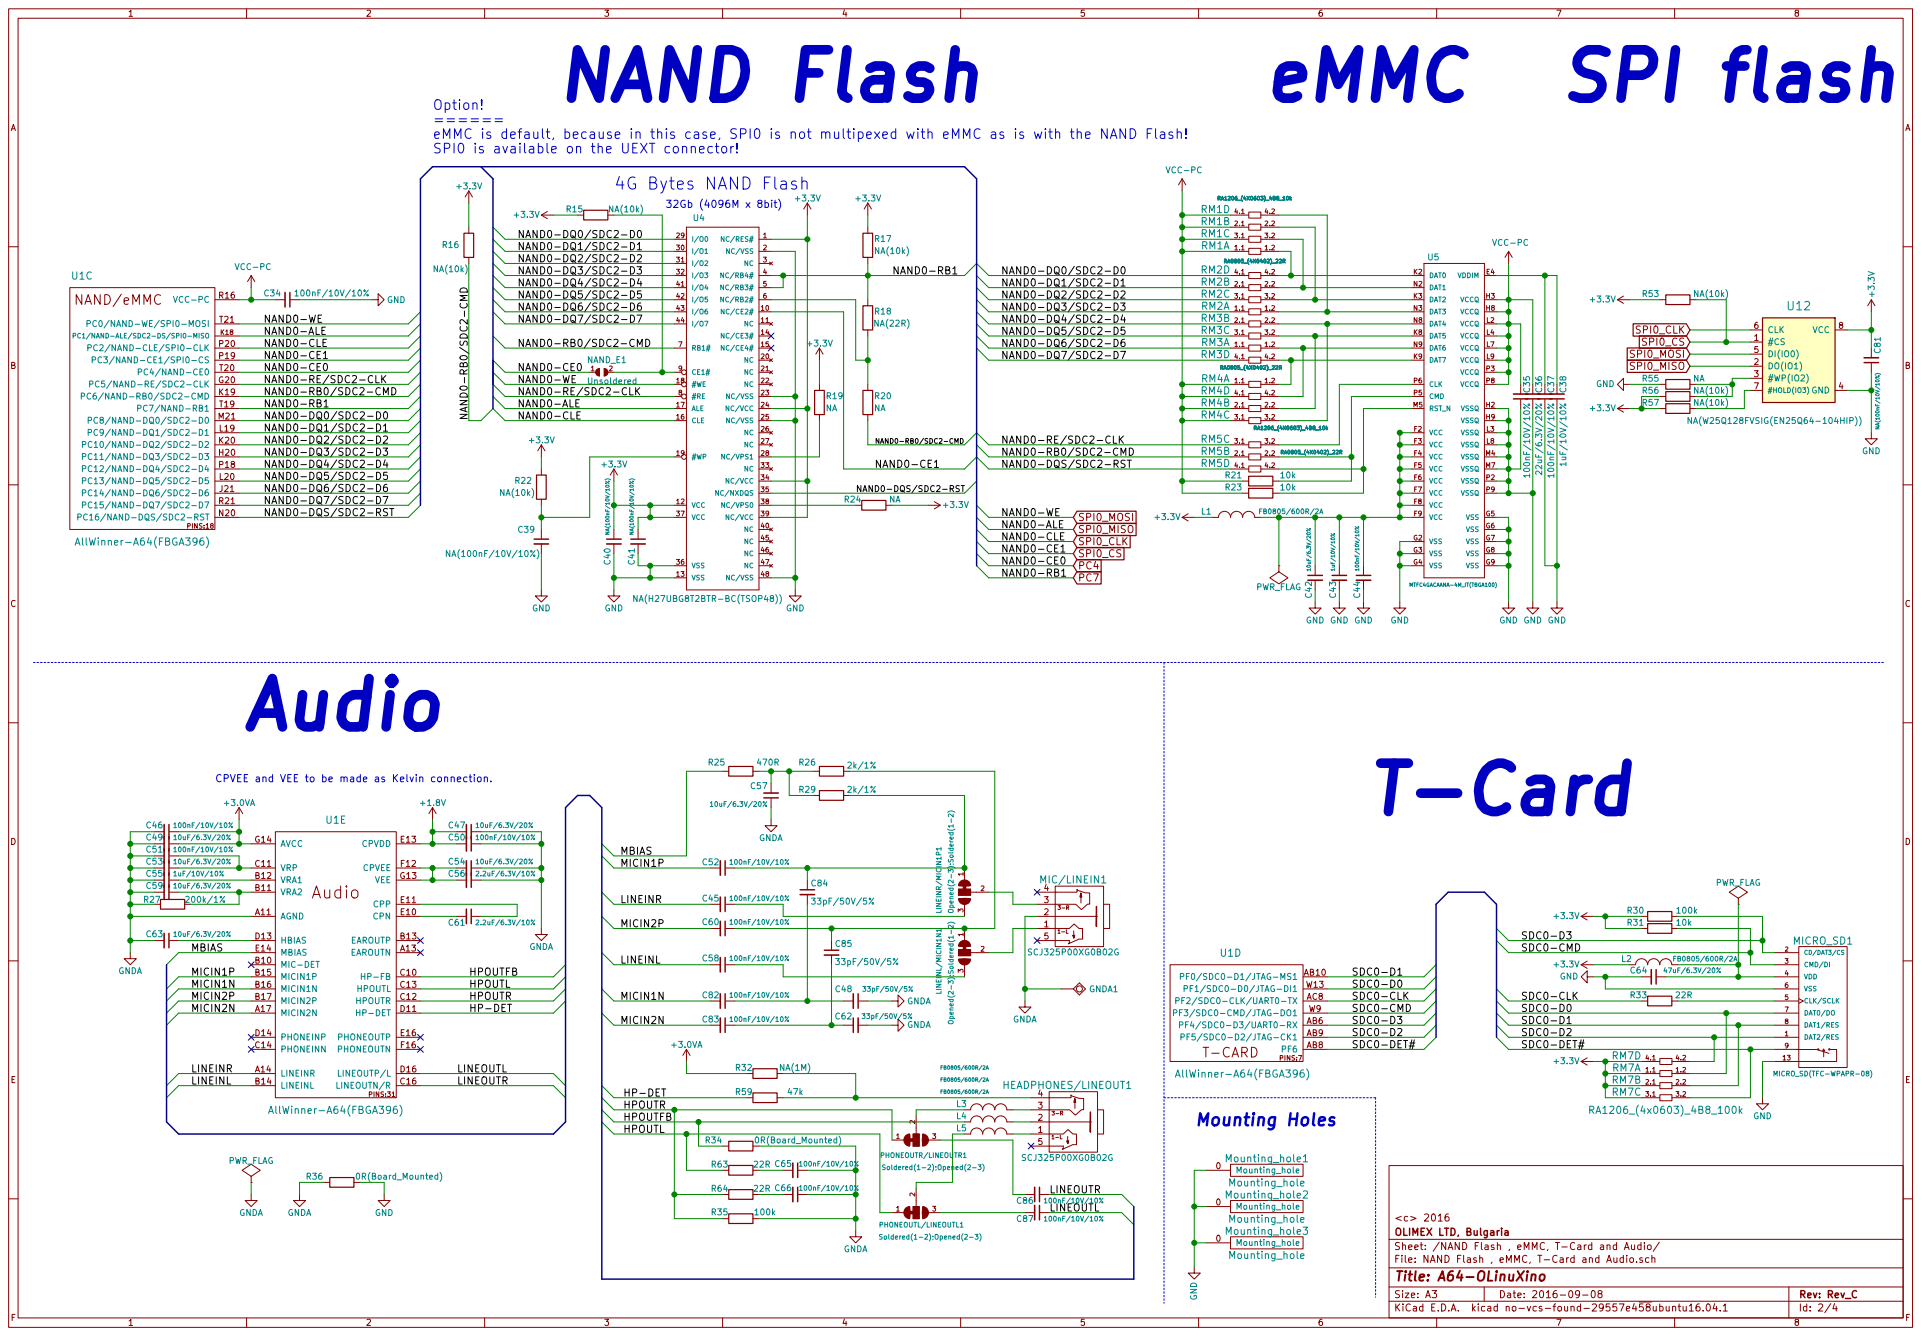
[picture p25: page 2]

OLIMEX LTD, Bulgaria <c> 2016 NAND Flash

eMMC is default, because in this case, SPI0 is not multipexed with eMMC as is with the NAND Flash!
+3.3V R16 NA(10k) NAND0-RB0/SDC2-CMD

NAND0-RB0/SDC2-CMD NAND0-CE1 NAND0-DQS/SDC2-RST 4G Bytes NAND Flash

NAND0-RE/SDC2-CLK C41 NA(100nF/10V/10%) C40 NA(100nF/10V/10%) GND

+1.8V CPVEE and VEE to be made as Kelvin connection. GNDA
LINEINL B14 PHONEINN C14 PHONEINP D14 MBIAS E14 AVCC G14 MICIN1P B15 MICIN1N B16

Sheet: /NAND Flash , eMMC, T-Card and Audio/
File: NAND Flash , eMMC, T-Card and Audio.sch
Id: 2/4 Title: A64-OLinuXino

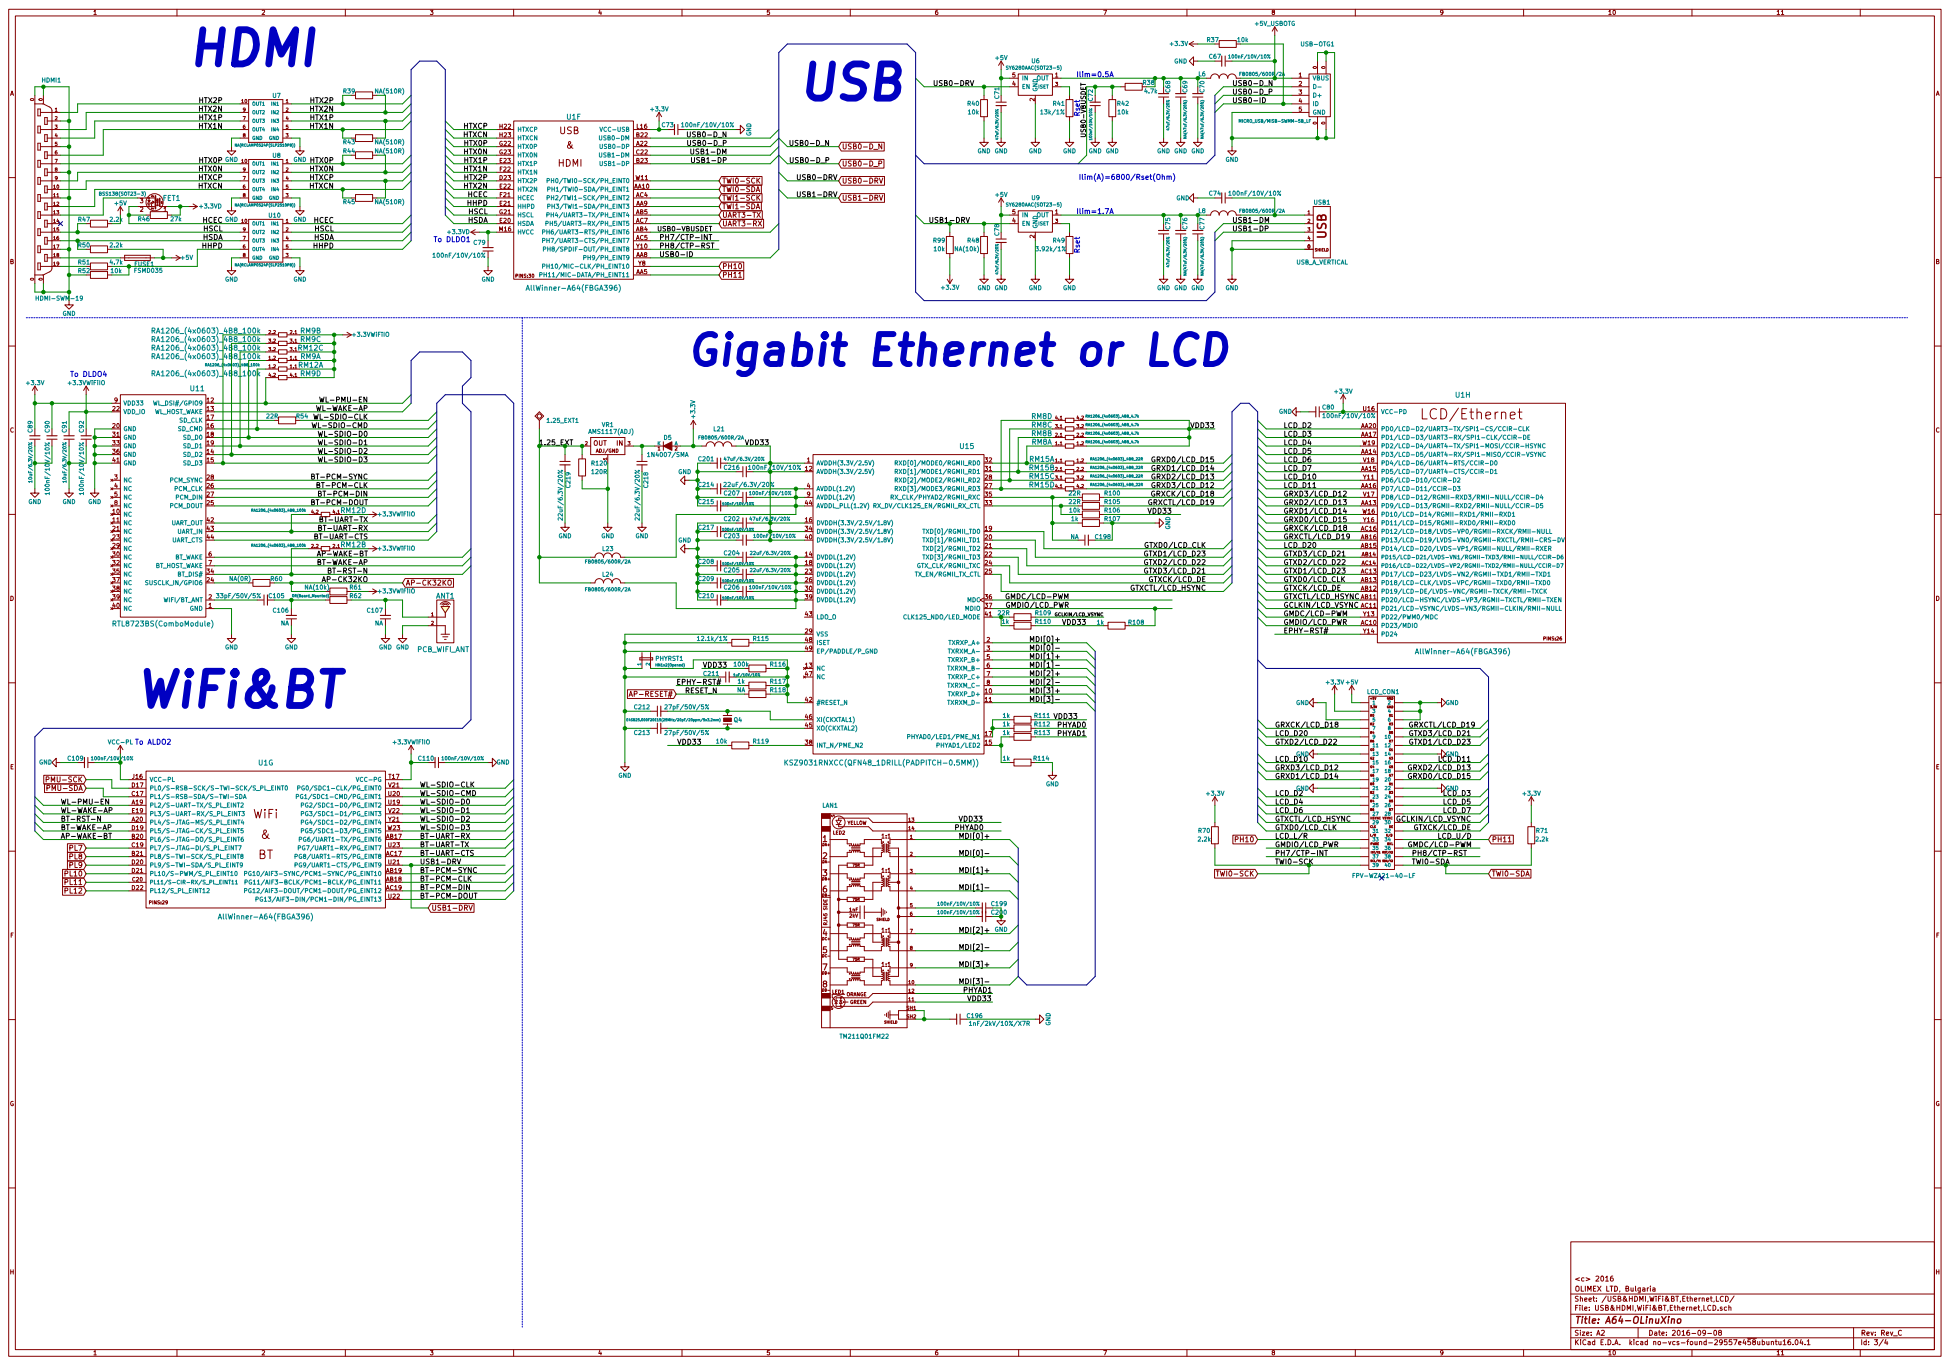
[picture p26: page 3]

OLIMEX LTD, Bulgaria <c> 2016 HDMI

10k GND C72 100nF/10V/10% GND
Ilim(A)=6800/Rset(Ohm) Rset Rset

U16 PD10/LCD-D14/RGMII-RXD1/RMII-RXD1 W16 PD11/LCD-D15/RGMII-RXD0/RMII-RXD0 Y16 PD8/LCD-D12/RGMII-RXD3/RMII-NULL/CCIR-D4 V17 PD4/LCD-D6/UART4-RTS/CCIR-D0 V18 PD2/LCD-D4/UART4-TX/SPI1-MOSI/CCIR-HSYNC W19 PD23/MDIO

AA20 PD20/LCD-HSYNC/LVDS-VP3/RGMII-TXCTL/RMII-TXEN
AC10 PD0/LCD-D2/UART3-TX/SPI1-CS/CCIR-CLK
AB16 PD12/LCD-D18/LVDS-VP0/RGMII-RXCK/RMII-NULL AC16 PD1/LCD-D3/UART3-RX/SPI1-CLK/CCIR-DE

AA14 PD15/LCD-D21/LVDS-VN1/RGMII-TXD3/RMII-NULL/CCIR-D6 AB14 PD16/LCD-D22/LVDS-VP2/RGMII-TXD2/RMII-NULL/CCIR-D7 AC14 PD5/LCD-D7/UART4-CTS/CCIR-D1 AA15 PD14/LCD-D20/LVDS-VP1/RGMII-NULL/RMII-RXER
AB12 PD9/LCD-D13/RGMII-RXD2/RMII-NULL/CCIR-D5 AA13 PD18/LCD-CLK/LVDS-VPC/RGMII-TXD0/RMII-TXD0 AB13 PD17/LCD-D23/LVDS-VN2/RGMII-TXD1/RMII-TXD1 AC13 PD3/LCD-D5/UART4-RX/SPI1-MISO/CCIR-VSYNC

PINS:26 PD6/LCD-D10/CCIR-D2 Y11 PD22/PWM0/MDC
AB15 PD7/LCD-D11/CCIR-D3 AA16 PD13/LCD-D19/LVDS-VN0/RGMII-RXCTL/RMII-CRS-DV

BT-PCM-DOUT AP-WAKE-BT BT-WAKE-AP

AP-WAKE-BT BT-WAKE-AP

AB11 PD21/LCD-VSYNC/LVDS-VN3/RGMII-CLKIN/RMII-NULL AC11 PD19/LCD-DE/LVDS-VNC/RGMII-TXCK/RMII-TXCK

WL-SDIO-CMD
WL-SDIO-D0
WL-SDIO-D1
WL-SDIO-D2
WL-SDIO-D3 BT-UART-RX
BT-UART-TX
BT-UART-CTS
USB1-DRV
BT-PCM-SYNC
BT-PCM-CLK
BT-PCM-DIN
BT-PCM-DOUT

Sheet: /USB&HDMI,WiFi&BT,Ethernet,LCD/
File: USB&HDMI,WiFi&BT,Ethernet,LCD.sch
Id: 3/4 Title: A64-OLinuXino

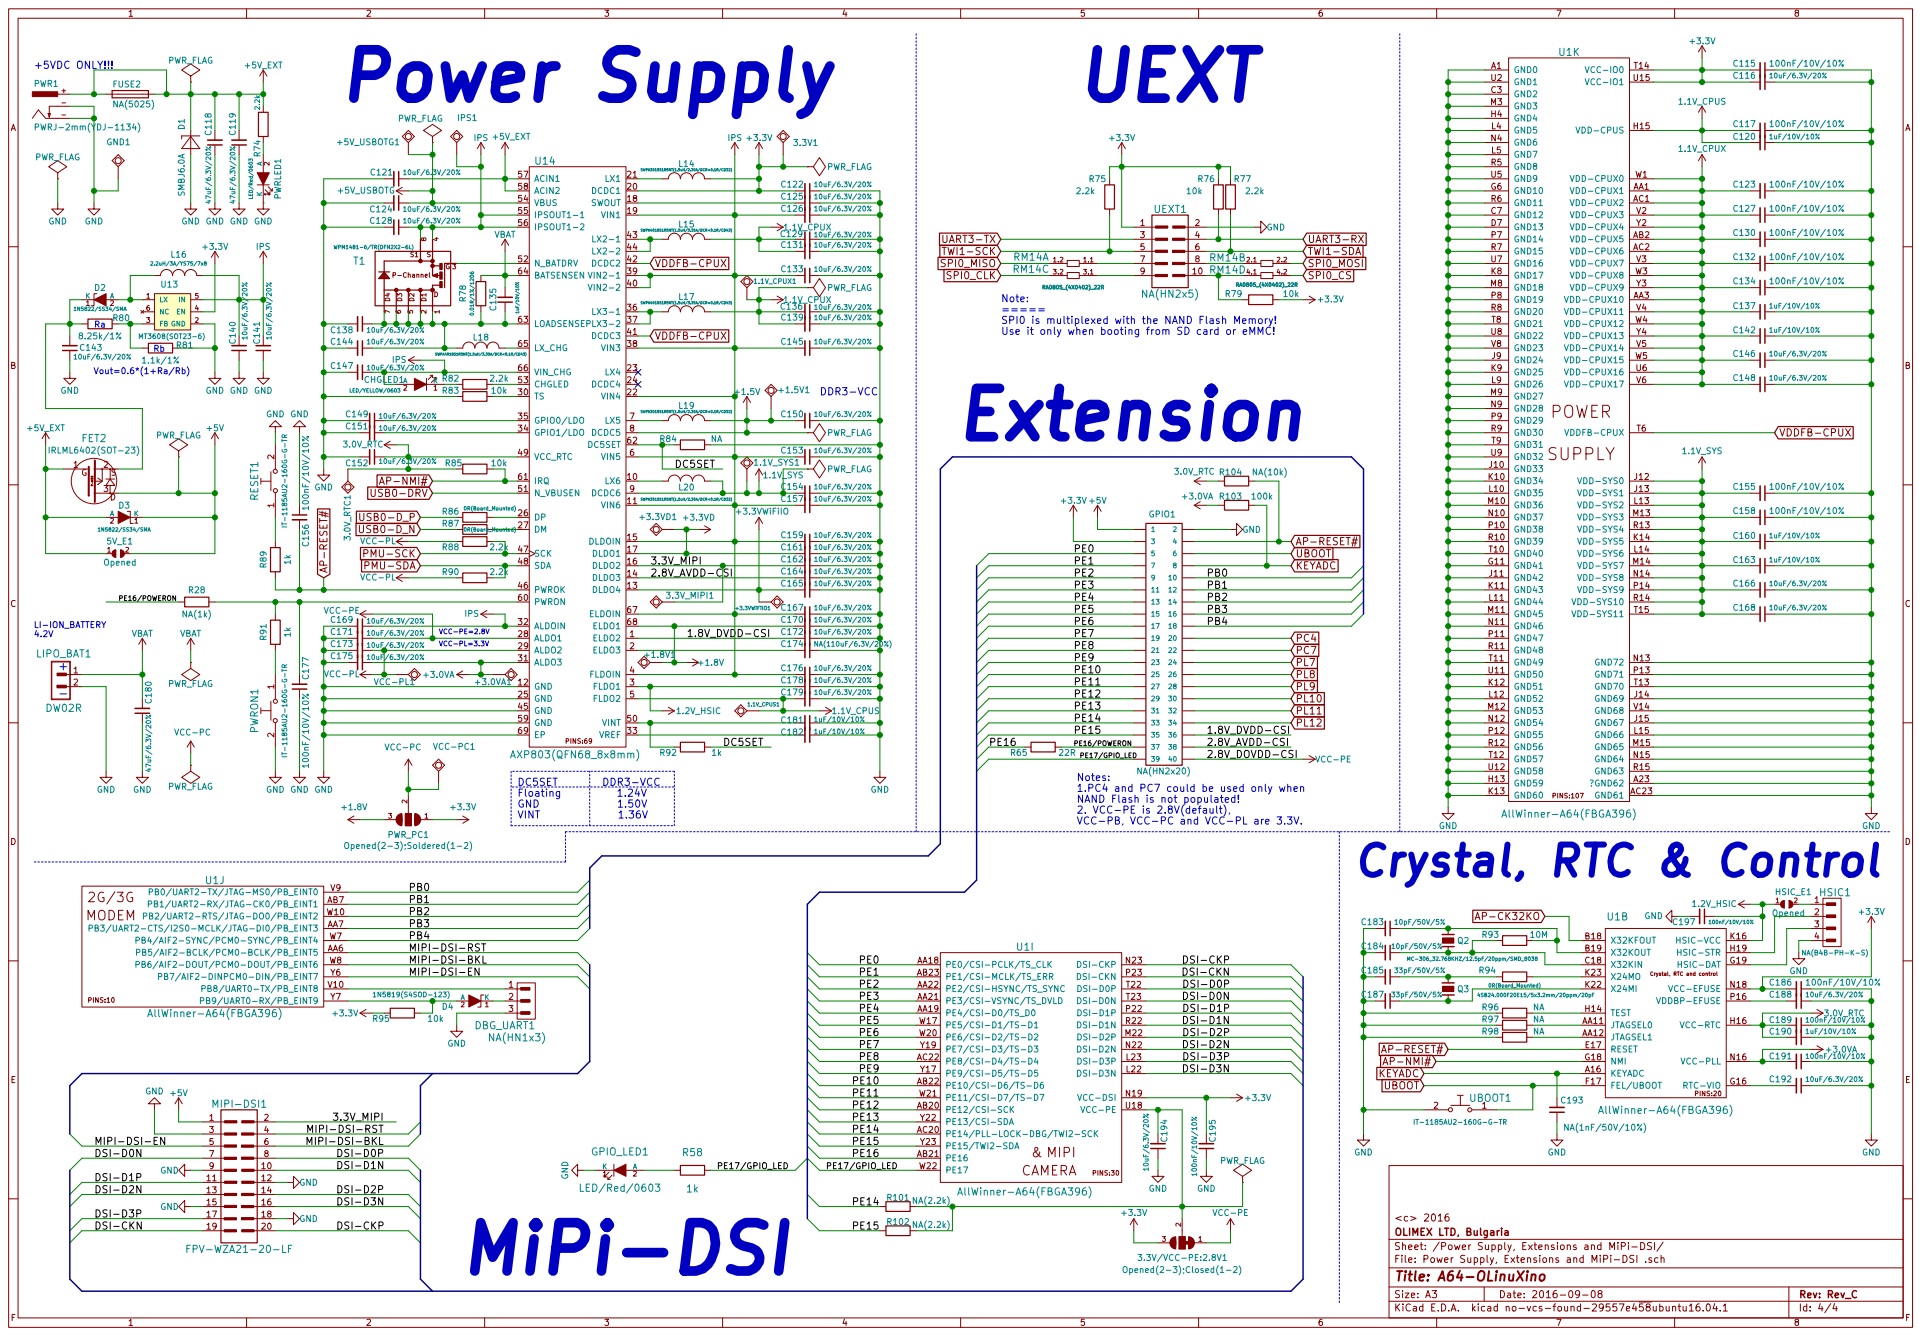
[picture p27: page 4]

Use it only when booting from SD card or eMMC! PWR_FLAG

1 2PWRON1 IT-1185AU2-160G-G-TR GND GNDC156 100nF/10V/10% R89 1k 1 2 RESET1 IT-1185AU2-160G-G-TR GND GND AP-RESET#

NAND Flash is not populated!
2. VCC-PE is 2.8V(default),

VCC-PB, VCC-PC and VCC-PL are 3.3V. R102 NA(2.2k) R101 NA(2.2k)

3 3.3V/VCC-PE:2.8V1 Opened(2-3);Closed(1-2) +3.3V

Sheet: /Power Supply, Extensions and MiPi-DSI/
File: Power Supply, Extensions and MiPi-DSI .sch
Id: 4/4 Title: A64-OLinuXino

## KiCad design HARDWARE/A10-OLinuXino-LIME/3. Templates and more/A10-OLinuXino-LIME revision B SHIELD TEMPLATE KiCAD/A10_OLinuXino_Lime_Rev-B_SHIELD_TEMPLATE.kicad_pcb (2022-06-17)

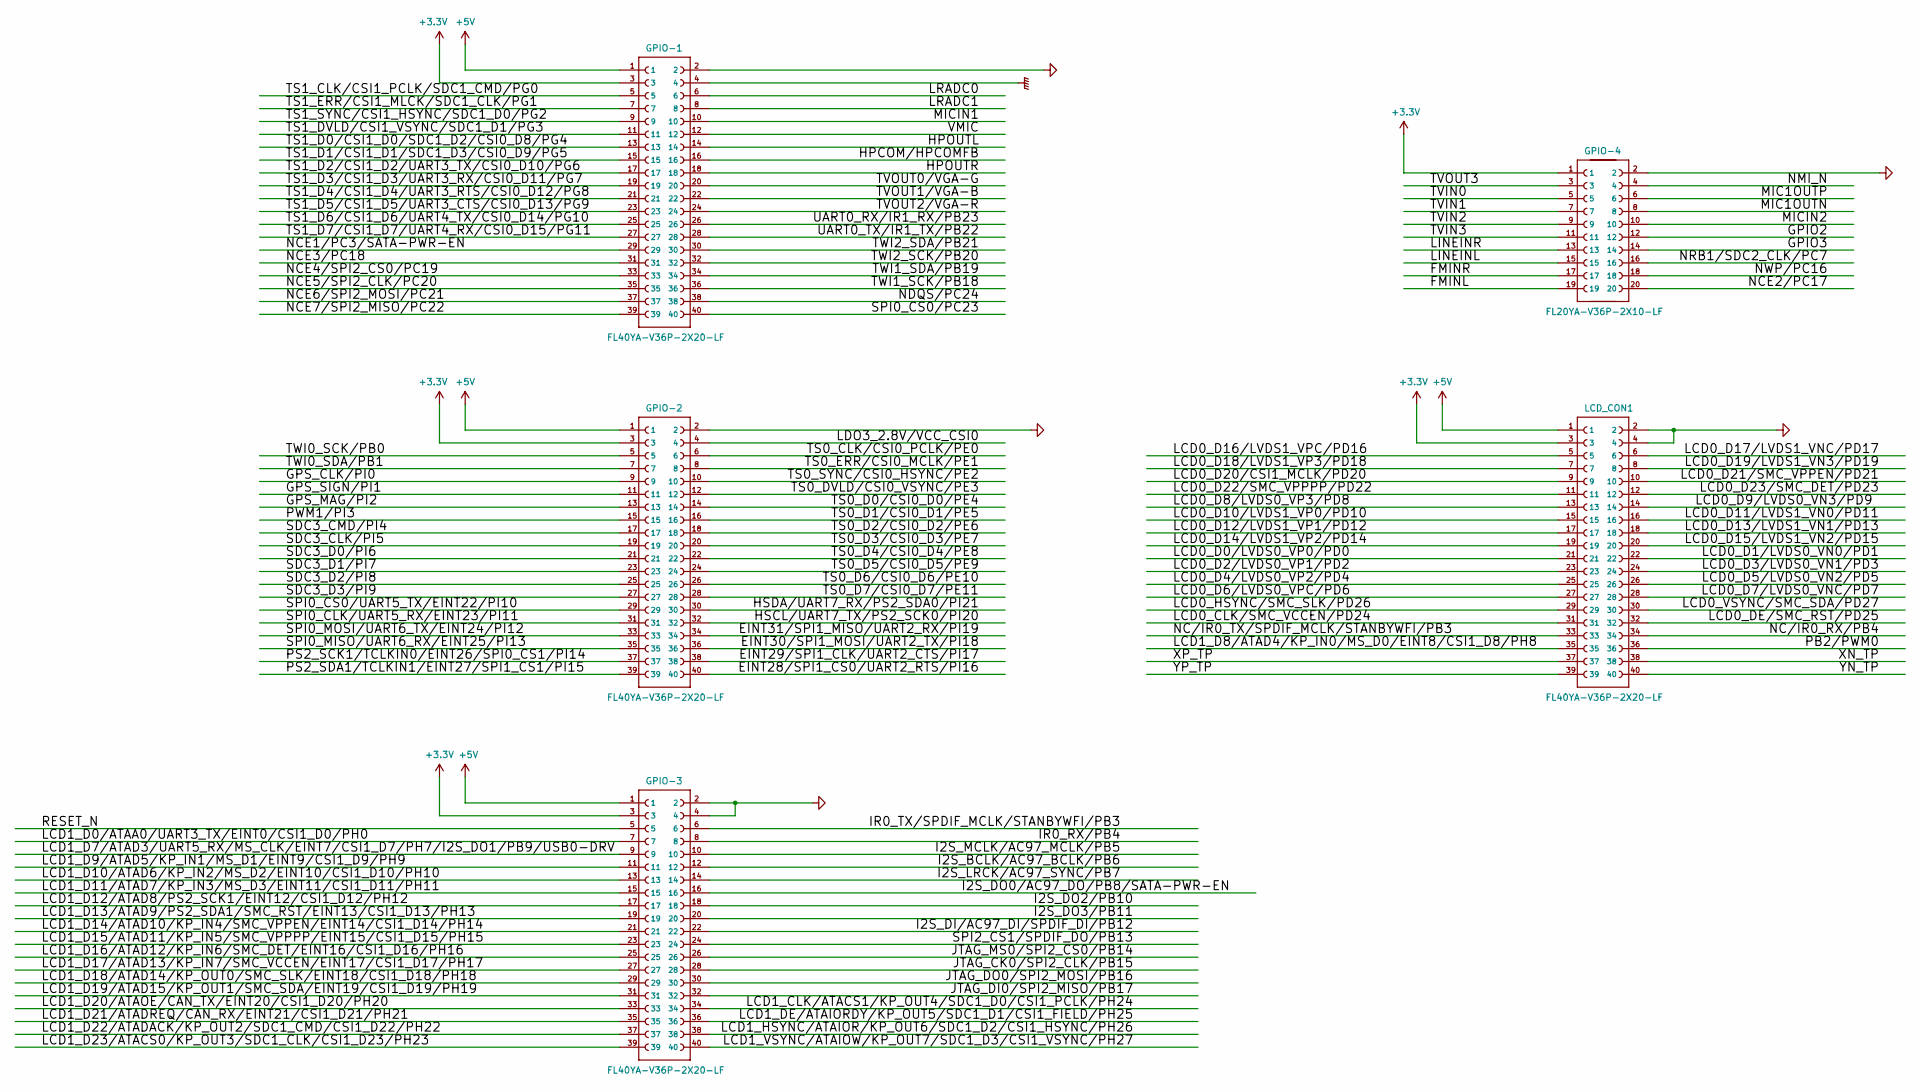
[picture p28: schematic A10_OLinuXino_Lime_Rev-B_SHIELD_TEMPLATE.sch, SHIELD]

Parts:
GPIO-1, GPIO-2, GPIO-3: FL40YA-V36P-2X20-LF; A10_OLIMEXINO_LIME_SHIELD_1-YA-V36P-2X20-LF
GPIO-4: FL20YA-V36P-2X10-LF; A10_OLIMEXINO_LIME_SHIELD_1-YA-V36P-2X10-LF
LCD_CON1: FL40YA-V36P-2X20-LF; A10_OLIMEXINO_LIME_SHIELD_1-YA-V36P-2X20-LF

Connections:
+3V3: GPIO-1.3, GPIO-2.3, GPIO-3.3, GPIO-4.1, LCD_CON1.3
+5V: GPIO-1.1, GPIO-2.1, GPIO-3.1, LCD_CON1.1
/EINT28/SPI1_CS0/UART2_RTS/PI16: GPIO-2.40
/EINT29/SPI1_CLK/UART2_CTS/PI17: GPIO-2.38
/EINT30/SPI1_MOSI/UART2_TX/PI18: GPIO-2.36
/EINT31/SPI1_MISO/UART2_RX/PI19: GPIO-2.34
/FMINL: GPIO-4.19
/FMINR: GPIO-4.17
/GPIO2: GPIO-4.12
/GPIO3: GPIO-4.14
/GPS_CLK/PI0: GPIO-2.9
/GPS_MAG/PI2: GPIO-2.13
/GPS_SIGN/PI1: GPIO-2.11
/HPCOM/HPCOMFB: GPIO-1.16
/HPOUTL: GPIO-1.14
/HPOUTR: GPIO-1.18
/HSCL/UART7_TX/PS2_SCK0/PI20: GPIO-2.32
/HSDA/UART7_RX/PS2_SDA0/PI21: GPIO-2.30
/I2S_BCLK/AC97_BCLK/PB6: GPIO-3.12
/I2S_DI/AC97_DI/SPDIF_DI/PB12: GPIO-3.22
/I2S_DO0/AC97_DO/PB8/SATA-PWR-EN: GPIO-3.16
/I2S_DO2/PB10: GPIO-3.18
/I2S_DO3/PB11: GPIO-3.20
/I2S_LRCK/AC97_SYNC/PB7: GPIO-3.14
/I2S_MCLK/AC97_MCLK/PB5: GPIO-3.10
/IR0_RX/PB4: GPIO-3.8
/IR0_TX/SPDIF_MCLK/STANBYWFI/PB3: GPIO-3.6
/JTAG_CK0/SPI2_CLK/PB15: GPIO-3.28
/JTAG_DI0/SPI2_MISO/PB17: GPIO-3.32
/JTAG_DO0/SPI2_MOSI/PB16: GPIO-3.30
/JTAG_MS0/SPI2_CS0/PB14: GPIO-3.26
/LCD0_CLK/SMC_VCCEN/PD24: LCD_CON1.31
/LCD0_D0/LVDS0_VP0/PD0: LCD_CON1.21
/LCD0_D1/LVDS0_VN0/PD1: LCD_CON1.22
/LCD0_D2/LVDS0_VP1/PD2: LCD_CON1.23
/LCD0_D3/LVDS0_VN1/PD3: LCD_CON1.24
/LCD0_D4/LVDS0_VP2/PD4: LCD_CON1.25
/LCD0_D5/LVDS0_VN2/PD5: LCD_CON1.26
/LCD0_D6/LVDS0_VPC/PD6: LCD_CON1.27
/LCD0_D7/LVDS0_VNC/PD7: LCD_CON1.28
/LCD0_D8/LVDS0_VP3/PD8: LCD_CON1.13
/LCD0_D9/LVDS0_VN3/PD9: LCD_CON1.14
/LCD0_D10/LVDS1_VP0/PD10: LCD_CON1.15
/LCD0_D11/LVDS1_VN0/PD11: LCD_CON1.16
/LCD0_D12/LVDS1_VP1/PD12: LCD_CON1.17
/LCD0_D13/LVDS1_VN1/PD13: LCD_CON1.18
/LCD0_D14/LVDS1_VP2/PD14: LCD_CON1.19
/LCD0_D15/LVDS1_VN2/PD15: LCD_CON1.20
/LCD0_D16/LVDS1_VPC/PD16: LCD_CON1.5
/LCD0_D17/LVDS1_VNC/PD17: LCD_CON1.6
/LCD0_D18/LVDS1_VP3/PD18: LCD_CON1.7
/LCD0_D19/LVDS1_VN3/PD19: LCD_CON1.8
/LCD0_D20/CSI1_MCLK/PD20: LCD_CON1.9
/LCD0_D21/SMC_VPPEN/PD21: LCD_CON1.10
/LCD0_D22/SMC_VPPPP/PD22: LCD_CON1.11
/LCD0_D23/SMC_DET/PD23: LCD_CON1.12
/LCD0_DE/SMC_RST/PD25: LCD_CON1.32
/LCD0_HSYNC/SMC_SLK/PD26: LCD_CON1.29
/LCD0_VSYNC/SMC_SDA/PD27: LCD_CON1.30
/LCD1_CLK/ATACS1/KP_OUT4/SDC1_D0/CSI1_PCLK/PH24: GPIO-3.34
/LCD1_D0/ATAA0/UART3_TX/EINT0/CSI1_D0/PH0: GPIO-3.7
/LCD1_D7/ATAD3/UART5_RX/MS_CLK/EINT7/CSI1_D7/PH7/I2S_DO1/PB9/USB0-DRV: GPIO-3.9
/LCD1_D8/ATAD4/KP_IN0/MS_D0/EINT8/CSI1_D8/PH8: LCD_CON1.35
/LCD1_D9/ATAD5/KP_IN1/MS_D1/EINT9/CSI1_D9/PH9: GPIO-3.11
/LCD1_D10/ATAD6/KP_IN2/MS_D2/EINT10/CSI1_D10/PH10: GPIO-3.13
/LCD1_D11/ATAD7/KP_IN3/MS_D3/EINT11/CSI1_D11/PH11: GPIO-3.15
/LCD1_D12/ATAD8/PS2_SCK1/EINT12/CSI1_D12/PH12: GPIO-3.17
/LCD1_D13/ATAD9/PS2_SDA1/SMC_RST/EINT13/CSI1_D13/PH13: GPIO-3.19
/LCD1_D14/ATAD10/KP_IN4/SMC_VPPEN/EINT14/CSI1_D14/PH14: GPIO-3.21
/LCD1_D15/ATAD11/KP_IN5/SMC_VPPPP/EINT15/CSI1_D15/PH15: GPIO-3.23
/LCD1_D16/ATAD12/KP_IN6/SMC_DET/EINT16/CSI1_D16/PH16: GPIO-3.25
/LCD1_D17/ATAD13/KP_IN7/SMC_VCCEN/EINT17/CSI1_D17/PH17: GPIO-3.27
/LCD1_D18/ATAD14/KP_OUT0/SMC_SLK/EINT18/CSI1_D18/PH18: GPIO-3.29
/LCD1_D19/ATAD15/KP_OUT1/SMC_SDA/EINT19/CSI1_D19/PH19: GPIO-3.31
/LCD1_D20/ATAOE/CAN_TX/EINT20/CSI1_D20/PH20: GPIO-3.33
/LCD1_D21/ATADREQ/CAN_RX/EINT21/CSI1_D21/PH21: GPIO-3.35
/LCD1_D22/ATADACK/KP_OUT2/SDC1_CMD/CSI1_D22/PH22: GPIO-3.37
/LCD1_D23/ATACS0/KP_OUT3/SDC1_CLK/CSI1_D23/PH23: GPIO-3.39
/LCD1_DE/ATAIORDY/KP_OUT5/SDC1_D1/CSI1_FIELD/PH25: GPIO-3.36
/LCD1_HSYNC/ATAIOR/KP_OUT6/SDC1_D2/CSI1_HSYNC/PH26: GPIO-3.38
/LCD1_VSYNC/ATAIOW/KP_OUT7/SDC1_D3/CSI1_VSYNC/PH27: GPIO-3.40
/LDO3_2.8V/VCC_CSI0: GPIO-2.4
/LINEINL: GPIO-4.15
/LINEINR: GPIO-4.13
/LRADC0: GPIO-1.6
/LRADC1: GPIO-1.8
/MIC1OUTN: GPIO-4.8
/MIC1OUTP: GPIO-4.6
/MICIN1: GPIO-1.10
/MICIN2: GPIO-4.10
/NC/IR0_RX/PB4: LCD_CON1.34
/NC/IR0_TX/SPDIF_MCLK/STANBYWFI/PB3: LCD_CON1.33
/NCE1/PC3/SATA-PWR-EN: GPIO-1.29
/NCE2/PC17: GPIO-4.20
/NCE3/PC18: GPIO-1.31
/NCE4/SPI2_CS0/PC19: GPIO-1.33
/NCE5/SPI2_CLK/PC20: GPIO-1.35
/NCE6/SPI2_MOSI/PC21: GPIO-1.37
/NCE7/SPI2_MISO/PC22: GPIO-1.39
/NDQS/PC24: GPIO-1.38
/NMI_N: GPIO-4.4
/NRB1/SDC2_CLK/PC7: GPIO-4.16
/NWP/PC16: GPIO-4.18
/PB2/PWM0: LCD_CON1.36
/PS2_SCK1/TCLKIN0/EINT26/SPI0_CS1/PI14: GPIO-2.37
/PS2_SDA1/TCLKIN1/EINT27/SPI1_CS1/PI15: GPIO-2.39
/PWM1/PI3: GPIO-2.15
/RESET_N: GPIO-3.5
/SDC3_CLK/PI5: GPIO-2.19
/SDC3_CMD/PI4: GPIO-2.17
/SDC3_D0/PI6: GPIO-2.21
/SDC3_D1/PI7: GPIO-2.23
/SDC3_D2/PI8: GPIO-2.25
/SDC3_D3/PI9: GPIO-2.27
/SPI0_CLK/UART5_RX/EINT23/PI11: GPIO-2.31
/SPI0_CS0/PC23: GPIO-1.40
/SPI0_CS0/UART5_TX/EINT22/PI10: GPIO-2.29
/SPI0_MISO/UART6_RX/EINT25/PI13: GPIO-2.35
/SPI0_MOSI/UART6_TX/EINT24/PI12: GPIO-2.33
/SPI2_CS1/SPDIF_DO/PB13: GPIO-3.24
/TS0_CLK/CSI0_PCLK/PE0: GPIO-2.6
/TS0_D0/CSI0_D0/PE4: GPIO-2.14
/TS0_D1/CSI0_D1/PE5: GPIO-2.16
/TS0_D2/CSI0_D2/PE6: GPIO-2.18
/TS0_D3/CSI0_D3/PE7: GPIO-2.20
/TS0_D4/CSI0_D4/PE8: GPIO-2.22
/TS0_D5/CSI0_D5/PE9: GPIO-2.24
/TS0_D6/CSI0_D6/PE10: GPIO-2.26
/TS0_D7/CSI0_D7/PE11: GPIO-2.28
/TS0_DVLD/CSI0_VSYNC/PE3: GPIO-2.12
/TS0_ERR/CSI0_MCLK/PE1: GPIO-2.8
/TS0_SYNC/CSI0_HSYNC/PE2: GPIO-2.10
/TS1_CLK/CSI1_PCLK/SDC1_CMD/PG0: GPIO-1.5
/TS1_D0/CSI1_D0/SDC1_D2/CSI0_D8/PG4: GPIO-1.13
/TS1_D1/CSI1_D1/SDC1_D3/CSI0_D9/PG5: GPIO-1.15
/TS1_D2/CSI1_D2/UART3_TX/CSI0_D10/PG6: GPIO-1.17
/TS1_D3/CSI1_D3/UART3_RX/CSI0_D11/PG7: GPIO-1.19
/TS1_D4/CSI1_D4/UART3_RTS/CSI0_D12/PG8: GPIO-1.21
/TS1_D5/CSI1_D5/UART3_CTS/CSI0_D13/PG9: GPIO-1.23
/TS1_D6/CSI1_D6/UART4_TX/CSI0_D14/PG10: GPIO-1.25
/TS1_D7/CSI1_D7/UART4_RX/CSI0_D15/PG11: GPIO-1.27
/TS1_DVLD/CSI1_VSYNC/SDC1_D1/PG3: GPIO-1.11
/TS1_ERR/CSI1_MLCK/SDC1_CLK/PG1: GPIO-1.7
/TS1_SYNC/CSI1_HSYNC/SDC1_D0/PG2: GPIO-1.9
/TVIN0: GPIO-4.5
/TVIN1: GPIO-4.7
/TVIN2: GPIO-4.9
/TVIN3: GPIO-4.11
/TVOUT0/VGA-G: GPIO-1.20
/TVOUT1/VGA-B: GPIO-1.22
/TVOUT2/VGA-R: GPIO-1.24
/TVOUT3: GPIO-4.3
/TWI0_SCK/PB0: GPIO-2.5
/TWI0_SDA/PB1: GPIO-2.7
/TWI1_SCK/PB18: GPIO-1.36
/TWI1_SDA/PB19: GPIO-1.34
/TWI2_SCK/PB20: GPIO-1.32
/TWI2_SDA/PB21: GPIO-1.30
/UART0_RX/IR1_RX/PB23: GPIO-1.26
/UART0_TX/IR1_TX/PB22: GPIO-1.28
/VMIC: GPIO-1.12
/XN_TP: LCD_CON1.38
/XP_TP: LCD_CON1.37
/YN_TP: LCD_CON1.40
/YP_TP: LCD_CON1.39
GND: GPIO-1.2, GPIO-2.2, GPIO-3.2, GPIO-3.4, GPIO-4.2, LCD_CON1.2, LCD_CON1.4
GNDPWR: GPIO-1.4

Board: 2 copper layers, 5 parts (5 on the bottom side), 3 nets, no tracks yet.

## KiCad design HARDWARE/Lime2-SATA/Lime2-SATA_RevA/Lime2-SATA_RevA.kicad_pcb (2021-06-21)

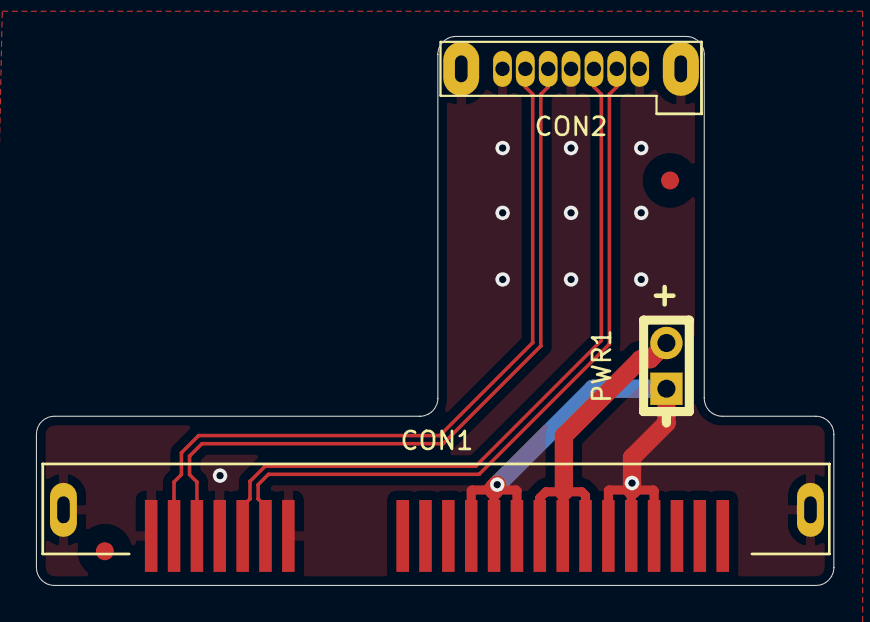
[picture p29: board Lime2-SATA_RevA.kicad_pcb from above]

Board: 2 copper layers, 44.3 x 30.5 mm, 5 parts (0 on the bottom side), 6 nets.

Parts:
CON1: SATA7_15P; SATA7_15_HDD
CON2: SATA7P; SATA7-S-PTH
PWR1: BH02S; SIP2
Ref*: Val**; Fiducial1x3_transp
Ref*#2: Val**; Fiducial1x3_transp

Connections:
/GND: CON1.0, CON1.1, CON1.4, CON1.7, CON1.14, CON1.15, CON1.16, CON1.20, CON1.21, CON1.22, CON2.0, CON2.1, CON2.4, CON2.7, PWR1.1
/RX_N: CON1.5, CON2.5
/RX_P: CON1.6, CON2.6
/TX_N: CON1.3, CON2.3
/TX_P: CON1.2, CON2.2
unnamed: CON1.17, CON1.18, CON1.19, PWR1.2

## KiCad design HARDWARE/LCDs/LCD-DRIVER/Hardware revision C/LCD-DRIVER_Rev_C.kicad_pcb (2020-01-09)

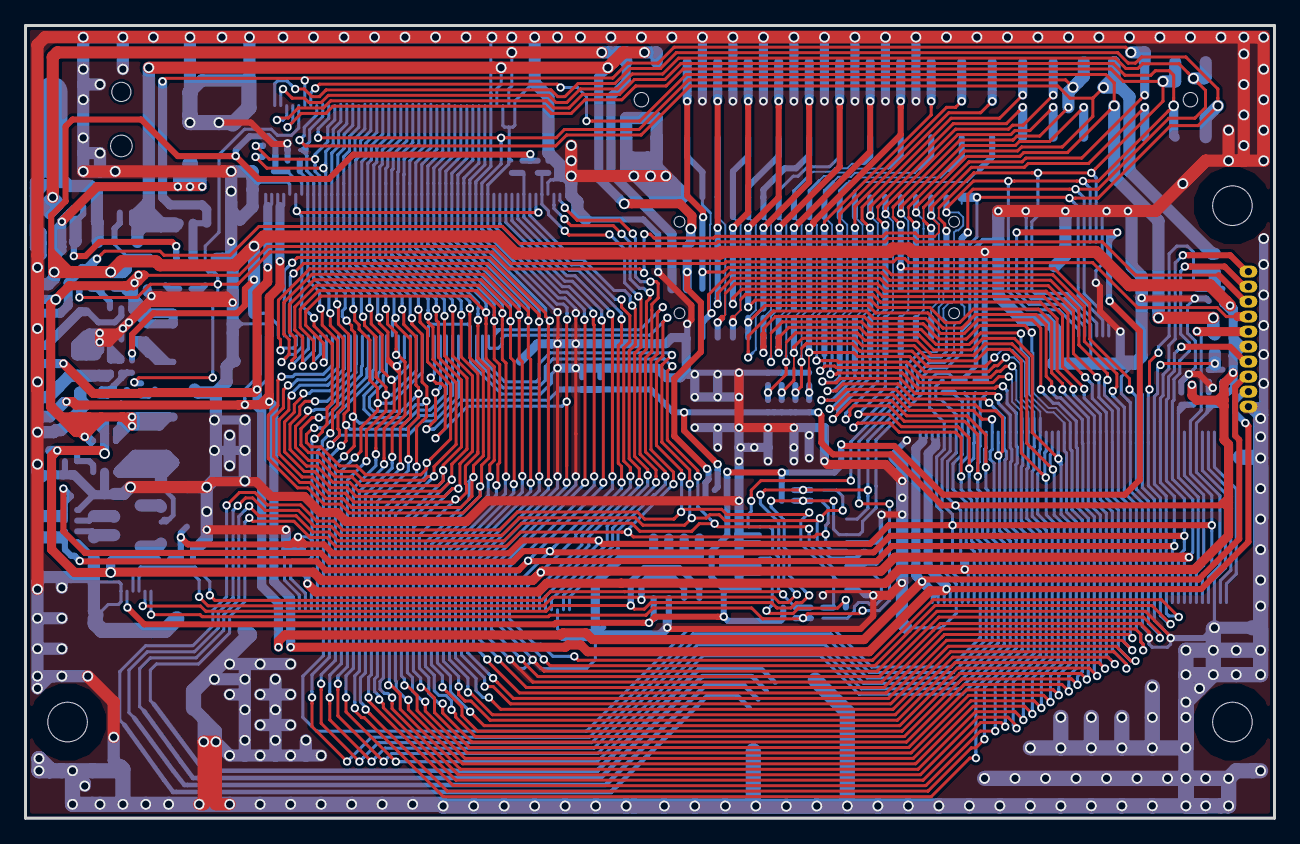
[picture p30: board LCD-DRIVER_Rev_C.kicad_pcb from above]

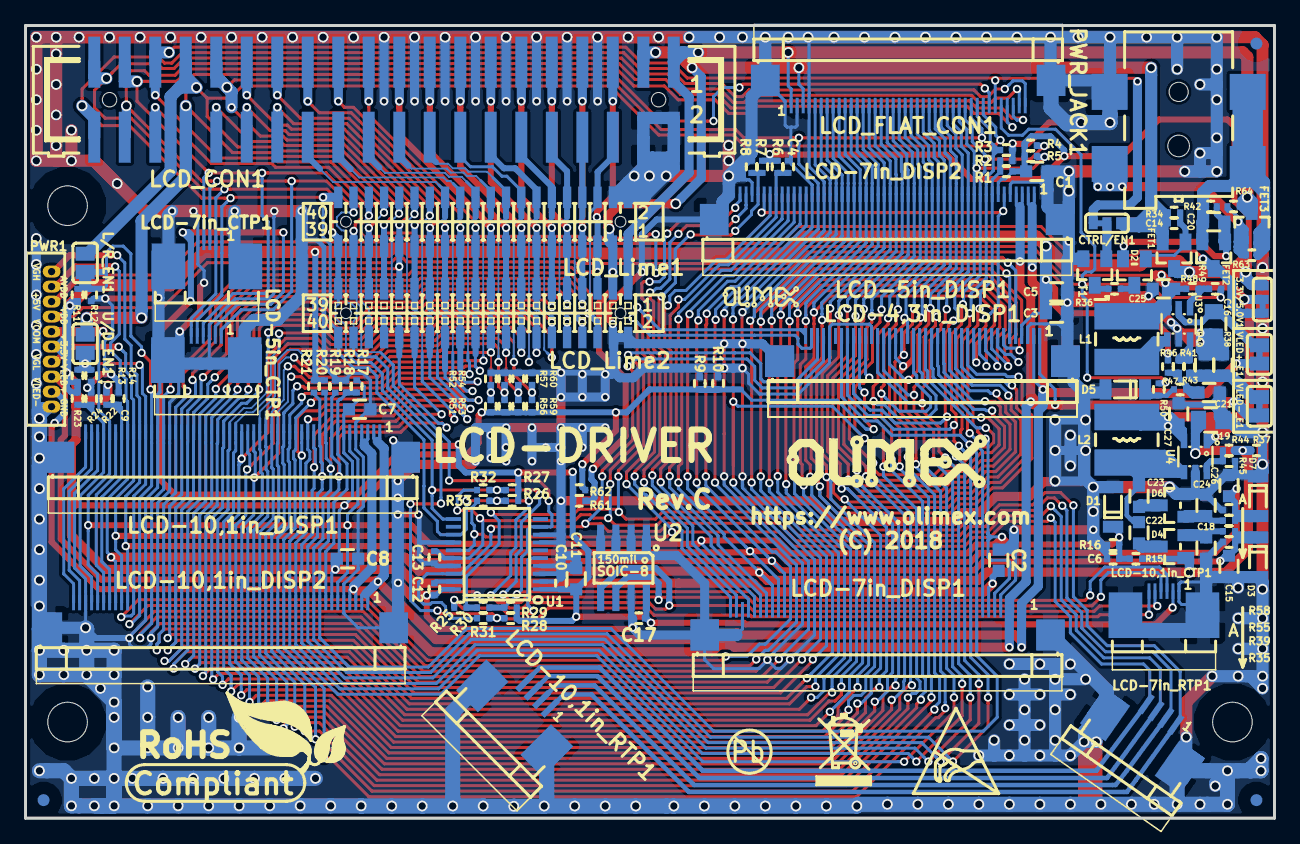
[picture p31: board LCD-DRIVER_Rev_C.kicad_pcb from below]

Board: 2 copper layers, 104.0 x 66.0 mm, 143 parts (140 on the bottom side), 88 nets.

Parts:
3.3V/5.0V1: 3.3V:Opened/5.0V:Closed; SJ_2_SMALL_23_TIED
C1, C2, C5, C7, C8, C27: NA(22uF/6.3V/20%/X5R/C0603); C_0603_5MIL_DWS
C3, C11, C20, C21, C25: 22uF/6.3V/20%/X5R/C0603; C_0603_5MIL_DWS
C4, C6, C9: NA(100nF/16V/10%/X7R/C0402); C_0402_5MIL_DWS
C10, C14, C17: 100nF/16V/10%/X7R/C0402; C_0402_5MIL_DWS
C12, C13: 10nF/50V/10%/X7R/C0402; C_0402_5MIL_DWS
C15, C18, C22, C23, C24, C26: NA(100nF/50V/20%/Y5V/C0603); C_0603_5MIL_DWS
C16: 2.2uF/50V/10%/X5R/C0805; C_0805_5MIL_DWS
C19: NA(2.2uF/50V/10%/X5R/C0805); C_0805_5MIL_DWS
CTRL/EN1: CTRL:Closed/EN:Opened; SJ_2_SMALL_23_TIED
D1: NA(BZV55C3V9/SOD80C); SOD80C-4148-KA
D2: BAT54C(SOT23-3); SOT23-3
D3: NA(BZV55C20/SOD80C); SOD80C-4148-KA
D4, D6: NA(BAT54S(SOT23-3)); SOT23-3
D5: NA(BZV55C3V6/SOD80C); SOD80C-4148-KA
D7: NA(BZV55C5V1/SOD80C); SOD80C-4148-KA
FET1, FET2, FET3: IRLML6402(SOT23-3); SOT23
FID1, FID2, FID3: Fiducial; Fiducial1x3
L1: 22uH/1.5A/220mR/20%/CD53(YS53-220M); CD53(54)
L2: NA(22uH/1.5A/220mR/20%/CD53(YS53-220M)); CD53(54)
L/R_EN1: Opened; SJ
LCD-4,3in_DISP1: LCD-4.3"(480x272_GFT043HA480272Y)+(FPV-WZA21-40-L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; FPV-WZA21-40-LF
LCD-5in_CTP1: NA(LCD-5”(CAPACITIVE_TS)+(FPV-WZB201-06-LF)); FPV-WZB201-06-LF
LCD-5in_DISP1: NA(LCD-5”(800x480_HDW050TN22)+(FPV-WZA21-40-LF)); FPV-WZA21-40-LF
LCD-7in_CTP1, LCD-10,1in_CTP1: NA(FPV-WZB201-06-LF); FPV-WZB201-06-LF
LCD-7in_DISP1: NA(LCD-7"(800x480_AT070TN92)+(FPV-WZA21-50-LF)); FPV-WZA21-50-LF
LCD-7in_DISP2: NA(LCD-7"(800x480_CX700TN94-CTP38)+(FPV-WZA21-50-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; FPV-WZA21-50-LF
LCD-7in_RTP1: NA(LCD-TS7(LCD-7"_TOUCHPANEL)+(FPA-WZB25-04-LF)); FPA-WZB25-04-LF
LCD-10,1in_DISP1: NA(LCD-10"(1024x600_LOYE_BOE10.1-33LEDH)+(FPV-WZA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; FPV-WZA21-50-LF
LCD-10,1in_DISP2: NA(LCD-10"_CAP_TS(1024x600_IPS_CXT101H39-42E)+(FP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; FPV-WZA21-50-LF
LCD-10,1in_RTP1: NA(LCD-TS10(LCD-10"_TOUCHPANEL)+(FPA-WZB25-04-LF)); FPA-WZB25-04-LF
LCD_CON1: GBH254SMT-40(B-V-40-LF); GBH254SMT-40
LCD_FLAT_CON1: FPV-WZA21-40-LF
LCD_Lime1: MALE-PAV16X-2x20(0.8_bud); GPCB127SMT-02X20(YA-V36P-2X20-LF)_Drill_0.9mm
LCD_Lime2: MALE-PAV16X-2x20(0.8_bud); GPH127SMT-02X20(PA-V16X-2X20-LF)_Drill_0.9mm
Logo-Olimex-Big: OLIMEX_LOGO_TB
Logo-Olimex_Small: LOGO_OLIMEX_80
MountingHole*: Mounting_hole_3.3mm
MountingHole*#2, MountingHole*#3: Mounting_hole_3.3mm
PWR1: NA(WU10S); WU10S
PWR_JACK1: PWRJ-2mm(DCJ-W54R-20-LF)
R1, R4, R5, R8, R12, R13, R17, R20, R21, R24, R49, R62: NA/R0402; R_0402_5MIL_DWS
R2, R3, R6, R7, R10, R11, R14, R18, R19, R22, R23, R51, R52, R53, R54, R56, R57, R59, R60, R64: NA(10k/R0402); R_0402_5MIL_DWS
R9, R34, R42, R48, R63: 10k/R0402; R_0402_5MIL_DWS
R15, R39, R55: NA(1k/1%/R0402); R_0402_5MIL_DWS
R16: NA(560R/1%/R0402); R_0402_5MIL_DWS
R25, R43: 20k/1%/R0402; R_0402_5MIL_DWS
R26, R27, R28, R29, R41: 2.2k/R0402; R_0402_5MIL_DWS
R30, R31, R32, R33: NA(0R/R0402); R_0402_5MIL_DWS
R35, R37, R58: NA(20k/1%/R0402); R_0402_5MIL_DWS
R36: 1k/1%/R0402; R_0402_5MIL_DWS
R38: 4.7R/1%/R0603; R_0603_5MIL_DWS
R40: NA/R0603; R_0603_5MIL_DWS
R44: NA(56.2k/1%/R0402); R_0402_5MIL_DWS
R45: NA(1.05k/1%/R0402); R_0402_5MIL_DWS
R46, R47: 27k/R0402; R_0402_5MIL_DWS
R50: 220R/R0402; R_0402_5MIL_DWS
R61: 0R/R0402; R_0402_5MIL_DWS
Sign-Antistatic: Val**; LOGO_ANTISTATIC_1
Sign-PB_Free: LOGO_PBFREE
Sign-RecycleBin: LOGO_RECYCLEBIN_1
Sign-RoHS_Compliant: Val**; LOGO_ROHS_1
T1: DTC114YKA(SOT-23); SOT23
U1: AR1021T-I_SS(SSOP-20); SSOP-20W
U2: AT24C16C-SSHM-T(SOIC-8_150mil); SOIC-8_150mil
U3: AP3036BKTR-G1(SOT23-6); SOT23-6
U4: NA(AP3036BKTR-G1(SOT23-6)); SOT23-6
U/D_EN1: Opened; SJ
VLED+_E1: Closed; SJ_Closed
VLED-_E1: Closed; SJ_Closed

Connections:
+3.3VA: C10.2, C11.1, C17.1, LCD-5in_CTP1.2, LCD-7in_CTP1.6, LCD-10,1in_CTP1.2, R26.2, R27.2, R28.2, R29.2, R61.1, R62.2, U1.1, U2.8
+3V3: 3.3V/5.0V1.1, C1.1, C2.1, C3.1, C5.1, C7.1, C8.1, FET1.3, LCD-4,3in_DISP1.4, LCD-4,3in_DISP1.31, LCD-5in_DISP1.4, LCD-5in_DISP1.31, LCD-7in_DISP1.7, LCD-7in_DISP2.7, LCD-10,1in_DISP1.7, LCD-10,1in_DISP2.7, PWR1.6, R1.1, R4.1, R5.1, R6.1, R7.1, R9.2, R10.2, R11.2, R13.2, R17.1, R20.1, R21.1, R22.1, R23.1, R46.1, R51.1, R53.1, R56.1, R59.1, R62.1
+5V: 3.3V/5.0V1.3, FET2.3, PWR1.3
/LCD_3.3V: C14.1, CTRL/EN1.1, FET1.2, LCD_CON1.3, LCD_FLAT_CON1.3, LCD_Lime1.3, LCD_Lime2.3, R34.2, R61.2
/LCD_5.0V: FET3.3, LCD_CON1.1, LCD_FLAT_CON1.1, LCD_Lime1.1, LCD_Lime2.1, R64.2
/LCD_B0: LCD-4,3in_DISP1.21, LCD-5in_DISP1.21, LCD-7in_DISP1.19, LCD-7in_DISP2.19, LCD-10,1in_DISP1.19, LCD-10,1in_DISP2.19, LCD_CON1.21, LCD_FLAT_CON1.21, LCD_Lime1.21, LCD_Lime2.21
/LCD_B1: LCD-4,3in_DISP1.22, LCD-5in_DISP1.22, LCD-7in_DISP1.18, LCD-7in_DISP2.18, LCD-10,1in_DISP1.18, LCD-10,1in_DISP2.18, LCD_CON1.22, LCD_FLAT_CON1.22, LCD_Lime1.22, LCD_Lime2.22
/LCD_B2: LCD-4,3in_DISP1.23, LCD-5in_DISP1.23, LCD-7in_DISP1.17, LCD-7in_DISP2.17, LCD-10,1in_DISP1.17, LCD-10,1in_DISP2.17, LCD_CON1.23, LCD_FLAT_CON1.23, LCD_Lime1.23, LCD_Lime2.23
/LCD_B3: LCD-4,3in_DISP1.24, LCD-5in_DISP1.24, LCD-7in_DISP1.16, LCD-7in_DISP2.16, LCD-10,1in_DISP1.16, LCD-10,1in_DISP2.16, LCD_CON1.24, LCD_FLAT_CON1.24, LCD_Lime1.24, LCD_Lime2.24
/LCD_B4: LCD-4,3in_DISP1.25, LCD-5in_DISP1.25, LCD-7in_DISP1.15, LCD-7in_DISP2.15, LCD-10,1in_DISP1.15, LCD-10,1in_DISP2.15, LCD_CON1.25, LCD_FLAT_CON1.25, LCD_Lime1.25, LCD_Lime2.25
/LCD_B5: LCD-4,3in_DISP1.26, LCD-5in_DISP1.26, LCD-7in_DISP1.14, LCD-7in_DISP2.14, LCD-10,1in_DISP1.14, LCD-10,1in_DISP2.14, LCD_CON1.26, LCD_FLAT_CON1.26, LCD_Lime1.26, LCD_Lime2.26
/LCD_B6: LCD-4,3in_DISP1.27, LCD-5in_DISP1.27, LCD-7in_DISP1.13, LCD-7in_DISP2.13, LCD-10,1in_DISP1.13, LCD-10,1in_DISP2.13, LCD_CON1.27, LCD_FLAT_CON1.27, LCD_Lime1.27, LCD_Lime2.27
/LCD_B7: LCD-4,3in_DISP1.28, LCD-5in_DISP1.28, LCD-7in_DISP1.12, LCD-7in_DISP2.12, LCD-10,1in_DISP1.12, LCD-10,1in_DISP2.12, LCD_CON1.28, LCD_FLAT_CON1.28, LCD_Lime1.28, LCD_Lime2.28
/LCD_BKL: LCD_CON1.36, LCD_FLAT_CON1.36, LCD_Lime1.36, LCD_Lime2.36, R49.1, R50.1
/LCD_CLK: LCD-4,3in_DISP1.30, LCD-5in_DISP1.30, LCD-7in_DISP1.37, LCD-7in_DISP2.37, LCD-10,1in_DISP1.37, LCD-10,1in_DISP2.37, LCD_CON1.31, LCD_FLAT_CON1.31, LCD_Lime1.31, LCD_Lime2.31
/LCD_DE: LCD-4,3in_DISP1.34, LCD-5in_DISP1.34, LCD-7in_DISP1.9, LCD-7in_DISP2.9, LCD-10,1in_DISP1.9, LCD-10,1in_DISP2.9, LCD_CON1.32, LCD_FLAT_CON1.32, LCD_Lime1.32, LCD_Lime2.32, R3.2, R19.2
/LCD_G0: LCD-4,3in_DISP1.13, LCD-5in_DISP1.13, LCD-7in_DISP1.27, LCD-7in_DISP2.27, LCD-10,1in_DISP1.27, LCD-10,1in_DISP2.27, LCD_CON1.13, LCD_FLAT_CON1.13, LCD_Lime1.13, LCD_Lime2.13
/LCD_G1: LCD-4,3in_DISP1.14, LCD-5in_DISP1.14, LCD-7in_DISP1.26, LCD-7in_DISP2.26, LCD-10,1in_DISP1.26, LCD-10,1in_DISP2.26, LCD_CON1.14, LCD_FLAT_CON1.14, LCD_Lime1.14, LCD_Lime2.14
/LCD_G2: LCD-4,3in_DISP1.15, LCD-5in_DISP1.15, LCD-7in_DISP1.25, LCD-7in_DISP2.25, LCD-10,1in_DISP1.25, LCD-10,1in_DISP2.25, LCD_CON1.15, LCD_FLAT_CON1.15, LCD_Lime1.15, LCD_Lime2.15
/LCD_G3: LCD-4,3in_DISP1.16, LCD-5in_DISP1.16, LCD-7in_DISP1.24, LCD-7in_DISP2.24, LCD-10,1in_DISP1.24, LCD-10,1in_DISP2.24, LCD_CON1.16, LCD_FLAT_CON1.16, LCD_Lime1.16, LCD_Lime2.16
/LCD_G4: LCD-4,3in_DISP1.17, LCD-5in_DISP1.17, LCD-7in_DISP1.23, LCD-7in_DISP2.23, LCD-10,1in_DISP1.23, LCD-10,1in_DISP2.23, LCD_CON1.17, LCD_FLAT_CON1.17, LCD_Lime1.17, LCD_Lime2.17, R59.2, R60.2
/LCD_G5: LCD-4,3in_DISP1.18, LCD-5in_DISP1.18, LCD-7in_DISP1.22, LCD-7in_DISP2.22, LCD-10,1in_DISP1.22, LCD-10,1in_DISP2.22, LCD_CON1.18, LCD_FLAT_CON1.18, LCD_Lime1.18, LCD_Lime2.18, R56.2, R57.2
/LCD_G6: LCD-4,3in_DISP1.19, LCD-5in_DISP1.19, LCD-7in_DISP1.21, LCD-7in_DISP2.21, LCD-10,1in_DISP1.21, LCD-10,1in_DISP2.21, LCD_CON1.19, LCD_FLAT_CON1.19, LCD_Lime1.19, LCD_Lime2.19, R53.2, R54.2
/LCD_G7: LCD-4,3in_DISP1.20, LCD-5in_DISP1.20, LCD-7in_DISP1.20, LCD-7in_DISP2.20, LCD-10,1in_DISP1.20, LCD-10,1in_DISP2.20, LCD_CON1.20, LCD_FLAT_CON1.20, LCD_Lime1.20, LCD_Lime2.20, R51.2, R52.2
/LCD_HSYNC: LCD-4,3in_DISP1.32, LCD-5in_DISP1.32, LCD-7in_DISP1.11, LCD-7in_DISP2.11, LCD-10,1in_DISP1.11, LCD-10,1in_DISP2.11, LCD_CON1.29, LCD_FLAT_CON1.29, LCD_Lime1.29, LCD_Lime2.29, R5.2, R21.2
/LCD_L/R: L/R_EN1.1, LCD_CON1.33, LCD_FLAT_CON1.33, LCD_Lime1.33, LCD_Lime2.33
/LCD_PWRE: CTRL/EN1.3, LCD_CON1.35, LCD_FLAT_CON1.35, LCD_Lime1.35, LCD_Lime2.35
/LCD_R0: LCD-4,3in_DISP1.5, LCD-5in_DISP1.5, LCD-7in_DISP1.35, LCD-7in_DISP2.35, LCD-10,1in_DISP1.35, LCD-10,1in_DISP2.35, LCD_CON1.5, LCD_FLAT_CON1.5, LCD_Lime1.5, LCD_Lime2.5
/LCD_R1: LCD-4,3in_DISP1.6, LCD-5in_DISP1.6, LCD-7in_DISP1.34, LCD-7in_DISP2.34, LCD-10,1in_DISP1.34, LCD-10,1in_DISP2.34, LCD_CON1.6, LCD_FLAT_CON1.6, LCD_Lime1.6, LCD_Lime2.6
/LCD_R2: LCD-4,3in_DISP1.7, LCD-5in_DISP1.7, LCD-7in_DISP1.33, LCD-7in_DISP2.33, LCD-10,1in_DISP1.33, LCD-10,1in_DISP2.33, LCD_CON1.7, LCD_FLAT_CON1.7, LCD_Lime1.7, LCD_Lime2.7
/LCD_R3: LCD-4,3in_DISP1.8, LCD-5in_DISP1.8, LCD-7in_DISP1.32, LCD-7in_DISP2.32, LCD-10,1in_DISP1.32, LCD-10,1in_DISP2.32, LCD_CON1.8, LCD_FLAT_CON1.8, LCD_Lime1.8, LCD_Lime2.8
/LCD_R4: LCD-4,3in_DISP1.9, LCD-5in_DISP1.9, LCD-7in_DISP1.31, LCD-7in_DISP2.31, LCD-10,1in_DISP1.31, LCD-10,1in_DISP2.31, LCD_CON1.9, LCD_FLAT_CON1.9, LCD_Lime1.9, LCD_Lime2.9
/LCD_R5: LCD-4,3in_DISP1.10, LCD-5in_DISP1.10, LCD-7in_DISP1.30, LCD-7in_DISP2.30, LCD-10,1in_DISP1.30, LCD-10,1in_DISP2.30, LCD_CON1.10, LCD_FLAT_CON1.10, LCD_Lime1.10, LCD_Lime2.10
/LCD_R6: LCD-4,3in_DISP1.11, LCD-5in_DISP1.11, LCD-7in_DISP1.29, LCD-7in_DISP2.29, LCD-10,1in_DISP1.29, LCD-10,1in_DISP2.29, LCD_CON1.11, LCD_FLAT_CON1.11, LCD_Lime1.11, LCD_Lime2.11
/LCD_R7: LCD-4,3in_DISP1.12, LCD-5in_DISP1.12, LCD-7in_DISP1.28, LCD-7in_DISP2.28, LCD-10,1in_DISP1.28, LCD-10,1in_DISP2.28, LCD_CON1.12, LCD_FLAT_CON1.12, LCD_Lime1.12, LCD_Lime2.12
/LCD_U/D: LCD_CON1.34, LCD_FLAT_CON1.34, LCD_Lime1.34, LCD_Lime2.34, U/D_EN1.1
/LCD_VSYNC: LCD-4,3in_DISP1.33, LCD-5in_DISP1.33, LCD-7in_DISP1.10, LCD-7in_DISP2.10, LCD-10,1in_DISP1.10, LCD-10,1in_DISP2.10, LCD_CON1.30, LCD_FLAT_CON1.30, LCD_Lime1.30, LCD_Lime2.30, R4.2, R20.2
/RTP-X1/~CTP-INT: LCD-5in_CTP1.4, LCD-7in_CTP1.4, LCD-10,1in_CTP1.3, LCD_CON1.37, LCD_FLAT_CON1.37, LCD_Lime1.37, LCD_Lime2.37, R29.1, R30.1, U1.9
/RTP-X2/~CTP-RST: LCD-5in_CTP1.1, LCD-7in_CTP1.3, LCD-10,1in_CTP1.6, LCD_CON1.38, LCD_FLAT_CON1.38, LCD_Lime1.38, LCD_Lime2.38, R28.1, R31.1
/RTP-Y1/CTP-SCL: LCD-5in_CTP1.6, LCD-7in_CTP1.2, LCD-10,1in_CTP1.4, LCD_CON1.39, LCD_FLAT_CON1.39, LCD_Lime1.39, LCD_Lime2.39, R27.1, R32.1, U1.11, U2.6
/RTP-Y2/CTP-SDA: LCD-5in_CTP1.5, LCD-7in_CTP1.1, LCD-10,1in_CTP1.5, LCD_CON1.40, LCD_FLAT_CON1.40, LCD_Lime1.40, LCD_Lime2.40, R26.1, R33.1, U1.13, U2.5
AVDD: C19.1, D4.1, LCD-7in_DISP1.43, LCD-7in_DISP2.43, LCD-10,1in_DISP1.43, LCD-10,1in_DISP2.43, PWR1.2, R15.1, R37.1, R44.2, U4.2
GND: C1.2, C2.2, C3.2, C4.1, C5.2, C6.2, C7.2, C8.2, C9.1, C10.1, C11.2, C12.1, C13.1, C15.1, C16.2, C17.2, C18.1, C19.2, C21.2, C24.1, C25.2, C26.1, C27.2, D1.2, D3.2, D5.2, D6.2, D7.1, LCD-4,3in_DISP1.0, LCD-4,3in_DISP1.3, LCD-4,3in_DISP1.29, LCD-4,3in_DISP1.36, LCD-5in_CTP1.0, LCD-5in_CTP1.3, LCD-5in_DISP1.0, LCD-5in_DISP1.3, LCD-5in_DISP1.29, LCD-5in_DISP1.36, LCD-7in_CTP1.0, LCD-7in_CTP1.5, LCD-7in_DISP1.0, LCD-7in_DISP1.5, LCD-7in_DISP1.36, LCD-7in_DISP1.38, LCD-7in_DISP1.48, LCD-7in_DISP2.0, LCD-7in_DISP2.5, LCD-7in_DISP2.36, LCD-7in_DISP2.38, LCD-7in_DISP2.48, LCD-7in_RTP1.0, LCD-10,1in_CTP1.0, LCD-10,1in_CTP1.1, LCD-10,1in_DISP1.0, LCD-10,1in_DISP1.5, LCD-10,1in_DISP1.36, LCD-10,1in_DISP1.38, LCD-10,1in_DISP1.48, LCD-10,1in_DISP2.0, LCD-10,1in_DISP2.5, LCD-10,1in_DISP2.36, LCD-10,1in_DISP2.38, LCD-10,1in_DISP2.48, LCD-10,1in_RTP1.0, LCD_CON1.2, LCD_CON1.4, LCD_FLAT_CON1.0, LCD_FLAT_CON1.2, LCD_FLAT_CON1.4, LCD_Lime1.2, LCD_Lime1.4, LCD_Lime2.2, LCD_Lime2.4, PWR1.10, PWR_JACK1.2, R2.1, R3.1, R8.1, R9.1, R10.1, R12.1, R14.1, R16.1, R18.1, R19.1, R24.1, R35.1, R37.2, R38.1, R40.1, R45.1, R52.1, R54.1, R57.1, R58.1, R60.1, T1.2, U1.2, U1.3, U1.4, U1.7, U1.8, U1.14, U1.17, U1.20, U2.1, U2.2, U2.3, U2.4, U2.7, U3.5, U4.5
L/R: L/R_EN1.2, LCD-7in_DISP1.39, LCD-7in_DISP2.39, LCD-10,1in_DISP1.39, LCD-10,1in_DISP2.39, R11.1, R12.2
unnamed: C4.2, LCD-7in_DISP1.44, LCD-7in_DISP2.44, R6.2
unnamed: C9.2, LCD-10,1in_DISP1.44, LCD-10,1in_DISP2.44, R22.2
unnamed: C14.2, D2.1, FET1.1, R34.1
unnamed: C16.1, U3.2, VLED+_E1.2
unnamed: C18.2, D4.2, R39.1
unnamed: C20.1, FET2.2, FET3.2, PWR_JACK1.1, R42.2, R63.2
unnamed: C20.2, D2.2, FET2.1, R42.1
unnamed: C21.1, R43.1, R46.2, R47.2
unnamed: C22.1, D4.3
unnamed: C22.2, C23.1, L2.1, U4.4
unnamed: C23.2, D6.3
unnamed: C24.2, D6.1, R55.1
unnamed: CTRL/EN1.2, T1.1
unnamed: D2.3, R36.2
unnamed: D5.1, R47.1, R50.2
unnamed: FET3.1, PWR_JACK1.3, R63.1, R64.1
unnamed: L1.1, U3.4
unnamed: LCD-7in_DISP1.8, LCD-7in_DISP2.8, R1.2, R2.2
unnamed: LCD-7in_DISP1.45, LCD-7in_DISP2.45
unnamed: LCD-7in_DISP1.47, LCD-7in_DISP2.47, R7.2, R8.2
unnamed: LCD-7in_DISP1.49, LCD-7in_DISP2.49
unnamed: LCD-7in_DISP1.50, LCD-7in_DISP2.50
unnamed: LCD-10,1in_DISP1.8, LCD-10,1in_DISP2.8, R17.2, R18.2
unnamed: LCD-10,1in_DISP1.45, LCD-10,1in_DISP2.45
unnamed: LCD-10,1in_DISP1.47, LCD-10,1in_DISP2.47, R23.2, R24.2
unnamed: LCD-10,1in_DISP1.49, LCD-10,1in_DISP2.49
unnamed: LCD-10,1in_DISP1.50, LCD-10,1in_DISP2.50
unnamed: R25.2, U1.5
unnamed: R36.1, T1.3
unnamed: R38.2, R40.2, R41.2, VLED-_E1.2
unnamed: R41.1, R43.2, U3.6
unnamed: R44.1, R45.2, U4.6
unnamed: R48.2, R49.2, U3.1
RTP_X+(X2): LCD-4,3in_DISP1.37, LCD-5in_DISP1.37, LCD-7in_RTP1.3, LCD-10,1in_RTP1.3, R31.2, U1.18
RTP_X-(X1): C12.2, LCD-4,3in_DISP1.39, LCD-5in_DISP1.39, LCD-7in_RTP1.1, LCD-10,1in_RTP1.1, R25.1, R30.2, U1.19
RTP_Y+(Y2): LCD-4,3in_DISP1.40, LCD-5in_DISP1.40, LCD-7in_RTP1.4, LCD-10,1in_RTP1.4, R33.2, U1.15
RTP_Y-(Y1): C13.2, LCD-4,3in_DISP1.38, LCD-5in_DISP1.38, LCD-7in_RTP1.2, LCD-10,1in_RTP1.2, R32.2, U1.16
U/D: LCD-7in_DISP1.40, LCD-7in_DISP2.40, LCD-10,1in_DISP1.40, LCD-10,1in_DISP2.40, R13.1, R14.2, U/D_EN1.2
VCOM: C6.1, D1.1, LCD-7in_DISP1.6, LCD-7in_DISP1.46, LCD-7in_DISP2.6, LCD-7in_DISP2.46, LCD-10,1in_DISP1.6, LCD-10,1in_DISP1.46, LCD-10,1in_DISP2.6, LCD-10,1in_DISP2.46, PWR1.5, R15.2, R16.2
VDD: 3.3V/5.0V1.2, C25.1, C27.1, L1.2, L2.2, PWR1.4, R48.1, U3.3, U4.1, U4.3
VGH: C15.2, D3.1, LCD-7in_DISP1.41, LCD-7in_DISP2.41, LCD-10,1in_DISP1.41, LCD-10,1in_DISP2.41, PWR1.1, R35.2, R39.2
VGL: C26.2, D7.2, LCD-7in_DISP1.42, LCD-7in_DISP2.42, LCD-10,1in_DISP1.42, LCD-10,1in_DISP2.42, PWR1.7, R55.2, R58.2
VLED+: LCD-4,3in_DISP1.2, LCD-5in_DISP1.2, LCD-7in_DISP1.1, LCD-7in_DISP1.2, LCD-7in_DISP2.1, LCD-7in_DISP2.2, LCD-10,1in_DISP1.1, LCD-10,1in_DISP1.2, LCD-10,1in_DISP2.1, LCD-10,1in_DISP2.2, PWR1.8, VLED+_E1.1
VLED-: LCD-4,3in_DISP1.1, LCD-5in_DISP1.1, LCD-7in_DISP1.3, LCD-7in_DISP1.4, LCD-7in_DISP2.3, LCD-7in_DISP2.4, LCD-10,1in_DISP1.3, LCD-10,1in_DISP1.4, LCD-10,1in_DISP2.3, LCD-10,1in_DISP2.4, PWR1.9, VLED-_E1.1

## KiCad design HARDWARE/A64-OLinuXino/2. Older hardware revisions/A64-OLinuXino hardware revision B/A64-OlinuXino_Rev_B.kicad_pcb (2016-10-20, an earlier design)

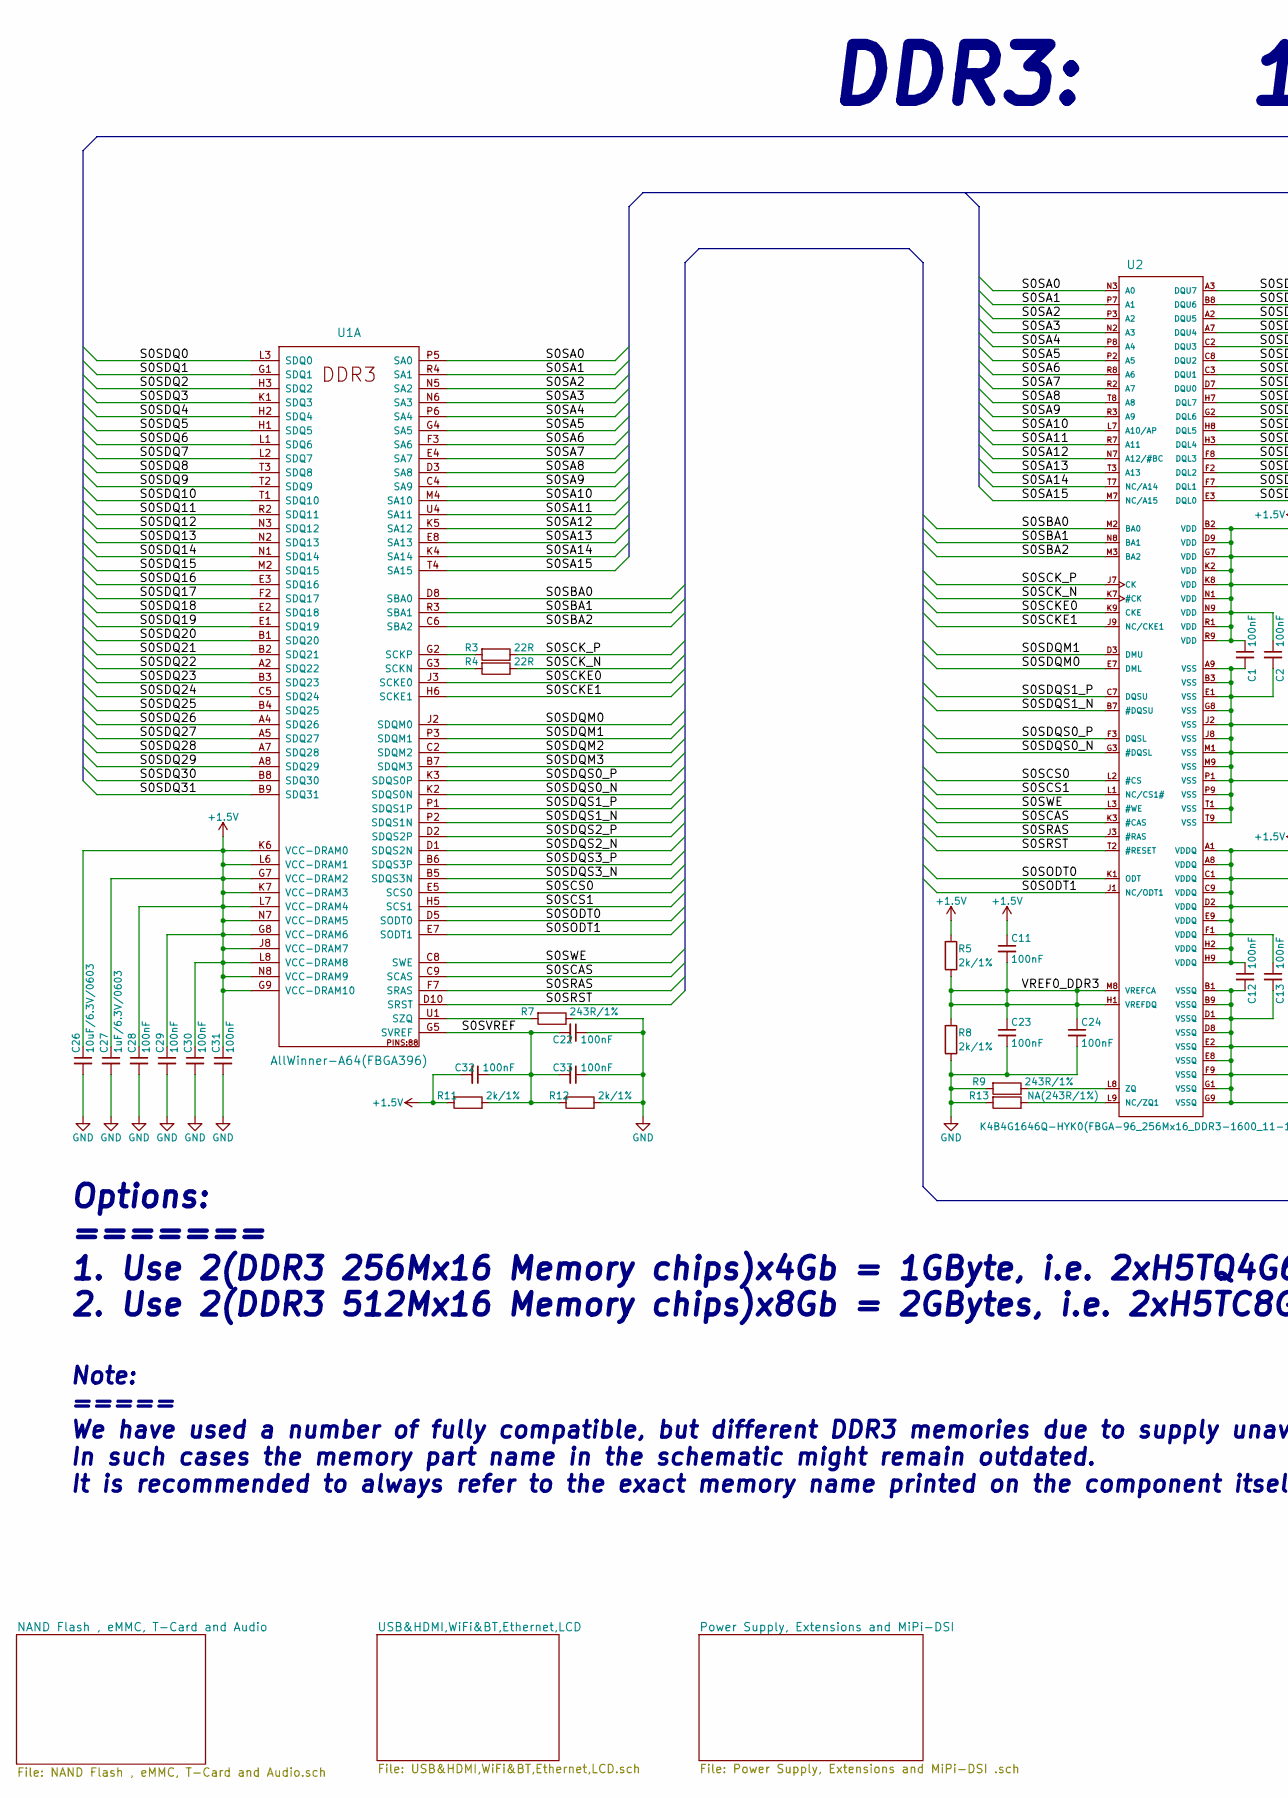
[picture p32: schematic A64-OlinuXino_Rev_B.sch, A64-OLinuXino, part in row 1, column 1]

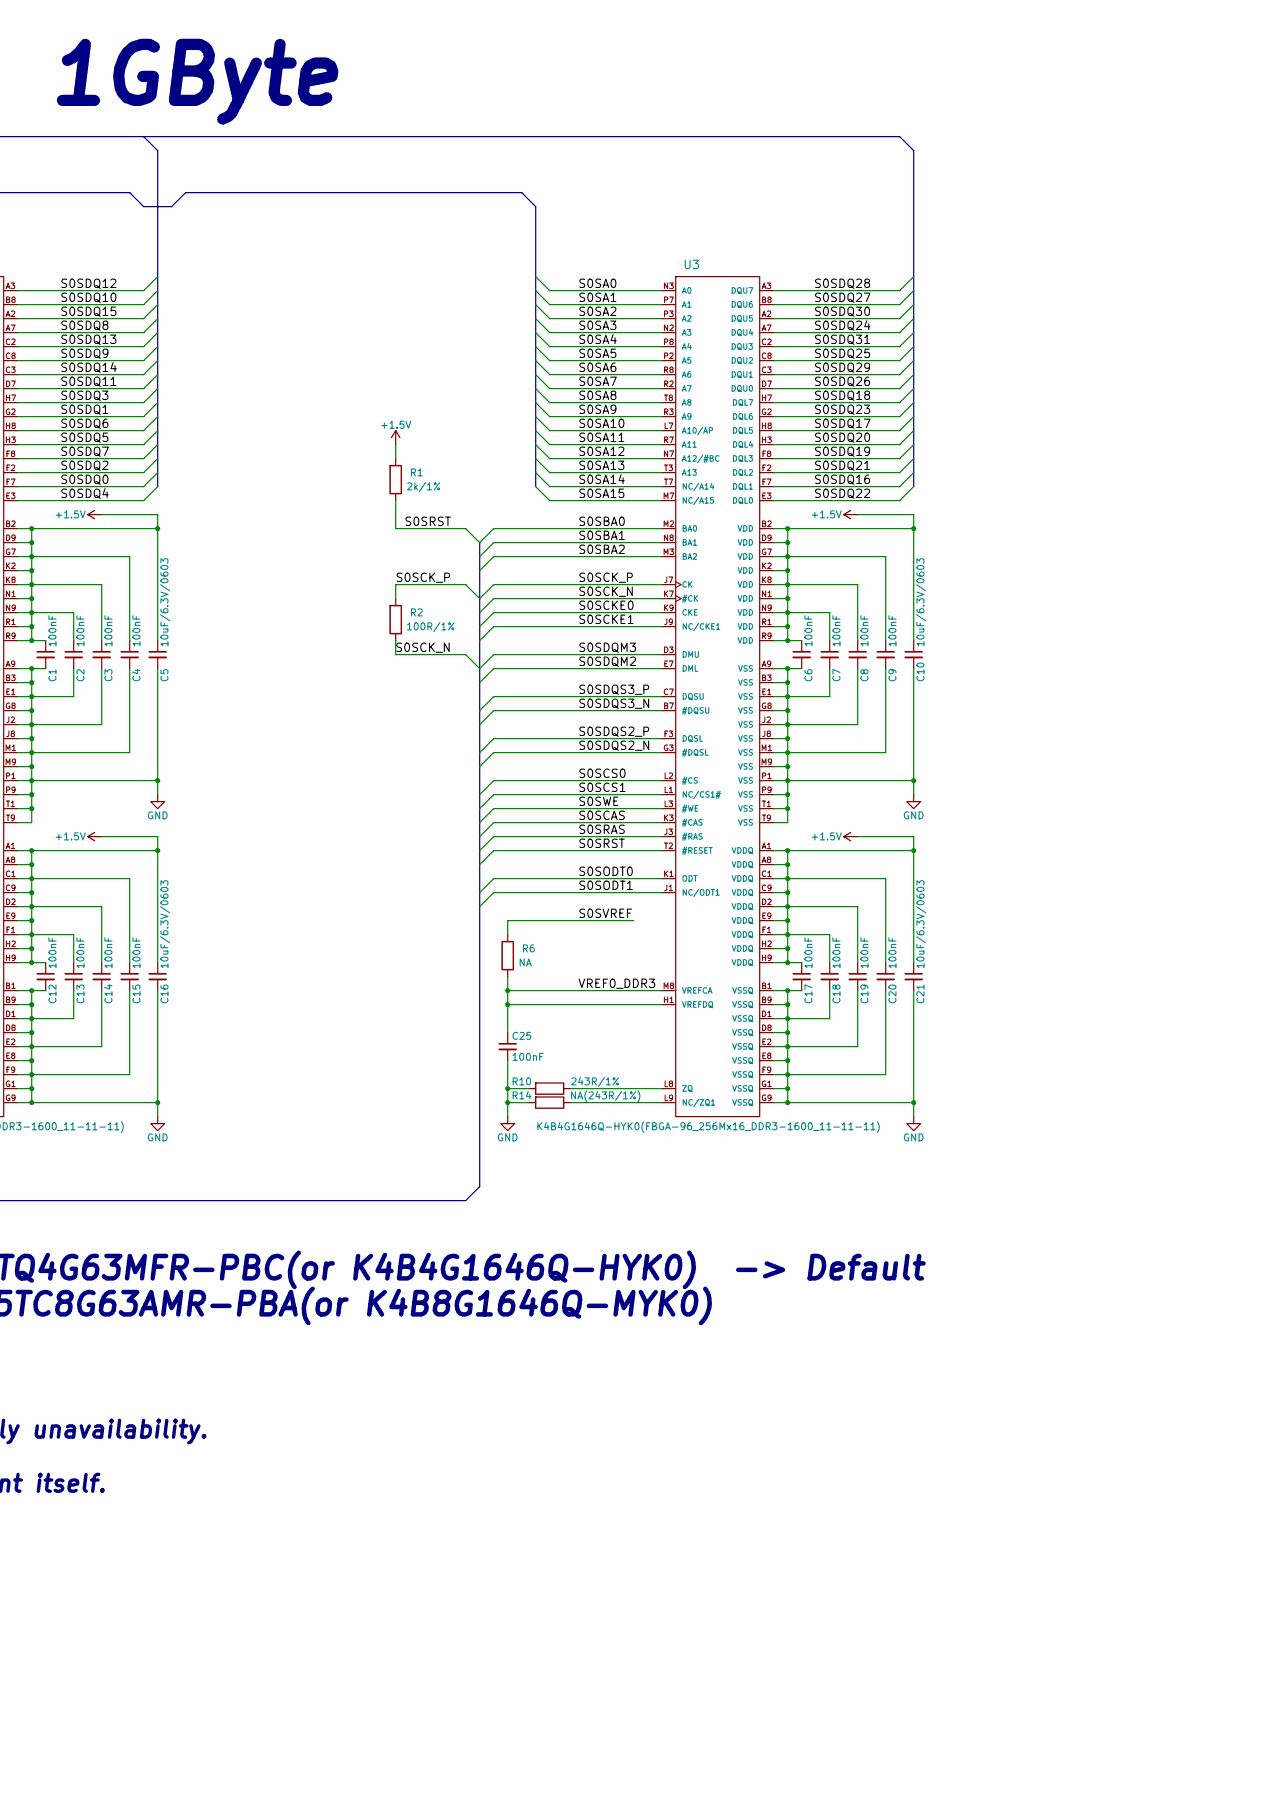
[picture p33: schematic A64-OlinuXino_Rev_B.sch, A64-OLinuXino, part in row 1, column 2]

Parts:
C1, C2, C3, C4, C6, C7, C8, C9, C11, C12, C13, C14, C15, C17, C18, C19, C20, C22, C23, C24, C25, C28, C29, C30, C31, C32, C33: 100nF; C_0402_5MIL_DWS
C5, C10, C16, C21, C26: 10uF/6.3V/0603; C_0603_5MIL_DWS
C27: 1uF/6.3V/0603; C_0603_5MIL_DWS
R1, R5, R8, R11, R12: 2k/1%; R_0402_5MIL_DWS
R2: 100R/1%; R_0402_5MIL_DWS
R3, R4: 22R; R_0402_5MIL_DWS
R6: NA; R_0402_5MIL_DWS
R7, R9, R10: 243R/1%; R_0402_5MIL_DWS
R13, R14: NA(243R/1%); R_0402_5MIL_DWS
U1: AllWinner-A64(FBGA396); FBGA396
U2, U3: K4B4G1646Q-HYK0(FBGA-96_256Mx16_DDR3-1600_11-11-1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; FBGA96(HYNIX_SAMSUNG_512MX16_DDR3)

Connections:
+1.5V: C1.1, C2.1, C3.1, C4.1, C5.1, C6.1, C7.1, C8.1, C9.1, C10.1, C11.1, C12.1, C13.1, C14.1, C15.1, C16.1, C17.1, C18.1, C19.1, C20.1, C21.1, C26.1, C27.1, C28.1, C29.1, C30.1, C31.1, C32.2, R1.2, R5.2, R11.2, U1.G7 (VCC-DRAM2), U1.G8 (VCC-DRAM6), U1.G9 (VCC-DRAM10), U1.J8 (VCC-DRAM7), U1.K6 (VCC-DRAM0), U1.K7 (VCC-DRAM3), U1.L6 (VCC-DRAM1), U1.L7 (VCC-DRAM4), U1.L8 (VCC-DRAM8), U1.N7 (VCC-DRAM5), U1.N8 (VCC-DRAM9), U2.A1 (VDDQ), U2.A8 (VDDQ), U2.B2 (VDD), U2.C1 (VDDQ), U2.C9 (VDDQ), U2.D2 (VDDQ), U2.D9 (VDD), U2.E9 (VDDQ), U2.F1 (VDDQ), U2.G7 (VDD), U2.H2 (VDDQ), U2.H9 (VDDQ), U2.K2 (VDD), U2.K8 (VDD), U2.N1 (VDD), U2.N9 (VDD), U2.R1 (VDD), U2.R9 (VDD), U3.A1 (VDDQ), U3.A8 (VDDQ), U3.B2 (VDD), U3.C1 (VDDQ), U3.C9 (VDDQ), U3.D2 (VDDQ), U3.D9 (VDD), U3.E9 (VDDQ), U3.F1 (VDDQ), U3.G7 (VDD), U3.H2 (VDDQ), U3.H9 (VDDQ), U3.K2 (VDD), U3.K8 (VDD), U3.N1 (VDD), U3.N9 (VDD), U3.R1 (VDD), U3.R9 (VDD); also elsewhere on the board
/S0SA0: U1.P5 (SA0), U2.N3 (A0), U3.N3 (A0)
/S0SA1: U1.R4 (SA1), U2.P7 (A1), U3.P7 (A1)
/S0SA2: U1.N5 (SA2), U2.P3 (A2), U3.P3 (A2)
/S0SA3: U1.N6 (SA3), U2.N2 (A3), U3.N2 (A3)
/S0SA4: U1.P6 (SA4), U2.P8 (A4), U3.P8 (A4)
/S0SA5: U1.G4 (SA5), U2.P2 (A5), U3.P2 (A5)
/S0SA6: U1.F3 (SA6), U2.R8 (A6), U3.R8 (A6)
/S0SA7: U1.E4 (SA7), U2.R2 (A7), U3.R2 (A7)
/S0SA8: U1.D3 (SA8), U2.T8 (A8), U3.T8 (A8)
/S0SA9: U1.C4 (SA9), U2.R3 (A9), U3.R3 (A9)
/S0SA10: U1.M4 (SA10), U2.L7 (A10/AP), U3.L7 (A10/AP)
/S0SA11: U1.U4 (SA11), U2.R7 (A11), U3.R7 (A11)
/S0SA12: U1.K5 (SA12), U2.N7 (A12/#BC), U3.N7 (A12/#BC)
/S0SA13: U1.E8 (SA13), U2.T3 (A13), U3.T3 (A13)
/S0SA14: U1.K4 (SA14), U2.T7 (NC/A14), U3.T7 (NC/A14)
/S0SA15: U1.T4 (SA15), U2.M7 (NC/A15), U3.M7 (NC/A15)
/S0SBA0: U1.D8 (SBA0), U2.M2 (BA0), U3.M2 (BA0)
/S0SBA1: U1.R3 (SBA1), U2.N8 (BA1), U3.N8 (BA1)
/S0SBA2: U1.C6 (SBA2), U2.M3 (BA2), U3.M3 (BA2)
/S0SCAS: U1.C9 (SCAS), U2.K3 (#CAS), U3.K3 (#CAS)
/S0SCKE0: U1.J3 (SCKE0), U2.K9 (CKE), U3.K9 (CKE)
/S0SCKE1: U1.H6 (SCKE1), U2.J9 (NC/CKE1), U3.J9 (NC/CKE1)
/S0SCK_N: R2.1, R4.1, U2.K7 (#CK), U3.K7 (#CK)
/S0SCK_P: R2.2, R3.1, U2.J7 (CK), U3.J7 (CK)
/S0SCS0: U1.E5 (SCS0), U2.L2 (#CS), U3.L2 (#CS)
/S0SCS1: U1.H5 (SCS1), U2.L1 (NC/CS1#), U3.L1 (NC/CS1#)
/S0SDQ0: U1.L3 (SDQ0), U2.F7 (DQL1)
/S0SDQ1: U1.G1 (SDQ1), U2.G2 (DQL6)
/S0SDQ2: U1.H3 (SDQ2), U2.F2 (DQL2)
/S0SDQ3: U1.K1 (SDQ3), U2.H7 (DQL7)
/S0SDQ4: U1.H2 (SDQ4), U2.E3 (DQL0)
/S0SDQ5: U1.H1 (SDQ5), U2.H3 (DQL4)
/S0SDQ6: U1.L1 (SDQ6), U2.H8 (DQL5)
/S0SDQ7: U1.L2 (SDQ7), U2.F8 (DQL3)
/S0SDQ8: U1.T3 (SDQ8), U2.A7 (DQU4)
/S0SDQ9: U1.T2 (SDQ9), U2.C8 (DQU2)
/S0SDQ10: U1.T1 (SDQ10), U2.B8 (DQU6)
/S0SDQ11: U1.R2 (SDQ11), U2.D7 (DQU0)
/S0SDQ12: U1.N3 (SDQ12), U2.A3 (DQU7)
/S0SDQ13: U1.N2 (SDQ13), U2.C2 (DQU3)
/S0SDQ14: U1.N1 (SDQ14), U2.C3 (DQU1)
/S0SDQ15: U1.M2 (SDQ15), U2.A2 (DQU5)
/S0SDQ16: U1.E3 (SDQ16), U3.F7 (DQL1)
/S0SDQ17: U1.F2 (SDQ17), U3.H8 (DQL5)
/S0SDQ18: U1.E2 (SDQ18), U3.H7 (DQL7)
/S0SDQ19: U1.E1 (SDQ19), U3.F8 (DQL3)
/S0SDQ20: U1.B1 (SDQ20), U3.H3 (DQL4)
/S0SDQ21: U1.B2 (SDQ21), U3.F2 (DQL2)
/S0SDQ22: U1.A2 (SDQ22), U3.E3 (DQL0)
/S0SDQ23: U1.B3 (SDQ23), U3.G2 (DQL6)
/S0SDQ24: U1.C5 (SDQ24), U3.A7 (DQU4)
/S0SDQ25: U1.B4 (SDQ25), U3.C8 (DQU2)
/S0SDQ26: U1.A4 (SDQ26), U3.D7 (DQU0)
/S0SDQ27: U1.A5 (SDQ27), U3.B8 (DQU6)
/S0SDQ28: U1.A7 (SDQ28), U3.A3 (DQU7)
/S0SDQ29: U1.A8 (SDQ29), U3.C3 (DQU1)
/S0SDQ30: U1.B8 (SDQ30), U3.A2 (DQU5)
/S0SDQ31: U1.B9 (SDQ31), U3.C2 (DQU3)
/S0SDQM0: U1.J2 (SDQM0), U2.E7 (DML)
/S0SDQM1: U1.P3 (SDQM1), U2.D3 (DMU)
/S0SDQM2: U1.C2 (SDQM2), U3.E7 (DML)
/S0SDQM3: U1.B7 (SDQM3), U3.D3 (DMU)
/S0SDQS0_N: U1.K2 (SDQS0N), U2.G3 (#DQSL)
/S0SDQS0_P: U1.K3 (SDQS0P), U2.F3 (DQSL)
/S0SDQS1_N: U1.P2 (SDQS1N), U2.B7 (#DQSU)
/S0SDQS1_P: U1.P1 (SDQS1P), U2.C7 (DQSU)
/S0SDQS2_N: U1.D1 (SDQS2N), U3.G3 (#DQSL)
/S0SDQS2_P: U1.D2 (SDQS2P), U3.F3 (DQSL)
/S0SDQS3_N: U1.B5 (SDQS3N), U3.B7 (#DQSU)
/S0SDQS3_P: U1.B6 (SDQS3P), U3.C7 (DQSU)
/S0SODT0: U1.D5 (SODT0), U2.K1 (ODT), U3.K1 (ODT)
/S0SODT1: U1.E7 (SODT1), U2.J1 (NC/ODT1), U3.J1 (NC/ODT1)
/S0SRAS: U1.F7 (SRAS), U2.J3 (#RAS), U3.J3 (#RAS)
/S0SRST: R1.1, U1.D10 (SRST), U2.T2 (#RESET), U3.T2 (#RESET)
/S0SVREF: C22.2, C32.1, C33.2, R6.2, R11.1, R12.2, U1.G5 (SVREF)
/S0SWE: U1.C8 (SWE), U2.L3 (#WE), U3.L3 (#WE)
/VREF0_DDR3: C11.2, C23.1, C24.1, C25.1, R5.1, R6.1, R8.2, U2.H1 (VREFDQ), U2.M8 (VREFCA), U3.H1 (VREFDQ), U3.M8 (VREFCA)
GND: C1.2, C2.2, C3.2, C4.2, C5.2, C6.2, C7.2, C8.2, C9.2, C10.2, C12.2, C13.2, C14.2, C15.2, C16.2, C17.2, C18.2, C19.2, C20.2, C21.2, C22.1, C23.2, C24.2, C25.2, C26.2, C27.2, C28.2, C29.2, C30.2, C31.2, C33.1, R7.1, R8.1, R9.2, R10.2, R12.1, R13.2, R14.2, U2.A9 (VSS), U2.B1 (VSSQ), U2.B3 (VSS), U2.B9 (VSSQ), U2.D1 (VSSQ), U2.D8 (VSSQ), U2.E1 (VSS), U2.E2 (VSSQ), U2.E8 (VSSQ), U2.F9 (VSSQ), U2.G1 (VSSQ), U2.G8 (VSS), U2.G9 (VSSQ), U2.J2 (VSS), U2.J8 (VSS), U2.M1 (VSS), U2.M9 (VSS), U2.P1 (VSS), U2.P9 (VSS), U2.T1 (VSS), U2.T9 (VSS), U3.A9 (VSS), U3.B1 (VSSQ), U3.B3 (VSS), U3.B9 (VSSQ), U3.D1 (VSSQ), U3.D8 (VSSQ), U3.E1 (VSS), U3.E2 (VSSQ), U3.E8 (VSSQ), U3.F9 (VSSQ), U3.G1 (VSSQ), U3.G8 (VSS), U3.G9 (VSSQ), U3.J2 (VSS), U3.J8 (VSS), U3.M1 (VSS), U3.M9 (VSS), U3.P1 (VSS), U3.P9 (VSS), U3.T1 (VSS), U3.T9 (VSS); also elsewhere on the board
unnamed: R3.2, U1.G2 (SCKP)
unnamed: R4.2, U1.G3 (SCKN)
unnamed: R7.2, U1.U1 (SZQ)
unnamed: R9.1, U2.L8 (ZQ)
unnamed: R10.1, U3.L8 (ZQ)
unnamed: R13.1, U2.L9 (NC/ZQ1)
unnamed: R14.1, U3.L9 (NC/ZQ1)

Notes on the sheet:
DDR3: 1GByte
Options: ======= 1. Use 2(DDR3 256Mx16 Memory chips)x4Gb = 1GByte, i.e. 2xH5TQ4G63MFR-PBC(or K4B4G1646Q-HYK0) -> Default 2. Use 2(DDR3 512Mx16 Memory chips)x8Gb = 2GBytes, i.e. 2xH5TC8G63AMR-PBA(or K4B8G1646Q-MYK0)
Note: ===== We have used a number of fully compatible, but different DDR3 memories due to supply unavailability. In such cases the memory part name in the schematic might remain outdated. It is recommended to always refer to the exact memory name printed on the component itself.

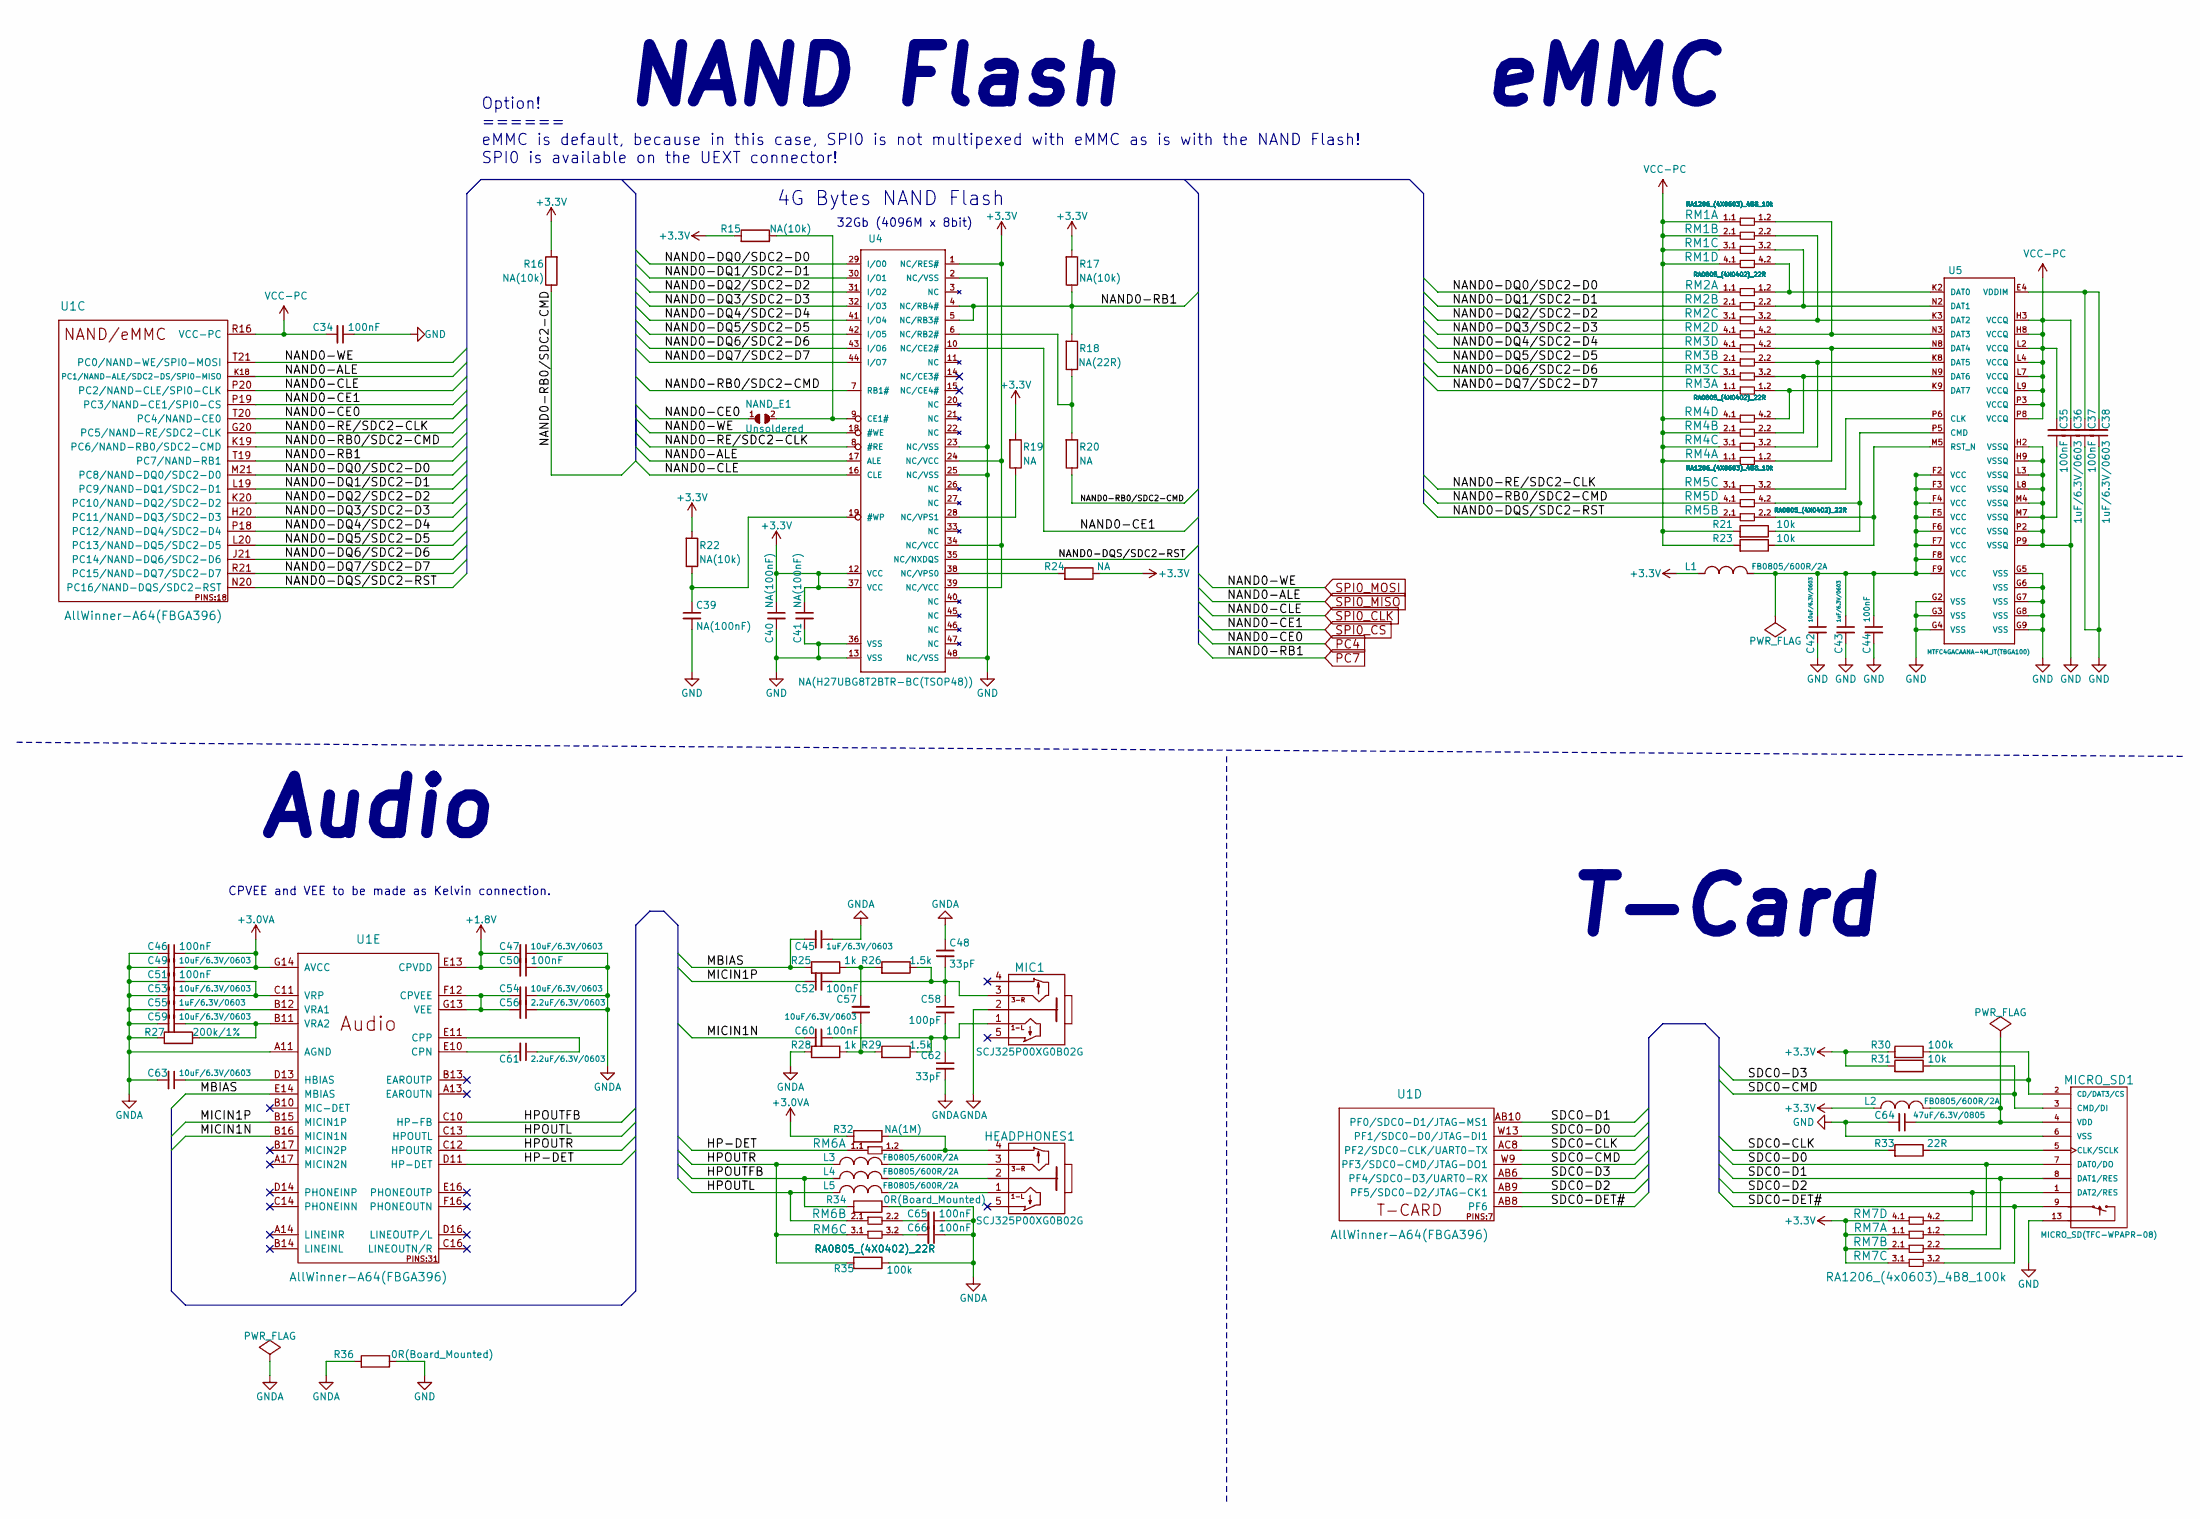
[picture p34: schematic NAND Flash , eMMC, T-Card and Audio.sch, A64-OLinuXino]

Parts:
C34, C35, C37, C44, C46, C50, C51, C52, C60, C65, C66: 100nF; C_0402_5MIL_DWS
C36, C38, C43, C45, C55: 1uF/6.3V/0603; C_0603_5MIL_DWS
C39, C40, C41: NA(100nF); C_0402_5MIL_DWS
C42, C47, C49, C53, C54, C57, C59, C63: 10uF/6.3V/0603; C_0603_5MIL_DWS
C48, C62: 33pF; C_0402_5MIL_DWS
C56, C61: 2.2uF/6.3V/0603; C_0603_5MIL_DWS
C58: 100pF; C_0402_5MIL_DWS
C64: 47uF/6.3V/0805; C_0805_5MIL_DWS
HEADPHONES1: SCJ325P00XG0B02G
L1, L2, L3, L4, L5: FB0805/600R/2A; L_0805_5MIL_DWS
MIC1: SCJ325P00XG0B02G
MICRO_SD1: MICRO_SD(TFC-WPAPR-08); TFC-WPAPR-08
NAND_E1: Unsoldered; SJ
R15, R16, R17, R22: NA(10k); R_0402_5MIL_DWS
R18: NA(22R); R_0402_5MIL_DWS
R19, R20, R24: NA; R_0402_5MIL_DWS
R21, R23, R31: 10k; R_0402_5MIL_DWS
R25, R28: 1k; R_0402_5MIL_DWS
R26, R29: 1.5k; R_0402_5MIL_DWS
R27: 200k/1%; R_0402_5MIL_DWS
R30, R35: 100k; R_0402_5MIL_DWS
R32: NA(1M); R_0402_5MIL_DWS
R33: 22R; R_0402_5MIL_DWS
R34: 0R(Board_Mounted); R_0402_5MIL_0R(Board_Mounted)
R36: 0R(Board_Mounted); R_0603_5MIL_0R(Board_Mounted)
RM1, RM4: RA1206_(4X0603)_4B8_10k; RA1206_(4X0603)_4B8_xx
RM2, RM3, RM5, RM6: RA0805_(4X0402)_22R; RA0805_(4X0402)_xx
RM7: RA1206_(4x0603)_4B8_100k; RA1206_(4X0603)_4B8_xx
U1: AllWinner-A64(FBGA396); FBGA396
U4: NA(H27UBG8T2BTR-BC(TSOP48)); TSOP48
U5: MTFC4GACAANA-4M_IT(TBGA100); TBGA100

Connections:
+1V8: C47.2, C50.2, U1.E13 (CPVDD); also elsewhere on the board
+3.0VA: C46.1, C49.1, R32.2, U1.G14 (AVCC); also elsewhere on the board
+3V3: C40.1, C41.1, L1.1, L2.1, R15.2, R16.2, R17.2, R19.2, R22.2, R24.1, R30.2, R31.2, RM7.1.1, RM7.2.1, RM7.3.1, RM7.4.1, U4.1 (NC/RES#), U4.12 (VCC), U4.24 (NC/VCC), U4.34 (NC/VCC), U4.37 (VCC), U4.39 (NC/VCC); also elsewhere on the board
/NAND Flash , eMMC, T-Card and Audio/HP-DET: RM6.1.1, U1.D11 (HP-DET)
/NAND Flash , eMMC, T-Card and Audio/HPOUTFB: L4.1, R34.2, U1.C10 (HP-FB)
/NAND Flash , eMMC, T-Card and Audio/HPOUTL: L5.1, RM6.2.1, U1.C13 (HPOUTL)
/NAND Flash , eMMC, T-Card and Audio/HPOUTR: L3.1, R35.2, RM6.3.1, U1.C12 (HPOUTR)
/NAND Flash , eMMC, T-Card and Audio/MBIAS: C45.2, R25.2, U1.E14 (MBIAS)
/NAND Flash , eMMC, T-Card and Audio/MICIN1N: C60.2, U1.B16 (MICIN1N)
/NAND Flash , eMMC, T-Card and Audio/MICIN1P: C52.2, U1.B15 (MICIN1P)
/NAND Flash , eMMC, T-Card and Audio/NAND0-DQ0/SDC2-D0: RM2.1.1, U1.M21 (PC8/NAND-DQ0/SDC2-D0), U4.29 (I/O0)
/NAND Flash , eMMC, T-Card and Audio/NAND0-DQ1/SDC2-D1: RM2.2.1, U1.L19 (PC9/NAND-DQ1/SDC2-D1), U4.30 (I/O1)
/NAND Flash , eMMC, T-Card and Audio/NAND0-DQ2/SDC2-D2: RM2.3.1, U1.K20 (PC10/NAND-DQ2/SDC2-D2), U4.31 (I/O2)
/NAND Flash , eMMC, T-Card and Audio/NAND0-DQ3/SDC2-D3: RM2.4.1, U1.H20 (PC11/NAND-DQ3/SDC2-D3), U4.32 (I/O3)
/NAND Flash , eMMC, T-Card and Audio/NAND0-DQ4/SDC2-D4: RM3.4.1, U1.P18 (PC12/NAND-DQ4/SDC2-D4), U4.41 (I/O4)
/NAND Flash , eMMC, T-Card and Audio/NAND0-DQ5/SDC2-D5: RM3.2.1, U1.L20 (PC13/NAND-DQ5/SDC2-D5), U4.42 (I/O5)
/NAND Flash , eMMC, T-Card and Audio/NAND0-DQ6/SDC2-D6: RM3.3.1, U1.J21 (PC14/NAND-DQ6/SDC2-D6), U4.43 (I/O6)
/NAND Flash , eMMC, T-Card and Audio/NAND0-DQ7/SDC2-D7: RM3.1.1, U1.R21 (PC15/NAND-DQ7/SDC2-D7), U4.44 (I/O7)
/NAND Flash , eMMC, T-Card and Audio/NAND0-DQS/SDC2-RST: RM5.2.1, U1.N20 (PC16/NAND-DQS/SDC2-RST), U4.35 (NC/NXDQS)
/NAND Flash , eMMC, T-Card and Audio/NAND0-RB0/SDC2-CMD: R16.1, R20.1, RM5.4.1, U1.K19 (PC6/NAND-RB0/SDC2-CMD), U4.7 (RB1#)
/NAND Flash , eMMC, T-Card and Audio/NAND0-RE/SDC2-CLK: RM5.3.1, U1.G20 (PC5/NAND-RE/SDC2-CLK), U4.8 (#RE)
/NAND Flash , eMMC, T-Card and Audio/SDC0-CLK: R33.2, U1.AC8 (PF2/SDC0-CLK/UART0-TX)
/NAND Flash , eMMC, T-Card and Audio/SDC0-CMD: MICRO_SD1.3 (CMD/DI), R31.1, U1.W9 (PF3/SDC0-CMD/JTAG-DO1)
/NAND Flash , eMMC, T-Card and Audio/SDC0-D0: MICRO_SD1.7 (DAT0/DO), RM7.1.2, U1.W13 (PF1/SDC0-D0/JTAG-DI1)
/NAND Flash , eMMC, T-Card and Audio/SDC0-D1: MICRO_SD1.8 (DAT1/RES), RM7.2.2, U1.AB10 (PF0/SDC0-D1/JTAG-MS1)
/NAND Flash , eMMC, T-Card and Audio/SDC0-D2: MICRO_SD1.1 (DAT2/RES), RM7.4.2, U1.AB9 (PF5/SDC0-D2/JTAG-CK1)
/NAND Flash , eMMC, T-Card and Audio/SDC0-D3: MICRO_SD1.2 (CD/DAT3/CS), R30.1, U1.AB6 (PF4/SDC0-D3/UART0-RX)
/NAND Flash , eMMC, T-Card and Audio/SDC0-DET#: MICRO_SD1.9, RM7.3.2, U1.AB8 (PF6)
GND: C34.1, C35.1, C36.1, C37.1, C38.1, C39.2, C40.2, C41.2, C42.2, C43.2, C44.2, C64.2, MICRO_SD1.6 (VSS), MICRO_SD1.10, MICRO_SD1.11, MICRO_SD1.12, MICRO_SD1.13, R36.1, U4.2 (NC/VSS), U4.13 (VSS), U4.23 (NC/VSS), U4.25 (NC/VSS), U4.36 (VSS), U4.48 (NC/VSS), U5.G2 (VSS), U5.G3 (VSS), U5.G4 (VSS), U5.G5 (VSS), U5.G6 (VSS), U5.G7 (VSS), U5.G8 (VSS), U5.G9 (VSS), U5.H2 (VSSQ), U5.H9 (VSSQ), U5.L3 (VSSQ), U5.L8 (VSSQ), U5.M4 (VSSQ), U5.M7 (VSSQ), U5.P2 (VSSQ), U5.P9 (VSSQ); also elsewhere on the board
GNDA: C45.1, C46.2, C47.1, C48.1, C49.2, C50.1, C51.2, C53.2, C54.1, C55.2, C56.1, C59.2, C62.2, C63.2, C65.1, C66.1, MIC1.2, R27.2, R28.2, R34.1, R35.1, R36.2, U1.A11 (AGND)
unnamed: C37.2, C38.2, U5.E4 (VDDIM)
unnamed: C39.1, R22.1, U4.19 (#WP)
unnamed: C42.1, C43.1, C44.1, L1.2, U5.F2 (VCC), U5.F3 (VCC), U5.F4 (VCC), U5.F5 (VCC), U5.F6 (VCC), U5.F7 (VCC), U5.F8 (VCC), U5.F9 (VCC)
unnamed: C48.2, C52.1, C58.1, MIC1.3, R26.1
unnamed: C51.1, C53.1, U1.C11 (VRP)
unnamed: C54.2, C56.2, U1.F12 (CPVEE), U1.G13 (VEE)
unnamed: C55.1, U1.B12 (VRA1)
unnamed: C57.1, R28.1, R29.2
unnamed: C57.2, R25.1, R26.2
unnamed: C58.2, C60.1, C62.1, MIC1.1, R29.1
unnamed: C59.1, R27.1, U1.B11 (VRA2)
unnamed: C61.1, U1.E11 (CPP)
unnamed: C61.2, U1.E10 (CPN)
unnamed: C63.1, U1.D13 (HBIAS)
unnamed: C64.1, L2.2, MICRO_SD1.4 (VDD)
unnamed: C65.2, RM6.2.2
unnamed: C66.2, RM6.3.2
unnamed: HEADPHONES1.1, L5.2
unnamed: HEADPHONES1.2, L4.2
unnamed: HEADPHONES1.3, L3.2
unnamed: HEADPHONES1.4, R32.1, RM6.1.2
unnamed: MICRO_SD1.5 (CLK/SCLK), R33.1
unnamed: NAND_E1.2, R15.1, U4.9 (CE1#)
unnamed: R18.1, R20.2, U4.6 (NC/RB2#)
unnamed: R19.1, U4.28 (NC/VPS1)
unnamed: R21.1, RM5.4.2, U5.P5 (CMD)
unnamed: R23.1, RM5.2.2, U5.M5 (RST_N)
unnamed: R24.2, U4.38 (NC/VPS0)
unnamed: RM1.1.2, RM2.4.2, U5.N3 (DAT3)
unnamed: RM1.2.2, RM2.3.2, U5.K3 (DAT2)
unnamed: RM1.3.2, RM2.2.2, U5.N2 (DAT1)
unnamed: RM1.4.2, RM2.1.2, U5.K2 (DAT0)
unnamed: RM3.1.2, RM4.4.2, U5.K9 (DAT7)
unnamed: RM3.2.2, RM4.3.2, U5.K8 (DAT5)
unnamed: RM3.3.2, RM4.2.2, U5.N9 (DAT6)
unnamed: RM3.4.2, RM4.1.2, U5.N8 (DAT4)
unnamed: RM5.3.2, U5.P6 (CLK)
PC4: NAND_E1.1, U1.T20 (PC4/NAND-CE0); also elsewhere on the board
PC7: R17.1, R18.2, U1.T19 (PC7/NAND-RB1), U4.4 (NC/RB4#), U4.5 (NC/RB3#); also elsewhere on the board
SPI0_CLK: U1.P20 (PC2/NAND-CLE/SPI0-CLK), U4.16 (CLE); also elsewhere on the board
SPI0_CS: U1.P19 (PC3/NAND-CE1/SPI0-CS), U4.10 (NC/CE2#); also elsewhere on the board
SPI0_MISO: U1.K18 (PC1/NAND-ALE/SDC2-DS/SPI0-MISO), U4.17 (ALE); also elsewhere on the board
SPI0_MOSI: U1.T21 (PC0/NAND-WE/SPI0-MOSI), U4.18 (#WE); also elsewhere on the board
VCC-PC: C34.2, C35.2, C36.2, R21.2, R23.2, RM1.1.1, RM1.2.1, RM1.3.1, RM1.4.1, RM4.1.1, RM4.2.1, RM4.3.1, RM4.4.1, U1.R16 (VCC-PC), U5.H3 (VCCQ), U5.H8 (VCCQ), U5.L2 (VCCQ), U5.L4 (VCCQ), U5.L7 (VCCQ), U5.L9 (VCCQ), U5.P3 (VCCQ), U5.P8 (VCCQ); also elsewhere on the board

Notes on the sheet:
NAND Flash
4G Bytes NAND Flash
32Gb (4096M x 8bit)
Option! ====== eMMC is default, because in this case, SPI0 is not multipexed with eMMC as is with the NAND Flash! SPI0 is available on the UEXT connector!
CPVEE and VEE to be made as Kelvin connection.
Audio
T-Card
eMMC

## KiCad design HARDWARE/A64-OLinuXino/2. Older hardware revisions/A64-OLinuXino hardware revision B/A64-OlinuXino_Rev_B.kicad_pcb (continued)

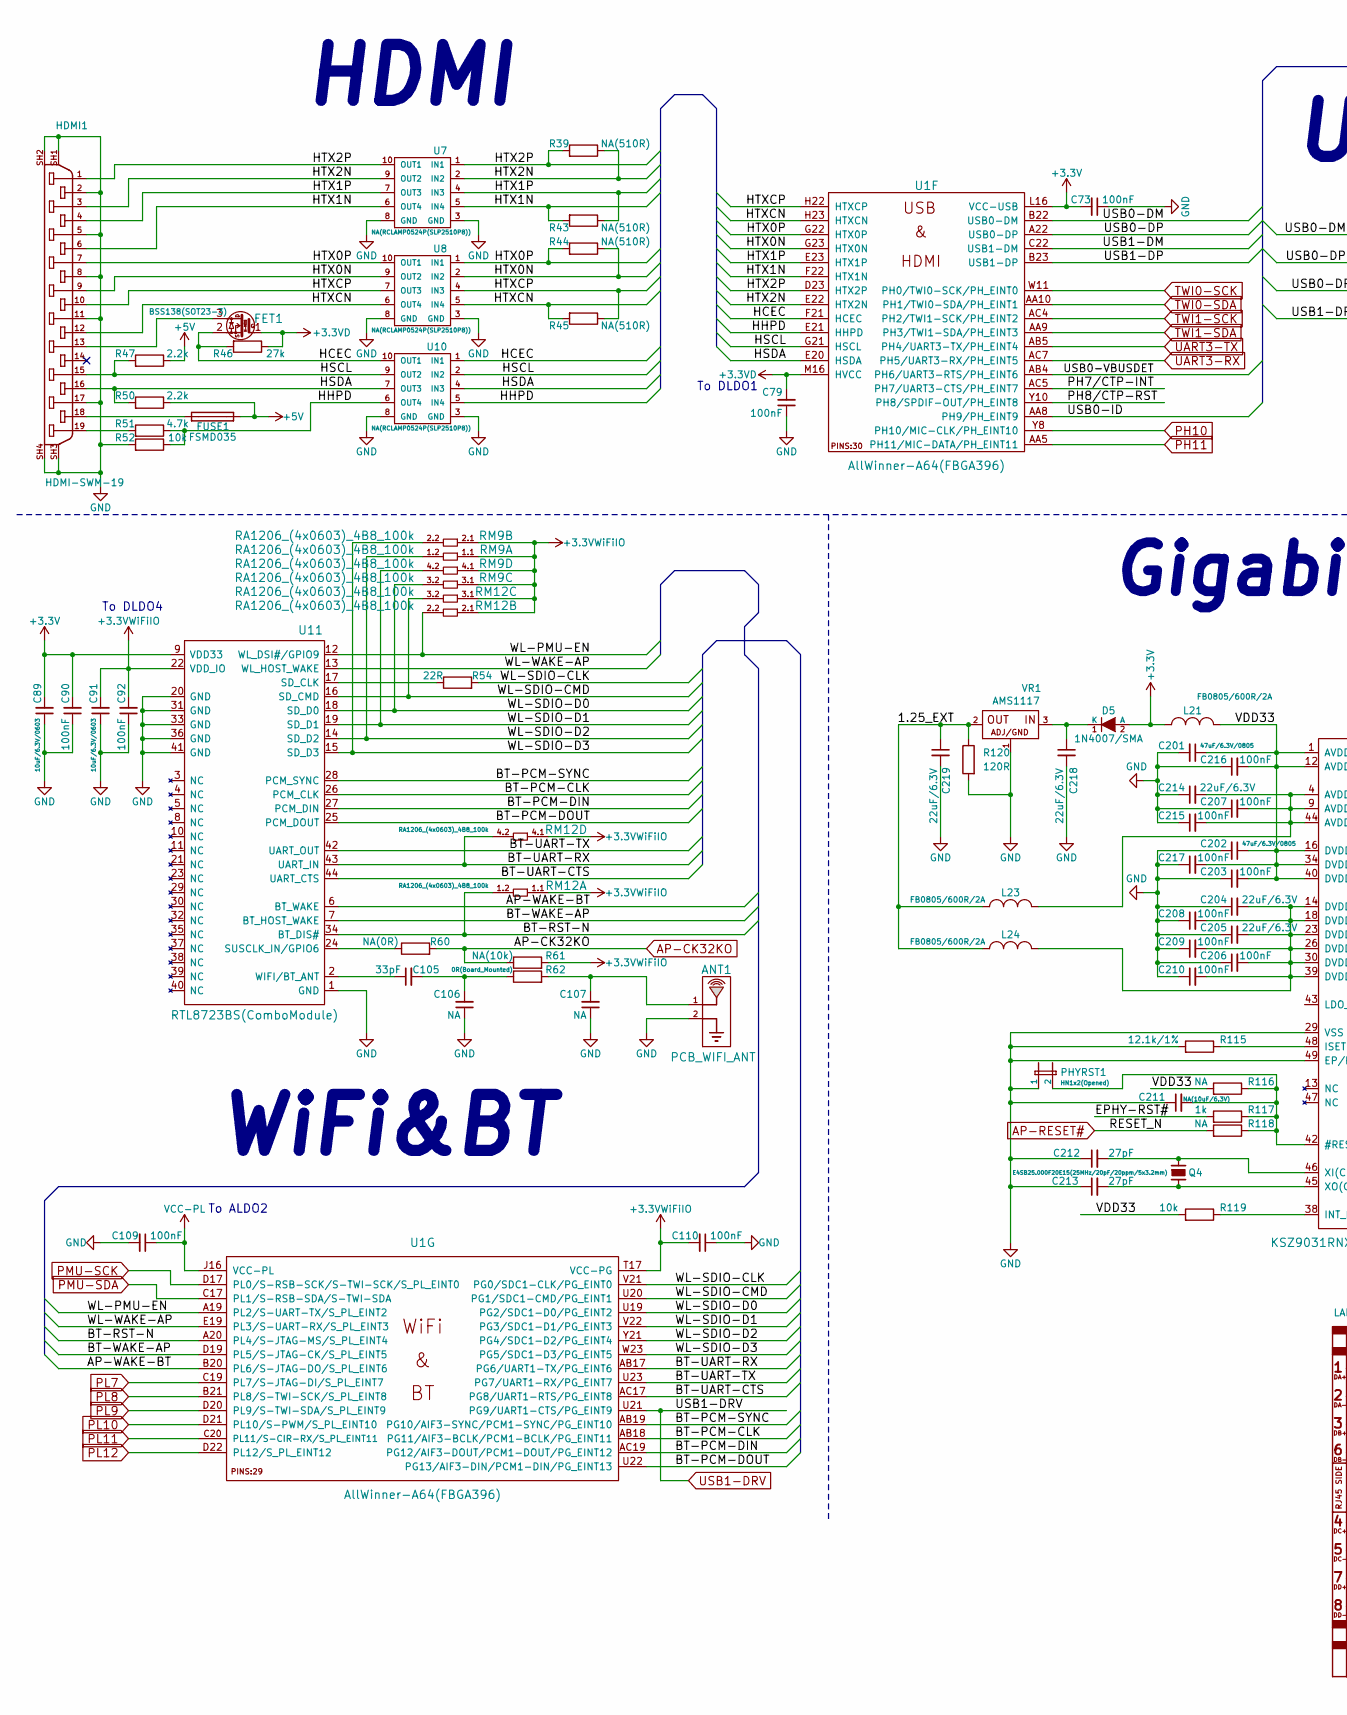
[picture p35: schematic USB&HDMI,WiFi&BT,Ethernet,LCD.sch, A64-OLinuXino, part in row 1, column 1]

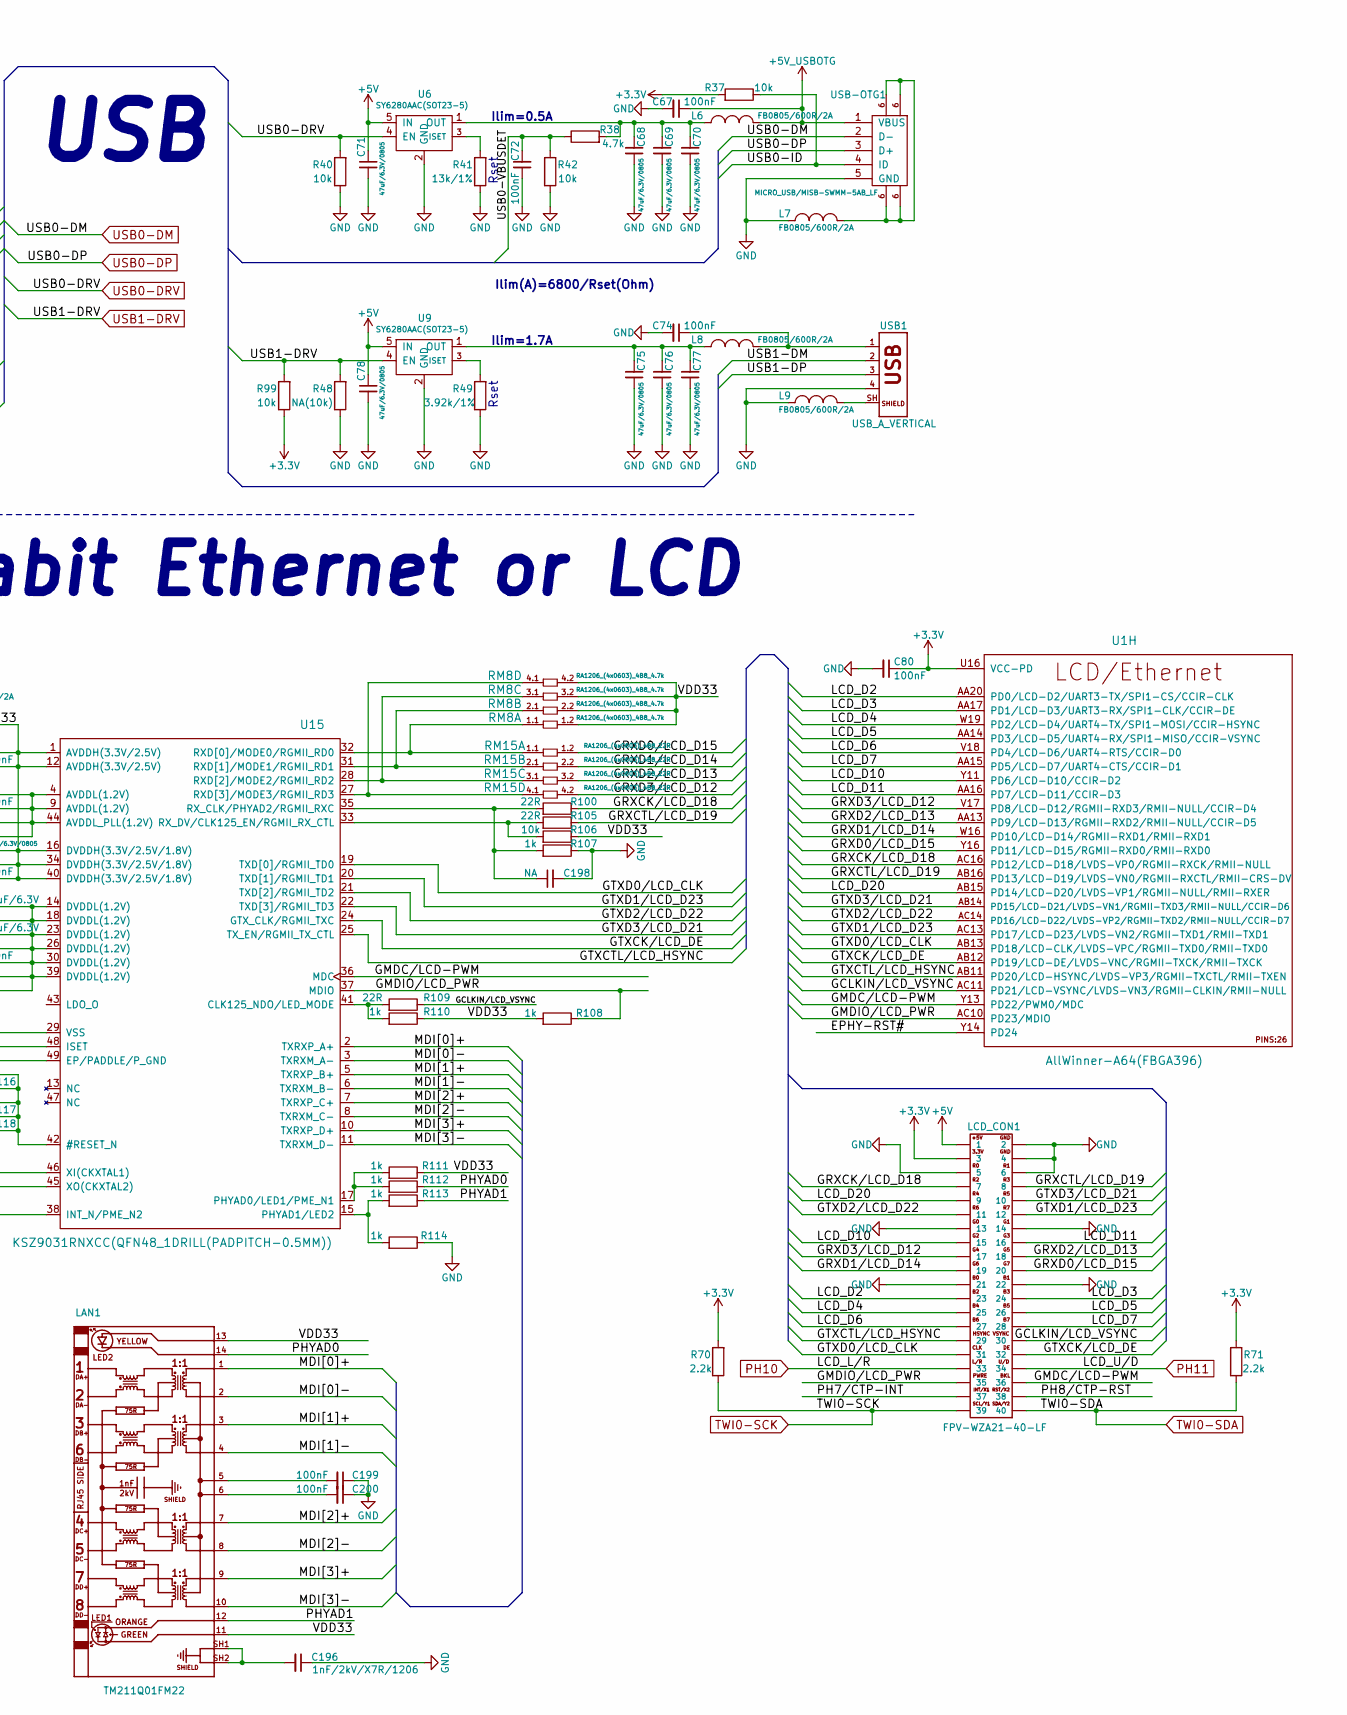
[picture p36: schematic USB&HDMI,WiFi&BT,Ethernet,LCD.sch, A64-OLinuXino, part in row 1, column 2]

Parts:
ANT1: PCB_WIFI_ANT; bt_antenna_1ant_2gnd
C67, C72, C73, C74, C79, C80, C90, C92, C109, C110, C199, C200, C203, C206, C207, C208, C209, C210, C215, C216, C217: 100nF; C_0402_5MIL_DWS
C68, C69, C70, C71, C75, C76, C77, C78, C201, C202: 47uF/6.3V/0805; C_0805_5MIL_DWS
C89, C91: 10uF/6.3V/0603; C_0603_5MIL_DWS
C105: 33pF; C_0402_5MIL_DWS
C106, C107, C198: NA; C_0402_5MIL_DWS
C196: 1nF/2kV/X7R/1206; C_1206_5MIL_DWS_ISO
C204, C205, C214, C218, C219: 22uF/6.3V; C_0603_5MIL_DWS
C211: NA(10uF/6.3V); C_0603_5MIL_DWS
C212, C213: 27pF; C_0603_5MIL_DWS
D5: 1N4007/SMA; SMA-KA
FET1: BSS138(SOT23-3); SOT23
FUSE1: FSMD035; FUSE-1206
HDMI1: HDMI-SWM-19
L6, L7, L8, L9, L21, L23, L24: FB0805/600R/2A; L_0805_5MIL_DWS
LAN1: TM211Q01FM22
LCD_CON1: FPV-WZA21-40-LF
PHYRST1: HN1x2(Opened); HN1x2_Jumper
Q4: E4SB25.000F20E15(25MHz/20pF/20ppm/5x3.2mm); HCX-4S_2Pins_5.0x3.2mm
R37, R40, R42, R52, R99, R106, R119: 10k; R_0402_5MIL_DWS
R38, R51: 4.7k; R_0402_5MIL_DWS
R39, R43, R44, R45: NA(510R); R_0402_5MIL_DWS
R41: 13k/1%; R_0402_5MIL_DWS
R46: 27k; R_0402_5MIL_DWS
R47, R50, R70, R71: 2.2k; R_0402_5MIL_DWS
R48, R61: NA(10k); R_0402_5MIL_DWS
R49: 3.92k/1%; R_0402_5MIL_DWS
R54, R100, R105, R109: 22R; R_0402_5MIL_DWS
R60: NA(0R); R_0402_5MIL_DWS
R62: 0R(Board_Mounted); R_0402_5MIL_0R(Board_Mounted)
R107, R108, R110, R111, R112, R113, R114, R117: 1k; R_0402_5MIL_DWS
R115: 12.1k/1%; R_0603_5MIL_DWS
R116, R118: NA; R_0402_5MIL_DWS
R120: 120R; R_0603_5MIL_DWS
RM8: RA1206_(4x0603)_4B8_4.7k; RA1206_(4X0603)_4B8_xx
RM9, RM12: RA1206_(4x0603)_4B8_100k; RA1206_(4X0603)_4B8_xx
RM15: RA1206_(4x0603)_4B8_22R; RA1206_(4X0603)_4B8_xx
U1: AllWinner-A64(FBGA396); FBGA396
U6, U9: SY6280AAC(SOT23-5); SOT-23-5
U7, U8, U10: NA(RCLAMP0524P(SLP2510P8)); SLP2510P8
U11: RTL8723BS(ComboModule); RL-SM02BD(RTL8723BS)
U15: KSZ9031RNXCC(QFN48_1DRILL(PADPITCH-0.5MM)); QFN48_1DRILL(PADPITCH-0.5MM)
USB1: USB_A_VERTICAL; USB_A_VERTICAL_PTH
USB-OTG1: MICRO_USB/MISB-SWMM-5AB_LF; USB-MICRO_MISB-SWMM-5B_LF
VR1: AMS1117; SOT223

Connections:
+3.3VD: C79.2, FET1.1 (G), R46.1, U1.M16 (HVCC); also elsewhere on the board
+3.3VWiFiIO: C91.2, C92.2, C110.2, R61.2, RM9.1.1, RM9.2.1, RM9.3.1, RM9.4.1, RM12.1.1, RM12.2.1, RM12.3.1, RM12.4.1, U1.T17 (VCC-PG), U11.22 (VDD_IO); also elsewhere on the board
+3V3: C73.2, C80.1, C89.2, C90.2, D5.2 (A), L21.2, LCD_CON1.3, R37.2, R70.2, R71.2, R99.1, U1.L16 (VCC-USB), U1.U16 (VCC-PD), U11.9 (VDD33); also elsewhere on the board
+5V: C71.1, C78.1, FUSE1.1, LCD_CON1.1, R47.1, R50.1, U6.5 (IN), U9.5 (IN); also elsewhere on the board
+5V_USBOTG: C67.1, L6.2, USB-OTG1.1 (VBUS); also elsewhere on the board
/USB&HDMI,WiFi&BT,Ethernet,LCD/1.25_EXT: C219.1, L23.2, L24.2, R120.1, VR1.2 (OUT)
/USB&HDMI,WiFi&BT,Ethernet,LCD/AP-WAKE-BT: U1.B20 (PL6/S-JTAG-DO/S_PL_EINT6), U11.6 (BT_WAKE)
/USB&HDMI,WiFi&BT,Ethernet,LCD/BT-PCM-CLK: U1.AB18 (PG11/AIF3-BCLK/PCM1-BCLK/PG_EINT11), U11.26 (PCM_CLK)
/USB&HDMI,WiFi&BT,Ethernet,LCD/BT-PCM-DIN: U1.AC19 (PG12/AIF3-DOUT/PCM1-DOUT/PG_EINT12), U11.27 (PCM_DIN)
/USB&HDMI,WiFi&BT,Ethernet,LCD/BT-PCM-DOUT: U1.U22 (PG13/AIF3-DIN/PCM1-DIN/PG_EINT13), U11.25 (PCM_DOUT)
/USB&HDMI,WiFi&BT,Ethernet,LCD/BT-PCM-SYNC: U1.AB19 (PG10/AIF3-SYNC/PCM1-SYNC/PG_EINT10), U11.28 (PCM_SYNC)
/USB&HDMI,WiFi&BT,Ethernet,LCD/BT-RST-N: RM12.1.2, U1.A20 (PL4/S-JTAG-MS/S_PL_EINT4), U11.34 (BT_DIS#)
/USB&HDMI,WiFi&BT,Ethernet,LCD/BT-UART-CTS: U1.AC17 (PG8/UART1-RTS/PG_EINT8), U11.44 (UART_CTS)
/USB&HDMI,WiFi&BT,Ethernet,LCD/BT-UART-RX: RM12.4.2, U1.AB17 (PG6/UART1-TX/PG_EINT6), U11.43 (UART_IN)
/USB&HDMI,WiFi&BT,Ethernet,LCD/BT-UART-TX: U1.U23 (PG7/UART1-RX/PG_EINT7), U11.42 (UART_OUT)
/USB&HDMI,WiFi&BT,Ethernet,LCD/BT-WAKE-AP: U1.D19 (PL5/S-JTAG-CK/S_PL_EINT5), U11.7 (BT_HOST_WAKE)
/USB&HDMI,WiFi&BT,Ethernet,LCD/EPHY-RST#: R117.2, U1.Y14 (PD24)
/USB&HDMI,WiFi&BT,Ethernet,LCD/GCLKIN/LCD_VSYNC: LCD_CON1.30, R109.1, U1.AC11 (PD21/LCD-VSYNC/LVDS-VN3/RGMII-CLKIN/RMI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)
/USB&HDMI,WiFi&BT,Ethernet,LCD/GMDC/LCD-PWM: LCD_CON1.36, U1.Y13 (PD22/PWM0/MDC), U15.36 (MDC)
/USB&HDMI,WiFi&BT,Ethernet,LCD/GMDIO/LCD_PWR: LCD_CON1.35, R108.1, U1.AC10 (PD23/MDIO), U15.37 (MDIO)
/USB&HDMI,WiFi&BT,Ethernet,LCD/GRXCK/LCD_D18: LCD_CON1.7, R100.1, U1.AC16 (PD12/LCD-D18/LVDS-VP0/RGMII-RXCK/RMII-N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)
/USB&HDMI,WiFi&BT,Ethernet,LCD/GRXCTL/LCD_D19: LCD_CON1.8, R105.1, U1.AB16 (PD13/LCD-D19/LVDS-VN0/RGMII-RXCTL/RMII-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)
/USB&HDMI,WiFi&BT,Ethernet,LCD/GRXD0/LCD_D15: LCD_CON1.20, RM15.1.2, U1.Y16 (PD11/LCD-D15/RGMII-RXD0/RMII-RXD0)
/USB&HDMI,WiFi&BT,Ethernet,LCD/GRXD1/LCD_D14: LCD_CON1.19, RM15.2.2, U1.W16 (PD10/LCD-D14/RGMII-RXD1/RMII-RXD1)
/USB&HDMI,WiFi&BT,Ethernet,LCD/GRXD2/LCD_D13: LCD_CON1.18, RM15.3.2, U1.AA13 (PD9/LCD-D13/RGMII-RXD2/RMII-NULL/CCIR-D5)
/USB&HDMI,WiFi&BT,Ethernet,LCD/GRXD3/LCD_D12: LCD_CON1.17, RM15.4.2, U1.V17 (PD8/LCD-D12/RGMII-RXD3/RMII-NULL/CCIR-D4)
/USB&HDMI,WiFi&BT,Ethernet,LCD/GTXCK/LCD_DE: LCD_CON1.32, U1.AB12 (PD19/LCD-DE/LVDS-VNC/RGMII-TXCK/RMII-TX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), U15.24 (GTX_CLK/RGMII_TXC)
/USB&HDMI,WiFi&BT,Ethernet,LCD/GTXCTL/LCD_HSYNC: LCD_CON1.29, U1.AB11 (PD20/LCD-HSYNC/LVDS-VP3/RGMII-TXCTL/RMI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), U15.25 (TX_EN/RGMII_TX_CTL)
/USB&HDMI,WiFi&BT,Ethernet,LCD/GTXD0/LCD_CLK: LCD_CON1.31, U1.AB13 (PD18/LCD-CLK/LVDS-VPC/RGMII-TXD0/RMII-T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), U15.19 (TXD[0]/RGMII_TD0)
/USB&HDMI,WiFi&BT,Ethernet,LCD/GTXD1/LCD_D23: LCD_CON1.12, U1.AC13 (PD17/LCD-D23/LVDS-VN2/RGMII-TXD1/RMII-T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), U15.20 (TXD[1]/RGMII_TD1)
/USB&HDMI,WiFi&BT,Ethernet,LCD/GTXD2/LCD_D22: LCD_CON1.11, U1.AC14 (PD16/LCD-D22/LVDS-VP2/RGMII-TXD2/RMII-N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), U15.21 (TXD[2]/RGMII_TD2)
/USB&HDMI,WiFi&BT,Ethernet,LCD/GTXD3/LCD_D21: LCD_CON1.10, U1.AB14 (PD15/LCD-D21/LVDS-VN1/RGMII-TXD3/RMII-N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), U15.22 (TXD[3]/RGMII_TD3)
/USB&HDMI,WiFi&BT,Ethernet,LCD/HCEC: FET1.2 (S), R46.2, U1.F21 (HCEC), U10.1 (IN1), U10.10 (OUT1)
/USB&HDMI,WiFi&BT,Ethernet,LCD/HHPD: R51.1, R52.1, U1.E21 (HHPD), U10.5 (IN4), U10.6 (OUT4)
/USB&HDMI,WiFi&BT,Ethernet,LCD/HSCL: HDMI1.15, R47.2, U1.G21 (HSCL), U10.2 (IN2), U10.9 (OUT2)
/USB&HDMI,WiFi&BT,Ethernet,LCD/HSDA: HDMI1.16, R50.2, U1.E20 (HSDA), U10.4 (IN3), U10.7 (OUT3)
/USB&HDMI,WiFi&BT,Ethernet,LCD/HTX0N: HDMI1.9, R44.1, U1.G23 (HTX0N), U8.2 (IN2), U8.9 (OUT2)
/USB&HDMI,WiFi&BT,Ethernet,LCD/HTX0P: HDMI1.7, R44.2, U1.G22 (HTX0P), U8.1 (IN1), U8.10 (OUT1)
/USB&HDMI,WiFi&BT,Ethernet,LCD/HTX1N: HDMI1.6, R43.2, U1.F22 (HTX1N), U7.5 (IN4), U7.6 (OUT4)
/USB&HDMI,WiFi&BT,Ethernet,LCD/HTX1P: HDMI1.4, R43.1, U1.E23 (HTX1P), U7.4 (IN3), U7.7 (OUT3)
/USB&HDMI,WiFi&BT,Ethernet,LCD/HTX2N: HDMI1.3, R39.1, U1.E22 (HTX2N), U7.2 (IN2), U7.9 (OUT2)
/USB&HDMI,WiFi&BT,Ethernet,LCD/HTX2P: HDMI1.1, R39.2, U1.D23 (HTX2P), U7.1 (IN1), U7.10 (OUT1)
/USB&HDMI,WiFi&BT,Ethernet,LCD/HTXCN: HDMI1.12, R45.2, U1.H23 (HTXCN), U8.5 (IN4), U8.6 (OUT4)
/USB&HDMI,WiFi&BT,Ethernet,LCD/HTXCP: HDMI1.10, R45.1, U1.H22 (HTXCP), U8.4 (IN3), U8.7 (OUT3)
/USB&HDMI,WiFi&BT,Ethernet,LCD/LCD_D2: LCD_CON1.23, U1.AA20 (PD0/LCD-D2/UART3-TX/SPI1-CS/CCIR-CLK)
/USB&HDMI,WiFi&BT,Ethernet,LCD/LCD_D3: LCD_CON1.24, U1.AA17 (PD1/LCD-D3/UART3-RX/SPI1-CLK/CCIR-DE)
/USB&HDMI,WiFi&BT,Ethernet,LCD/LCD_D4: LCD_CON1.25, U1.W19 (PD2/LCD-D4/UART4-TX/SPI1-MOSI/CCIR-HSYNC)
/USB&HDMI,WiFi&BT,Ethernet,LCD/LCD_D5: LCD_CON1.26, U1.AA14 (PD3/LCD-D5/UART4-RX/SPI1-MISO/CCIR-VSYNC)
/USB&HDMI,WiFi&BT,Ethernet,LCD/LCD_D6: LCD_CON1.27, U1.V18 (PD4/LCD-D6/UART4-RTS/CCIR-D0)
/USB&HDMI,WiFi&BT,Ethernet,LCD/LCD_D7: LCD_CON1.28, U1.AA15 (PD5/LCD-D7/UART4-CTS/CCIR-D1)
/USB&HDMI,WiFi&BT,Ethernet,LCD/LCD_D10: LCD_CON1.15, U1.Y11 (PD6/LCD-D10/CCIR-D2)
/USB&HDMI,WiFi&BT,Ethernet,LCD/LCD_D11: LCD_CON1.16, U1.AA16 (PD7/LCD-D11/CCIR-D3)
/USB&HDMI,WiFi&BT,Ethernet,LCD/LCD_D20: LCD_CON1.9, U1.AB15 (PD14/LCD-D20/LVDS-VP1/RGMII-NULL/RMII-R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)
/USB&HDMI,WiFi&BT,Ethernet,LCD/MDI[0]+: LAN1.1, U15.2 (TXRXP_A+)
/USB&HDMI,WiFi&BT,Ethernet,LCD/MDI[0]-: LAN1.2, U15.3 (TXRXM_A-)
/USB&HDMI,WiFi&BT,Ethernet,LCD/MDI[1]+: LAN1.3, U15.5 (TXRXP_B+)
/USB&HDMI,WiFi&BT,Ethernet,LCD/MDI[1]-: LAN1.4, U15.6 (TXRXM_B-)
/USB&HDMI,WiFi&BT,Ethernet,LCD/MDI[2]+: LAN1.7, U15.7 (TXRXP_C+)
/USB&HDMI,WiFi&BT,Ethernet,LCD/MDI[2]-: LAN1.8, U15.8 (TXRXM_C-)
/USB&HDMI,WiFi&BT,Ethernet,LCD/MDI[3]+: LAN1.9, U15.10 (TXRXP_D+)
/USB&HDMI,WiFi&BT,Ethernet,LCD/MDI[3]-: LAN1.10, U15.11 (TXRXM_D-)
/USB&HDMI,WiFi&BT,Ethernet,LCD/PH7/CTP-INT: LCD_CON1.37, U1.AC5 (PH7/UART3-CTS/PH_EINT7)
/USB&HDMI,WiFi&BT,Ethernet,LCD/PH8/CTP-RST: LCD_CON1.38, U1.Y10 (PH8/SPDIF-OUT/PH_EINT8)
/USB&HDMI,WiFi&BT,Ethernet,LCD/PHYAD0: LAN1.14, R112.1
/USB&HDMI,WiFi&BT,Ethernet,LCD/PHYAD1: LAN1.12, R113.1
/USB&HDMI,WiFi&BT,Ethernet,LCD/USB0-ID: R37.1, U1.AA8 (PH9/PH_EINT9), USB-OTG1.4 (ID)
/USB&HDMI,WiFi&BT,Ethernet,LCD/USB0-VBUSDET: C72.2, R38.1, R42.2, U1.AB4 (PH6/UART3-RTS/PH_EINT6)
/USB&HDMI,WiFi&BT,Ethernet,LCD/USB1-DM: U1.C22 (USB1-DM), USB1.2
/USB&HDMI,WiFi&BT,Ethernet,LCD/USB1-DP: U1.B23 (USB1-DP), USB1.3
/USB&HDMI,WiFi&BT,Ethernet,LCD/VDD33: C201.1, C202.1, C203.2, C216.2, C217.2, L21.1, LAN1.11, LAN1.13, R106.1, R108.2, R110.1, R111.1, R116.2, R119.2, RM8.1.2, RM8.2.2, RM8.3.2, RM8.4.2, U15.1 (AVDDH(3.3V/2.5V)), U15.12 (AVDDH(3.3V/2.5V)), U15.16 (DVDDH(3.3V/2.5V/1.8V)), U15.34 (DVDDH(3.3V/2.5V/1.8V)), U15.40 (DVDDH(3.3V/2.5V/1.8V))
/USB&HDMI,WiFi&BT,Ethernet,LCD/WL-PMU-EN: RM12.2.2, U1.A19 (PL2/S-UART-TX/S_PL_EINT2), U11.12 (WL_DSI#/GPIO9)
/USB&HDMI,WiFi&BT,Ethernet,LCD/WL-SDIO-CLK: R54.2, U1.V21 (PG0/SDC1-CLK/PG_EINT0)
/USB&HDMI,WiFi&BT,Ethernet,LCD/WL-SDIO-CMD: RM12.3.2, U1.U20 (PG1/SDC1-CMD/PG_EINT1), U11.16 (SD_CMD)
/USB&HDMI,WiFi&BT,Ethernet,LCD/WL-SDIO-D0: RM9.3.2, U1.U19 (PG2/SDC1-D0/PG_EINT2), U11.18 (SD_D0)
/USB&HDMI,WiFi&BT,Ethernet,LCD/WL-SDIO-D1: RM9.4.2, U1.V22 (PG3/SDC1-D1/PG_EINT3), U11.19 (SD_D1)
/USB&HDMI,WiFi&BT,Ethernet,LCD/WL-SDIO-D2: RM9.1.2, U1.Y21 (PG4/SDC1-D2/PG_EINT4), U11.14 (SD_D2)
/USB&HDMI,WiFi&BT,Ethernet,LCD/WL-SDIO-D3: RM9.2.2, U1.W23 (PG5/SDC1-D3/PG_EINT5), U11.15 (SD_D3)
/USB&HDMI,WiFi&BT,Ethernet,LCD/WL-WAKE-AP: U1.E19 (PL3/S-UART-RX/S_PL_EINT3), U11.13 (WL_HOST_WAKE)
AP-CK32KO: R60.2, R61.1; also elsewhere on the board
AP-RESET#: R118.2; also elsewhere on the board
GND: ANT1.2, C67.2, C68.1, C69.1, C70.1, C71.2, C72.1, C73.1, C74.2, C75.1, C76.1, C77.1, C78.2, C79.1, C80.2, C89.1, C90.1, C91.1, C92.1, C106.1, C107.1, C109.2, C110.1, C196.1, C198.2, C199.1, C200.1, C201.2, C202.2, C203.1, C204.1, C205.1, C206.1, C207.1, C208.1, C209.1, C210.1, C211.1, C212.1, C213.1, C214.1, C215.1, C216.1, C217.1, C218.2, C219.2, HDMI1.2, HDMI1.5, HDMI1.8, HDMI1.11, HDMI1.17, HDMI1.SH1 (20), HDMI1.SH2 (21), HDMI1.SH3 (22), HDMI1.SH4 (23), L7.1, L9.1, LCD_CON1.2, LCD_CON1.4, LCD_CON1.5, LCD_CON1.6, LCD_CON1.13, LCD_CON1.14, LCD_CON1.21, LCD_CON1.22, PHYRST1.1, R40.1, R41.1, R42.1, R48.1, R49.1, R52.2, R107.1, R114.1, R115.2, R120.2, U6.2 (GND), U7.3 (GND), U7.8 (GND), U8.3 (GND), U8.8 (GND), U9.2 (GND), U10.3 (GND), U10.8 (GND), U11.1 (GND), U11.20 (GND), U11.31 (GND), U11.33 (GND), U11.36 (GND), U11.41 (GND), U15.29 (VSS), U15.49 (EP/PADDLE/P_GND), USB1.4, USB-OTG1.5 (GND), VR1.1 (ADJ/GND); also elsewhere on the board
unnamed: ANT1.1, C107.2, R62.2
unnamed: C68.2, C69.2, C70.2, L6.1, R38.2, U6.1 (OUT)
unnamed: C74.1, L8.2, USB1.1
unnamed: C75.2, C76.2, C77.2, L8.1, U9.1 (OUT)
unnamed: C105.1, U11.2 (WIFI/BT_ANT)
unnamed: C105.2, C106.2, R62.1
unnamed: C196.2, LAN1.SH1, LAN1.SH2
unnamed: C198.1, R100.2, R107.2, U15.35 (RX_CLK/PHYAD2/RGMII_RXC)
unnamed: C199.2, LAN1.5
unnamed: C200.2, LAN1.6
unnamed: C204.2, C205.2, C206.2, C208.2, C209.2, C210.2, L24.1, U15.14 (DVDDL(1.2V)), U15.18 (DVDDL(1.2V)), U15.23 (DVDDL(1.2V)), U15.26 (DVDDL(1.2V)), U15.30 (DVDDL(1.2V)), U15.39 (DVDDL(1.2V))
unnamed: C207.2, C214.2, C215.2, L23.1, U15.4 (AVDDL(1.2V)), U15.9 (AVDDL(1.2V)), U15.44 (AVDDL_PLL(1.2V))
unnamed: C211.2, PHYRST1.2, R116.1, R117.1, R118.1, U15.42 (#RESET_N)
unnamed: C212.2, Q4.1, U15.46 (XI(CKXTAL1))
unnamed: C213.2, Q4.2, U15.45 (XO(CKXTAL2))
unnamed: C218.1, D5.1 (K), VR1.3 (IN)
unnamed: FET1.3 (D), HDMI1.13
unnamed: FUSE1.2, HDMI1.18
unnamed: HDMI1.19, R51.2
unnamed: L7.2, USB-OTG1.6
unnamed: L9.2, USB1.SH (5)
unnamed: R41.2, U6.3 (ISET)
unnamed: R49.2, U9.3 (ISET)
unnamed: R54.1, U11.17 (SD_CLK)
unnamed: R60.1, U11.24 (SUSCLK_IN/GPIO6)
unnamed: R105.2, R106.2, U15.33 (RX_DV/CLK125_EN/RGMII_RX_CTL)
unnamed: R109.2, R110.2, U15.41 (CLK125_NDO/LED_MODE)
unnamed: R111.2, R112.2, U15.17 (PHYAD0/LED1/PME_N1)
unnamed: R113.2, R114.2, U15.15 (PHYAD1/LED2)
unnamed: R115.1, U15.48 (ISET)
unnamed: R119.1, U15.38 (INT_N/PME_N2)
unnamed: RM8.1.1, RM15.1.1, U15.32 (RXD[0]/MODE0/RGMII_RD0)
unnamed: RM8.2.1, RM15.2.1, U15.31 (RXD[1]/MODE1/RGMII_RD1)
unnamed: RM8.3.1, RM15.3.1, U15.28 (RXD[2]/MODE2/RGMII_RD2)
unnamed: RM8.4.1, RM15.4.1, U15.27 (RXD[3]/MODE3/RGMII_RD3)
PH10: LCD_CON1.33, U1.Y8 (PH10/MIC-CLK/PH_EINT10)
PH11: LCD_CON1.34, U1.AA5 (PH11/MIC-DATA/PH_EINT11)
PL7: U1.C19 (PL7/S-JTAG-DI/S_PL_EINT7); also elsewhere on the board
PL8: U1.B21 (PL8/S-TWI-SCK/S_PL_EINT8); also elsewhere on the board
PL9: U1.D20 (PL9/S-TWI-SDA/S_PL_EINT9); also elsewhere on the board
PL10: U1.D21 (PL10/S-PWM/S_PL_EINT10); also elsewhere on the board
PL11: U1.C20 (PL11/S-CIR-RX/S_PL_EINT11); also elsewhere on the board
PL12: U1.D22 (PL12/S_PL_EINT12); also elsewhere on the board
PMU-SCK: U1.D17 (PL0/S-RSB-SCK/S-TWI-SCK/S_PL_EINT0); also elsewhere on the board
PMU-SDA: U1.C17 (PL1/S-RSB-SDA/S-TWI-SDA); also elsewhere on the board
TWI0-SCK: LCD_CON1.39, R70.1, U1.W11 (PH0/TWI0-SCK/PH_EINT0)
TWI0-SDA: LCD_CON1.40, R71.1, U1.AA10 (PH1/TWI0-SDA/PH_EINT1)
TWI1-SCK: U1.AC4 (PH2/TWI1-SCK/PH_EINT2); also elsewhere on the board
TWI1-SDA: U1.AA9 (PH3/TWI1-SDA/PH_EINT3); also elsewhere on the board
UART3-RX: U1.AC7 (PH5/UART3-RX/PH_EINT5); also elsewhere on the board
UART3-TX: U1.AB5 (PH4/UART3-TX/PH_EINT4); also elsewhere on the board
USB0-DM: U1.B22 (USB0-DM), USB-OTG1.2 (D-); also elsewhere on the board
USB0-DP: U1.A22 (USB0-DP), USB-OTG1.3 (D+); also elsewhere on the board
USB0-DRV: R40.2, U6.4 (EN); also elsewhere on the board
USB1-DRV: R48.2, R99.2, U1.U21 (PG9/UART1-CTS/PG_EINT9), U9.4 (EN)
VCC-PL: C109.1, U1.J16 (VCC-PL); also elsewhere on the board

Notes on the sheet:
HDMI
USB
To DLDO1
To DLDO4
To ALDO2
WiFi&BT
Gigabit Ethernet or LCD
Ilim(A)=6800/Rset(Ohm)
Rset
Ilim=1.7A
Ilim=0.5A

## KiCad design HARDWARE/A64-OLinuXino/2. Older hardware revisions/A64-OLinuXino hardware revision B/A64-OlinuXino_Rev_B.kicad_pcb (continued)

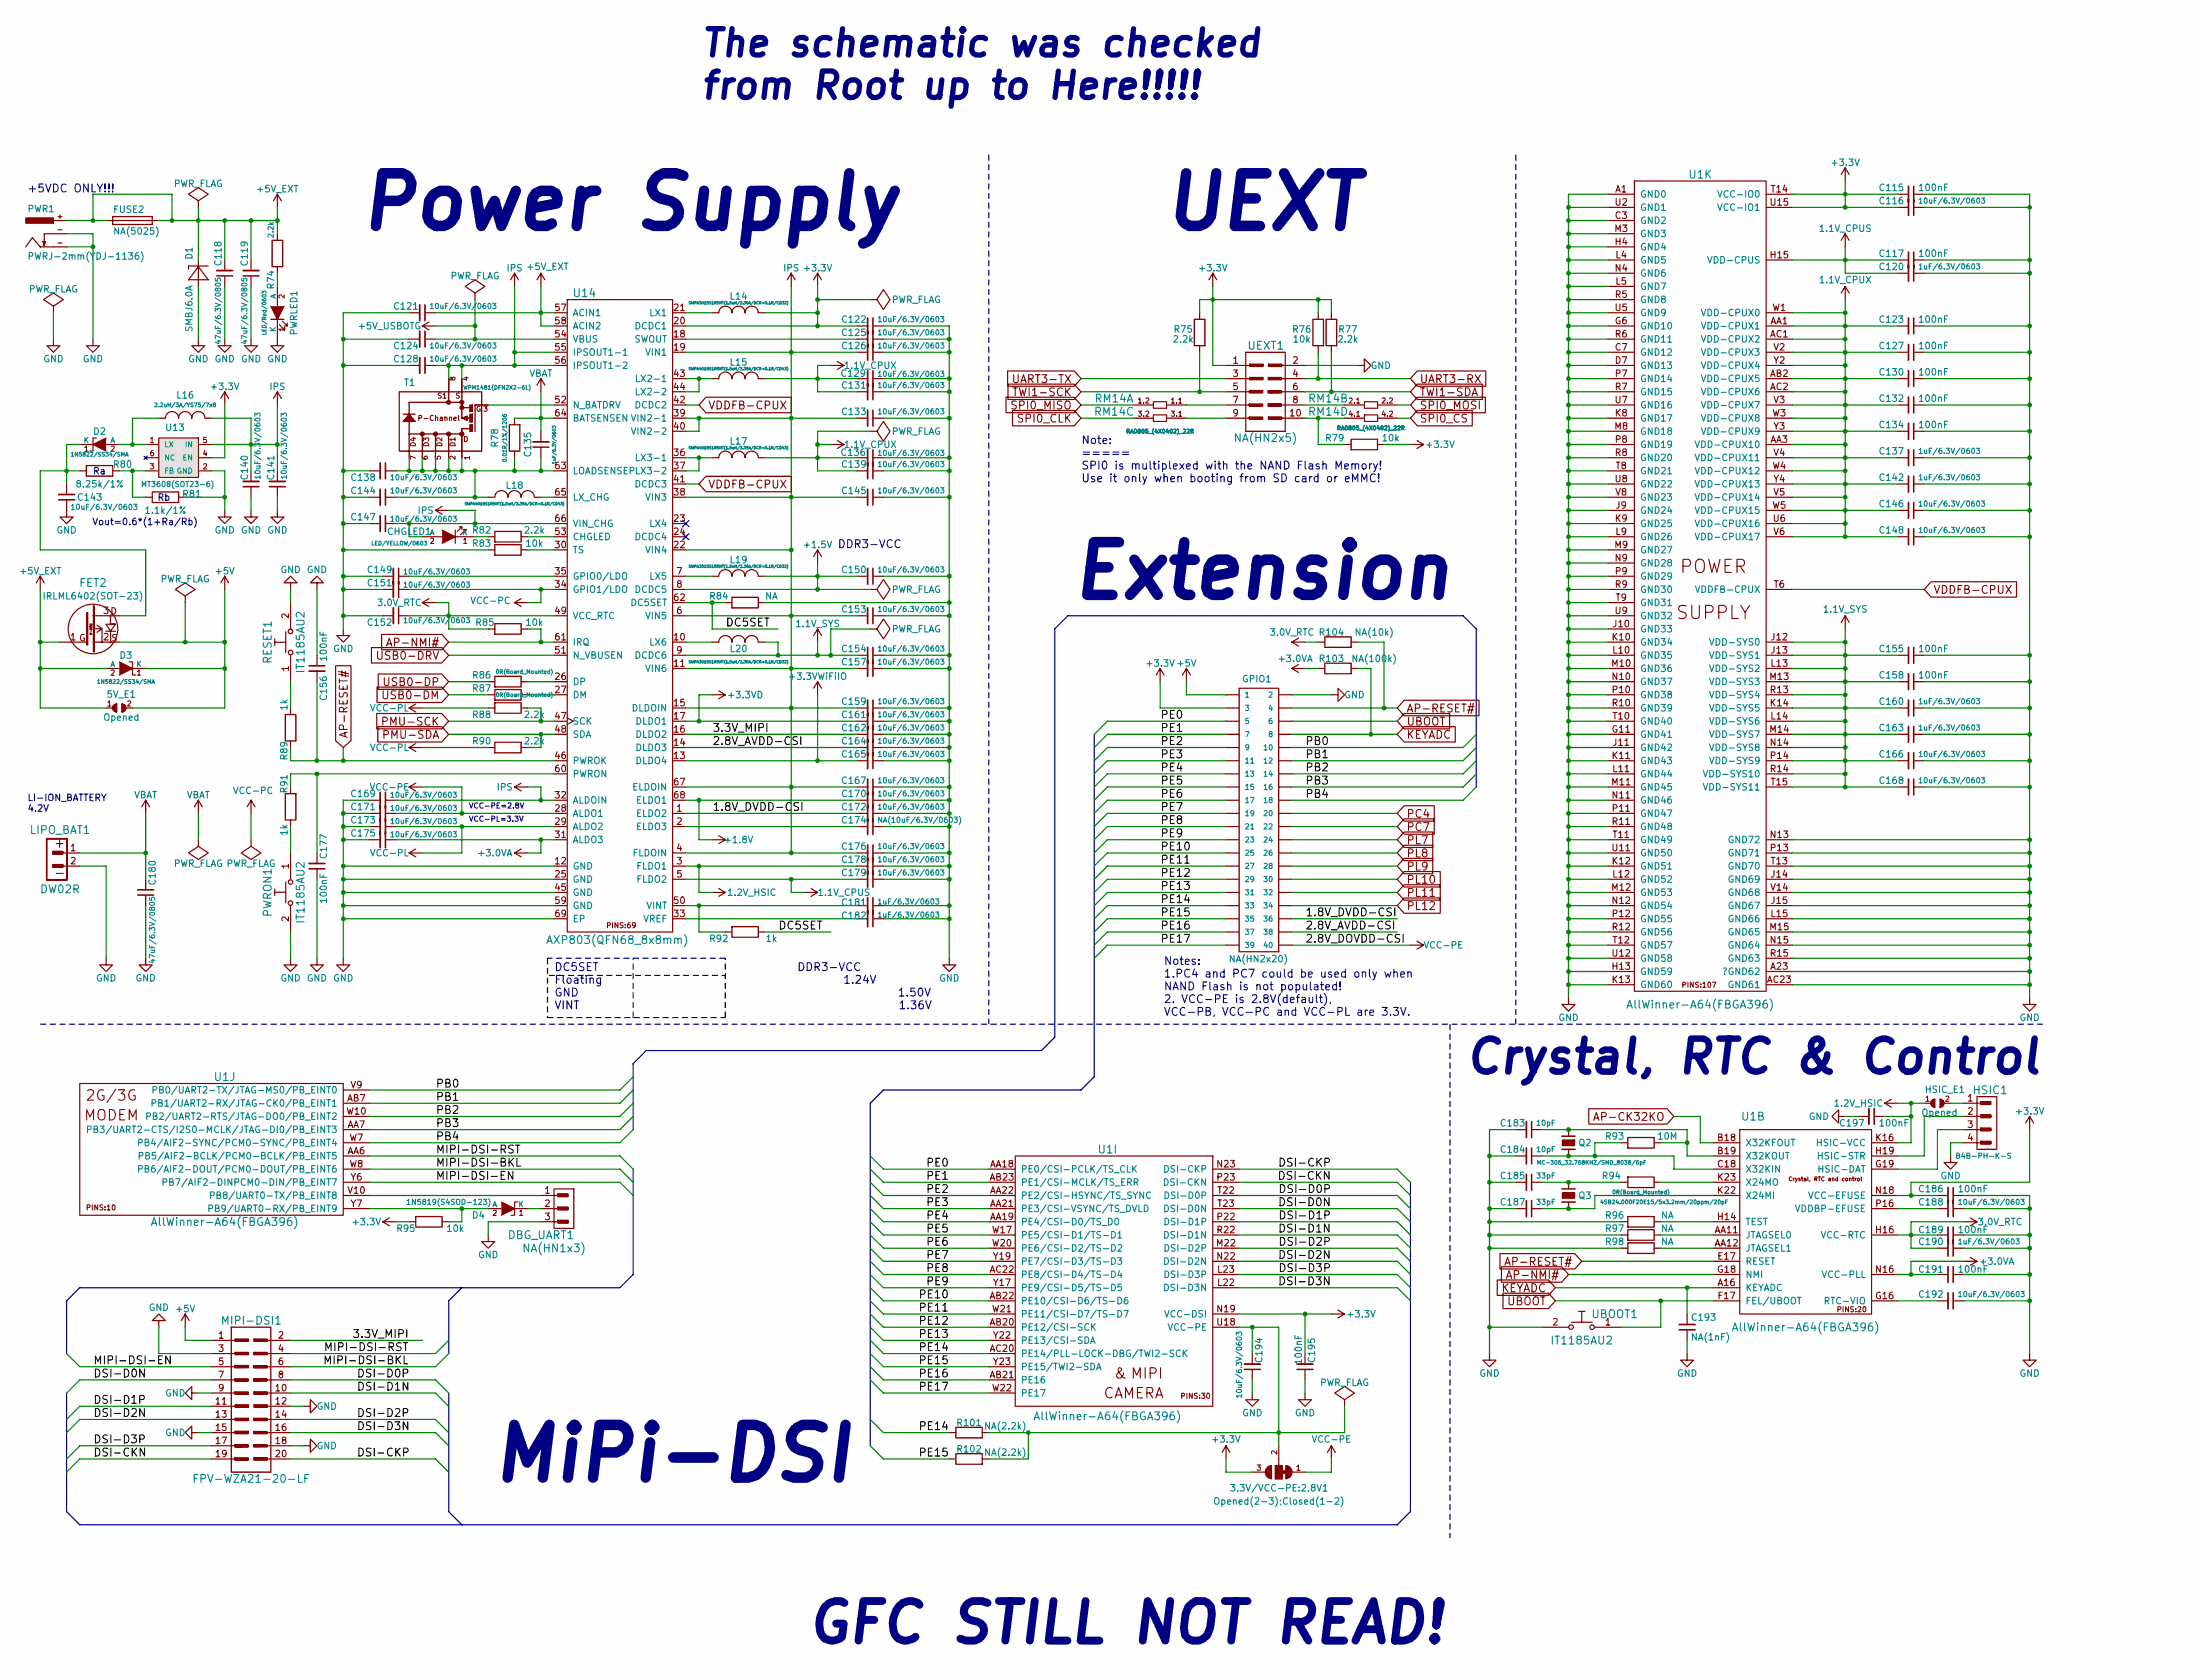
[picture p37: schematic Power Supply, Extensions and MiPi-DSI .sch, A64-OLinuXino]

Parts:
3.3V/VCC-PE:2.8V1: Opened(2-3);Closed(1-2); SJ_2_SMALL_12_TIED
5V_E1: Opened; SJ
C115, C117, C123, C127, C130, C132, C134, C155, C156, C158, C177, C186, C189, C191, C195, C197: 100nF; C_0402_5MIL_DWS
C116, C121, C122, C124, C125, C126, C128, C129, C131, C133, C136, C138, C139, C140, C141, C143, C144, C145, C146, C147, C148, C149, C150, C151, C152, C153, C154, C157, C159, C161, C162, C164, C165, C166, C167, C168, C169, C170, C171, C172, C173, C175, C176, C178, C179, C188, C192, C194: 10uF/6.3V/0603; C_0603_5MIL_DWS
C118, C119, C180: 47uF/6.3V/0805; C_0805_5MIL_DWS
C120, C135, C137, C142, C160, C163, C181, C182, C190: 1uF/6.3V/0603; C_0603_5MIL_DWS
C174: NA(10uF/6.3V/0603); C_0603_5MIL_DWS
C183, C184: 10pF; C_0402_5MIL_DWS
C185, C187: 33pF; C_0402_5MIL_DWS
C193: NA(1nF); C_0402_5MIL_DWS
CHGLED1: LED/YELLOW/0603; LED_0603_KA
D1: SMBJ6.0A; DO214AA
D2, D3: 1N5822/SS34/SMA; SMA-KA
D4: 1N5819(S4SOD-123); SOD-123_1C-2A_KA
DBG_UART1: NA(HN1x3); HN1x3
FET2: IRLML6402(SOT-23); SOT23
FUSE2: NA(5025); FUSE-5025
GPIO1: NA(HN2x20); HN2x20
HSIC1: B4B-PH-K-S
HSIC_E1: Opened; SJ
L14, L19, L20: SWPA3015S1R5NT(1.5uH/2.30A/DCR<0.1R/CD32); CD32
L15, L17, L18: SWPA4018S1R5NT(1.5uH/3.35A/DCR<0.1R/CD43); CD42(43)
L16: 2.2uH/3A/YS75/7x8; YS75_7X8MM
LIPO_BAT1: DW02R; LIPO_BAT-CON2DW02R
MIPI-DSI1: FPV-WZA21-20-LF
PWR1: PWRJ-2mm(YDJ-1136); PWR_JACK_UNI_MILLING
PWRLED1: LED/Red/0603; LED_0603_KA
PWRON1: IT1185AU2; uTACTIL
Q2: MC-306_32.768KHZ/SMD_8038/6pF; MC306-HS
Q3: 4SB24.000F20E15/5x3.2mm/20ppm/20pF; Q5x3.25
R74, R75, R77, R82, R88, R90: 2.2k; R_0402_5MIL_DWS
R76, R79, R83, R85, R95: 10k; R_0402_5MIL_DWS
R78: 0.01R/1%/1206; R_1206_5MIL_DWS
R80: 8.25k/1%; R_0402_5MIL_DWS
R81: 1.1k/1%; R_0402_5MIL_DWS
R84, R96, R97, R98: NA; R_0402_5MIL_DWS
R86, R87, R94: 0R(Board_Mounted); R_0402_5MIL_0R(Board_Mounted)
R89, R91, R92: 1k; R_0402_5MIL_DWS
R93: 10M; R_0402_5MIL_DWS
R101, R102: NA(2.2k); R_0402_5MIL_DWS
R103: NA(100k); R_0402_5MIL_DWS
R104: NA(10k); R_0402_5MIL_DWS
RESET1: IT1185AU2; uTACTIL
RM14: RA0805_(4X0402)_22R; RA0805_(4X0402)_xx
T1: WPM1481(DFN2X2-6L); DFN2x2-6L
U1: AllWinner-A64(FBGA396); FBGA396
U13: MT3608(SOT23-6); SOT23-6
U14: AXP803(QFN68_8x8mm); QFN68
UBOOT1: IT1185AU2; uTACTIL
UEXT1: NA(HN2x5); HN2x5

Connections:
1.1V_CPUS: C117.2, C120.2, C179.2, U1.H15 (VDD-CPUS), U14.5 (FLDO2)
1.1V_CPUX: C123.2, C127.2, C129.2, C130.2, C131.2, C132.2, C134.2, C136.2, C137.2, C139.2, C142.2, C146.2, C148.2, L15.2, L17.2, U1.AA1 (VDD-CPUX1), U1.AA3 (VDD-CPUX10), U1.AB2 (VDD-CPUX5), U1.AC1 (VDD-CPUX2), U1.AC2 (VDD-CPUX6), U1.U6 (VDD-CPUX16), U1.V2 (VDD-CPUX3), U1.V3 (VDD-CPUX7), U1.V4 (VDD-CPUX11), U1.V5 (VDD-CPUX14), U1.V6 (VDD-CPUX17), U1.W1 (VDD-CPUX0), U1.W3 (VDD-CPUX8), U1.W4 (VDD-CPUX12), U1.W5 (VDD-CPUX15), U1.Y2 (VDD-CPUX4), U1.Y3 (VDD-CPUX9), U1.Y4 (VDD-CPUX13)
1.1V_SYS: C154.2, C155.2, C158.2, C160.2, C163.2, C166.2, C168.2, L20.2, U1.J12 (VDD-SYS0), U1.J13 (VDD-SYS1), U1.K14 (VDD-SYS5), U1.L13 (VDD-SYS2), U1.L14 (VDD-SYS6), U1.M13 (VDD-SYS3), U1.M14 (VDD-SYS7), U1.N14 (VDD-SYS8), U1.P14 (VDD-SYS9), U1.R13 (VDD-SYS4), U1.R14 (VDD-SYS10), U1.T15 (VDD-SYS11), U14.9 (DCDC6)
1.2V_HSIC: C178.2, C197.1, HSIC_E1.1, U1.K16 (HSIC-VCC), U14.3 (FLDO1)
3.0V_RTC: C152.1, C189.2, C190.2, R85.2, R104.1, U1.H16 (VCC-RTC), U14.49 (VCC_RTC)
+1.5V: C150.2, L19.2, U14.8 (DCDC5); also elsewhere on the board
+1V8: C170.2, U14.68 (ELDO1); also elsewhere on the board
+3.0VA: C175.1, C191.2, R103.1, U1.N16 (VCC-PLL), U14.31 (ALDO3); also elsewhere on the board
+3.3VD: C161.2, U14.17 (DLDO1); also elsewhere on the board
+3.3VWiFiIO: C165.2, U14.13 (DLDO4); also elsewhere on the board
+3V3: 3.3V/VCC-PE:2.8V1.3, C115.2, C116.2, C122.2, C186.2, C195.2, GPIO1.3, L14.2, R75.1, R76.1, R77.1, R79.1, R95.2, U1.N18 (VCC-EFUSE), U1.N19 (VCC-DSI), U1.T14 (VCC-IO0), U1.U15 (VCC-IO1), U13.4 (EN), U14.20 (DCDC1), UEXT1.1; also elsewhere on the board
+5V: 5V_E1.2, D3.1 (K), FET2.2, GPIO1.1, MIPI-DSI1.1; also elsewhere on the board
+5V_EXT: 5V_E1.1, C118.2, C119.2, C121.1, D1.C, D3.2 (A), FET2.1, FUSE2.1, FUSE2.2, PWR1.+, R74.1, U14.57 (ACIN1), U14.58 (ACIN2)
+5V_USBOTG: C124.1, U14.54 (VBUS); also elsewhere on the board
/Power Supply, Extensions and MiPi-DSI/1.8V_DVDD-CSI: C172.2, GPIO1.36, U14.1 (ELDO2)
/Power Supply, Extensions and MiPi-DSI/2.8V_AVDD-CSI: C164.2, GPIO1.38, U14.14 (DLDO3)
/Power Supply, Extensions and MiPi-DSI/3.3V_MIPI: C162.2, MIPI-DSI1.2, U14.16 (DLDO2)
/Power Supply, Extensions and MiPi-DSI/DC5SET: R84.2, R92.1, U14.62 (DC5SET)
/Power Supply, Extensions and MiPi-DSI/DSI-CKN: MIPI-DSI1.19, U1.P23 (DSI-CKN)
/Power Supply, Extensions and MiPi-DSI/DSI-CKP: MIPI-DSI1.20, U1.N23 (DSI-CKP)
/Power Supply, Extensions and MiPi-DSI/DSI-D0N: MIPI-DSI1.7, U1.T23 (DSI-D0N)
/Power Supply, Extensions and MiPi-DSI/DSI-D0P: MIPI-DSI1.8, U1.T22 (DSI-D0P)
/Power Supply, Extensions and MiPi-DSI/DSI-D1N: MIPI-DSI1.10, U1.R22 (DSI-D1N)
/Power Supply, Extensions and MiPi-DSI/DSI-D1P: MIPI-DSI1.11, U1.P22 (DSI-D1P)
/Power Supply, Extensions and MiPi-DSI/DSI-D2N: MIPI-DSI1.13, U1.N22 (DSI-D2N)
/Power Supply, Extensions and MiPi-DSI/DSI-D2P: MIPI-DSI1.14, U1.M22 (DSI-D2P)
/Power Supply, Extensions and MiPi-DSI/DSI-D3N: MIPI-DSI1.16, U1.L22 (DSI-D3N)
/Power Supply, Extensions and MiPi-DSI/DSI-D3P: MIPI-DSI1.17, U1.L23 (DSI-D3P)
/Power Supply, Extensions and MiPi-DSI/MIPI-DSI-BKL: MIPI-DSI1.6, U1.W8 (PB6/AIF2-DOUT/PCM0-DOUT/PB_EINT6)
/Power Supply, Extensions and MiPi-DSI/MIPI-DSI-EN: MIPI-DSI1.5, U1.Y6 (PB7/AIF2-DINPCM0-DIN/PB_EINT7)
/Power Supply, Extensions and MiPi-DSI/MIPI-DSI-RST: MIPI-DSI1.4, U1.AA6 (PB5/AIF2-BCLK/PCM0-BCLK/PB_EINT5)
/Power Supply, Extensions and MiPi-DSI/PB0: GPIO1.10, U1.V9 (PB0/UART2-TX/JTAG-MS0/PB_EINT0)
/Power Supply, Extensions and MiPi-DSI/PB1: GPIO1.12, U1.AB7 (PB1/UART2-RX/JTAG-CK0/PB_EINT1)
/Power Supply, Extensions and MiPi-DSI/PB2: GPIO1.14, U1.W10 (PB2/UART2-RTS/JTAG-DO0/PB_EINT2)
/Power Supply, Extensions and MiPi-DSI/PB3: GPIO1.16, U1.AA7 (PB3/UART2-CTS/I2S0-MCLK/JTAG-DI0/PB_EIN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)
/Power Supply, Extensions and MiPi-DSI/PB4: GPIO1.18, U1.W7 (PB4/AIF2-SYNC/PCM0-SYNC/PB_EINT4)
/Power Supply, Extensions and MiPi-DSI/PE0: GPIO1.5, U1.AA18 (PE0/CSI-PCLK/TS_CLK)
/Power Supply, Extensions and MiPi-DSI/PE1: GPIO1.7, U1.AB23 (PE1/CSI-MCLK/TS_ERR)
/Power Supply, Extensions and MiPi-DSI/PE2: GPIO1.9, U1.AA22 (PE2/CSI-HSYNC/TS_SYNC)
/Power Supply, Extensions and MiPi-DSI/PE3: GPIO1.11, U1.AA21 (PE3/CSI-VSYNC/TS_DVLD)
/Power Supply, Extensions and MiPi-DSI/PE4: GPIO1.13, U1.AA19 (PE4/CSI-D0/TS_D0)
/Power Supply, Extensions and MiPi-DSI/PE5: GPIO1.15, U1.W17 (PE5/CSI-D1/TS-D1)
/Power Supply, Extensions and MiPi-DSI/PE6: GPIO1.17, U1.W20 (PE6/CSI-D2/TS-D2)
/Power Supply, Extensions and MiPi-DSI/PE7: GPIO1.19, U1.Y19 (PE7/CSI-D3/TS-D3)
/Power Supply, Extensions and MiPi-DSI/PE8: GPIO1.21, U1.AC22 (PE8/CSI-D4/TS-D4)
/Power Supply, Extensions and MiPi-DSI/PE9: GPIO1.23, U1.Y17 (PE9/CSI-D5/TS-D5)
/Power Supply, Extensions and MiPi-DSI/PE10: GPIO1.25, U1.AB22 (PE10/CSI-D6/TS-D6)
/Power Supply, Extensions and MiPi-DSI/PE11: GPIO1.27, U1.W21 (PE11/CSI-D7/TS-D7)
/Power Supply, Extensions and MiPi-DSI/PE12: GPIO1.29, U1.AB20 (PE12/CSI-SCK)
/Power Supply, Extensions and MiPi-DSI/PE13: GPIO1.31, U1.Y22 (PE13/CSI-SDA)
/Power Supply, Extensions and MiPi-DSI/PE14: GPIO1.33, R101.1, U1.AC20 (PE14/PLL-LOCK-DBG/TWI2-SCK)
/Power Supply, Extensions and MiPi-DSI/PE15: GPIO1.35, R102.1, U1.Y23 (PE15/TWI2-SDA)
/Power Supply, Extensions and MiPi-DSI/PE16: GPIO1.37, U1.AB21 (PE16)
/Power Supply, Extensions and MiPi-DSI/PE17: GPIO1.39, U1.W22 (PE17)
AP-CK32KO: U1.B18 (X32KFOUT); also elsewhere on the board
AP-NMI#: R85.1, U1.G18 (NMI), U14.61 (IRQ)
AP-RESET#: C156.2, GPIO1.4, R89.2, R104.2, U1.E17 (RESET), U14.46 (PWROK); also elsewhere on the board
GND: C115.1, C116.1, C117.1, C118.1, C119.1, C120.1, C121.2, C122.1, C123.1, C124.2, C125.1, C126.1, C127.1, C128.2, C129.1, C130.1, C131.1, C132.1, C133.1, C134.1, C136.1, C137.1, C138.2, C139.1, C140.1, C141.1, C142.1, C143.1, C144.2, C145.1, C146.1, C147.2, C148.1, C149.2, C150.1, C151.2, C152.2, C153.1, C154.1, C155.1, C156.1, C157.1, C158.1, C159.1, C160.1, C161.1, C162.1, C163.1, C164.1, C165.1, C166.1, C167.1, C168.1, C169.2, C170.1, C171.2, C172.1, C173.2, C174.1, C175.2, C176.1, C177.1, C178.1, C179.1, C180.1, C181.1, C182.1, C183.2, C184.2, C185.2, C186.1, C187.2, C188.1, C189.1, C190.1, C191.1, C192.1, C193.1, C194.1, C195.1, C197.2, D1.A, DBG_UART1.3, GPIO1.2, HSIC1.4, LIPO_BAT1.2, MIPI-DSI1.3, MIPI-DSI1.9, MIPI-DSI1.12, MIPI-DSI1.15, MIPI-DSI1.18, PWR1.-, PWRLED1.1 (K), PWRON1.2, R81.2, R83.2, R84.1, R96.2, R97.2, R98.2, RESET1.2, U1.A1 (GND0), U1.A23 (?GND62), U1.AC23 (GND61), U1.C3 (GND2), U1.C7 (GND12), U1.D7 (GND13), U1.G6 (GND10), U1.G11 (GND41), U1.H4 (GND4), U1.H13 (GND59), U1.J9 (GND24), U1.J10 (GND33), U1.J11 (GND42), U1.J14 (GND69), U1.J15 (GND67), U1.K8 (GND17), U1.K9 (GND25), U1.K10 (GND34), U1.K11 (GND43), U1.K12 (GND51), U1.K13 (GND60), U1.L4 (GND5), U1.L5 (GND7), U1.L9 (GND26), U1.L10 (GND35), U1.L11 (GND44), U1.L12 (GND52), U1.L15 (GND66), U1.M3 (GND3), U1.M8 (GND18), U1.M9 (GND27), U1.M10 (GND36), U1.M11 (GND45), U1.M12 (GND53), U1.M15 (GND65), U1.N4 (GND6), U1.N9 (GND28), U1.N10 (GND37), U1.N11 (GND46), U1.N12 (GND54), U1.N13 (GND72), U1.N15 (GND64), U1.P7 (GND14), U1.P8 (GND19), U1.P9 (GND29), U1.P10 (GND38), U1.P11 (GND47), U1.P12 (GND55), U1.P13 (GND71), U1.R5 (GND8), U1.R6 (GND11), U1.R7 (GND15), U1.R8 (GND20), U1.R9 (GND30), U1.R10 (GND39), U1.R11 (GND48), U1.R12 (GND56), U1.R15 (GND63), U1.T8 (GND21), U1.T9 (GND31), U1.T10 (GND40), U1.T11 (GND49), U1.T12 (GND57), U1.T13 (GND70), U1.U2 (GND1), U1.U5 (GND9), U1.U7 (GND16), U1.U8 (GND22), U1.U9 (GND32), U1.U11 (GND50), U1.U12 (GND58), U1.V8 (GND23), U1.V14 (GND68), U13.2 (GND), U14.12 (GND), U14.25 (GND), U14.45 (GND), U14.59 (GND), U14.69 (EP), UBOOT1.2, UEXT1.2; also elsewhere on the board
IPS: C126.2, C128.1, C133.2, C140.2, C141.2, C145.2, C147.1, C153.2, C157.2, C159.2, C167.2, C169.1, C176.2, CHGLED1.2 (A), L16.1, T1.4 (S), T1.8 (S1), U13.5 (IN), U14.4 (FLDOIN), U14.6 (VIN5), U14.11 (VIN6), U14.15 (DLDOIN), U14.19 (VIN1), U14.22 (VIN4), U14.32 (ALDOIN), U14.38 (VIN3), U14.39 (VIN2-1), U14.40 (VIN2-2), U14.55 (IPSOUT1-1), U14.56 (IPSOUT1-2), U14.66 (VIN_CHG), U14.67 (ELDOIN)
KEYADC: C193.2, GPIO1.8, R103.2, U1.A16 (KEYADC)
unnamed: 3.3V/VCC-PE:2.8V1.2, C194.2, R101.2, R102.2, U1.U18 (VCC-PE)
unnamed: C125.2, U14.18 (SWOUT)
unnamed: C135.1, C138.1, C144.1, L18.1, R78.1, T1.1 (D), T1.2 (D1), T1.5 (D2), T1.6 (D3), T1.7 (D4), U14.63 (LOADSENSEP)
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

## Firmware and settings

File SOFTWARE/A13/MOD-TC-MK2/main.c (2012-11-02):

/*
 * main.c
 * 
 * Copyright 2012 OLIMEX-LTD
 * 
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
 * 
 */


#include <stdio.h>
#include <linux/i2c.h>
#include <linux/i2c-dev.h>
#include <fcntl.h>
#include <stdlib.h>
#include <unistd.h>
#include <sys/ioctl.h>
#include <string.h>
#include "i2c.h"

int main(int argc, char **argv)
{
	
	/*Check for number of parameters. Should be at least 2*/
	if(argc < 2)
	{
		printf("Invalid number of parameters\n");
		exit(1);
	}
	else
	{
		/*HELP COMMAND: --help*/
		if(!strcmp(argv[1], "--help"))
		{
			     printf ("\
Usage: %s [OPTION]... ADDRESS [COMMAND]\
",	      argv[0]);

 
      fputs ("\
  -d, --tris                   set the TRIS registers\n\
  -l, --lat                    set the LAT registers\n\
", stdout);

      fputs ("\
  -p, --port                   get the PORT registers\n\
  -u, --pullup                 turn PULL-UPs\n\
", stdout);

      fputs ("\
  -an0, --analog0                get value of AN0\n\
  -an1, --analog1                get value of AN1\n\
  -an2, --analog2                get value of AN2\n\
  -an6, --analog6                get value of AN6\n\
  -an7, --analog7                get value of AN7\n\
  -a, --analog                   get value of all analog inputs\n\
", stdout);

      fputs ("\
  -t, --temperature             get readings from thermocouple\n\
  -n, --address					set new address\n\
", stdout);
  
 
      fputs (("\
\n\
GPIO3 is always input. Also pull-ups can be turned on only on PORTA.\
To set a new address put jumper and reset the board. \n\
\n\
"), stdout);

      printf (("\nReport bugs to <%s>.\n"), "OLIMEX");
      exit (1);

		}
		
		/*HELP COMMAND: -temp 0xA0*/
		else if(!strcmp(argv[1], "--temperature") || !strcmp(argv[1], "-t"))
		{
			/*Check parameters*/
			if(argc != 3)
			{
				printf("Invalid number of parameters\n");
				exit(1);
			}
			else
			{
				int fd;		//File descriptor
				int address;
				int i;
				unsigned char in_buffer[5];
				unsigned char out_buffer[10];
				
				unsigned long int open_circuit_mask = 0x00000001;
				unsigned long int gnd_short_mask 	= 0x00000002;
				unsigned long int vcc_short_mask 	= 0x00000004;
				unsigned long int fault_mask 		= 0x00010000;
				unsigned long int sign_int_mask		= 0x00008000;
				unsigned long int sign_ext_mask		= 0x80000000;
				unsigned long int temperature		= 0;
				unsigned long int foobar			= 0;
				
				float external = 0;
				float internal = 0;
				
				
				address = strtol(argv[2], NULL, 0);
				
				
				
				in_buffer[0] = 0x01;	//MOD-TC-MK2 Identificator
				in_buffer[1] = address;
				in_buffer[2] = 0x21;	//GET_TEMP COMMAND
				
				
				/*Opening I2C-BUS*/
				I2C_Open(&fd, 0x48);
				/*SEND DATA*/
				I2C_Send(&fd, in_buffer, 3);				
				sleep(1);
				/*READ DATA*/				
				I2C_Read(&fd, out_buffer, 4);
				/*Close I2C-BUS*/
				I2C_Close(&fd);
				
				/*HANDLE DATA*/
				for(i = 0; i < 4; i++)
				{
					
					temperature |= out_buffer[3-i];
					if(i!=3)
						temperature <<= 8;
				} 				
				
				
				/*CHECK FAULT*/
				if(fault_mask & temperature)
				{
					if(open_circuit_mask & temperature)
					{
						fputs("Fault: open circuit!\n",stdout);
						exit(1);
					}
					if(gnd_short_mask & temperature)
					{
						fputs("Fault: GND short!\n",stdout);
						exit(1);
					}
					if(vcc_short_mask & temperature)
					{
						fputs("Fault: VCC short!\n",stdout);
						exit(1);						
					}					
				}
				else
				{
					
					/*PROCESS INTERNAL TEMPERATURE*/
					foobar = temperature;
					foobar &= 0x0000FFFF;
					foobar >>= 4;
					
					internal = (foobar & 0x00F) * 0.0625 + ((foobar >> 4) & 0x7F);
					
					/*CHECK SIGN*/
					if(sign_int_mask & temperature)
					{
						/*NEGATIVE TEMPERATURE*/
						printf("INTERNAL TEMPERATURE: %.4f C\n",  -128+internal);
					}
					else
					{
						/*POSITIVE TEMPERATURE*/
				
						printf("INTERNAL TEMPERATURE: %c%.4f C\n", '+', internal);
					}
					
					
					/*PROCESS EXTERNAL TEMPERATURE*/
					foobar = temperature;
					foobar >>= 16;
					foobar >>= 2;
					
					external = (foobar & 0x0003) * 0.25 + ((foobar >> 2) & 0x7FF);
					
					if(sign_ext_mask & temperature)
					{
						/*NEGATIVE TEMPERATURE*/
						printf("EXTERNAL TEMPERATURE: %.2f C\n",  -2048+external);
					}
					else
					{
						/*POSITIVE TEMPERATURE*/
				
						printf("EXTERNAL TEMPERATURE: %c%.2f C\n", '+', external);
					}
					
				}
				
			}			
		}
		/*SET_TRIS COMMAND: -tris 0xA0 <data>*/
		else if(!strcmp(argv[1], "--tris") || !strcmp(argv[1], "-d"))
		{
			/*Check parameters*/
			if(argc != 4)
			{
				printf("Invalid number of parameters\n");
				exit(1);
			}
			else
			{
				int fd;
				unsigned char in_buffer[4];
				unsigned char temp_buffer[7];
				int address;
				int tris;
				int i;
				
				address	 =	 strtol(argv[2], NULL, 0);
				tris	 =	 strtol(argv[3], NULL, 0);
				
				
				in_buffer[0] = 0x01;	//MOD-TC-MK2 Identificator
				in_buffer[1] = address;
				in_buffer[2] = 0x01;	//SET_TRIS COMMAND
				in_buffer[3] = tris;
				
				
				
				/*Opening I2C-BUS*/
				I2C_Open(&fd, 0x48);
				/*SEND DATA*/
				I2C_Send(&fd, in_buffer, 4);				
				/*Close I2C-BUS*/
				I2C_Close(&fd);
				
				for(i = 0; i < 7; i++)
				{
					if(i == 3)
						continue;
					if(tris & (1 << i))
						temp_buffer[i] = 'I';
					else
						temp_buffer[i] = 'O';
				}
				
				printf("\n");
				printf("-------+---+---+---+---+---+---+----\n");
				printf("| GPIO | 6 | 5 | 4 | 3 | 2 | 1 | 0 |\n");
				printf("-------+---+---+---+---+---+---+----\n");
				printf("| TRIS | %c | %c | %c | %c | %c | %c | %c |\n",
					temp_buffer[6], temp_buffer[5], temp_buffer[4], 
					'I', temp_buffer[2], temp_buffer[1], 
					temp_buffer[0]);
				printf("-------+---+---+---+---+---+---+----\n");
				
			}
			
		}
		/*SET_LAT COMMAND: -lat 0xA0 <data>*/
		else if(!strcmp(argv[1], "-l") || !strcmp(argv[1], "--lat"))
		{
			/*Check parameters*/
			if(argc != 4)
			{
				printf("Invalid number of parameters\n");
				exit(1);
			}
			else
			{
				int fd;
				unsigned char in_buffer[4];
				unsigned char temp_buffer[7];
				int address;
				int lat;
				int i;
				
				address	 =	 strtol(argv[2], NULL, 0);
				lat	 =	 strtol(argv[3], NULL, 0);
				
				
				in_buffer[0] = 0x01;	//MOD-TC-MK2 Identificator
				in_buffer[1] = address;
				in_buffer[2] = 0x02;	//SET_LAT COMMAND
				in_buffer[3] = lat;
				
				
				
				/*Opening I2C-BUS*/
				I2C_Open(&fd, 0x48);
				/*SEND DATA*/
				I2C_Send(&fd, in_buffer, 4);				
				/*Close I2C-BUS*/
				I2C_Close(&fd);
				
				for(i = 0; i < 7; i++)
				{
					if(lat & (1 << i))
						temp_buffer[i] = 'H';
					else
						temp_buffer[i] = 'L';
				}
				
				printf("\n");
				printf("-------+---+---+---+---+---+---+----\n");
				printf("| GPIO | 6 | 5 | 4 | 3 | 2 | 1 | 0 |\n");
				printf("-------+---+---+---+---+---+---+----\n");
				printf("| LAT  | %c | %c | %c | %c | %c | %c | %c |\n",
					temp_buffer[6], temp_buffer[5], temp_buffer[4], 
					temp_buffer[3], temp_buffer[2], temp_buffer[1], 
					temp_buffer[0]);
				printf("-------+---+---+---+---+---+---+----\n");
				
			}
			
		}
		/*GET_PORT COMMAND: -port 0xA0 <data>*/
		else if(!strcmp(argv[1], "-p") || !strcmp(argv[1], "--port"))
		{
			/*Check parameters*/
			if(argc != 3)
			{
				printf("Invalid number of parameters\n");
				exit(1);
			}
			else
			{
				int fd;
				unsigned char in_buffer[3];
				unsigned char out_buffer[2];
				unsigned char temp_buffer[7];
				int address;
				int i;
				
				address	 =	 strtol(argv[2], NULL, 0);
				
				
				in_buffer[0] = 0x01;	//MOD-TC-MK2 Identificator
				in_buffer[1] = address;
				in_buffer[2] = 0x03;	//GET_PORT COMMAND
				
				
				
				/*Opening I2C-BUS*/
				I2C_Open(&fd, 0x48);
				/*SEND DATA*/
				I2C_Send(&fd, in_buffer, 3);
				/*READ DATA*/				
				I2C_Read(&fd, out_buffer, 1);				
				/*Close I2C-BUS*/
				I2C_Close(&fd);
				
				
				for(i = 0; i < 7; i++)
				{
					if(out_buffer[0] & (1 << i))
						temp_buffer[i] = 'H';
					else
						temp_buffer[i] = 'L';
				}
				
				printf("\n");
				printf("-------+---+---+---+---+---+---+----\n");
				printf("| GPIO | 6 | 5 | 4 | 3 | 2 | 1 | 0 |\n");
				printf("-------+---+---+---+---+---+---+----\n");
				printf("| PORT | %c | %c | %c | %c | %c | %c | %c |\n",
					temp_buffer[6], temp_buffer[5], temp_buffer[4], 
					temp_buffer[3], temp_buffer[2], temp_buffer[1], 
					temp_buffer[0]);
				printf("-------+---+---+---+---+---+---+----\n");
				
				
			}
			
		}
		/*SET_PU -pullup 0xA0 <data>*/
		else if(!strcmp(argv[1], "--pullup") || !strcmp(argv[1], "-u"))
		{
			/*Check parameters*/
			if(argc != 4)
			{
				printf("Invalid number of parameters\n");
				exit(1);
			}
			else
			{
				int fd;
				unsigned char in_buffer[4];
				unsigned char temp_buffer[7];
				int address;
				int pu;
				int i;
				
				address	 =	 strtol(argv[2], NULL, 0);
				pu	 =	 strtol(argv[3], NULL, 0);
				
				
				in_buffer[0] = 0x01;	//MOD-TC-MK2 Identificator
				in_buffer[1] = address;
				in_buffer[2] = 0x04;	//SET_PU COMMAND
				in_buffer[3] = pu;
				
				
				
				/*Opening I2C-BUS*/
				I2C_Open(&fd, 0x48);
				/*SEND DATA*/
				I2C_Send(&fd, in_buffer, 4);				
				/*Close I2C-BUS*/
				I2C_Close(&fd);
				
				for(i = 0; i < 5; i++)
				{
					if(pu & (1 << i))
						temp_buffer[i] = 'Y';
					else
						temp_buffer[i] = 'N';
				}
				
				printf("\n");
				printf("-------+---+---+---+---+---+---+----\n");
				printf("| GPIO | 6 | 5 | 4 | 3 | 2 | 1 | 0 |\n");
				printf("-------+---+---+---+---+---+---+----\n");
				printf("|  PU  | %c | %c | %c | %c | %c | %c | %c |\n",
					'-', '-',  temp_buffer[4], temp_buffer[3],
					 temp_buffer[2], temp_buffer[1], temp_buffer[0]);
				printf("-------+---+---+---+---+---+---+----\n");
				
			}
			
		}
		
		/*GET_AN0 -an0 0xA0 <data>*/
		else if(!strcmp(argv[1], "-an0") || !strcmp(argv[1], "--analog0"))
		{
			/*Check parameters*/
			if(argc != 3)
			{
				printf("Invalid number of parameters\n");
				exit(1);
			}
			else
			{
				int fd;
				unsigned char in_buffer[3];
				unsigned char out_buffer[2];
				unsigned char temp_buffer[40];
				int i;
				int address;
				int an0;
				float vcc;
				float t = 0;
				
				
				address	 =	 strtol(argv[2], NULL, 0);
				
				
				in_buffer[0] = 0x01;	//MOD-TC-MK2 Identificator
				in_buffer[1] = address;
				in_buffer[2] = 0x10;	//SET_PU COMMAND
				
				
				
				/*Opening I2C-BUS*/
				I2C_Open(&fd, 0x48);
				/*SEND DATA*/
				I2C_Send(&fd, in_buffer, 3);	
				/*READ DATA*/
				I2C_Read(&fd, out_buffer, 2);			
				/*Close I2C-BUS*/
				I2C_Close(&fd);
				
				an0 = out_buffer[0];
				an0 |= out_buffer[1]<<8;
				
				vcc = (an0/1023.0)*3.3;
				
				for(i = 0; i < 40; i++)
				{
					t = i*0.0825;
					if(vcc > t)
						temp_buffer[i] = '=';
					else
						temp_buffer[i] = '.';
					
				}
				
				temp_buffer[40] = 0;
				
				printf("\nAN0:[%s]%.3fV\n", temp_buffer, vcc);			
				
				
				
				
				
			}
			
		}
		/*GET_AN1 -an1 0xA0 <data>*/
		else if(!strcmp(argv[1], "-an1") || !strcmp(argv[1], "--analog1"))
		{
			/*Check parameters*/
			if(argc != 3)
			{
				printf("Invalid number of parameters\n");
				exit(1);
			}
			else
			{
				int fd;
				unsigned char in_buffer[3];
				unsigned char out_buffer[2];
				unsigned char temp_buffer[40];
				int i;
				int address;
				int an1;
				float vcc;
				float t = 0;
				
				
				address	 =	 strtol(argv[2], NULL, 0);
				
				
				in_buffer[0] = 0x01;	//MOD-TC-MK2 Identificator
				in_buffer[1] = address;
				in_buffer[2] = 0x11;	//SET_PU COMMAND
				
				
				
				/*Opening I2C-BUS*/
				I2C_Open(&fd, 0x48);
				/*SEND DATA*/
				I2C_Send(&fd, in_buffer, 3);	
				/*READ DATA*/
				I2C_Read(&fd, out_buffer, 2);			
				/*Close I2C-BUS*/
				I2C_Close(&fd);
				
				an1 = out_buffer[0];
				an1 |= out_buffer[1]<<8;
				
				vcc = (an1/1023.0)*3.3;
				
				for(i = 0; i < 40; i++)
				{
					t = i*0.0825;
					if(vcc > t)
						temp_buffer[i] = '=';
					else
						temp_buffer[i] = '.';
					
				}
				
				temp_buffer[40] = 0;
				
				printf("\nAN1:[%s]%.3fV\n", temp_buffer, vcc);			
				
				
				
				
				
			}
			
		}
		/*GET_AN2 -an2 0xA0 <data>*/
		else if(!strcmp(argv[1], "-an2") || !strcmp(argv[1], "--analog2"))
		{
			/*Check parameters*/
			if(argc != 3)
			{
				printf("Invalid number of parameters\n");
				exit(1);
			}
			else
			{
				int fd;
				unsigned char in_buffer[3];
				unsigned char out_buffer[2];
				unsigned char temp_buffer[40];
				int i;
				int address;
				int an2;
				float vcc;
				float t = 0;
				
				
				address	 =	 strtol(argv[2], NULL, 0);
				
				
				in_buffer[0] = 0x01;	//MOD-TC-MK2 Identificator
				in_buffer[1] = address;
				in_buffer[2] = 0x12;	//SET_PU COMMAND
				
				
				
				/*Opening I2C-BUS*/
				I2C_Open(&fd, 0x48);
				/*SEND DATA*/
				I2C_Send(&fd, in_buffer, 3);	
				/*READ DATA*/
				I2C_Read(&fd, out_buffer, 2);			
				/*Close I2C-BUS*/
				I2C_Close(&fd);
				
				an2 = out_buffer[0];
				an2 |= out_buffer[1]<<8;
				
				vcc = (an2/1023.0)*3.3;
				
				for(i = 0; i < 40; i++)
				{
					t = i*0.0825;
					if(vcc > t)
						temp_buffer[i] = '=';
					else
						temp_buffer[i] = '.';
					
				}
				
				temp_buffer[40] = 0;
				
				printf("\nAN2:[%s]%.3fV\n", temp_buffer, vcc);			
				
				
				
				
				
			}
			
		}
		/*GET_AN6 -an6 0xA0 <data>*/
		else if(!strcmp(argv[1], "-an6") || !strcmp(argv[1], "--analog6"))
		{
			/*Check parameters*/
			if(argc != 3)
			{
				printf("Invalid number of parameters\n");
				exit(1);
			}
			else
			{
				int fd;
				unsigned char in_buffer[3];
				unsigned char out_buffer[2];
				unsigned char temp_buffer[40];
				int i;
				int address;
				int an6;
				float vcc;
				float t = 0;
				
				
				address	 =	 strtol(argv[2], NULL, 0);
				
				
				in_buffer[0] = 0x01;	//MOD-TC-MK2 Identificator
				in_buffer[1] = address;
				in_buffer[2] = 0x16;	//SET_PU COMMAND
				
				
				
				/*Opening I2C-BUS*/
				I2C_Open(&fd, 0x48);
				/*SEND DATA*/
				I2C_Send(&fd, in_buffer, 3);	
				/*READ DATA*/
				I2C_Read(&fd, out_buffer, 2);			
				/*Close I2C-BUS*/
				I2C_Close(&fd);
				
				an6 = out_buffer[0];
				an6 |= out_buffer[1]<<8;
				
				vcc = (an6/1023.0)*3.3;
				
				for(i = 0; i < 40; i++)
				{
					t = i*0.0825;
					if(vcc > t)
						temp_buffer[i] = '=';
					else
						temp_buffer[i] = '.';
					
				}
				
				temp_buffer[40] = 0;
				
				printf("\nAN6:[%s]%.3fV\n", temp_buffer, vcc);			
				
				
				
				
				
			}
			
		}
		/*GET_AN7 -an7 0xA0 <data>*/
		else if(!strcmp(argv[1], "-an7") || !strcmp(argv[1], "--analog7"))
		{
			/*Check parameters*/
			if(argc != 3)
			{
				printf("Invalid number of parameters\n");
				exit(1);
			}
			else
			{
				int fd;
				unsigned char in_buffer[3];
				unsigned char out_buffer[2];
				unsigned char temp_buffer[40];
				int i;
				int address;
				int an7;
				float vcc;
				float t = 0;
				
				
				
				
				address	 =	 strtol(argv[2], NULL, 0);
				
				
				in_buffer[0] = 0x01;	//MOD-TC-MK2 Identificator
				in_buffer[1] = address;
				in_buffer[2] = 0x17;	//SET_PU COMMAND
				
				
				
				/*Opening I2C-BUS*/
				I2C_Open(&fd, 0x48);
				/*SEND DATA*/
				I2C_Send(&fd, in_buffer, 3);	
				/*READ DATA*/
				I2C_Read(&fd, out_buffer, 2);			
				/*Close I2C-BUS*/
				I2C_Close(&fd);
				
				an7 = out_buffer[0];
				an7 |= out_buffer[1]<<8;
				
				vcc = (an7/1023.0)*3.3;
				
				for(i = 0; i < 40; i++)
				{
					t = i*0.0825;
					if(vcc > t)
						temp_buffer[i] = '=';
					else
						temp_buffer[i] = '.';
					
				}
				
				temp_buffer[40] = 0;
				
				printf("\nAN7:[%s]%.3fV\n", temp_buffer, vcc);			
				
				
				
				
				
			}
			
		}
		/*GET_AN -analog 0xA0 <data>*/
		else if(!strcmp(argv[1], "--analog") || !strcmp(argv[1], "-a"))
		{
			/*Check parameters*/
			if(argc != 3)
			{
				printf("Invalid number of parameters\n");
				exit(1);
			}
			else
			{
				int fd;
				unsigned char in_buffer[3];
				unsigned char out_buffer[2];
				unsigned char temp_buffer[40];
				int i;
				int address;
				int an0, an1, an2, an6, an7;
				float vcc;
				float t = 0;
				
					
				address	 =	 strtol(argv[2], NULL, 0);
				
				in_buffer[0] = 0x01;	//MOD-TC-MK2 Identificator
				in_buffer[1] = address;
				in_buffer[2] = 0x10;	//SET_PU COMMAND
				
				
				
				/*Opening I2C-BUS*/
				I2C_Open(&fd, 0x48);
				/*SEND DATA*/
				I2C_Send(&fd, in_buffer, 3);	
				/*READ DATA*/
				I2C_Read(&fd, out_buffer, 2);			
				/*Close I2C-BUS*/
				I2C_Close(&fd);
				
				an0 = out_buffer[0];
				an0 |= out_buffer[1]<<8;
				
				vcc = (an0/1023.0)*3.3;
				
				for(i = 0; i < 40; i++)
				{
					t = i*0.0825;
					if(vcc > t)
						temp_buffer[i] = '=';
					else
						temp_buffer[i] = '.';
					
				}
				
				temp_buffer[40] = 0;
				
				printf("\nAN0:[%s]%.3fV\n", temp_buffer, vcc);	
				
							in_buffer[0] = 0x01;	//MOD-TC-MK2 Identificator
				in_buffer[1] = address;
				in_buffer[2] = 0x11;	//SET_PU COMMAND
				
				
				
				/*Opening I2C-BUS*/
				I2C_Open(&fd, 0x48);
				/*SEND DATA*/
				I2C_Send(&fd, in_buffer, 3);	
				/*READ DATA*/
				I2C_Read(&fd, out_buffer, 2);			
				/*Close I2C-BUS*/
				I2C_Close(&fd);
				
				an1 = out_buffer[0];
				an1 |= out_buffer[1]<<8;
				
				vcc = (an1/1023.0)*3.3;
				
				for(i = 0; i < 40; i++)
				{
					t = i*0.0825;
					if(vcc > t)
						temp_buffer[i] = '=';
					else
						temp_buffer[i] = '.';
					
				}
				
				temp_buffer[40] = 0;
				
				printf("AN1:[%s]%.3fV\n", temp_buffer, vcc);	
				
				
				in_buffer[0] = 0x01;	//MOD-TC-MK2 Identificator
				in_buffer[1] = address;
				in_buffer[2] = 0x12;	//SET_PU COMMAND
				
				
				
				/*Opening I2C-BUS*/
				I2C_Open(&fd, 0x48);
				/*SEND DATA*/
				I2C_Send(&fd, in_buffer, 3);	
				/*READ DATA*/
				I2C_Read(&fd, out_buffer, 2);			
				/*Close I2C-BUS*/
				I2C_Close(&fd);
				
				an2 = out_buffer[0];
				an2 |= out_buffer[1]<<8;
				
				vcc = (an2/1023.0)*3.3;
				
				for(i = 0; i < 40; i++)
				{
					t = i*0.0825;
					if(vcc > t)
						temp_buffer[i] = '=';
					else
						temp_buffer[i] = '.';
					
				}
				
				temp_buffer[40] = 0;
				
				printf("AN2:[%s]%.3fV\n", temp_buffer, vcc);	
				
				
				
				in_buffer[0] = 0x01;	//MOD-TC-MK2 Identificator
				in_buffer[1] = address;
				in_buffer[2] = 0x16;	//SET_PU COMMAND
				
				
				
				/*Opening I2C-BUS*/
				I2C_Open(&fd, 0x48);
				/*SEND DATA*/
				I2C_Send(&fd, in_buffer, 3);	
				/*READ DATA*/
				I2C_Read(&fd, out_buffer, 2);			
				/*Close I2C-BUS*/
				I2C_Close(&fd);
				
				an6 = out_buffer[0];
				an6 |= out_buffer[1]<<8;
				
				vcc = (an6/1023.0)*3.3;
				
				for(i = 0; i < 40; i++)
				{
					t = i*0.0825;
					if(vcc > t)
						temp_buffer[i] = '=';
					else
						temp_buffer[i] = '.';
					
				}
				
				temp_buffer[40] = 0;
				
				printf("AN6:[%s]%.3fV\n", temp_buffer, vcc);		
				
			
				
				
				in_buffer[0] = 0x01;	//MOD-TC-MK2 Identificator
				in_buffer[1] = address;
				in_buffer[2] = 0x17;	//SET_PU COMMAND
				
				
				
				/*Opening I2C-BUS*/
				I2C_Open(&fd, 0x48);
				/*SEND DATA*/
				I2C_Send(&fd, in_buffer, 3);	
				/*READ DATA*/
				I2C_Read(&fd, out_buffer, 2);			
				/*Close I2C-BUS*/
				I2C_Close(&fd);
				
				an7 = out_buffer[0];
				an7 |= out_buffer[1]<<8;
				
				vcc = (an7/1023.0)*3.3;
				
				for(i = 0; i < 40; i++)
				{
					t = i*0.0825;
					if(vcc > t)
						temp_buffer[i] = '=';
					else
						temp_buffer[i] = '.';
					
				}
				
				temp_buffer[40] = 0;
				
				printf("AN7:[%s]%.3fV\n", temp_buffer, vcc);				
				
				
			}
						
		}
		else if(!strcmp(argv[1], "-address"))
		{
			/*Check parameters*/
			if(argc != 3)
			{
				printf("Invalid number of parameters\n");
				exit(1);
			}
			else
			{
				int fd;
				unsigned char address;
				unsigned char in_buffer[5];
				
				address = strtol(argv[2], NULL, 0);
				
				in_buffer[0] = 0x01;
				in_buffer[1] = 0xF0;
				in_buffer[2] = 0xB0;
				in_buffer[3] = address;
				
				/*Opening I2C-BUS*/
				I2C_Open(&fd, 0x48);
				/*SEND DATA*/
				I2C_Send(&fd, in_buffer, 4);			
				/*Close I2C-BUS*/
				I2C_Close(&fd);
				
				printf("\nNEW ADDRESS: 0x%02X\n", address);				
				
												
			}
		}
		else
		{
			fputs("Unknown parameter. Type --help for more info\n", stdout);
			exit(0); 
		}
		
	}
	
	return 0;
}

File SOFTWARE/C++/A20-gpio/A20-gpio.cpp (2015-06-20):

/*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
 *   You should have received a copy of the GNU General Public License
 *   along with this program.  If not, see <http://www.gnu.org/licenses/>.
 *************************************************************************
 * Author: Federico Reghenzani <federico[DOT]dev[AT]reghe[DOT]net>
 */

#include "A20-gpio.hpp"
extern "C" {
    #include "gpio_lib.h"
}

#include <unistd.h>
namespace A20 {
    // Initialize the static list of objects in GPIO class
    std::vector<GPIO_common*> GPIO::registered;

    /* ************************************************************* */
    /* ********************** GPIO Class *************************** */
    /* ************************************************************* */
    void GPIO::init() throw(GPIO_exception) {
        if(sunxi_gpio_init() < 0) {
            throw new GPIO_exception("unable to init sunxi");
        }
    }
    
    GPIO_input* GPIO::get_input(uint16_t port, pull_resistor_t pull_resistor) throw(GPIO_exception) {
        
        // First of all, search for already registered pin
        for(std::vector<GPIO_common*>::iterator it = registered.begin(); it != registered.end(); ++it) {

            if ( (*it)->get_port() == port ) {
                if ( (*it)->get_type() == 0) {
                    // Ok, already registered has input
                    return (GPIO_input*)(*it);
                } else {
                    // Oh no, already registered as other type!
                    throw new GPIO_exception("trying to read a port setted as output or periphery!");
                }
            }
        }
        
        // Ok, we didn't found the pin, let's export them
        GPIO_input* new_input = new GPIO_input(port, pull_resistor);
        registered.push_back(new_input);
        return new_input;
    }
    
    GPIO_output* GPIO::get_output(uint16_t port) throw(GPIO_exception) {
        
        // First of all, search for already registered pin
        for(std::vector<GPIO_common*>::iterator it = registered.begin(); it != registered.end(); ++it) {

            if ( (*it)->get_port() == port ) {
                if ( (*it)->get_type() == 1) {
                    // Ok, already registered has output
                    return (GPIO_output*)(*it);
                } else {
                    // Oh no, already registered as other type!
                    throw new GPIO_exception("trying to set a port as output but it's already setted as input or periphery!");
                }
            }
        }
        
        // Ok, we didn't found the pin, let's export them
        GPIO_output* new_output = new GPIO_output(port);
        registered.push_back(new_output);
        return new_output;
    }
    
    void GPIO::set_periphery_mode(uint16_t port) throw(GPIO_exception) {
        // First of all, search for already registered pin
        for(std::vector<GPIO_common*>::iterator it = registered.begin(); it != registered.end(); ++it) {

            if ( (*it)->get_port() == port ) {
                if ( (*it)->get_type() == 2) {
                    // Ok, already registered has per
                    return;
                } else {
                    // Oh no, already registered as other type!
                    throw new GPIO_exception("trying to set a port as periphery but it's already setted as input or output!");
                }
            }
        }
        
        // Ok, we didn't found the pin, let's export them
        GPIO_periphery* new_per = new GPIO_periphery(port);
        registered.push_back(new_per);
    }
    
    void GPIO::free(uint16_t port) throw(GPIO_exception) {
        for(std::vector<GPIO_common*>::iterator it = registered.begin(); it != registered.end(); ++it) {
            if ( (*it)->get_port() == port ) {
                delete *it;                // Unexport the pin
                registered.erase(it);    // Remove from exported vector
                return;                    // Ok return
            }
        }
        // I cannot find the pin in registered pins.
        throw new GPIO_exception("unable to free a non previously requested gpio");
    }

    /* ************************************************************* */
    /* ******************* GPIO_input class ************************ */
    /* ************************************************************* */
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

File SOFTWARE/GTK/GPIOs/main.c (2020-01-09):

#include "gpio_lib.h"
#include <gtk/gtk.h>

struct _s_EXT_GPIO
{
	char EXT_Num, EXT_Pin, GPIO_Port, GPIO_Pin;
};
typedef	struct _s_EXT_GPIO EXT_GPIO;
EXT_GPIO GPIO_Data [] =
{
	// Ext 1
	{1,  1, 'N', -1},
	{1,  2, 'N', -1},
	{1,  3, 'N', -1},
	{1,  4, 'N', -1},
	{1,  5, 'G',  0},
	{1,  6, 'N', -1},
	{1,  7, 'G',  1},
	{1,  8, 'N', -1},
	{1,  9, 'G',  2},
	{1, 10, 'N', -1},
	{1, 11, 'G',  3},
	{1, 12, 'N', -1},
	{1, 13, 'G',  4},
	{1, 14, 'N', -1},
	{1, 15, 'G',  5},
	{1, 16, 'N', -1},
	{1, 17, 'G',  6},
	{1, 18, 'N', -1},
	{1, 19, 'G',  7},
	{1, 20, 'N', -1},
	{1, 21, 'G',  8},
	{1, 22, 'N', -1},
	{1, 23, 'G',  9},
	{1, 24, 'N', -1},
	{1, 25, 'G', 10},
	{1, 26, 'N', -1},
	{1, 27, 'G', 11},
	{1, 28, 'N', -1},
	{1, 29, 'N', -1},
	{1, 30, 'N', -1},
	{1, 31, 'N', -1},
	{1, 32, 'N', -1},
	{1, 33, 'N', -1},
	{1, 34, 'N', -1},
	{1, 35, 'N', -1},
	{1, 36, 'N', -1},
	{1, 37, 'N', -1},
	{1, 38, 'N', -1},
	{1, 39, 'N', -1},
	{1, 40, 'N', -1},

	// Ext 2
	{2,  1, 'N', -1},
	{2,  2, 'N', -1},
	{2,  3, 'N', -1},
	{2,  4, 'N', -1},
	{2,  5, 'B',  0},	// TWI0-SCK
	{2,  6, 'E',  0},
	{2,  7, 'B',  1},	// TWI0-SDA
	{2,  8, 'E',  1},
	{2,  9, 'I',  0},
	{2, 10, 'E',  2},
	{2, 11, 'I',  1},
	{2, 12, 'E',  3},
	{2, 13, 'I',  2},
	{2, 14, 'E',  4},
	{2, 15, 'I',  3},
	{2, 16, 'E',  5},
	{2, 17, 'I', 10},
	{2, 18, 'E',  6},
	{2, 19, 'I', 11},
	{2, 20, 'E',  7},
	{2, 21, 'C',  3},
	{2, 22, 'E',  8},
	{2, 23, 'C',  7},
	{2, 24, 'E',  9},
	{2, 25, 'C', 16},	// BWP/SDC2_RST
	{2, 26, 'E', 10},
	{2, 27, 'C', 17},
	{2, 28, 'E', 11},
	{2, 29, 'C', 18},
	{2, 30, 'I', 14},
	{2, 31, 'C', 23},
	{2, 32, 'I', 15},
	{2, 33, 'C', 24},
	{2, 34, 'B', 23},	// RX0
	{2, 35, 'N', -1},
	{2, 36, 'B', 22},	// TX0
	{2, 37, 'N', -1},
	{2, 38, 'N', -1},
	{2, 39, 'N', -1},
	{2, 40, 'N', -1},

	// Ext 3
	{3,  1, 'N', -1},
	{3,  2, 'N', -1},
	{3,  3, 'N', -1},
	{3,  4, 'N', -1},
	{3,  5, 'H',  0},
	{3,  6, 'B',  3},
	{3,  7, 'H',  2},
	{3,  8, 'B',  4},
	{3,  9, 'H',  7},
	{3, 10, 'B',  5},
	{3, 11, 'H',  9},
	{3, 12, 'B',  6},
	{3, 13, 'H', 10},
	{3, 14, 'B',  7},
	{3, 15, 'H', 11},
	{3, 16, 'B',  8},
	{3, 17, 'H', 12},
	{3, 18, 'B', 10},
	{3, 19, 'H', 13},
	{3, 20, 'B', 11},
	{3, 21, 'H', 14},
	{3, 22, 'B', 12},
	{3, 23, 'H', 15},
	{3, 24, 'B', 13},
	{3, 25, 'H', 16},
	{3, 26, 'B', 14},
	{3, 27, 'H', 17},
	{3, 28, 'B', 15},
	{3, 29, 'H', 18},
	{3, 30, 'B', 16},
	{3, 31, 'H', 19},
	{3, 32, 'B', 17},
	{3, 33, 'H', 20},
	{3, 34, 'H', 24},
	{3, 35, 'H', 21},
	{3, 36, 'H', 25},
	{3, 37, 'H', 22},
	{3, 38, 'H', 26},
	{3, 39, 'H', 23},
	{3, 40, 'H', 27},

	// UExt 1
	{4,  1, 'N', -1},
	{4,  2, 'N', -1},
	{4,  3, 'I', 12},
	{4,  4, 'I', 13},
	{4,  5, 'B', 20},
	{4,  6, 'B', 21},
	{4,  7, 'C', 22},
	{4,  8, 'C', 21},
	{4,  9, 'C', 20},
	{4, 10, 'C', 19},

	// UExt 2
	{5,  1, 'N', -1},
	{5,  2, 'N', -1},
	{5,  3, 'I', 20},
	{5,  4, 'I', 21},
	{5,  5, 'B', 18},
	{5,  6, 'B', 19},
	{5,  7, 'I', 19},
	{5,  8, 'I', 18},
	{5,  9, 'I', 17},
	{5, 10, 'I', 16}
};

int Pin_Number (int Port, int Pin)
{
	if ((Port >= 65) && (Port <= 90))	// if Port is a letter 'A'-'Z'
		Port = Port - 65;
	if ((Port >= 97) && (Port <= 122))	// if Port is a letter 'a'-'z'
		Port = Port - 97;
	return (Port<<5) | Pin;	// Port*32 + Pin
}

GtkWidget *Combo_Port, *Combo_Pin;
int Global_Port=-1, Global_Pin=-1;

int Check_Valid_Pin ()
{
	if (Global_Port < 0) 
	{
		printf ("Select Port\n");
		return 0;
	}
	if (Global_Pin < 0) 
	{
		printf ("Select Pin\n");
		return 0;
	}
	return 1;
}

void Handler_end_program (GtkWidget *wid, gpointer ptr)
{
	gtk_main_quit ();
}

void Handler_Pin_Config_Input (GtkWidget *wid, gpointer ptr)
{
	if (Check_Valid_Pin ())
		sunxi_gpio_set_cfgpin(Pin_Number (Global_Port, Global_Pin), SUNXI_GPIO_INPUT);
}

void Handler_Pin_Config_Output (GtkWidget *wid, gpointer ptr)
{
	if (Check_Valid_Pin ())
		sunxi_gpio_set_cfgpin(Pin_Number (Global_Port, Global_Pin), SUNXI_GPIO_OUTPUT);
}

void Handler_Pin_Out (GtkWidget *wid, gpointer ptr)
{
	if (Check_Valid_Pin ())
		sunxi_gpio_output (Pin_Number(Global_Port, Global_Pin), gtk_toggle_button_get_active (GTK_TOGGLE_BUTTON (wid)));
}

void Handler_Pin_In (GtkWidget *wid, gpointer ptr)
{
	if (Check_Valid_Pin ())
		gtk_toggle_button_set_active (GTK_TOGGLE_BUTTON (ptr), sunxi_gpio_input (Pin_Number(Global_Port, Global_Pin)));
}

void Handler_Toggle_Pin (GtkWidget *wid, gpointer ptr)
{
	if (Check_Valid_Pin ())
		sunxi_gpio_output (Pin_Number(Global_Port, Global_Pin), !sunxi_gpio_input(Pin_Number(Global_Port, Global_Pin)));
}

void Handler_Port_Selected (GtkWidget *wid, gpointer ptr)
{
	Global_Port = gtk_combo_box_get_active (GTK_COMBO_BOX (wid))-1;
}

void Handler_Pin_Selected (GtkWidget *wid, gpointer ptr)
{
	Global_Pin = gtk_combo_box_get_active (GTK_COMBO_BOX (wid))-1;
}

void Handler_GPIO_Array (GtkWidget *wid, gpointer ptr)
{
	//char EXT_Num, EXT_Pin, GPIO_Port, GPIO_Pin;
	EXT_GPIO Temp = *(EXT_GPIO*)ptr;
	printf ("GPIO-%d.%d, ", Temp.EXT_Num, Temp.EXT_Pin);
	if (Temp.GPIO_Port == 'N')
	{
		printf ("Not GPIO\n");
		gtk_combo_box_set_active (GTK_COMBO_BOX (Combo_Port), 0);
		gtk_combo_box_set_active (GTK_COMBO_BOX (Combo_Pin), 0);
	}
	else
	{
		printf ("P%c%d\n", Temp.GPIO_Port, Temp.GPIO_Pin);
		Global_Port=Temp.GPIO_Port;
		Global_Pin=Temp.GPIO_Pin;

		gtk_combo_box_set_active (GTK_COMBO_BOX (Combo_Port), Global_Port-'A'+1);
		gtk_combo_box_set_active (GTK_COMBO_BOX (Combo_Pin), Global_Pin+1);
	}
}

GtkWidget *CreateRadio (GtkWidget *tbl, int Row, int Column, GSList **group, char *szLabel)
{
    GtkWidget *radio;
    radio = gtk_radio_button_new_with_label (*group, szLabel);
    *group = gtk_radio_button_group (GTK_RADIO_BUTTON (radio));
	gtk_table_attach_defaults (GTK_TABLE (tbl), radio, Row, Row+1, Column, Column+1);
    gtk_widget_show (radio);
    return (radio);
}
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

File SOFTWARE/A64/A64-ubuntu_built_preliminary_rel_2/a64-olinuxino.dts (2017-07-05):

/dts-v1/;

/memreserve/	0x0000000045000000 0x0000000000200000;
/memreserve/	0x0000000041010000 0x0000000000010000;
/memreserve/	0x0000000041020000 0x0000000000000800;
/memreserve/	0x0000000040100000 0x0000000000004000;
/memreserve/	0x0000000040104000 0x0000000000001000;
/memreserve/	0x0000000040105000 0x0000000000001000;
/ {
	model = "sun50iw1p1";
	compatible = "arm,sun50iw1p1", "arm,sun50iw1p1";
	interrupt-parent = <0x1>;
	#address-cells = <0x2>;
	#size-cells = <0x2>;

	clocks {
		compatible = "allwinner,sunxi-clk-init";
		device_type = "clocks";
		#address-cells = <0x2>;
		#size-cells = <0x2>;
		ranges;
		reg = <0x0 0x1c20000 0x0 0x320 0x0 0x1f01400 0x0 0xb0 0x0 0x1f00060 0x0 0x4>;

		losc {
			#clock-cells = <0x0>;
			compatible = "allwinner,fixed-clock";
			clock-frequency = <0x8000>;
			clock-output-names = "losc";
			linux,phandle = <0xc>;
			phandle = <0xc>;
		};

		iosc {
			#clock-cells = <0x0>;
			compatible = "allwinner,fixed-clock";
			clock-frequency = <0xf42400>;
			clock-output-names = "iosc";
			linux,phandle = <0xd>;
			phandle = <0xd>;
		};

		hosc {
			#clock-cells = <0x0>;
			compatible = "allwinner,fixed-clock";
			clock-frequency = <0x16e3600>;
			clock-output-names = "hosc";
			linux,phandle = <0x6>;
			phandle = <0x6>;
		};

		pll_cpu {
			#clock-cells = <0x0>;
			compatible = "allwinner,sunxi-pll-clock";
			lock-mode = "new";
			clock-output-names = "pll_cpu";
		};
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

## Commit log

2012-03-09 initial schematic added and some PDFs
    [iMX233-OLinuXino_Rev_A.brd, iMX233-OLinuXino_Rev_A.sch]
2012-03-12 schematic update - DCDC power supply, SJTAG, GPIO
    [iMX233-OLinuXino_Rev_A.brd, iMX233-OLinuXino_Rev_A.sch]
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2012-03-13 schematic update, PCB layout started
    [iMX233-OLinuXino_Rev_A.brd, iMX233-OLinuXino_Rev_A.sch]
2012-03-15 schematic cleanup, component placed to fit inside Pactec JM-42
    [iMX233-OLinuXino_Rev_A.brd, iMX233-OLinuXino_Rev_A.sch]
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2012-03-22 PCB routing, DDR, USB, Ethernet complete
    [iMX233-OLinuXino_Rev_A.brd, iMX233-OLinuXino_Rev_A.sch]
2012-03-27 final touch to fit in the plastic box
    [iMX233-OLinuXino_Rev_A.brd, iMX233-OLinuXino_Rev_A.sch]
2012-04-27 new structure in HARDWARE folder, uploaded Mini, Micro CAD files
    [iMX233-OLinuXino-Maxi_Rev_A.brd, iMX233-OLinuXino-Maxi_Rev_A.sch, iMX233-OLinuXino-Micro_Rev_A.brd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]
2012-04-27 deleted old stuff from old folders
    [iMX233-OLinuXino_Rev_A.brd, iMX233-OLinuXino_Rev_A.sch]
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2012-05-28 updated working 2L iMX233-OLinuXino-Micro design files
    [iMX233-OLinuXino-Micro_Rev_A.brd, iMX233-OLinuXino-Micro_Rev_A.sch]
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2012-07-06 updated HARDWARE folder with latest schematics and boards
    [iMX233-OLINUXINO-MAXI_Rev_B1.brd, iMX233-OLINUXINO-MAXI_Rev_B1.sch, iMX233-OLINUXINO-MINI_Rev_C.brd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]
2012-07-11 A13-OLinuXino CAD files routed
    [A13-OLinuXino_Rev_A.brd, A13-OLinuXino_Rev_A.sch]
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2012-08-07 add kernel tv encoder default config
    [defconfig.txt]
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2012-08-21 A13-OLinuXino REV.B CAD files uploaded
    [A13-OLinuXino_Rev_A.brd, A13-OLinuXino_Rev_A.sch, A13-OLinuXino_Rev_B.brd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]
2012-09-04 A10-OLinuXino preliminary CAD files uploaded
    [A10-OLinuXino_Rev_A.brd, A10-OLinuXino_Rev_A.sch]
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2012-10-09 add A13-OLinuXino-MICRO REV.A CAD files
    [A13-OLinuXino-MICRO_Rev_A.brd, A13-OLinuXino-MICRO_Rev_A.sch]
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2012-11-13 A13-OLinuXino revision C (JTAG add to the board)
    [A13-OLinuXino_Rev_C.brd, A13-OLinuXino_Rev_C.sch]
2012-11-27 add A10S datasheet and A10S-OLinuXino-MICRO preliminary CAD files
    [A10S-OLinuXino-MICRO_Rev_A.brd, A10S-OLinuXino-MICRO_Rev_A.sch]
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2012-12-14 add LCDs and A10-OLinuXino prototype
    [A10-OLinuXino_Rev_A.brd, A10-OLinuXino_Rev_A.sch, A13-LCD4.3''_Rev_B.brd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]
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2013-01-21 add A10S-OLinuXino-MICRO REV.A and REV.B
    [A10S-OLinuXino-MICRO_Rev_A.brd, A10S-OLinuXino-MICRO_Rev_A.sch, A10S-OLinuXino-MICRO_Rev_B.brd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]
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2013-05-03 A10S-OLINUXINO developer edition CAD files update
    [A10S-OLinuXino-MICRO_Rev_C.brd, A10S-OLinuXino-MICRO_Rev_C.sch, A10S-OLinuXino-MICRO_Rev_D.brd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]
2013-05-24 A10/A20-OLinuXino-MICRO CAD files Rev.B
    [A10-OLINUXINO-MICRO_Rev_B.brd, A10-OLINUXINO-MICRO_Rev_B.sch]
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2013-08-23 A10-A20-OLinuXino-MICRO REV.C and D
    [A10-A20-OLINUXINO-MICRO-4GB_Rev_C.brd, A10-A20-OLINUXINO-MICRO-4GB_Rev_C.sch, A10-A20-OLINUXINO-MICRO-4GB_Rev_D.brd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]
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2013-11-23 updated iMX233-OLinuXino-MAXI CAD files to Rev.C2
    [iMX233-OLINUXINO-MAXI_Rev_C2.brd, iMX233-OLINUXINO-MAXI_Rev_C2.sch, iMX233-OLinuXino-Micro_Rev_C.brd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]
2013-11-25 Micro schematics in wrong folders.
    Micro revision C in Maxi folders. Needs to be deleted. Lub/OLIMEX
    [iMX233-OLinuXino-Micro_Rev_C.brd, iMX233-OLinuXino-Micro_Rev_C.sch]
2013-12-09 A10-OLinuXino-LIME revision A (developer edition)
    [A10-OLinuXino-Lime_Rev_A.brd, A10-OLinuXino-Lime_Rev_A.sch]
2014-01-21 A10-OLinuXino-LIME REV.B and GPIO description
    [A10-OLinuXino-Lime_Rev_B.brd, A10-OLinuXino-Lime_Rev_B.sch]
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2014-04-22 iMX233 MAXI source files update
    revision D schematic, board file and pdf updated to revision D
    [iMX233-OLINUXINO-MAXI_Rev_D.brd, iMX233-OLINUXINO-MAXI_Rev_D.sch]
2014-05-27 A20 OLINUXINO MICRO revision F files
    The major changes are:
    1. now USB1 is capable of providing 1A of current (up from 500mA); USB2
    is still capped at 500mA
    2. increased stability when powered from USB
    [A20-OLINUXINO-MICRO_4GB_Rev_F1.brd, A20-OLINUXINO-MICRO_4GB_Rev_F1.sch]
2014-06-18 A10-LIME board revision C files updated
    A10-LIME schematic, board layout and pdf added
    [A10-OLinuXino-Lime_Rev_C.brd, A10-OLinuXino-Lime_Rev_C.sch]
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2014-09-08 Python packages OLinuXino
    Added the missing project for A10 Lime
    [connector.c, gpio.c, gpio_lib.c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]
2014-09-17 iMX233-MICRO revision D files
    [iMX233-OLinuXino-Micro_Rev_D.brd, iMX233-OLinuXino-Micro_Rev_D.sch]
2014-10-02 A20-OLinuXino-LIME2 hardware sources added
    [A20-OLinuXino-Lime2_Rev_B.brd, A20-OLinuXino-Lime2_Rev_B.sch]
2014-10-23 Number of missing source files added
    [A13-LCD10TS_Rev_A.brd, A13-LCD10TS_Rev_A.sch, A13-LCD7''_Rev_C.brd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]
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2015-04-22 Fix tx DMAs address typo
    This typo cause to hang spidev2 on transfer data in DMA mode.
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2015-06-15 Fix pyA20 gpio1 connector constants
    In definition of gpio1 connector mapping constant there is a "cut&paste" error which prevent access to port pins.
2015-06-30 Fixed issue with SPI xfer
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2015-11-13 H3-OLinuXino prototype CAD files and H3 SoC datasheet
    [H3-OLinuXino_Rev_A.brd, H3-OLinuXino_Rev_A.sch]
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2016-01-29 Revision C
    Minor changes mainly on the I2C lines (set to hardware I2C).
    [iMX233-OLinuXino-NANO_Rev_C.brd, iMX233-OLinuXino-NANO_Rev_C.sch]
2016-04-11 Update
    Incorrect bit swap
    [main.c]
2016-04-20 Fixes raw downloads
    The script.bin and uEnv.txt files should be downloaded raw;
    the current wget command downloads the HTML page instead of the desired file.
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2016-09-02 Revert "Update"
    This reverts commit e85321694b9b064cff2fa52dd0ea86b82c493002.
    [main.cpp]
2016-09-02 Revert "Revert "Update""
    This reverts commit dbac98d0b39abfff813d94a6c430e85e8013d58c.
    [main.cpp]
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2016-10-28 Update
    New patch that applies workaround for GbE issues and ensures DDR clock
    is set to 384MHz for all A20 boards
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2017-04-18 update
    New hardware revisions and new board variants (industrial; EMMC;
    industrial + EMMC)
    [A20-OLINUXINO-MICRO-EMMC-IND_Rev_J.brd, A20-OLINUXINO-MICRO-EMMC-IND_Rev_J.sch, A20-OLINUXINO-MICRO-EMMC_Rev_J.brd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]
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2017-07-05 update
    fixes for port e powering
    [a64-olinuxino.dts]
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2019-04-09 Update
    Latest hardware revison I1 for A10/20 LIME
    [A20-OLinuXino-Lime_Rev_I1.brd, A20-OLinuXino-Lime_Rev_I1.sch]
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2020-01-09 Update: Fixed bug *9 to *0 years (Thanks to Adamo Reggiani for reporting this problem and suggesting solution for it!)
    Function InttoBCD changed to convert only 2 digits numbers to prevent wrong recalculation of the year from *9 to *0 transitions.
    Added 'century' variable to "remember" the "lost digit" of the year (when above 99).
    Changed output print format into easier to read:
    YYYY/MM/DD (DayOfWeek) HH:MM:SS
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2021-10-07 3d view components fixed
    [20PinMaleSmt.stp, 40PinMaleSMD.stp, BGA-624_21.0x21.0mm_Layout25x25_P0.8mm.step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]
2022-07-06 Update
    Added I2 and I3 revisions files and updated the revision changes text document
    [A20-OLinuXino-Lime_Rev_I1.brd, A20-OLinuXino-Lime_Rev_I1.sch, A20-OLinuXino-Lime_Rev_I1_bom.ods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]
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2024-09-16 Update revision
    New revision J for LIME boards (A10 and A20).
    [A10-OLinuXino-Lime_Rev_J_BOM.ods, A20-OLinuXino-Lime_Rev_I3.brd, A20-OLinuXino-Lime_Rev_I3.sch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]
2026-05-18 Update
    New hardware revision with different LCD panel
    [LCD-OLINUXINO-7TS_Rev_F.brd, LCD-OLINUXINO-7TS_Rev_F.sch]

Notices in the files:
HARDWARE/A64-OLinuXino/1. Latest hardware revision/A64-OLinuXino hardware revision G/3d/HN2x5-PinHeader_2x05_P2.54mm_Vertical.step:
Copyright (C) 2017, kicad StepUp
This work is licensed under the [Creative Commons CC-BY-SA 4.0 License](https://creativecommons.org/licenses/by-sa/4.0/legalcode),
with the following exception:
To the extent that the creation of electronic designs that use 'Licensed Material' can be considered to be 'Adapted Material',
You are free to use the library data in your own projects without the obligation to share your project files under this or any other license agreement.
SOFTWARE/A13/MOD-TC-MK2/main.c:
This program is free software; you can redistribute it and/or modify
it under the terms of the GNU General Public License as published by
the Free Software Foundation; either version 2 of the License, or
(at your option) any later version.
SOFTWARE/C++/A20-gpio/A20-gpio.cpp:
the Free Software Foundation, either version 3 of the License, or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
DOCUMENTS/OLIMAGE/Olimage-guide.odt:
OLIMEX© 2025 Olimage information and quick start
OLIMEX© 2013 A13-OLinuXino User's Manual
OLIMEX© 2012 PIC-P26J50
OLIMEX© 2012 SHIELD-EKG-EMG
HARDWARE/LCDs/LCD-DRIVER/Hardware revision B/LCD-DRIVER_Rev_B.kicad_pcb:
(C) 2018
